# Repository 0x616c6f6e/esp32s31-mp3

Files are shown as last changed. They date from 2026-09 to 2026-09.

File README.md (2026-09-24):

# ESP32-S31 MP3 / Q2 风格播放器

当前工程：

- **[V2 裸芯片主板 PCB](hardware-q2-v2/README.md)**：打开 `hardware-q2-v2/q2-v2.kicad_pro`。ESP32-S31NRV16、正面 AM213 BTB、46 × 76 mm 六层板，0201 阻容已改为 0402。当前仅保留电源布线与铺铜，信号待手动布线；几何 DRC、电源未连接及原理图一致性均为 0，174 项信号飞线为有意保留，不能直接投产。[双面预览](hardware-q2-v2/output/pcb-overview.png)。
- [V2 布局及管脚规划依据](hardware-q2-v2-plan/README.md)：保留方案来源；实际已布线管脚以 [V2 当前引脚表](hardware-q2-v2/pin-assignment.md) 为准。

**当前开发外壳为 L 版：适配新的 2.13 英寸 AM213 AMOLED。** 已修改屏幕总成、面壳开孔和固定台，整机仍为50×81.5×15.1 mm。新屏24针BTB不能直接连接已生产主板的21针FPC2，已完成独立双层FPC转接板的3.3 V参考电路和布线；ERC/DRC及原理图一致性检查通过。L版已有完整转接板装配检查副本，仍待FPC工艺审核、实物插合和点亮测试。

- **[最新外壳 L：2.13英寸屏幕适配](mechanical/enclosure-final-l/README.md)**：`Q2_L_AM213_Adapter_Study.FCStd`，直接使用新屏自带触摸盖板，预留17×22 mm转接板空间。[转接板接线规划](hardware-display-adapter/README.md)。

- **[历史外壳 K：旧2.09英寸屏幕](mechanical/enclosure-final-k/README.md)**：`Q2_K_Assembly_Access.FCStd`。已修复J版装入路径与薄壁，但不适用新AM213屏幕；保留作历史参考。

- **[历史外壳 J：后盖胶粘铜螺母版](mechanical/enclosure-final-j/README.md)**：打样复查暂缓，见 [J 版问题记录](mechanical/enclosure-final-j/PREFLIGHT-REVIEW.md)。已由 K 版取代。

- **[历史外壳 I：装配优化版](mechanical/enclosure-final-i/README.md)**：`Q2_I_Serviceable_Assembly.FCStd`。小板采用三颗带限长垫片的螺钉＋侧边限位台，避开 FFC；加厚按键止脱边、增加排线槽与绝缘护边。修正 G/H 版复合实体干涉漏报，使用 I 版完整四件打印包。

- **[历史外壳 H：小板固定加强版](mechanical/enclosure-final-h/README.md)**：`Q2_H_Reinforced_Assembly.FCStd`。加粗四个小板螺柱、加宽根部并增加侧壁加强筋，小板螺钉改为头下长 2 mm 的 M1.6；外形及两板位置沿用 G 版。使用 H 版打印包，G 版保留为历史。

- **[历史外壳 G：薄型树脂装机样件](mechanical/enclosure-final-g/README.md)**：`Q2_G_Thin_Assembly.FCStd`，适配最终主板与 CH32V006 小板，50 × 81.5 × 14.2 mm（含盖板）。CN2/CN3 改为直接焊线装配；修正支柱、马达托座、屏幕排线和按键避让。附四件打印文件。电池成品厚度仍待供方确认，装机约束见说明。

- [最终主板与按键板 FreeCAD 检查](mechanical/final-board-review/README.md)：采用 `hardware-q2/ProPrj_esp32s31-mp4_2026-09-22.kicad_pro` 为最终主板；两板已导入 `Q2_Final_Mainboard_Assembly.FCStd`。四个主板安装孔与原柱对齐，但发现马达/耳机座、C13/屏幕排线干涉，详见检查报告。

- [独立滑环与按键小板 C](hardware-controls/README.md)：打开 `hardware-controls/controls.kicad_pro`；44 × 34 × 0.8 mm，CH32V006F8U6 读取触摸环与四个机械键，通过 I²C 上报，POWER 独立上拉、按下为低；使用 12P / 0.5 mm / 40 mm 异面 FFC。当前整机机械装配见 K 版外壳，需另行完成小板固件及实物触摸标定。
- [已生产的模组版主板](hardware-q2/ProPrj_esp32s31-mp4_2026-09-22.kicad_pro)：当前保存工程为 `ProPrj_esp32s31-mp4_2026-09-22`；原始生产 Gerber 的审查记录见 [打板检查](hardware-q2/gerber-review-20260922/README.md)。
- [H1/H2 端子、马达和电池规划](mechanical/connector-layout/README.md)：当前摆放版使用 JST ACH 两芯/三芯端子，新增 FreeCAD 装配及线束通道检查。
- [历史外壳 F](mechanical/enclosure-q2-f/README.md)：保留早期外观方案；当前装配应参考 L 版。

旧 `hardware/`、`hardware-q2-placement/` 和旧主板导出文件已从当前目录移除，可从 Git 历史查找。根目录的 PDF、嘉立创 `.epro2` / `.epro` 及 Gerber 压缩包是原始资料。

历史摆放版已有主板与外壳适配；用户新布局 `hardware-q2-layout` 已用于最新小板/排线装配，其最终版本的四个主板安装孔已确认与原柱对齐；完整复查以最新报告为准。屏幕 FPC 插接细节、完整器件高度、具体电池型号仍需确认。独立滑环及五键小板见 `hardware-controls/`；两板接口针序已核对，排线插接、小板触摸与摇摆按键仍需实物验证。[排线采购与装配说明](hardware-controls/mechanical/FFC-INTERCONNECT.md)。详细尺寸、检查范围和后续事项见上述工程说明。

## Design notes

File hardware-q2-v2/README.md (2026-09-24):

# Q2 V2 裸芯片主板 · 2026-09-24

打开 **q2-v2.kicad_pro**。这是 ESP32-S31NRV16 裸芯片版的独立工程，当前按用户要求改为 **0402 阻容、电源分区铺铜并就近打过孔，信号待手动布线**。不是可打板文件。原生产主板 `hardware-q2` 的 PCB 保持原文件哈希。

此前将 21 个电容、10 个电阻及 L105（实际为 0Ω 电阻）从英制 0201 改为 0402（公制 1005）；L101–L104 的射频/滤波电感不在阻容替换范围内。随后检查发现原嘉立创导入的 0402 与 KiCad 标准焊盘混用，现已统一全部 62 个电阻类封装（含 L105）及 72 个电容封装，原理图、符号库、PCB 和 3D 模型同步使用下面两套项目内标准封装。密集区已调整间距，接口和安装孔位置保持不变。

| 类型 | 项目封装 | 焊盘尺寸 | 两焊盘中心距 |
|---|---|---|---|
| 0402 电阻 | `V2:R_0402_1005Metric` | 0.54 × 0.64 mm，圆角矩形 | 1.02 mm |
| 0402 电容 | `V2:C_0402_1005Metric` | 0.56 × 0.62 mm，圆角矩形 | 0.96 mm |

两者来自 KiCad 10 标准库，阻焊/锡膏使用标准继承设置。原有 0603/0805 电容和 1206 电流采样电阻保留原尺寸；过时的 134 个按位号命名的 0402 封装已移除，避免误用。`0402-standardization.json` 记录原始尺寸、统一后尺寸、位置及检查结果；运行 `scripts/audit_0402.py` 可核对所有实例的焊盘、阻焊/锡膏、模型及原理图关联。

删除了 2,090 段信号走线、155 个信号过孔；另重建主控局部电源引出。保留供电、GND/GBAT、稳压器开关/反馈/自举、电荷泵及马达负载回路。电源使能、温度采样、通信、时钟、射频、音频输出等信号均需后续手动布线。精确网络允许列表和改封装清单见 `power-only-0402.json`。

## 工程内容

- `q2-v2.kicad_pcb`：46 × 76 mm，6 层，名义板厚 1.6 mm；198 个器件，双面装配，普通通孔。
- `q2-v2.kicad_sch`：根页及 19 个功能子页，与 PCB 的器件实例和编号焊盘关联。
- `V2.kicad_sym`、`V2.pretty`、`models3d`：项目局部符号、封装和模型。常规 R/C/L 使用 KiCad 标准模型，需安装 KiCad 10 的 3D 模型库。
- `pin-assignment.md`、`q2_v2_pins.h`：从实际 PCB 生成的管脚表和 GPIO 宏；不是已验证的 BSP。
- `output/drc.json`、`erc.json`、`netlist-consistency.json`、`validation-summary.json`：最终检查记录。
- `output/q2-v2-assembly.step`、`case-fit.json`：主板装配模型及相对 L 版外壳的名义干涉检查。
- `output/front-review.svg/png`、`back-review.svg/png`：布局预览；`output/assembly-front.svg`、`assembly-back.svg` 为装配图。
- `output/power-map.svg/png`：In2/In3 实际填充后的电源铜区，按网络着色，均为顶视坐标；`power-pours.json` 记录铜区面积及电源连通性检查。
- 本地 `output/archive` 和路由会话为未提交的中间候选；Git 保留最终报告、模型与建板基线。`scripts` 中的建板及试布线脚本是过程记录，部分依赖本地路由运行时。**不要重新运行 build_v2、prepare_routing、route_usb_and_export 等初始化脚本覆盖当前成品布线。**

## 实现的电路与布局

主控改为 ESP32-S31NRV16，采用乐鑫官方 WROOM-3 V1.2 参考设计的裸芯片电源、40 MHz 晶振、PSRAM 供电和射频匹配起始网络，外接 W25Q128JVSIQ 16 MB 启动 Flash。天线暂定 U.FL/IPEX 外接柔性天线，尚未选定最终天线及安装位置。

屏幕采用正面 OK-23GF024-04，JDISP1 中心以板框左上原点计 `(30.0, 29.2) mm`，旋转 90°。板框原点对应 KiCad 坐标 `(128.868, 67.647) mm`。主控、存储和射频在上部，音频在左下，充电、USB 和电池接口在下部；新增低速电路主要放在背面。

为保持已完成 CH32 按键板的 POWER 上拉行为，新增常供电 3.3 V、跨断电电源域的信号隔离和关机脉冲电路。FPC1 的 2 脚改由常供电 3.3 V 供电；系统 I²C 使用 GPIO6/7 的 **LP I²C**，不能当成第三个普通 HP I²C 控制器初始化。UART 自动下载采用交叉晶体管电路；GPIO60/61 为启动配置，GPIO0 用于按键检测。

已修正 V1 中 CS43131 的 SCL/SDA 对应关系：物理 1 脚 SCL、39 脚 SDA。USB 屏蔽固定焊盘接地，USB 定位孔按厂家图改为 Ø0.55 mm NPTH。保留原外部接口和安装孔锚点。

| 焊线接口 | 焊盘 | 网络 | 用途 |
|---|---|---|---|
| CN2 | 1 | VBAT | 电池正极 |
| CN2 | 2 | BAT_TS | 电池温度检测，不可当作负极 |
| CN2 | 3 | GBAT | 电池负极，保留电量计采样回路，不要任意短接到其它 GND 点 |
| CN3 | 1 / 2 | MOTOR_OUT_P / MOTOR_OUT_N | 马达两端，均不是直接接地端 |

## 校验结果及边界

当前原生 KiCad 10 检查：**几何 DRC 违规 0 项、原理图一致性 0 项、电源未连接 0 项；信号未连接 174 项，符合本次保留飞线的要求**。原理图电路未改变，既有 ERC 为 0 项；另重新逐项比对 198 个器件、704 个编号焊盘的 XML 网表与 PCB，网络不一致为 0。所有阻容均已无 0201 封装，信号走线/过孔残留为 0。

DRC 使用工程内设置：最小线宽/间距 0.10/0.10 mm，保留少量 Ø0.35/0.15 mm 通孔，常规过孔 Ø0.45/0.20 mm；两层连续 GND 加外层铺地及就近地过孔。DRC 和铜区连通性检查不能替代电流/温升验证。

### 电源铺铜与过孔

本次不移动器件或更改原理图网络。In2.Cu（PWR）以 VCC_3V3 为主，In3.Cu（工程名称 SINGAL）放置其余局部电源铜区，必要的跨区连接借用少量 In2 区域。包括 GBAT 在内共 12 个供电/回流分区，彼此保持网络隔离；In1/In4 继续作为整面公共 GND。后续布信号需避开这些电源铜区，或重新填铜并复查电源连通性。

删除直流供电网络的内层分配走线，改为实际连通的铺铜；焊盘附近采用 Ø0.45/0.20 mm、双面盖油的过孔连接内层。普通电源孔避开 SMD 焊盘，保留必要的短表层引出，单段最长 2.0 mm；充电器和降压的大电流节点补充并联过孔。开关节点、反馈、自举、电荷泵以及马达负载回路仍保留必要短线，不能直接视为直流电源平面。主控原有 GND 散热焊盘通孔保留。

`scripts/audit_power_pours.py` 核对电源及地无未连接、直流内层分配线为零、信号铜残留为零，并输出实际填充铜区图。`build_power_pours.py` 和 `bridge_power_pours.py` 是生成过程脚本，依赖本地未提交的 `output/power-pour-spines.kicad_pcb`；不要作为日常更新命令重复执行。后续直接在 KiCad 编辑当前 PCB 并按 B 重新填铜。旧的 `output/power-width-*.json`、`retained-routing.json` 为改铺铜前的历史检查，本版以 `power-pours.json` 和 `validation-summary.json` 为准。

`drc.json` 明列 5 类未启用检查，包括缺少 courtyard、线端未居中过孔等，不能把 0 项理解为完整 DFM 认证。导入封装没有统一的装配 courtyard；已用名义 3D 模型补充器件碰撞检查，但没有验证供应商公差或装配工具空间。

FreeCAD 检查未发现器件模型之间的实体重叠，亦未发现主板组件与所选 L 版外壳、后盖、电池及马达占位的硬碰撞。仅 FPC1 与按键排线插入包络重叠约 1.071 mm³，属于预期插接区域。螺钉孔、测试点、CN2/CN3 焊线焊盘没有实体器件模型；新增晶振和主控模型为名义外形。该结果不等同于屏幕尾排线可插入、插拔路径和尺寸公差已验证。

## 打板前尚待完成的签核

1. **完成所有信号布线。** 包括电源使能、温度采样、USB、Flash、屏幕、音频、射频和晶振。USB 旧版线长结果已失效；`output/usb-routing.json` 是改版前的历史记录，不代表当前 PCB。下单前选定厂家叠层，计算线宽、间距、参考面并复核全链路差分耦合与偏斜；目前没有受控阻抗签核。
2. **射频与晶振。** 匹配值来自官方模块参考，但参考模块叠层不同，不能直接等同于本板的 50 Ω。本次匹配/负载电容及 0Ω 链路放大为 0402，寄生参数变化，原值仅保留为调试起点；需重布短线并实测匹配和晶振。40 MHz 晶振需匹配负载、精度及封装，不能只按频率采购。
3. **AM213 屏幕。** 按此前用户决定继续使用 3.3 V；项目内已保存的 [OSPTEK 官方参考原理图](../hardware-display-adapter/reference/osptek-official/PCB-2.13&1.96AMOLED-qspi转接板.pdf) 将 AM213 的 11/12/15/16 脚接到 VCC3V3，因此有原厂参考电路依据。该接法与早期规格书 PMIC 最低 3.4 V 的文字仍有差异，需实测启动、最大亮度、电源余量和温度边界，不能当作所有屏幕批次的保证。BTB 朝向、尾排线实际折弯与够长需用实物确认，不能仅靠 nominal STEP 认定可插接。
4. **供电和装配工艺。** 裸芯片 EP 内含 25 个散热通孔，需向板厂确认树脂填孔、电镀盖孔/平整焊盘工艺，避免焊料流失；0.15 mm 小孔、细线距及双面装配须与所选订单工艺一致。验证充电/峰值电流、主电源掉电、AON 反灌隔离及关机脉冲时序；尚未做上电、固件、信号完整性、热或 EMC 测试。

因此本目录交付的是**供手动完成信号布线的 PCB 工程**，没有导出标为可生产的 Gerber 包。

## 音频接地与后续布线

本板建议保留连续的公共 GND 平面，通过器件分区和回流路径隔离噪声，不另建孤立 AGND 铜岛或在 I²S 回流下开地缝。充电、降压与马达的大电流回路应局部闭合并远离 DAC/耳机回路；音频电源的滤波与去耦独立考虑。GBAT 是电量计采样回路，不是音频地，不可直接并到其它地焊盘。

**HPREFA/HPREFB 是例外的参考回路要求，不等于整块音频分地。** CS43131 手册第 8.3 节要求 U2 的 13、17 脚分别独立走线到耳机座参考地，再在耳机座地处通过过孔接系统地。目前这两脚仍归属公共 GND，现有铺铜会直接接入，尚未实现 Kelvin 回路。手动布线时应使用独立参考地网络与耳机座处的 net-tie（或局部禁布铜并严格控制公共网拓扑）实现，不能将当前公共地填充视为该要求已满足。GNDA/GNDD/GNDCP 和散热焊盘则继续采用低阻抗接地。依据：[CS43131 数据手册第 8.1–8.4 节](https://statics.cirrus.com/pubs/proDatasheet/CS43131_DS1155F2.pdf#page=140)。

## 参考依据

- [乐鑫 ESP32-S31 硬件设计指南](https://docs.espressif.com/projects/esp-hardware-design-guidelines/en/latest/esp32s31/schematic-checklist.html)，以及项目内 `esp32-s31_datasheet_en.pdf` v0.5；官方模块参考工程保存在 `reference/s31-module`。
- [CS43131 官方手册](https://statics.cirrus.com/pubs/proDatasheet/CS43131_DS1155F2.pdf)。
- [嘉立创 PCB 制程能力](https://jlcpcb.com/capabilities/pcb-capabilities)与[受控阻抗叠层](https://jlcpcb.com/impedance)。生产叠层和工艺应以实际订单确认为准。

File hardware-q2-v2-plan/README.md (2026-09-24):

# Q2 第二版布局规划 B · 2026-09-24

这是以方便布线为优先的 **PCB 布局规划工程**，不是完成电路设计的第二版主板。打开 `q2-v2-placement.kicad_pro` 后进入同名 PCB；本目录没有第二版原理图。不要用第一版原理图直接更新此板，否则会重新加入模组和旧屏幕接口。

源板为 `../hardware-q2/ProPrj_esp32s31-mp4_2026-09-22.kicad_pcb`。源板及生产用文件未改动。规划副本保留原器件的网络信息及 UUID，清除了走线、过孔和铺铜，以便后续手动布线。126 个现有/候选器件不包含尚未设计的裸芯片配套电路。

## 主要位置

统一按 KiCad 正面顶视图，板框中心线包围框左上角为原点，X 向右、Y 向下，单位 mm。绝对坐标原点为 `(128.868, 67.647)`。正面朝屏幕，背面朝后盖。

| 功能 | 层面 | 板框相对位置 | 摆放依据 |
|---|---|---|---|
| ESP32-S31 裸芯片及配套 | 正面 | 本体中心30.00,17.00；预留X21–38、Y8–25 | 手册确认本体8×8、0.35间距QFN80；候选−90°，仅文档层外形 |
| RF / 天线方案 | 两面 | X27–40、Y2–7 | 靠板上边；未确定天线形式，不是已验证的天线净空区 |
| JDISP1 屏幕 BTB | 正面 | **30.00, 29.20** | OK-23GF024-04；11×6 插接预留区；90°是候选方向 |
| U10 原外部数据 Flash | 正面 | 18.60, 28.20；270° | 靠旋转后的裸芯片左下Flash引脚组；容量和作为启动Flash的适用性尚待设计 |
| 40 MHz晶振及匹配 | 正面预留 | X35.5–42.5、Y10–15 | 靠芯片右上，实际器件和走线待设计 |
| U2 DAC | 正面 | 10.252, 48.441 | 保留晶振、充电泵、局部去耦相对关系；下移会碰马达支架 |
| U5 音频 1.8 V LDO | 正面 | 约20.50, 50.00 | 靠 DAC，远离右侧开关电源；输入/输出电容随电路调整 |
| U12 USB 转串口 | 正面 | 约25.40, 55.50 | 靠近 U17，避免原来的长差分支路 |
| D1 USB ESD | 背面 | 34.45, 66.00 | 位于 USB 信号焊盘背后；先保护再去 U17，预留成对过孔 |
| RTC、电量计、马达驱动 | 背面 | 见坐标表 | 围绕目的接口组织，保持按键 FFC 通道空闲 |

安装孔、USB、耳机座、TF 卡座、按键 FPC1 坐标和方向锁定。CN2/CN3 保留焊盘位置，按之前选定的低矮线束方案使用，移除了高插座的装配边界和模型，禁止再装原弯脚插座。

`placement-coordinates.csv` 提供全部器件的相对/绝对坐标及角度。`placement-overview.png` 中正反两图使用相同顶视坐标，右图不是从背面观看的镜像。

## 布线改善与顺序

同网络焊盘之间的最短直线距离，**不是已完成的走线长度**：

| 连接 | 原位置 | 规划位置 |
|---|---:|---:|
| USB → D1，D+ | 11.56 | 1.44 |
| USB → D1，D− | 9.16 | 1.44 |
| CH343P → USB 切换器，D+ | 18.75 | 4.19 |
| CH343P → USB 切换器，D− | 18.14 | 3.59 |
| 1.8 V LDO → DAC 供电脚 | 16.36 | 6.85 |

D1 移近入口后，它到 U17 的受保护支路变长，需要沿下方布线；这是优先缩短未保护段的取舍。不能用上表宣称全板总线长或过孔数量已经下降。

1. GPIO 候选分配已记录在 `pin-assignment.md`；完成裸芯片原理图、封装和实际布线评估后再确定核心朝向。Flash、SD、屏幕 QSPI 分组出线，避免互相穿越。旧模组的引脚号不能直接用于裸芯片。
2. 电源保持充电器/电感/电容及降压器各自局部回路；缩小 SW 铜面积，反馈线避开 SW 和电感。不要为缩短信号线拆散这些局部电路。
3. 优先布晶振、RF、启动 Flash、SD 和屏幕时钟，其次 USB 差分与 I²S；最后处理低速 I²C、控制信号。
4. 继续使用现有六层框架，内层保持连续参考地；具体层叠厚度、阻抗与制造商确认后再定线宽。数字总线从中间通道通过，避免穿过 DAC 晶振、充电泵和耳机模拟输出区域。
5. D1 在背面，USB 入口信号使用短的成对过孔，并提供邻近地回流；不要从未保护的支路绕到其他电路。

## 未完成的电路事项

2026-09-24：新增 `pin-assignment.md`、完整81脚表 `pin-assignment.csv` / `pin-assignment-all-pins.md`、方位图 `pin-assignment-overview.png` 和常量头文件 `q2_v2_pin_plan.h`。这些是原理图设计输入，未修改现有PCB网络。系统总线采用LP I²C，POWER检测须隔离GEK电源域；屏幕SPI2替代引脚组的SDK支持仍待实测。`scripts/plan_pins.py` 仅生成引脚表，不改PCB。

- CORE框内已按用户提供的芯片手册标注8×8本体和−90°候选朝向，仍无电气焊盘。须补裸芯片、40 MHz晶振及匹配、各电源域去耦、射频匹配、启动Flash和下载/复位电路。尺寸、物理引脚及型号核对见 `datasheet-check.md`。
- 原 U10 为 W25Q16JVSSIQ，**16 Mbit = 2 MB**，不能直接等同原 ESP32-S31-WROOM-3-N16R16V 内的 16 MB Flash。其现有位置是外部数据 Flash 候选位置；下一版可结合实际程序容量决定是否替换/合并。原有 C13 的 3.3 V 网络也不能代替尚未设计的 VDD_SPI 供电方案。
- 移除了 U9、FPC2，以及旧 TFT 背光升压的 U16/L4/C42/C55/C56/C57/R40/R41。马达仍使用的 VCC_LCD_BG 相关充电器网络没有删除。第二版原理图要同步这些变化。
- BTB 沿用已讨论的 3.3 V AMOLED 方案和转接板信号映射；TE 作为未接 MCU 的独立预留网络。新接口需增加/核对本地去耦、电源顺序、ESD；这是预接网络，不是电气审核结论。
- BTB 绝对坐标为 `(158.868, 96.847)`。当前 90°对应1脚在顶视图左下，约 `(27.8,30.4)`；90°/270°须通过实物屏幕原生排线折叠确认。原转接板焊接面比主板正面高4.3 mm，XY 对齐不能证明排线可直连。
- RF 预留区尚未检查屏幕金属层的射频影响，不能直接作为 PCB 天线设计或全层禁铜范围。正式核心电路还可能要求调整 CORE 和 Flash 范围。

依据乐鑫官方 [ESP32-S31 原理图检查表](https://docs.espressif.com/projects/esp-hardware-design-guidelines/en/latest/esp32s31/schematic-checklist.html) 和 [PCB 布局指南](https://docs.espressif.com/projects/esp-hardware-design-guidelines/en/latest/esp32s31/pcb-layout-design.html) 组织核心预留和布线顺序。RF/时钟及分域供电应以完整参考设计为准。

## 检查范围与交付文件

本次调整55个现有器件，并新增1个BTB候选封装。原生DRC确认焊盘短接0项、封装装配边界重叠0项、跨网络阻焊桥0项；仍有66项其他违规和324项未连接，详见原始报告。保留器件的焊盘网络与源板逐项比较一致。已有模型中，55个移动器件及新增BTB未发现实体碰撞；原FPC1与排线插接处约0.00195 mm³的微小重叠未变化，记录在装配报告中。

- `placement.json`：完整器件记录、源文件校验和、移除项和预留区。
- `connection-distance-check.json`：上述连接距离的计算证据。
- `drc-planning.json`：原生 KiCad DRC，不能作为生产放行报告。规划板无走线，存在未连接项；原导入封装还存在孔类型、丝印、USB 开槽边缘间距和细间距封装与默认0.2 mm规则不相容的问题。没有通过忽略规则来隐藏它们。
- `mechanical-check.json`：将现有STEP模型及8×8×0.9 mm芯片本体占位移入L版装配的碰撞检查。对新增配套电路、屏幕原生排线、公差及整机RF不作验证结论。
- `Q2_V2_Placement_Study.FCStd`：**布局规划装配副本**，不是新的可加工外壳版本。CN2/CN3 高插座及旧屏幕转接板占位已移除；外壳本体没改。
- `V2_Plan.pretty`：当前规划板的本地封装库。3D 模型引用同仓库已有文件，需保留本目录与上级工程的相对路径。参考位号放在 Fab 层用于布局阅读，生产丝印尚未整理。

重建脚本位于 `scripts`，会覆盖本目录生成的规划板及报告；**开始手动布局后不要运行重建脚本，以免覆盖你的修改**。`build_plan.py` 使用 KiCad Python，`check_mechanical.py` 使用 FreeCAD Python，`make_preview.py` 使用带 Pillow 的 Python。

下一阶段是补齐裸芯片原理图、将该规划变为网络一致的正式 PCB，再布线和进行生产 DRC。本版不能导出用于生产的 Gerber。

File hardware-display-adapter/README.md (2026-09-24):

# AM213 屏幕转接板 A — 电气样板

2026-09-23：已完成原理图、双层 FPC PCB、布线、3D 模型及 L 版装配检查副本。按用户选择采用 **3.3 V 供电和直接连接逻辑**，没有修改已生产主板和按键板。

## 当前文件

- 打开工程：[am213-fpc-adapter.kicad_pro](am213-fpc-adapter/am213-fpc-adapter.kicad_pro)。同目录有原理图、PCB 和自带符号、封装、STEP 库。
- 最新装配副本：[Q2_L_AM213_Completed_Adapter.FCStd](am213-fpc-adapter/models3d/Q2_L_AM213_Completed_Adapter.FCStd)。原始 L 外壳没有覆盖。
- [元件面预览](am213-fpc-adapter/output/pcb-top.png)、[折弯预览](am213-fpc-adapter/output/adapter-folded.png)、[装配预览](am213-fpc-adapter/output/adapter-in-enclosure.png)。
- [BOM](am213-fpc-adapter/output/bom.csv)、[接线及坐标](fpc-layout-guide.md)、[制造说明](am213-fpc-adapter/FABRICATION.md)。
- `am213-fpc-adapter/output/AM213-adapter-A-fabricator-review.zip`：Gerber、钻孔与工艺说明，供 **FPC 工厂审核及小批样板**；不是普通刚性 PCB 下单包。

旧 `adapter-outline.kicad_pcb`、`fpc-layout-concept.png`、`Adapter_Placement.pretty` 和机械占位预览仅作历史参考。旧 1.8 V 电平转换方案已被本版取代。

## 电气依据

屏厂 OSPTEK 官方 AM213 参考原理图明确把 11/12 脚 VBAT、15 脚 VDD、16 脚 TP_VDD 接到 3.3 V，QSPI/I²C 直接连接 ESP32。采用该参考，取消早期预留的电平转换电路。

- 官方仓库：https://github.com/osptek/amoled-2.13-410x502-qspi-co5300
- 原理图与实板照片：[PCB-2.13&1.96AMOLED-qspi转接板.pdf](reference/osptek-official/PCB-2.13&1.96AMOLED-qspi转接板.pdf)。第 1 页左侧为 AM213，第 2 页实板照片用于母座针号核对。
- 原厂连接器图：[OK-23GF024-04.pdf](reference/osptek-official/OK-23GF024-04.pdf)，母座第 3 页。
- 下载来源和 blob 标识：`reference/osptek-official/sources.json`。

旧屏幕规格书第 6 页仍有 VBAT 下限 3.4 V、VDDIO 1.8 V 等与参考板不一致的文字。本版选择有屏厂参考电路支持，但没有实屏点亮、最大负载及主板电源余量测试，不等于供应商对所有批次的保证。

## 检查与限制

KiCad 10 原生 ERC **0**、DRC 违规 **0**、未连接 **0**、原理图/PCB 一致性问题 **0**。报告在 `output/erc.json`、`output/drc.json`。工艺下限见制造说明，不能代替板厂 DFM。

FreeCAD 按 R0.8 mm 折弯 70 mm 排线，检查元件岛、补强、元件和母座最大包络。排线及插头补强进入简化实体 `PCB_FPC2` 是预期配合重叠；除此之外未发现体积干涉。屏幕原生尾巴、公母插合公差、锁扣和触点仍需实物试装。

`build_complete_adapter.py` 会覆盖 PCB 布线，不要对手改后的工程直接运行。其余脚本是本次构建和修复记录；当前交付以已保存 KiCad 文件为准。旧机械占位生成器已加覆盖保护。

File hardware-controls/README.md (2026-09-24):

# 滑环与按键小板 C：CH32V006

采用 **CH32V006F8U6** 替换 AT42QT2120-MMHR 和 TCA6408A，由一颗 MCU 处理三电极滑环、四个机械按键，并作为 I²C 从机向主板报告。POWER 保持独立、10 kΩ 上拉、按下接地。

这是需要配套固件和实物调参的新硬件版本，不能直接沿用旧 AT42 的驱动或生产文件。

KiCad 10.0.4 检查结果：ERC 0、DRC 0、未连接项 0、原理图一致性问题 0。板上共有 439 段走线和 62 个过孔。双面 GND 铺铜避开触摸电极及其背面（外扩约 0.8 mm），并避开三路采样走线（铜边外扩约 0.5 mm）；这些余量仍需实物验证。

新版文件：[Gerber 生产包](output/controls-ch32v006-jlcpcb-20260922-101316-gerbers.zip)、[BOM](output/controls-ch32v006-bom.csv)、[装配 STEP](output/controls-ch32v006.step)、[背面预览](output/ch32v006-review/back.png)。BOM 由当前原理图导出，共 10 类、23 个装配元件，尚未匹配嘉立创 SMT 料号。

## 工程与机械接口

- KiCad 工程：`controls.kicad_pro`，原理图、PCB、本地符号库、封装库与模型一起使用。
- 双层 FR-4，板厚 0.8 mm，44 × 34 mm，原 R10 板框。
- 五个按键、四个安装孔、三电极滑环 E1、FPC J1 的位置与方向保持原样。
- 电极仍为三组插值电极，外径 31 mm、内径 15 mm；不改变前面板外观。
- 新 MCU 及阻容位于背面。J2 为四个裸焊盘，不安装插针，不增加连接器高度。
- 已添加名义尺寸的 CH32V006 QFN20 STEP 模型。本版 23 个元件已导入 [I 版装配优化工程](../mechanical/enclosure-final-i/README.md)，最新工程为 `mechanical/enclosure-final-i/Q2_I_Serviceable_Assembly.FCStd`。小板采用三颗 M1.6 × 2 mm（头下长度）薄头螺钉、三片 0.3 mm 平垫及右侧限位台；右上原固定柱封闭不装螺钉，避开 FFC。G/H 复合实体检查曾漏报该处干涉，使用 I 版检查和打印文件。

J1：1 GND、2 +3V3、3 SDA、4 SCL、5 INT_N、6 RESET_N、7～10 NC、11 KEY_POWER、12 GND；固定焊盘 13、14 接地。供电与信号电平为 3.3 V。

## 采购与装配变化

| 位号 | C 版器件/数值 | 数量 | 说明 |
|---|---|---:|---|
| U1 | CH32V006F8U6 | 1 | QFN20，3×3 mm，0.4 mm 脚距，EP 1.9×1.9 mm |
| J1 | HC-FPC-05-10-12RLTAG | 1 | 原 12 pin、0.5 mm FPC 连接器 |
| SW1～SW5 | SKSWCEE010 | 5 | 原机械开关 |
| R1～R3 | 1 kΩ，0402 | 3 | 触摸采样串阻，需实物调参 |
| R4、R5 | 4.7 kΩ，0402 | 2 | I²C 上拉 |
| R6、R7、R14 | 10 kΩ，0402 | 3 | INT、RESET、POWER 上拉 |
| R8 | 0 Ω，0402 | 1 | MCU 电源连接，不能装旧 22 Ω |
| R9～R12 | 47 kΩ，0402 | 4 | 四个普通键的 GPIO 上拉 |
| C1、C3 | 100 nF，0402，X7R，≥10 V | 2 | MCU 去耦、复位 RC |
| C2 | 1 µF，0402，X5R/X7R，≥10 V | 1 | MCU 电源去耦 |

单板 23 个采购/装配元件。J2、E1、H1～H4 为 PCB 自带焊盘、电极及安装孔，不采购。U2、R13、C4 已移除；C3 现在用于复位，不能按旧版位置和功能装配。型号后缀及封装必须核对，TSSOP20 的 CH32V006F8P6 不能替代此 QFN20 焊盘。

## 固件

见 [CH32V006-interface.md](CH32V006-interface.md)：完整引脚分配、SDI 下载、PD7 硬件复位配置，以及拟定的 I²C 寄存器协议。地址暂定 0x1C，寄存器与 AT42QT2120 不兼容。本次没有交付可烧录固件；官方 TouchKey 示例也不能原样烧录到此板。

打样后要在最终盖板下标定三路触摸基线、阈值、零位、转动方向与跨零连续性，并验证充电/音频干扰、按键消抖、待机电流、复位和再次下载能力。

## 检查与历史文件

本次备份、原生 ERC/DRC 报告、机械接口比较和预览位于 `output/ch32v006-review/`，以其中的 final 报告和 `validation.json` 为准。历史生成脚本可能仍包含 B 版芯片和旧镜像坐标，不要直接运行旧 `build_design.py` 或 `build_fit.py` 覆盖当前工程。

2026-09-22 10:13:16 批次已从用户调整走线后的 C 版导出 Gerber 生产包（源 PCB 保存时间为 10:13:08），包含九个图层、独立 PTH/NPTH 钻孔、Gerber Job 和加工说明。下单参数：双层 FR-4、44 × 34 mm、板厚 0.8 mm、外层铜厚 1 oz。62 个 Ø0.30 mm 镀铜过孔及四个 Ø1.80 mm 非金属化安装孔已与 PCB 核对；顶面触摸电极保留阻焊覆盖。导出前原生 DRC、未连接项和原理图一致性问题均为 0；文件校验和及检查记录见 `output/ch32v006-gerber-review-20260922-101316/manifest.json`。

**旧 `controls-jlcpcb-20260922-no-tp-gerbers.zip`、旧 BOM、`fabrication/` 和历史 STEP 是 AT42/TCA 版本，全部不适用于 C 版。** 旧 README 与原始工程在 `output/ch32v006-review/before/` 保留。

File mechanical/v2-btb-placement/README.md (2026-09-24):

# 第二版主板正面 BTB 位置评审

当前结论：可以在取消 U9 模组后预留一个正面 BTB 候选位置，但**尚不能冻结生产坐标**。现有屏幕 CAD 没有原生排线的精确实体，需在主板正面高度试折实物后确认落点和 1 脚。

## 建议预留位置

以现有主板 Edge.Cuts 中心线外包左上角为基准：KiCad **(128.868,67.647)**，名义板框 **46×76 mm**，X 向右、Y 向下。

| 项目 | 候选值 |
|---|---|
| 连接器 | OK-23GF024-04，24P 母座，与屏幕公座配对 |
| 放置面 | F.Cu，朝屏幕一面 |
| 基于主板板框的中心 | **X=30.00，Y=29.20 mm** |
| 当前 KiCad 绝对中心 | **X=158.868，Y=96.847 mm** |
| 外壳装配底面中心 | **(18.00,31.20,5.80) mm** |
| 长轴 | 沿主板 X，横向 |
| 预留区域 | 中心周围 **11×6 mm**，先不放裸芯片、晶振或其他元件 |

坐标转换为 `X_case=176.868-X_KiCad`、`Y_case=Y_KiCad-65.647`。所以 KiCad 顶视图的左/右与当前外壳平面坐标相反；不能把外壳 X18 当作主板局部 X18。

当前适配器封装旋转 **90°** 时，1 脚位于 KiCad 图中左下，局部 (27.8,30.4)；旋转 **270°** 时会变成右上。两种角度外形占位相同，但针序相反。此处只推荐长轴方向，**90°/270° 的最终选择须按屏幕原生排线的实际折回姿态核对**，不能沿用旧转接板的“1 脚左上”。

## 选择理由及实测边界

1. 将旧转接板的外壳 XY=(32,20) 投影到主板正面后，母座最大包络与现有 CARD2/TF 卡座相交约 1.146 mm³，不能直接照搬。
2. 新位置在 U9 模组原占位的下半部。保留模组时与其干涉；从评审中排除将被替换的 U9 后，母座最大包络以及 11×6×1.7 mm 操作预留区与其余现有模型没有体积干涉。没有模拟插合手指/工具的完整扫掠。
3. 方案假定屏幕横放后，原生自由尾巴朝机身左侧、靠屏幕下沿。按规格书第 5 页折弯示意图中的边距 5.15±0.5 mm、尾端宽 4 mm，尾巴轴线估算为外壳 Y≈`0.85+37.5-(5.15+4/2)=31.2 mm`。**这是示意图推算，不是厂家给定的主板连接器坐标**。X18 是在腾出空间内选的工程候选值，需实物调整。
4. 原转接板焊接基面 Z10.1；主板正面 Z5.8，低了 **4.3 mm**。低矮母座本身不能补这个高度，屏幕原生 FPC 必须形成新的三维弯曲路线。型号所称 0.8H 是公母插合高度，不是 4.3 mm 高度转接件。
5. 第二版裸芯片、射频匹配/天线、晶振、电源与去耦布局尚未设计；这份结果只确认候选母座区域相对于当前外壳和其余器件的空间关系。

## 文件

- `Q2_V2_BTB_Position_Study.FCStd`：独立 FreeCAD 评审副本。
- `placement-top.png/svg`：以 KiCad 顶视图表达的候选位置，包含板框基准及 TF/旧模组占位。
- `position-check.json`：坐标、碰撞结果和全部假设。
- `check_position.py`：可重建检查副本；现有主板和 L 版外壳文件保持原样。

在绘制第二版走线前，用实际 AM213 屏幕在 Z5.8 mm 的主板平面试折：避开原生元件区与钢片补强，不强拉、不折死；确认插合面、尾巴自然落点和 pin 1，再冻结 XY 与 90°/270°。若实屏实际朝另一侧出线，需要调整屏幕朝向或重选位置，不能只把本坐标镜像后直接投板。

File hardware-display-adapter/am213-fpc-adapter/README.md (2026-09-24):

# AM213 转接板 A

打开 `am213-fpc-adapter.kicad_pro`。现为已完成原理图和布线的电气工程，取代旧机械占位版本。

- 原理图、PCB：同名 `.kicad_sch`、`.kicad_pcb`
- 自带库：`Adapter.kicad_sym`、`Adapter.pretty`、`models3d`
- 最新装配副本：`models3d/Q2_L_AM213_Completed_Adapter.FCStd`
- 检查、BOM、预览及制造审核包：`output/`

采用屏厂 3.3 V 直接接线参考；17×22 mm 元件岛、70 mm 左出尾巴；J2 局部 **(3,12)**、1 脚左上。R10/R11 不装。ERC/DRC、未连接和原理图一致性问题均为 0。

详见[接线与坐标](../fpc-layout-guide.md)、[电气依据](../README.md)、[制造说明](FABRICATION.md)。先审核柔性叠层、补强、0.15 mm 小孔及金手指工艺，再做样板；尚未实物插合和点亮。

`Adapter_Placement.pretty`、旧 `placement-preview.*` 及 `models3d/Q2_L_BTB_Fit_Review.FCStd` 为历史阶段文件。

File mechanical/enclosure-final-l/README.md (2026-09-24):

# Q2 L：2.13 英寸 AM213 屏幕适配

已按项目中的 `AM_213_Q410502_LK_b82450b641.pdf` 更新屏幕总成、面壳开孔及固定方式，保留已生产主板与按键板。**当前是机械适配版，含转接板空间预留；不是可直接装机生产的完整定版。** 新屏24针BTB不能插入原21针FPC2，有源转接板及两端排线仍需完成。

当前工程：**`Q2_L_AM213_Adapter_Study.FCStd`**。K版保留为旧2.09英寸屏历史工程，不适用于本次新屏。

## 屏幕与机身

| 项目 | L版 |
|---|---|
| 型号 | AM213Q410502LK，2.13英寸LTPS AMOLED，带触摸及一体盖板 |
| 分辨率 | 410×502；本机横向布局为502×410 |
| 控制器 | CO5300AF-51显示、CST820触摸、BV6802电源 |
| 完整光学总成 | 竖向37.50×46.30×2.28 mm；模型横放46.30×37.50×2.28 mm |
| 盖板 | 屏幕自带1.30 mm盖板，**取消旧版另购46×40×0.6玻璃** |
| 裸屏轮廓 | 横放43.14×34.79 mm；规格书标厚0.800 mm |
| 显示区 / 可视区 | 横放40.51×33.09 / 40.71×33.29 mm |
| 整机外包 | **50×81.5×15.1 mm**，保留K版尺寸 |
| 左、右直边距 | **1.85 mm** |
| 顶部直边距 | **2.35 mm**；屏幕盖板XY原点(1.85,0.85)，机身顶端Y=-1.5 |
| 盖板装入间隙 | 名义单边0.25 mm；裸屏通孔单边0.30 mm |
| 固定 | 一体盖板背面黑边粘0.20 mm胶，落在新面壳台阶上；名义接触面积约121.6 mm² |

屏幕正面最高Z=15.1、盖板背面Z=13.8、壳内胶台Z=13.6、光学总成背面Z=12.82 mm。模型按0.805 mm屏体＋0.175 mm OCA＋1.30 mm盖板分层，使总厚与规格书四舍五入后的2.28 mm一致；这0.005 mm并非额外零件。

屏幕在L版首次适配基础上**下移0.50 mm**，同步移动开孔、胶台、光学总成及背面FPC包络。此次按圆角处的视觉留白调整：原直边距虽相等，但上方圆角与机身曲率不同，留白偏窄。下移后盖板上圆角至面壳外缘的平面最短距离约1.27 mm，左右直边约1.30 mm（按Z=14.4前表面轮廓测量）；扣除0.25 mm装入缝后，可见实体边框约1.02/1.05 mm。这里的视觉均衡不等于三个方向的外包直边尺寸都相等。

尺寸取自规格书第3页及第5页完整总成图。盖板和裸屏圆角未标注半径，按第5页矢量轮廓近似为相切圆弧；盖板R约9.95 mm，裸屏左右角约R9.0/R8.42。盖板矢量采样点落在解析模型外的最大距离约0.052 mm。**这是图形近似，不是厂家尺寸公差保证**，取得厂家DXF/实物后仍需复核圆角。

## 屏幕背面与转接板

规格书显示该屏出厂把带元件FPC折到屏幕后方，不能使用旧屏的单条平整46.14 mm排线路径。本版删除旧路径，在屏幕后设置保守元件/FPC包络，向后预留1.52 mm（含图示1.42 mm局部高度与0.10 mm余量）。其形状是占位，不是FPC精确实形。

转接板预留位于装配坐标 **X29～46、Y8～30、Z9.5～10.1 mm**，尺寸17×22×0.6 mm。板下元件允许包络0.9 mm，板上连接器暂留0.8 mm。模型蓝色是板框、橙色是元件空间，均不是已经布线的PCB。当前检查中板上连接器包络至屏幕后包络名义间距0.4 mm；屏体向后增加0.2 mm后仍无实体交叠，但这不是完整制造公差堆栈。

**尚未建成**：新屏伸出的自由尾线到转接板的实际折弯、21针输入线到主板背面FPC2的路线、转接板固定座及准确母座模型。保留这些待定项，避免用一条虚构排线宣称两端已连接。电路及接线方案见 [转接板规划](../../hardware-display-adapter/README.md)。

## 装配变化

后盖、滑环、中央键、马达托座与K版几何完全一致；只有上壳/屏幕结构变化。五金仍为：主板4颗M2×4、小板3颗M1.6×2.5＋3片0.3 mm平垫、后盖2颗M1.6×6＋2颗OD2.5/L3的M1.6胶粘铜螺母。孔、头部尺寸及胶粘要求沿用 [K版说明](../enclosure-final-k/README.md)。

- 滑环先向屏幕偏3.5 mm，从后侧进入至低于终位5 mm，再移回中心并向前就位；中央键随后装入。
- **L版小板进入偏移改为 X=-1.3、Y=-3.0 mm**，不能沿用K版Y=-5路线。推至比终位低0.5 mm，再沿Y回到0、沿Z抬0.5 mm，最后向右滑1.3 mm进限位台，装三颗带平垫螺钉。
- 马达托座仍在小板之后安装。屏幕一体总成从前侧放入，胶贴只作用于盖板黑边台阶，不能在触摸盖板外再叠一块旧透明板。
- 转接板实际固定及排线接好后，主板/后盖才合装；该步骤仍等待实际转接设计。

## 已验证的范围

- `fit-check.json`：原装配＋新屏及转接占位共190个对象，非预期静态干涉0；按键下压与四向摇摆检查通过。
- `assembly-path-check.json`：73个分阶段离散姿态通过，含新屏一体总成、转接占位、小板新路线与主板/后盖。没有模拟自由排线弯曲、工具或粘接操作。
- `screen-check.json`：总成外包46.3×37.5×2.28、胶台接触、屏后增厚0.2 mm情形通过；主板、小板及四个沿用打印件相对K版几何差为0。
- `export-readback-check.json`：六个STEP/STL回读有效、单实体、单连通闭合，无网格自交/非流形/法向错误；STEP与保存的FCStd打印件一致。
- `source.json`：最终两板的源文件与哈希；`screen-contours.json`：屏幕规格书SHA256及轮廓提取记录。

## 文件用途

- `Q2_L_AM213_Adapter_Study.FCStd`：带参数与占位的FreeCAD源工程。
- `Q2_L_AM213_Adapter_Study.step`：整机参考，不可整体打印。
- `AM213Q410502LK-screen-stack.step`：新屏光学总成独立模型，**不包含未定自由排线**。
- `prototype-parts-not-released/`：更新后的外壳单件STEP/STL，仅作机械评审，不作为已经完成装机验证的下单包。
- `front-assembled.png`、`back-internals.png`：外观与空间预留视图。

正式定版仍需确认屏幕15脚VDD/16脚TP_VDD供电、电流、配套BTB母座图及出货FPC实形，完成转接电路和实际布线后再复查。现有电池采购尺寸、充电配置及树脂/胶接实物验证要求继续适用。**现在不要把L版直接按完整可装机样件下单。**

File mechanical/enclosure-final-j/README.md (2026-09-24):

# Q2 J 后盖胶粘铜螺母版 — 2026-09-23

> **打样前复查：暂缓按可装机样件加工。** 新增装入路径检查发现滑环和小板会碰上壳内部结构；薄壁/工艺框及 LCD 本体固定仍待处理。此前静态“零干涉”不能代表可装配。详见 [完整复查报告](PREFLIGHT-REVIEW.md) 和 [暂缓加工说明](PRINT-HOLD.md)。下文装配顺序属于原设计意图，尚未通过完整装入路径验证。

当前外壳工程为 **Q2_J_Glue_Insert_Assembly.FCStd**，适配最终 `hardware-q2/ProPrj_esp32s31-mp4_2026-09-22.kicad_pcb` 和 CH32V006 C 版 `hardware-controls/controls.kicad_pcb`。本次不修改电路板。面宽 50 mm、高 81.5 mm，壳体厚 13.5 mm，含前盖板最大厚度 14.2 mm。保留屏幕上、左、右 2 mm 边距及当前操作区中心。

这是树脂打印的装机验证版本，不是量产定版。**保持薄壳的前提是 CN2/CN3 不装原高插座，改为焊接柔性线束。电池成品尺寸尚未获得供方确认。**

## 文件

- `Q2_J_Glue_Insert_Assembly.FCStd`：完整装配，分为打印件、电子件、装配参考和隐藏诊断包络；尺寸记录在 DesignParameters 表中。几何构建脚本位于 `scripts/`，不是完整草图约束建模树。
- `Q2_J_Glue_Insert_Assembly.step`：整机交换模型，仅供装配检查，不可整体送印。
- `Q2-J-glue-insert-sample.zip`：四个装机打印件、一个可选螺母试配小样的 STEP/STL、加工说明和验证记录。
- `print-package/`：实际送印文件，毫米单位，每个文件独立局部原点。
- `clean-parts/`：去工艺框后的滑环和中央键 STEP，保持装配坐标，供机械修改。
- `source.json`、`fit-check.json`、`export-check.json`：PCB 版本、名义干涉检查及网格尺寸/闭合性记录。
- `front-assembled.png`、`back-internals.png`、`shell-parts.png`：装配和内部结构预览。
- `optimized-upper-shell.png`：金色为两颗胶粘铜螺母的位置；`insert-section.png`：螺母座剖面，金色为铜螺母、深灰为螺钉、浅灰为上壳，底部灰色横板为后盖。牙纹和滚花仅以包络表示。

## J 版：后盖两个固定点改为胶粘铜螺母

**只改后盖到上壳的两个固定点。** 主板四颗 M2、小板三颗 M1.6＋垫片及侧边限位台沿用 I 版。机身外形和两板位置不变。新版上壳 `01-housing` 必须使用 J 版；后盖、滑环和中央键与 I 版几何一致。

| 项目 | 数量 / 尺寸 |
|---|---|
| 铜螺母 | **2 颗 M1.6 × 0.35，无头滚花，最大外径 2.5 mm、总长 3.0 mm** |
| 厂商尺寸参考 | In-saiL **MT-M1.6x3.0-OD2.5**；不可换成带法兰 MTH、六角螺母或外径 3 mm 款 |
| 螺母座位置 | 上壳内，装配坐标 X=25，Y=3 / 77 mm；从后盖方向装入 |
| 胶粘孔 | Ø2.70 × 深 3.20 mm；入口 0.15 × 45° 导角 |
| 胶缝 | 对 Ø2.50 最大外径，径向名义 0.10 mm；滚花谷底实际胶层更厚 |
| 安装深度 | 插到底部台阶，螺母外端低于柱端面约 0.20 mm；螺母 Z=1.4～4.4 mm |
| 柱壁 | 圆柱外径 Ø4.8，直孔段名义径向壁厚 1.05 mm；入口处 0.90 mm |
| 螺钉避让 | 螺母后方 Ø1.8 通道至 Z=7.20；M1.6×6 螺钉尖端 Z=6.65，名义余量 0.55 mm |
| 后盖螺钉 | 沿用 **2 × M1.6 × 6，头径 ≤3.2、头高 ≤0.5 mm** |

总计 **9 颗螺钉＋3 片平垫＋2 颗铜螺母**。铜螺母是金属采购件，模型中以光滑最大包络表达，未画牙纹、滚花和导入倒角；3 mm 为轴向覆盖长度，不代表 3 mm 全部都是有效完整牙。

选型依据：[In-saiL 厂商规格](https://www.ppmcn.com/mini-tech-inserts/)。该厂商给出的 Ø2.15～2.25 安装孔属于热嵌工艺，**本版 SLA 树脂采用自行设计的 Ø2.70 胶粘孔，不能按厂商热嵌孔缩小或加热压入**。树脂胶粘安装参考 [Formlabs](https://formlabs.com/blog/adding-screw-threads-3d-printed-parts/)。尺寸规格已查证，但未确认淘宝某一商家的库存、尺寸公差或胶接强度；购买时明确要求最大滚花外径和总长。

### 试配与粘接

1. 先测量铜螺母实际最大外径及长度。外径不是 2.5 mm 或长度不是 3 mm 时，不得硬压入本孔；按实物另改模型。
2. 建议同材料、同批次打印 `05-insert-fit-coupon-optional`（24×8×5 mm）。带缺角一端的孔为 Ø2.65，中间 Ø2.70，另一端 Ø2.75；三个孔均深 3.2 mm，并带小直径余孔。小样验证插入和胶接，不是主机零件，也不是打印公差保证。正式上壳孔固定为 Ø2.70，不能因小样另一孔合适就直接假定上壳合适。
3. 完全清洗、后固化并干燥后试插。使用与所选 SLA 树脂、黄铜均兼容的双组分环氧胶，先在小样验证；胶的固化时间与表面处理遵循胶水厂商说明。
4. 用细棒少量涂在孔壁/滚花外壁，避开内螺纹和孔底 Ø1.8 通道。轻放至台阶，螺母保持同轴，端面不得凸出。不要用后盖螺钉将螺母强拉入孔，也不要靠长螺钉顶到底定位。
5. 将开孔朝上固定，待胶水完全固化后再穿入螺钉。不要在螺钉已拧入时灌胶，防止粘死。先完成螺母粘接，再安装屏幕、电路板和电池。
6. 首次低扭矩合盖，检查螺母无转动、拔出或柱壁裂纹。本孔台阶只负责定位，轴向拔出及防转主要靠胶接，尚未做拉拔、扭矩、跌落或拆装寿命试验。

嘉立创只需打印树脂件，不选其 M3/M4/M5 螺母代装服务。自行采购并粘接上述两颗小螺母。

## I 版改动与更正

**此前 G/H 的复合排线布尔运算存在漏报，实际右上角小板螺钉穿过 FFC，部分马达导线也有交叠。I 版已修正几何检查方法并处理这些干涉；旧版“零干涉”结论不能作为该排线装配的依据。**

- 小板改成 **三颗螺钉＋右侧边缘限位台**。壳体坐标 (44,51) mm 的原螺柱继续支撑小板，但孔已封闭，不装螺钉；FFC 可保持原 12P、0.5 mm、40 mm 异面直排线。三个螺钉位置是 (6,51)、(6,67)、(44,67) mm。不能在封闭柱上自行钻孔加回第四颗螺钉。
- 右侧限位台位于 Y55.45～56.65 mm，搭接小板边缘约 1.2 mm，贴总厚 0.2 mm 的绝缘垫（含胶）。装板时先从左侧偏移约 1.2 mm 的位置向右滑入，再拧三颗螺钉；不掰弯限位台硬压入。
- 每颗小板螺钉配一片 **内径 1.7、外径 4、厚 0.3 mm 的 M1.6 平垫**。名义头下长度 2 mm，旋入约 0.9 mm；盲孔 Ø1.3、深 1.1 mm，孔顶封底加厚到 0.5 mm，螺钉尖端至孔底名义余量 0.2 mm。保留 H 版 Ø5 接触柱、Ø6 根部和侧壁加强筋。
- 该取舍增加了防顶穿余量，但螺纹旋入由 H 版 1.2 mm 减至约 0.9 mm，仍只适合低扭矩样件固定。缺少垫片会失去设计余量；实际螺钉头下长度不得超过 2.0 mm。底孔必须限深加工，未验证循环拆装寿命。
- 滑环止脱边由约 0.4 加厚至 **0.5 mm**，外半径增至 17.35 mm，根部 R0.12；中央键止脱边由约 0.3 加厚至 **0.4 mm**，半径增至 7.15 mm，根部 R0.15。同步调整内部避让，按键外观面和推杆高度保留。
- 屏幕和控制排线增加端部带 R0.6 的侧壁避让槽，配置 0.05 mm 薄绝缘衬贴参考。主板左边电池线跨板位置增加薄绝缘护边参考，避开 SCREW3。重排两根马达导线，绕过壳体圆角和主板边缘，并错开靠近马达的交叉段。
- `optimization.json` 记录改动，`insertion-check.json` 记录装入采样检查。以上为 I 版相对旧版的改动；J 版在 I 版基础上只修改上壳螺母孔，其余三件与 I 版一致。

平垫尺寸依据：[M1.6 DIN125A 厂商规格](https://www.aspenfasteners.com/content/2D_PDF/product94/ME154-016X17X4X03.PDF)。这只是尺寸依据，不代表已锁定供应商品牌；可按尺寸采购，装配前量测厚度。

## 沿用的薄壳装配设计

1. 重新导入最终 CH32V006 按键板的 23 个元件模型；最终主板模型按 PCB 哈希核对并复用。无模型的 CN2/CN3 按厂家尺寸图建立保守包络，确认原插座不能放入 3.1 mm 后部净空间后，采用用户允许的直接焊线方式。
2. 后盖四个支柱与最终 PCB 孔轴重合。SCREW3 为壳体坐标 (3.501, 43.499) mm；撤销此前外壳中独立偏移的 0.5 mm，以实际最终板孔为准。四个孔实径约 2.20 mm，不能按旧符号名称使用 M3 螺钉。
3. 马达中心 (43, 60) mm，最大实体 Z=7.10～10.55 mm，增加与侧壁相连的托台、限位圈、线口及 SCREW1 螺钉避让。用 0.10 mm 胶固定，不硬压马达顶面。
4. 重做屏幕排线绕板路径，名义中性线总长 46.14 mm，C13 名义净距 0.29 mm；后盖左侧增加局部排线槽。排线宽度、端部和弯曲半径是结构参考，仍需按实物排线复核。
5. 保留普通 12P / 0.5 mm / 40 mm 异面 FFC 连接主板和按键板。模型中排线与连接器接触属于预期插入，端子面向、插入深度须装机确认。
6. 增厚滑环面板及止脱边、增加中央键周围避让，验证 0.33 mm 下压和四向摇摆名义行程。树脂介电常数及打印误差会影响触摸灵敏度，需要 CH32 固件实测标定。

## 马达、电池及线束

| 项目 | 本版选择 / 约束 |
|---|---|
| 纽扣马达 | Precision Microdrives **C08-005 LRA**，标称 Ø8 × 3.3 mm，模型按最大 Ø8.1 × 3.45 mm；1.8 Vrms、235 Hz，DRV2605L 使用 LRA 模式，样机校准 |
| 电芯候选 | BIHUADE/Liter **Liter-3020030**，厂家目录列 3.7 V、120 mAh、20C、30 × 20 × 3.0 mm。仅选型候选，目录未提供成品包最大厚度 |
| 成品电池限制 | **含保护板、胶带、NTC及尺寸公差必须 ≤21 × 33 × 3.0 mm**。另在厚度方向预留 0.3 mm；具体膨胀要求仍须供方批准。不能拿标称 3.0 mm 裸电芯直接认定成品合格 |
| 电池固定 | 按键板背面空白区 0.10 mm PET 隔离，0.20 mm 可移除胶固定；预留拉片，禁止螺钉或硬夹压软包 |
| 电流目标 | 成品包暂按 ≥0.6 A 连续、≥1 A/100 ms 瞬态询价，这是设计目标，尚非整机实测。保护板也必须满足该目标 |
| 线束 | 电池三线 AWG30 柔性导线，绝缘外径 ≤0.55 mm；马达线外径 ≤0.45 mm。边缘过板处加薄绝缘保护、柔性胶应力释放，勿堆叠焊锡 |

来源：[C08-005 厂家数据表修订 004](https://www.precisionmicrodrives.com/datasheets/C08-005%20-%20datasheet-004.pdf)、[Liter 高倍率电池目录](https://www.akkus-battery.com/index.php?c=category&id=10)。马达数据表为采样目标规格，采购时确认版本。电池不能用普通 1C 小容量软包随意替代；当前未承诺续航。供方未确认尺寸之前，先用绝缘尺寸块验证空间，不能挤压厚电池合盖。

**电池焊盘：CN2-1 VBAT，CN2-2 BAT_TS，CN2-3 GBAT。** GBAT 保留原电池检测回路，不要擅自接到别处 GND。NTC 必须匹配主板 BAT_TS 电路。**马达：CN3-1 MOTOR_OUT_P，CN3-2 MOTOR_OUT_N。** 原弯脚插座和配套插头均不装；模型内隐藏的原插座包络只用于说明冲突。

线束模型是外径和走线通道参考，不是成品裁线长度，也未模拟真实线材弯曲应力。装机时留平滑圆弧，避免尖锐板边、螺柱、FFC 锁扣及摇摆件。禁止带电焊电池：使用供方带焊接引线的保护电池包，板侧焊线与极性检查完成后再接通电池。

主板充电配置尚未针对此 120 mAh 电池验证。首次充电前必须核对 BQ25895 的充电/终止电流、NTC 与供方充电参数；本机械任务没有交付或修改固件。

## 紧固件与装配顺序

| 位置 | 数量与规格 | 注意 |
|---|---|---|
| 主板到后盖 | 4 × M2 × 4，头径 ≤3.6 mm、头高 ≤1.0 mm | 后盖底孔 Ø1.6 mm，手工攻牙、低扭矩；尤其 SCREW1 不能换高头 |
| 按键小板到上壳 | **3 × M1.6 × 2（头下长度）**，头径 ≤3.3 mm、头高 ≤0.5 mm | 每颗加 0.3 mm 平垫；头下长度不得超过 2.0 mm，名义旋入 0.9 mm |
| 小板限长平垫 | **3 × 内径 1.7 / 外径 4 / 厚 0.3 mm** | 必装，装于螺钉头与小板背面之间 |
| 后盖到机身 | 2 × M1.6 × 6，头径 ≤3.2 mm、头高 ≤0.5 mm | 配合后盖沉槽及上壳两颗胶粘铜螺母；实际螺钉先量尺寸 |

合计 **9 颗螺钉＋3 片平垫＋2 颗 M1.6 铜螺母**。另需右侧限位台绝缘垫和排线衬贴，均为剪裁粘贴件，不在打印包内。

本版后盖两处采用冷胶嵌件；禁止热压。上壳孔已按胶粘配合修改，装配前先完成上述粘接步骤。

1. 打印、清洗并完全后固化，清除支撑和工艺框，检查孔道及薄止脱边；必要时轻修配合面。
2. 从机身内部放入滑环、中央键，贴好限位台薄垫。按键板在安装平面向左偏约 1.2 mm 放入，再向右滑入边缘限位台，安装三颗带平垫的螺钉。检查板无翘曲、五键独立回弹和无预压，再连接排线。安装时主板、FFC 和电池线束尚不装入，避免牵拉。
3. 安装屏幕和前盖板，按模型绕回屏幕 FPC；前盖板 46 × 40 × 0.6 mm 是另购透明件，不打印。本包不含历史 screen-dummy。
4. 马达放入托座，用薄胶固定并沿通道引线；电池按限定包络及绝缘胶层固定到按键板背面。
5. 主板固定到后盖四柱，连接屏幕 FPC 和 40 mm 控制 FFC、绝缘线束；先开盖通电检查，再合盖。闭合过程中检查排线和线束没有被夹住。
6. 验证 USB 插头、耳机插头插拔、TF 推入弹出、按键行程、触摸、振动和充电发热。名义接口外形检查不能代替具体插头外壳的插拔验证。

## 验证边界

以 `fit-check.json` 为最终机器检查记录。几何检查包含壳体、两块板及导入元件、屏幕、两条 FPC/FFC、马达、电池包络、紧固件和线束；排除合理的螺纹啮合、连接器插入及胶固定重合；相交实体对的体积可能重复计数，只以是否存在交叠判断。四个打印件均为单实体，STL 闭合，单位 mm；详细外包尺寸见 `export-check.json`。

J 版的 `fit-check.json` 对全装配重新检查，并纳入两颗铜螺母；不再豁免后盖螺钉与上壳的交叠，确认螺钉仅与金属内螺纹配合、在树脂内留有通道。`insert-check.json` 另核对孔座、螺钉尖端、螺母安装路径和未修改件。小板装入路径沿用五个横向采样位置复查。最终检查结果以 JSON 文件为准；不含胶水工艺和粘接强度验证。

这些是**名义 CAD 检查**，不是制造公差堆栈、树脂强度试验或电池认证。U10 等少量模型为保守包络，FFC 接触厚度与锁扣装配空间、屏幕 FPC 形状和实物弯折、树脂收缩和薄边加工能力仍需验证。0.3 mm 电池增厚后与 U5 仅约 0.15 mm 名义余量；本方案适合先装机评估，不可宣称已经量产验证。

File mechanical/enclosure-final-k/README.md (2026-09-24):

# Q2 K 装入路径与结构修复版 — 2026-09-23

**本版用于树脂装机样件。J 版复查发现的装入障碍、局部薄壁和 LCD 无固定问题已在 K 版处理。** 完整静态检查未发现非预期实体干涉；分阶段装入的 66 个离散姿态全部通过；六套 STEP/STL 已从磁盘回读验证。可以提交 K 版文件作打样审核，不能视为已经通过厂家审核或实物装配验证。

整机 **50 × 81.5 × 15.1 mm（含前盖板）**，比 J 厚 0.9 mm；两块 PCB、接口、操作区中心及正面宽高保留。壳体本身最高 14.4 mm。打印上壳从装配 Z=1.2 起，因此其单件外包厚度为 13.2 mm，不等于整机厚度。

## 文件与修复内容

- `Q2_K_Assembly_Access.FCStd`：当前 FreeCAD 完整装配，含打印件、电子件、装配参考及参数表。主要结构由脚本构建的实体组成，不是完整草图约束树。
- `Q2_K_Assembly_Access.step`：整机交换模型，仅作装配参考，不可整体送印。
- **`Q2-K-assembly-sample.zip`**：五件必需打印件、一个可选螺母小样，各含 STEP/STL，加工说明及检查记录。
- `print-package/`：与 ZIP 一致的送印文件，单位 mm。每件独立局部原点；STEP 与 STL 是同件的两种格式，只选一种上传，避免重复下单。
- `front-assembled.png`、`shell-parts.png`、`back-internals.png`、`controls-mount-view.png`、`insert-section.png`：装配预览。

| 修复项 | K 版实现 |
|---|---|
| 滑环和小板无法进入 | 下方后盖螺柱缩短到 Z=6；马达托座改成后安装的独立打印件；明确先偏移、再滑入的装配路径 |
| 薄止脱边 | 滑环与中央键均为 1.0 mm；滑环面最薄局部 0.85 mm，内部避让同步调整 |
| 小板螺孔封顶 | 0.9 mm；螺钉改为头下长 2.5 mm，搭配 0.3 mm 平垫，名义旋入 1.4 mm |
| 后盖螺丝承压处 | 1.0 mm；头部凹槽 Ø3.8，仍使用限定的小头螺钉 |
| 原工艺框薄连杆 | 取消。滑环总高 2.15、中央键总高 2.05 mm，可作为独立零件上传 |
| LCD 悬空 | 增加两条 1.04 mm 厚支撑台、两条 20×1.1×0.2 mm 背面泡棉胶，屏幕从前侧装入 |
| 屏幕上升后的 FPC | 调整绕行及侧壁入口，PCB 插接端位置保留；名义中性线长 46.14 mm |
| 马达托座碰耳机座 | 独立托座增加角部避让，马达中心改为 (43,60.3) mm |
| 胶粘螺母装配余量 | 孔改为 Ø3.00×3.20，柱外径 Ø5.2；名义径向胶缝 0.25 mm |

请整套使用 K 的五个打印件，尤其上壳、后盖和两按键不要混用 J 或更早版本。新增的马达托座不能漏打。原来 `screen-dummy` 不属于本版送印件。

## 打印清单

| 文件名（STEP/STL 二选一） | 数量 | 外包尺寸 mm |
|---|---:|---|
| `01-housing` | 1 | 50 × 81.5 × 13.2 |
| `02-rear-cover` | 1 | 50 × 81.5 × 4.2 |
| `03-wheel` | 1 | 34.7 × 34.7 × 2.15 |
| `04-center-button` | 1 | 14.3 × 14.3 × 2.05 |
| `05-motor-carrier` | 1 | 约 11 × 10.8 × 2.25 |
| `06-insert-fit-coupon-optional` | 建议 1 | 24 × 8 × 5 |

采用适合薄壁装配的韧性 SLA 树脂；清洗、后固化、去支撑之后再试装。要求尽量避免在按键接触面、止脱边、胶粘面及螺孔内留下支撑损伤。模型不包含打印支撑，由厂家按材料和摆放方向处理。不要缩放模型凑材料尺寸。

K 消除了原来薄片的包围盒尺寸问题，但部分功能壁厚为 0.85～1.0 mm，尚未做到所有受力特征都超过 1.5 mm。嘉立创通用规范对连接/受力特征的建议更保守，具体材料仍须由其审核；薄壁树脂件不能按金属件扭矩装配。参考：[嘉立创设计规范](https://www.jlc.com/portal/q7i27832.html)、[JLC Black 尺寸与壁厚说明](https://jlc3dp.com/help/article/jlc-black-resin)。

## 五金和胶贴

所有螺钉长度均指**头下长度**。合计 **9 颗螺钉＋3 片平垫＋2 颗铜螺母**。

| 位置 | 数量与规格 | 配合要求 |
|---|---|---|
| 主板到后盖 | 4 × M2×4，头径 ≤3.6、头高 ≤1.0 mm | 后盖底孔 Ø1.6，手工限深攻牙、低扭矩 |
| 小板到上壳 | **3 × M1.6×2.5，头径 ≤3.3、头高 ≤0.5 mm** | 每颗必须配下列垫片；不要用 3 mm 替代 |
| 小板平垫 | 3 × ID1.7 / OD4 / 厚0.3 mm | 置于螺钉头与 PCB 背面之间 |
| 后盖到上壳 | 2 × M1.6×6，头径 ≤3.2、头高 ≤0.5 mm | 配合两颗胶粘铜螺母 |
| 铜螺母 | 2 × M1.6×0.35，无头滚花，最大外径2.5、总长3.0 mm | 参考 In-saiL MT-M1.6x3.0-OD2.5；不能替换为外径3 mm款 |
| LCD 背胶 | 2 条 20×1.1×0.2 mm（含胶总厚） | 粘于 LCD 背面边缘与支撑台，不能覆盖 FPC 根部或顶压玻璃 |
| 右侧小板限位垫 | 沿用 0.2 mm 含胶绝缘垫 | 贴在侧边限位台与小板接触处 |
| 马达固定 | 底部0.1 mm 胶贴；托座右侧0.2 mm胶层 | 托座粘接面积约10.25 mm²，完全固化后再装主板 |

小板三个螺钉中心为 (6,51)、(6,67)、(44,67) mm；(44,51) 只作支撑，不装第四颗螺钉，否则会碰 FFC。小板底孔 Ø1.3，深 1.6 mm，封顶 0.9 mm，螺钉尖端距孔底名义 0.2 mm。采购螺钉先量头下长度和垫片厚度，试装不得顶穿面壳。

铜螺母先试配小样：从带缺角一端开始依次 Ø2.90、3.00、3.10 mm；正式壳体孔固定 Ø3.00。确认实际最大滚花直径/长度，以兼容树脂和黄铜的环氧胶冷粘，禁止热压、硬压。只在外壁少量上胶，避免胶进入内螺纹和 Ø1.8 余孔。装入至定位台阶，端面低于柱口 0.20 mm；保持同轴直至完全固化。

胶粘孔在装配 Z=1.85～5.05，螺母 Z=2.05～5.05；螺柱主段壁厚1.10、入口最薄0.95 mm。上部螺钉尖端 Z=6.65，距盲通道末端7.20有0.55 mm。下部柱已缩短到Z=6，螺钉尖端高出柱顶0.65 mm，处于已检查的空隙中，不是顶住盲孔。胶接强度和防转效果需小样验证，不能靠螺钉强拉螺母入孔。

规格依据：[In-saiL 螺母](https://www.ppmcn.com/mini-tech-inserts/)、[Formlabs 树脂嵌件胶粘方法](https://formlabs.com/blog/adding-screw-threads-3d-printed-parts/)。厂家热嵌孔尺寸不适用于本版的冷胶孔。

## 装配顺序与方向

以下坐标为 FreeCAD 装配坐标：X 增大为正面视图右侧，Y 增大朝 USB/耳机口，Z 增大朝屏幕前脸。数值为相对最终位置的移动量，勿按后视图左右直接套用。

1. **先处理空壳。** 去支撑、清洗并完全后固化，试配螺母并粘好。胶完全固化后再装电子件。马达托座、主板、控制排线和电池此时均不安装。
2. **装滑环。** 上壳正面朝下，用软垫保护。滑环相对最终位置向屏幕方向偏移3.5 mm，从后侧进入，先停在比最终位置低5 mm的高度；向下端平移3.5 mm回到中心，再朝前脸推至最终位置。此路线绕过底部缩短的螺柱。中央键随后从后侧直入，推杆朝小板。
3. **装小板。** 先贴右侧0.2 mm限位垫。小板相对最终位置 X=-1.3、Y=-5 mm 从后侧进入，停在 Z=-0.5 mm；保持X偏移，沿Y回到0；再沿Z上移0.5到支撑平面；最后沿X向右滑1.3 mm进入侧边限位台。装三颗 M1.6×2.5＋0.3 mm平垫。检查板平整、按键无预压且能回弹。不能从后侧垂直硬压进限位台。
4. **装马达托座。** 先把马达用0.1 mm胶固定在托座中，导线从左侧缺口引出；模块从后侧进入。托座右侧与壳内壁留0.2 mm胶层，底面 Z=6.1，马达中心(43,60.3)，马达底面Z=7.3。定位并粘接至完全固化，不要用耳机座或 PCB 顶住定位。此件必须在小板装好后安装，否则会挡小板路线。
5. **装屏幕。** LCD 从正面装入，先把排线经左侧通道引到内部。两条0.2 mm背胶落在上下支撑台上，LCD背面 Z=12.74。再装另购的46×40×0.6 mm透明盖板及原周边胶；盖板背面Z=14.5，与LCD正面留0.3 mm，不以盖板挤压固定LCD。
6. **装电池、绝缘和线束。** 使用已确认尺寸的电池；未选到满足成品包络的产品时，先用绝缘尺寸块验证。保留背部绝缘、可拆胶和线束应力释放。连接12P/0.5 mm/40 mm异面FFC及屏幕FPC，核对接触面和锁扣。
7. **装主板/后盖。** 主板先用四颗 M2×4 固定在后盖四柱，连好柔性线束和排线后，从后侧平行合入上壳。检查线束随盖移动、不夹线，再以两颗M1.6×6低扭矩锁紧。后盖合装检查不包含排线的真实弯曲应力或工具可达性，实际试装仍须观察。

## 沿用的电子件约束

- 主板和 CH32V006 C 版小板文件见 `source.json`；哈希均与当前 PCB 一致，本任务没有修改 PCB。
- **CN2/CN3 不装原弯脚插座，仍采用直接焊柔性线束方案**；原插座背部高度不适合薄壳。电池 CN2-1=VBAT、2=BAT_TS、3=GBAT；马达 CN3-1=MOTOR_OUT_P、2=MOTOR_OUT_N。保留原检测回路，焊接和接电前核对极性。
- 马达按 C08-005 LRA 最大 Ø8.1×3.45 mm 建模。驱动模式和校准沿用此前要求；其他直流纽扣马达不能只按外形替换。
- 电池仍是**采购空间，不是已验证成品**：含保护板、NTC、胶带和公差 ≤21×33×3 mm；另留0.3 mm增厚余量后，与U5仅约0.15 mm名义间距。原Liter-3020030仅为裸电芯候选。供方确认成品尺寸、电流和充电参数之前，不可挤压厚电池合盖。
- 电池与小板之间保留0.1 mm PET及0.2 mm可移除胶。CN2/CN3改线不表示充电固件已经适配该小容量电池。
- 屏幕外形36.33×43.45×1.46 mm及排线总长46.14 mm来自用户图纸。**宽排线根部长度13.8 mm、过渡轮廓和弯曲半径仍为建模假设**，原图没有完整标注；需要实物检验。PCB插接端位置不变，不能把名义几何可达理解为已经确认实物兼容。
- 40 mm控制FFC型号、接触面、插入深度和触摸灵敏度仍需实物验证；触摸面变厚后需要重新标定CH32固件。

## 验证结果与边界

- `fit-check.json`：188个检查对象，按每对实体检查复合体；非预期静态干涉0、无效实体0、电池增厚包络干涉0。仅豁免明确的螺纹配合、连接器插入及线端连接。
- `assembly-path-check.json`：滑环16、中央键8、小板20、马达模块8、LCD7、后盖/主板7个姿态，均无干涉。**这是66个分阶段离散采样，不是连续扫掠证明**，也不包含软排线变形和工具空间验证。
- 按键下压0.33 mm、滑环四向摇摆约0.727°的名义状态均通过；实际开关力、树脂弹性和回弹需要样机测试。
- `detail-check.json`：止脱边、螺丝承压厚度、三处螺孔封顶、LCD支撑及胶贴接触、螺母后侧装入和后盖螺钉通道均通过。
- `export-readback-check.json`：六件均为有效单实体、闭合单连通STL，无自交、非流形边及法向错误；回读STEP与最终FCStd打印件几何差为0。ZIP经CRC及SHA256校验。

结论是**可进行 K 版装机样件打样审核**。尚未做制造公差堆栈、树脂强度、胶接拉拔、扭矩、跌落、插头实物适配或续航/发热试验；J版的暂缓结论保留作历史，不应与K版混用。

重建入口：`scripts/build_k.py` → `audit.py`、`check_assembly_paths.py --rear`、`check_details.py` → `export_parts.py` → FreeCAD GUI运行 `render.FCMacro` → `check_exports.py` → `package.py`。脚本使用 FreeCAD Python 环境。

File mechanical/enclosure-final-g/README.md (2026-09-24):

# Q2 G 薄壳装机样件 — 2026-09-22

> 此版已被 I 版替代。后续复查发现复合排线检查漏报了小板右上螺钉与 FFC 等干涉，请使用 [I 版装配优化工程](../enclosure-final-i/README.md)，不要以旧版零干涉结论作为装配依据。

当前外壳工程为 **Q2_G_Thin_Assembly.FCStd**，适配最终 `hardware-q2/ProPrj_esp32s31-mp4_2026-09-22.kicad_pcb` 和 CH32V006 C 版 `hardware-controls/controls.kicad_pcb`。本次不修改电路板。面宽 50 mm、高 81.5 mm，壳体厚 13.5 mm，含前盖板最大厚度 14.2 mm。保留屏幕上、左、右 2 mm 边距及当前操作区中心。

这是树脂打印的装机验证版本，不是量产定版。**保持薄壳的前提是 CN2/CN3 不装原高插座，改为焊接柔性线束。电池成品尺寸尚未获得供方确认。**

## 文件

- `Q2_G_Thin_Assembly.FCStd`：完整装配，分为打印件、电子件、装配参考和隐藏诊断包络；尺寸记录在 DesignParameters 表中。几何构建脚本位于 `scripts/`，不是完整草图约束建模树。
- `Q2_G_Thin_Assembly.step`：整机交换模型，仅供装配检查，不可整体送印。
- `Q2-G-resin-sample.zip`：四个打印件的 STEP/STL、加工说明和验证记录。
- `print-package/`：实际送印文件，毫米单位，每个文件独立局部原点。
- `clean-parts/`：去工艺框后的滑环和中央键 STEP，保持装配坐标，供机械修改。
- `source.json`、`fit-check.json`、`export-check.json`：PCB 版本、名义干涉检查及网格尺寸/闭合性记录。
- `front-assembled.png`、`back-internals.png`、`shell-parts.png`：装配和内部结构预览。

## 本版调整

1. 重新导入最终 CH32V006 按键板的 23 个元件模型；最终主板模型按 PCB 哈希核对并复用。无模型的 CN2/CN3 按厂家尺寸图建立保守包络，确认原插座不能放入 3.1 mm 后部净空间后，采用用户允许的直接焊线方式。
2. 后盖四个支柱与最终 PCB 孔轴重合。SCREW3 为壳体坐标 (3.501, 43.499) mm；撤销此前外壳中独立偏移的 0.5 mm，以实际最终板孔为准。四个孔实径约 2.20 mm，不能按旧符号名称使用 M3 螺钉。
3. 马达中心 (43, 60) mm，最大实体 Z=7.10～10.55 mm，增加与侧壁相连的托台、限位圈、线口及 SCREW1 螺钉避让。用 0.10 mm 胶固定，不硬压马达顶面。
4. 重做屏幕排线绕板路径，名义中性线总长 46.14 mm，C13 名义净距 0.29 mm；后盖左侧增加局部排线槽。排线宽度、端部和弯曲半径是结构参考，仍需按实物排线复核。
5. 保留普通 12P / 0.5 mm / 40 mm 异面 FFC 连接主板和按键板。模型中排线与连接器接触属于预期插入，端子面向、插入深度须装机确认。
6. 增厚滑环面板及止脱边、增加中央键周围避让，验证 0.33 mm 下压和四向摇摆名义行程。树脂介电常数及打印误差会影响触摸灵敏度，需要 CH32 固件实测标定。

## 马达、电池及线束

| 项目 | 本版选择 / 约束 |
|---|---|
| 纽扣马达 | Precision Microdrives **C08-005 LRA**，标称 Ø8 × 3.3 mm，模型按最大 Ø8.1 × 3.45 mm；1.8 Vrms、235 Hz，DRV2605L 使用 LRA 模式，样机校准 |
| 电芯候选 | BIHUADE/Liter **Liter-3020030**，厂家目录列 3.7 V、120 mAh、20C、30 × 20 × 3.0 mm。仅选型候选，目录未提供成品包最大厚度 |
| 成品电池限制 | **含保护板、胶带、NTC及尺寸公差必须 ≤21 × 33 × 3.0 mm**。另在厚度方向预留 0.3 mm；具体膨胀要求仍须供方批准。不能拿标称 3.0 mm 裸电芯直接认定成品合格 |
| 电池固定 | 按键板背面空白区 0.10 mm PET 隔离，0.20 mm 可移除胶固定；预留拉片，禁止螺钉或硬夹压软包 |
| 电流目标 | 成品包暂按 ≥0.6 A 连续、≥1 A/100 ms 瞬态询价，这是设计目标，尚非整机实测。保护板也必须满足该目标 |
| 线束 | 电池三线 AWG30 柔性导线，绝缘外径 ≤0.55 mm；马达线外径 ≤0.45 mm。边缘过板处加薄绝缘保护、柔性胶应力释放，勿堆叠焊锡 |

来源：[C08-005 厂家数据表修订 004](https://www.precisionmicrodrives.com/datasheets/C08-005%20-%20datasheet-004.pdf)、[Liter 高倍率电池目录](https://www.akkus-battery.com/index.php?c=category&id=10)。马达数据表为采样目标规格，采购时确认版本。电池不能用普通 1C 小容量软包随意替代；当前未承诺续航。供方未确认尺寸之前，先用绝缘尺寸块验证空间，不能挤压厚电池合盖。

**电池焊盘：CN2-1 VBAT，CN2-2 BAT_TS，CN2-3 GBAT。** GBAT 保留原电池检测回路，不要擅自接到别处 GND。NTC 必须匹配主板 BAT_TS 电路。**马达：CN3-1 MOTOR_OUT_P，CN3-2 MOTOR_OUT_N。** 原弯脚插座和配套插头均不装；模型内隐藏的原插座包络只用于说明冲突。

线束模型是外径和走线通道参考，不是成品裁线长度，也未模拟真实线材弯曲应力。装机时留平滑圆弧，避免尖锐板边、螺柱、FFC 锁扣及摇摆件。禁止带电焊电池：使用供方带焊接引线的保护电池包，板侧焊线与极性检查完成后再接通电池。

主板充电配置尚未针对此 120 mAh 电池验证。首次充电前必须核对 BQ25895 的充电/终止电流、NTC 与供方充电参数；本机械任务没有交付或修改固件。

## 紧固件与装配顺序

| 位置 | 数量与规格 | 注意 |
|---|---|---|
| 主板到后盖 | 4 × M2 × 4，头径 ≤3.6 mm、头高 ≤1.0 mm | 后盖底孔 Ø1.6 mm，手工攻牙、低扭矩；尤其 SCREW1 不能换高头 |
| 按键小板 | 4 × M1.6 × 2 | 保留 Ø1.3 mm 底孔，树脂有效啮合较短，仅样件低扭矩固定，不能反复大力拆装 |
| 后盖到机身 | 2 × M1.6 × 6，头径 ≤3.2 mm、头高 ≤0.5 mm | 配合后盖沉槽；实际螺钉先量尺寸 |

本版不采用热熔镶嵌螺母。树脂不适合按热塑料方式直接热压；若改冷胶嵌件需另改柱孔。

1. 打印、清洗并完全后固化，清除支撑和工艺框，检查孔道及薄止脱边；必要时轻修配合面。
2. 从机身内部放入滑环、中央键，安装按键板，检查五个按键独立回弹和无预压。
3. 安装屏幕和前盖板，按模型绕回屏幕 FPC；前盖板 46 × 40 × 0.6 mm 是另购透明件，不打印。本包不含历史 screen-dummy。
4. 马达放入托座，用薄胶固定并沿通道引线；电池按限定包络及绝缘胶层固定到按键板背面。
5. 主板固定到后盖四柱，连接屏幕 FPC 和 40 mm 控制 FFC、绝缘线束；先开盖通电检查，再合盖。闭合过程中检查排线和线束没有被夹住。
6. 验证 USB 插头、耳机插头插拔、TF 推入弹出、按键行程、触摸、振动和充电发热。名义接口外形检查不能代替具体插头外壳的插拔验证。

## 验证边界

以 `fit-check.json` 为最终机器检查记录。几何检查包含壳体、两块板及导入元件、屏幕、两条 FPC/FFC、马达、电池包络、紧固件和线束；排除合理的螺纹啮合、连接器插入及胶固定重合。四个打印件均为单实体，STL 闭合，单位 mm；详细外包尺寸见 `export-check.json`。

本次最终结果：静态实体干涉 0，电池增加 0.3 mm 厚度后的检查干涉 0，无效实体 0；中央键/滑环 0.33 mm 下压及四向摇摆未与检查对象相撞。全装配检查后仅重新安排两根马达线，已对这两根线与全部其他装配对象逐对复查，其余几何沿用全检查结果。

这些是**名义 CAD 检查**，不是制造公差堆栈、树脂强度试验或电池认证。U10 等少量模型为保守包络，FFC 接触厚度与锁扣装配空间、屏幕 FPC 形状和实物弯折、树脂收缩和薄边加工能力仍需验证。0.3 mm 电池增厚后与 U5 仅约 0.15 mm 名义余量；本方案适合先装机评估，不可宣称已经量产验证。

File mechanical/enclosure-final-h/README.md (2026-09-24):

# Q2 H 加强固定版 — 2026-09-23

> 此版已被 I 版替代。后续复查发现复合排线检查漏报了小板右上螺钉与 FFC 等干涉，请使用 [I 版装配优化工程](../enclosure-final-i/README.md)，不要以旧版零干涉结论作为装配依据。

当前外壳工程为 **Q2_H_Reinforced_Assembly.FCStd**，适配最终 `hardware-q2/ProPrj_esp32s31-mp4_2026-09-22.kicad_pcb` 和 CH32V006 C 版 `hardware-controls/controls.kicad_pcb`。本次不修改电路板。面宽 50 mm、高 81.5 mm，壳体厚 13.5 mm，含前盖板最大厚度 14.2 mm。保留屏幕上、左、右 2 mm 边距及当前操作区中心。

这是树脂打印的装机验证版本，不是量产定版。**保持薄壳的前提是 CN2/CN3 不装原高插座，改为焊接柔性线束。电池成品尺寸尚未获得供方确认。**

## 文件

- `Q2_H_Reinforced_Assembly.FCStd`：完整装配，分为打印件、电子件、装配参考和隐藏诊断包络；尺寸记录在 DesignParameters 表中。几何构建脚本位于 `scripts/`，不是完整草图约束建模树。
- `Q2_H_Reinforced_Assembly.step`：整机交换模型，仅供装配检查，不可整体送印。
- `Q2-H-resin-sample.zip`：四个打印件的 STEP/STL、加工说明和验证记录。
- `print-package/`：实际送印文件，毫米单位，每个文件独立局部原点。
- `clean-parts/`：去工艺框后的滑环和中央键 STEP，保持装配坐标，供机械修改。
- `source.json`、`fit-check.json`、`export-check.json`：PCB 版本、名义干涉检查及网格尺寸/闭合性记录。
- `front-assembled.png`、`back-internals.png`、`shell-parts.png`：装配和内部结构预览。

## H 版加强内容

- 小板四个接触柱由 Ø4 增至 Ø5 mm，锥形根部最大 Ø6 mm，降低螺柱根部的应力集中；每柱增加宽 1.4 mm、高 0.65 mm 的侧壁连接筋。
- 小板安装高度和外观保持不变，底孔 Ø1.3 mm、深 1.3 mm。前表面仍留 0.3 mm 封底；必须限深清孔和使用适当的底锥攻牙，避免穿透正面。
- 小板用 M1.6 × 2 mm 薄头机牙螺钉，长度指头下长度；实测长度应控制在 1.9～2.0 mm，超过 2.0 mm 的螺钉不可强拧。名义旋入约 1.1～1.2 mm，模型螺钉尖端距盲孔底 0.1 mm。
- 仍为树脂样件的几何加强，没有经过有限元分析、拉拔或循环拆装试验；不得据此推定可承受更大拧紧扭矩。不得用自攻螺钉或过长螺钉强行扩孔。
- `reinforcement.json` 记录四孔位置、柱径和轴向余量；`reinforced-upper-shell.png` 为加强后的上壳内侧。G 版保留为历史，本次只需替换上壳；后盖、滑环、中央键几何沿用 G 版。

## 沿用的薄壳装配设计

1. 重新导入最终 CH32V006 按键板的 23 个元件模型；最终主板模型按 PCB 哈希核对并复用。无模型的 CN2/CN3 按厂家尺寸图建立保守包络，确认原插座不能放入 3.1 mm 后部净空间后，采用用户允许的直接焊线方式。
2. 后盖四个支柱与最终 PCB 孔轴重合。SCREW3 为壳体坐标 (3.501, 43.499) mm；撤销此前外壳中独立偏移的 0.5 mm，以实际最终板孔为准。四个孔实径约 2.20 mm，不能按旧符号名称使用 M3 螺钉。
3. 马达中心 (43, 60) mm，最大实体 Z=7.10～10.55 mm，增加与侧壁相连的托台、限位圈、线口及 SCREW1 螺钉避让。用 0.10 mm 胶固定，不硬压马达顶面。
4. 重做屏幕排线绕板路径，名义中性线总长 46.14 mm，C13 名义净距 0.29 mm；后盖左侧增加局部排线槽。排线宽度、端部和弯曲半径是结构参考，仍需按实物排线复核。
5. 保留普通 12P / 0.5 mm / 40 mm 异面 FFC 连接主板和按键板。模型中排线与连接器接触属于预期插入，端子面向、插入深度须装机确认。
6. 增厚滑环面板及止脱边、增加中央键周围避让，验证 0.33 mm 下压和四向摇摆名义行程。树脂介电常数及打印误差会影响触摸灵敏度，需要 CH32 固件实测标定。

## 马达、电池及线束

| 项目 | 本版选择 / 约束 |
|---|---|
| 纽扣马达 | Precision Microdrives **C08-005 LRA**，标称 Ø8 × 3.3 mm，模型按最大 Ø8.1 × 3.45 mm；1.8 Vrms、235 Hz，DRV2605L 使用 LRA 模式，样机校准 |
| 电芯候选 | BIHUADE/Liter **Liter-3020030**，厂家目录列 3.7 V、120 mAh、20C、30 × 20 × 3.0 mm。仅选型候选，目录未提供成品包最大厚度 |
| 成品电池限制 | **含保护板、胶带、NTC及尺寸公差必须 ≤21 × 33 × 3.0 mm**。另在厚度方向预留 0.3 mm；具体膨胀要求仍须供方批准。不能拿标称 3.0 mm 裸电芯直接认定成品合格 |
| 电池固定 | 按键板背面空白区 0.10 mm PET 隔离，0.20 mm 可移除胶固定；预留拉片，禁止螺钉或硬夹压软包 |
| 电流目标 | 成品包暂按 ≥0.6 A 连续、≥1 A/100 ms 瞬态询价，这是设计目标，尚非整机实测。保护板也必须满足该目标 |
| 线束 | 电池三线 AWG30 柔性导线，绝缘外径 ≤0.55 mm；马达线外径 ≤0.45 mm。边缘过板处加薄绝缘保护、柔性胶应力释放，勿堆叠焊锡 |

来源：[C08-005 厂家数据表修订 004](https://www.precisionmicrodrives.com/datasheets/C08-005%20-%20datasheet-004.pdf)、[Liter 高倍率电池目录](https://www.akkus-battery.com/index.php?c=category&id=10)。马达数据表为采样目标规格，采购时确认版本。电池不能用普通 1C 小容量软包随意替代；当前未承诺续航。供方未确认尺寸之前，先用绝缘尺寸块验证空间，不能挤压厚电池合盖。

**电池焊盘：CN2-1 VBAT，CN2-2 BAT_TS，CN2-3 GBAT。** GBAT 保留原电池检测回路，不要擅自接到别处 GND。NTC 必须匹配主板 BAT_TS 电路。**马达：CN3-1 MOTOR_OUT_P，CN3-2 MOTOR_OUT_N。** 原弯脚插座和配套插头均不装；模型内隐藏的原插座包络只用于说明冲突。

线束模型是外径和走线通道参考，不是成品裁线长度，也未模拟真实线材弯曲应力。装机时留平滑圆弧，避免尖锐板边、螺柱、FFC 锁扣及摇摆件。禁止带电焊电池：使用供方带焊接引线的保护电池包，板侧焊线与极性检查完成后再接通电池。

主板充电配置尚未针对此 120 mAh 电池验证。首次充电前必须核对 BQ25895 的充电/终止电流、NTC 与供方充电参数；本机械任务没有交付或修改固件。

## 紧固件与装配顺序

| 位置 | 数量与规格 | 注意 |
|---|---|---|
| 主板到后盖 | 4 × M2 × 4，头径 ≤3.6 mm、头高 ≤1.0 mm | 后盖底孔 Ø1.6 mm，手工攻牙、低扭矩；尤其 SCREW1 不能换高头 |
| 按键小板到上壳 | 4 × M1.6 × 2（头下长度），头径 ≤3.3 mm、头高 ≤0.5 mm | H 版加深 Ø1.3 mm 底孔；实测头下长度 1.9～2.0 mm，名义旋入 1.1～1.2 mm，底孔限深攻牙 |
| 后盖到机身 | 2 × M1.6 × 6，头径 ≤3.2 mm、头高 ≤0.5 mm | 配合后盖沉槽；实际螺钉先量尺寸 |

本版不采用热熔镶嵌螺母。树脂不适合按热塑料方式直接热压；若改冷胶嵌件需另改柱孔。

1. 打印、清洗并完全后固化，清除支撑和工艺框，检查孔道及薄止脱边；必要时轻修配合面。
2. 从机身内部放入滑环、中央键，安装按键板，检查五个按键独立回弹和无预压。
3. 安装屏幕和前盖板，按模型绕回屏幕 FPC；前盖板 46 × 40 × 0.6 mm 是另购透明件，不打印。本包不含历史 screen-dummy。
4. 马达放入托座，用薄胶固定并沿通道引线；电池按限定包络及绝缘胶层固定到按键板背面。
5. 主板固定到后盖四柱，连接屏幕 FPC 和 40 mm 控制 FFC、绝缘线束；先开盖通电检查，再合盖。闭合过程中检查排线和线束没有被夹住。
6. 验证 USB 插头、耳机插头插拔、TF 推入弹出、按键行程、触摸、振动和充电发热。名义接口外形检查不能代替具体插头外壳的插拔验证。

## 验证边界

以 `fit-check.json` 为最终机器检查记录。几何检查包含壳体、两块板及导入元件、屏幕、两条 FPC/FFC、马达、电池包络、紧固件和线束；排除合理的螺纹啮合、连接器插入及胶固定重合。四个打印件均为单实体，STL 闭合，单位 mm；详细外包尺寸见 `export-check.json`。

本次最终结果：静态实体干涉 0，电池增加 0.3 mm 厚度后的检查干涉 0，无效实体 0；中央键/滑环 0.33 mm 下压及四向摇摆未与检查对象相撞。G 版检查作为基线，H 版改变上壳和四个小板螺钉包络，已对所有包含这两类对象的组合重新检查，并重查按键行程及电池增厚空间。其余实体与 G 版一致。

这些是**名义 CAD 检查**，不是制造公差堆栈、树脂强度试验或电池认证。U10 等少量模型为保守包络，FFC 接触厚度与锁扣装配空间、屏幕 FPC 形状和实物弯折、树脂收缩和薄边加工能力仍需验证。0.3 mm 电池增厚后与 U5 仅约 0.15 mm 名义余量；本方案适合先装机评估，不可宣称已经量产验证。

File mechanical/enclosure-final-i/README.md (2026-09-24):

# Q2 I 装配优化版 — 2026-09-23

当前外壳工程为 **Q2_I_Serviceable_Assembly.FCStd**，适配最终 `hardware-q2/ProPrj_esp32s31-mp4_2026-09-22.kicad_pcb` 和 CH32V006 C 版 `hardware-controls/controls.kicad_pcb`。本次不修改电路板。面宽 50 mm、高 81.5 mm，壳体厚 13.5 mm，含前盖板最大厚度 14.2 mm。保留屏幕上、左、右 2 mm 边距及当前操作区中心。

这是树脂打印的装机验证版本，不是量产定版。**保持薄壳的前提是 CN2/CN3 不装原高插座，改为焊接柔性线束。电池成品尺寸尚未获得供方确认。**

## 文件

- `Q2_I_Serviceable_Assembly.FCStd`：完整装配，分为打印件、电子件、装配参考和隐藏诊断包络；尺寸记录在 DesignParameters 表中。几何构建脚本位于 `scripts/`，不是完整草图约束建模树。
- `Q2_I_Serviceable_Assembly.step`：整机交换模型，仅供装配检查，不可整体送印。
- `Q2-I-resin-sample.zip`：四个打印件的 STEP/STL、加工说明和验证记录。
- `print-package/`：实际送印文件，毫米单位，每个文件独立局部原点。
- `clean-parts/`：去工艺框后的滑环和中央键 STEP，保持装配坐标，供机械修改。
- `source.json`、`fit-check.json`、`export-check.json`：PCB 版本、名义干涉检查及网格尺寸/闭合性记录。
- `front-assembled.png`、`back-internals.png`、`shell-parts.png`：装配和内部结构预览。

## I 版改动与更正

**此前 G/H 的复合排线布尔运算存在漏报，实际右上角小板螺钉穿过 FFC，部分马达导线也有交叠。I 版已修正几何检查方法并处理这些干涉；旧版“零干涉”结论不能作为该排线装配的依据。**

- 小板改成 **三颗螺钉＋右侧边缘限位台**。壳体坐标 (44,51) mm 的原螺柱继续支撑小板，但孔已封闭，不装螺钉；FFC 可保持原 12P、0.5 mm、40 mm 异面直排线。三个螺钉位置是 (6,51)、(6,67)、(44,67) mm。不能在封闭柱上自行钻孔加回第四颗螺钉。
- 右侧限位台位于 Y55.45～56.65 mm，搭接小板边缘约 1.2 mm，贴总厚 0.2 mm 的绝缘垫（含胶）。装板时先从左侧偏移约 1.2 mm 的位置向右滑入，再拧三颗螺钉；不掰弯限位台硬压入。
- 每颗小板螺钉配一片 **内径 1.7、外径 4、厚 0.3 mm 的 M1.6 平垫**。名义头下长度 2 mm，旋入约 0.9 mm；盲孔 Ø1.3、深 1.1 mm，孔顶封底加厚到 0.5 mm，螺钉尖端至孔底名义余量 0.2 mm。保留 H 版 Ø5 接触柱、Ø6 根部和侧壁加强筋。
- 该取舍增加了防顶穿余量，但螺纹旋入由 H 版 1.2 mm 减至约 0.9 mm，仍只适合低扭矩样件固定。缺少垫片会失去设计余量；实际螺钉头下长度不得超过 2.0 mm。底孔必须限深加工，未验证循环拆装寿命。
- 滑环止脱边由约 0.4 加厚至 **0.5 mm**，外半径增至 17.35 mm，根部 R0.12；中央键止脱边由约 0.3 加厚至 **0.4 mm**，半径增至 7.15 mm，根部 R0.15。同步调整内部避让，按键外观面和推杆高度保留。
- 屏幕和控制排线增加端部带 R0.6 的侧壁避让槽，配置 0.05 mm 薄绝缘衬贴参考。主板左边电池线跨板位置增加薄绝缘护边参考，避开 SCREW3。重排两根马达导线，绕过壳体圆角和主板边缘，并错开靠近马达的交叉段。
- `optimization.json` 记录改动，`insertion-check.json` 记录装入采样检查。本次四个打印件均有修改，使用完整 I 版打印包，不要混用旧上壳、后盖或按键。

平垫尺寸依据：[M1.6 DIN125A 厂商规格](https://www.aspenfasteners.com/content/2D_PDF/product94/ME154-016X17X4X03.PDF)。这只是尺寸依据，不代表已锁定供应商品牌；可按尺寸采购，装配前量测厚度。

## 沿用的薄壳装配设计

1. 重新导入最终 CH32V006 按键板的 23 个元件模型；最终主板模型按 PCB 哈希核对并复用。无模型的 CN2/CN3 按厂家尺寸图建立保守包络，确认原插座不能放入 3.1 mm 后部净空间后，采用用户允许的直接焊线方式。
2. 后盖四个支柱与最终 PCB 孔轴重合。SCREW3 为壳体坐标 (3.501, 43.499) mm；撤销此前外壳中独立偏移的 0.5 mm，以实际最终板孔为准。四个孔实径约 2.20 mm，不能按旧符号名称使用 M3 螺钉。
3. 马达中心 (43, 60) mm，最大实体 Z=7.10～10.55 mm，增加与侧壁相连的托台、限位圈、线口及 SCREW1 螺钉避让。用 0.10 mm 胶固定，不硬压马达顶面。
4. 重做屏幕排线绕板路径，名义中性线总长 46.14 mm，C13 名义净距 0.29 mm；后盖左侧增加局部排线槽。排线宽度、端部和弯曲半径是结构参考，仍需按实物排线复核。
5. 保留普通 12P / 0.5 mm / 40 mm 异面 FFC 连接主板和按键板。模型中排线与连接器接触属于预期插入，端子面向、插入深度须装机确认。
6. 增厚滑环面板及止脱边、增加中央键周围避让，验证 0.33 mm 下压和四向摇摆名义行程。树脂介电常数及打印误差会影响触摸灵敏度，需要 CH32 固件实测标定。

## 马达、电池及线束

| 项目 | 本版选择 / 约束 |
|---|---|
| 纽扣马达 | Precision Microdrives **C08-005 LRA**，标称 Ø8 × 3.3 mm，模型按最大 Ø8.1 × 3.45 mm；1.8 Vrms、235 Hz，DRV2605L 使用 LRA 模式，样机校准 |
| 电芯候选 | BIHUADE/Liter **Liter-3020030**，厂家目录列 3.7 V、120 mAh、20C、30 × 20 × 3.0 mm。仅选型候选，目录未提供成品包最大厚度 |
| 成品电池限制 | **含保护板、胶带、NTC及尺寸公差必须 ≤21 × 33 × 3.0 mm**。另在厚度方向预留 0.3 mm；具体膨胀要求仍须供方批准。不能拿标称 3.0 mm 裸电芯直接认定成品合格 |
| 电池固定 | 按键板背面空白区 0.10 mm PET 隔离，0.20 mm 可移除胶固定；预留拉片，禁止螺钉或硬夹压软包 |
| 电流目标 | 成品包暂按 ≥0.6 A 连续、≥1 A/100 ms 瞬态询价，这是设计目标，尚非整机实测。保护板也必须满足该目标 |
| 线束 | 电池三线 AWG30 柔性导线，绝缘外径 ≤0.55 mm；马达线外径 ≤0.45 mm。边缘过板处加薄绝缘保护、柔性胶应力释放，勿堆叠焊锡 |

来源：[C08-005 厂家数据表修订 004](https://www.precisionmicrodrives.com/datasheets/C08-005%20-%20datasheet-004.pdf)、[Liter 高倍率电池目录](https://www.akkus-battery.com/index.php?c=category&id=10)。马达数据表为采样目标规格，采购时确认版本。电池不能用普通 1C 小容量软包随意替代；当前未承诺续航。供方未确认尺寸之前，先用绝缘尺寸块验证空间，不能挤压厚电池合盖。

**电池焊盘：CN2-1 VBAT，CN2-2 BAT_TS，CN2-3 GBAT。** GBAT 保留原电池检测回路，不要擅自接到别处 GND。NTC 必须匹配主板 BAT_TS 电路。**马达：CN3-1 MOTOR_OUT_P，CN3-2 MOTOR_OUT_N。** 原弯脚插座和配套插头均不装；模型内隐藏的原插座包络只用于说明冲突。

线束模型是外径和走线通道参考，不是成品裁线长度，也未模拟真实线材弯曲应力。装机时留平滑圆弧，避免尖锐板边、螺柱、FFC 锁扣及摇摆件。禁止带电焊电池：使用供方带焊接引线的保护电池包，板侧焊线与极性检查完成后再接通电池。

主板充电配置尚未针对此 120 mAh 电池验证。首次充电前必须核对 BQ25895 的充电/终止电流、NTC 与供方充电参数；本机械任务没有交付或修改固件。

## 紧固件与装配顺序

| 位置 | 数量与规格 | 注意 |
|---|---|---|
| 主板到后盖 | 4 × M2 × 4，头径 ≤3.6 mm、头高 ≤1.0 mm | 后盖底孔 Ø1.6 mm，手工攻牙、低扭矩；尤其 SCREW1 不能换高头 |
| 按键小板到上壳 | **3 × M1.6 × 2（头下长度）**，头径 ≤3.3 mm、头高 ≤0.5 mm | 每颗加 0.3 mm 平垫；头下长度不得超过 2.0 mm，名义旋入 0.9 mm |
| 小板限长平垫 | **3 × 内径 1.7 / 外径 4 / 厚 0.3 mm** | 必装，装于螺钉头与小板背面之间 |
| 后盖到机身 | 2 × M1.6 × 6，头径 ≤3.2 mm、头高 ≤0.5 mm | 配合后盖沉槽；实际螺钉先量尺寸 |

合计 **9 颗螺钉＋3 片平垫**。另需右侧限位台绝缘垫和排线衬贴，均为剪裁粘贴件，不在打印包内。

本版不采用热熔镶嵌螺母。树脂不适合按热塑料方式直接热压；若改冷胶嵌件需另改柱孔。

1. 打印、清洗并完全后固化，清除支撑和工艺框，检查孔道及薄止脱边；必要时轻修配合面。
2. 从机身内部放入滑环、中央键，贴好限位台薄垫。按键板在安装平面向左偏约 1.2 mm 放入，再向右滑入边缘限位台，安装三颗带平垫的螺钉。检查板无翘曲、五键独立回弹和无预压，再连接排线。安装时主板、FFC 和电池线束尚不装入，避免牵拉。
3. 安装屏幕和前盖板，按模型绕回屏幕 FPC；前盖板 46 × 40 × 0.6 mm 是另购透明件，不打印。本包不含历史 screen-dummy。
4. 马达放入托座，用薄胶固定并沿通道引线；电池按限定包络及绝缘胶层固定到按键板背面。
5. 主板固定到后盖四柱，连接屏幕 FPC 和 40 mm 控制 FFC、绝缘线束；先开盖通电检查，再合盖。闭合过程中检查排线和线束没有被夹住。
6. 验证 USB 插头、耳机插头插拔、TF 推入弹出、按键行程、触摸、振动和充电发热。名义接口外形检查不能代替具体插头外壳的插拔验证。

## 验证边界

以 `fit-check.json` 为最终机器检查记录。几何检查包含壳体、两块板及导入元件、屏幕、两条 FPC/FFC、马达、电池包络、紧固件和线束；排除合理的螺纹啮合、连接器插入及胶固定重合；相交实体对的体积可能重复计数，只以是否存在交叠判断。四个打印件均为单实体，STL 闭合，单位 mm；详细外包尺寸见 `export-check.json`。

本次最终结果：静态实体干涉 0，电池增加 0.3 mm 厚度后的检查干涉 0，无效实体 0；中央键/滑环 0.33 mm 下压及四向摇摆未与检查对象相撞。I 版重新对全装配检查：先融合排线加强片及线束分段的重叠实体，再按实体逐对检查，避免旧方法漏报。全检查后调整两根马达线和绝缘护边，对所有相关配对复查；同名对象去重，避免重复计算自身。小板装入路径检查了 -1.2、-0.9、-0.6、-0.3、0 mm 五个横向偏移位置，未做连续扫掠或摩擦变形仿真。

这些是**名义 CAD 检查**，不是制造公差堆栈、树脂强度试验或电池认证。U10 等少量模型为保守包络，FFC 接触厚度与锁扣装配空间、屏幕 FPC 形状和实物弯折、树脂收缩和薄边加工能力仍需验证。0.3 mm 电池增厚后与 U5 仅约 0.15 mm 名义余量；本方案适合先装机评估，不可宣称已经量产验证。

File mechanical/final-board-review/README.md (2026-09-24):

# hardware-q2 最终主板与按键小板装配检查

检查日期：2026-09-22。打开 **Q2_Final_Mainboard_Assembly.FCStd**，默认显示实际导入的两块 PCB 与内部结构；展开 `ReviewDiagnostics` 可查看红色干涉实体和主板安装孔轴线。

**同日机械修改：SCREW3 对应后盖固定柱及孔按 KiCad 顶视图向左移动 0.5 mm（向板内）。壳体中的实际中心由 (3.500, 43.500) 改为 (4.000, 43.500) mm，孔径、柱径和高度不变。当前 PCB 孔位未修改，所以该孔与后盖固定柱暂差约 0.499 mm。后盖 STEP/STL、外观样件工程和打样 ZIP 已同步更新；见 `screw3-shift-check.json`。**

主板来源为 `hardware-q2/ProPrj_esp32s31-mp4_2026-09-22.kicad_pcb`，按键板来源为 `hardware-controls/controls.kicad_pcb`。主板 1.6 mm、小板 0.8 mm；两块源 PCB 均未修改。主板以原板框注册到壳体坐标，背面 Z=4.2、正面 Z=5.8 mm；小板背面 Z=11.1、正面 Z=11.9 mm。

## 检查结论：存在装配干涉

| 项目 | 结果 | 依据及影响 |
|---|---|---|
| 马达与耳机座 CN1 | 不通过 | 当前马达中心 (39,62) mm；马达本体重叠 15.9349 mm³，支架重叠 4.1069 mm³。这是上一轮马达移位方案遗漏的主板器件检查。 |
| C13 与屏幕排线 | 不通过 | C13 在主板背面，包络 Z=3.70…4.20 mm；排线局部顶部为 3.76 mm，重叠约 0.06 mm、体积 0.02287 mm³。需调整屏幕排线路径，并留装配余量。 |
| 主板四孔与固定柱 | SCREW3 待 PCB 同步 | 本次仅移动后盖 SCREW3 固定柱及孔；与未改动的主板孔约差 0.499 mm，其余三孔偏差不大于 0.0014 mm。 |
| 主板/小板板体、已建模元件与外壳 | 名义几何通过 | 除上述干涉外，未发现其他被检查对象的非预期相交；不代表未建模器件也通过。 |
| 按键板、行程和 40 mm FFC | 名义几何通过 | 小板器件、轴向行程、四向倾斜及控制 FFC 路线检查通过。排线插入和弯折仍需实物确认。 |
| 两板实体有效性 | 通过 | 本次检查对象没有无效 Shape；129 个主板元件模型之间未发现重叠。 |
| CN2/CN3 电池、马达端子 | 无法确认 | 缺少可靠 3D 模型。均位于主板背面，主板到后盖内底名义高度约 3.1 mm，必须核对端子本体及插头/线束高度。 |

主板 135 个封装中，129 个带名义器件模型；其余是 4 个安装孔和 CN2/CN3。安装孔实际包含在板体中，不需要将它们伪装成器件模型。

## 安装孔核对（壳体坐标 mm）

| 孔 | X | Y | 与现有柱中心偏差 |
|---|---:|---:|---:|
| SCREW5 | 38.1925 | 4.7475 | 0.0014 |
| SCREW2 | 37.4280 | 35.3610 | 0.0010 |
| SCREW3 | 3.5010 | 43.4990 | 0.4990（后盖中心现为 4.0000 / 43.5000） |
| SCREW1 | 44.7000 | 65.4995 | 0.0005 |

## 马达调整候选

另外计算了马达及支架整体平移的候选位置，**尚未改动当前检查装配**，以保留问题现场。壳体中心 **(43,60) mm** 是可继续细化的候选：对现有模型检查无干涉，到耳机座/小板 J1/控制排线的最小间隙约 **0.816 mm**。这只验证名义包络；支架与壳体的连接方式、实际马达公差及引线仍需重新设计，不能直接平移后打印。

## 模型来源与检查范围

最终主板引用的 `EASYEDA_MODELS` 路径缺少对应 STEP 文件。本目录在导出副本中补入 Git 历史保存的同封装名义模型，原 PCB 和用户删除的历史目录均未恢复或覆盖。模型文件及原许可说明在 `models3d/`。

U10 缺少原厂模型，按原引用文件名使用 **7.9×5.3×1.9 mm** 保守矩形包络，包含引脚跨度；不是厂家公差模型。其他同封装模型也只支持名义空间检查。CN2/CN3 无可靠高度，没有虚构“已通过”的模型。

外壳基于 F 版及上一轮按键板适配后的内部修改，包含马达 Y=62 的现状和控制 FFC 后盖局部避让。排线与其插座内部的预期插入区域不算干涉；其他 PCB、元件、屏幕、后盖、马达、电池、按键机构、排线均参加对应检查。电池/马达线束、USB/耳机外部插头的插拔包络、结构强度和制造公差未作完整验证。

## 文件

- `Q2_Final_Mainboard_Assembly.FCStd`：导入两板后的 FreeCAD 检查装配，保留问题位置。
- `assembly-review.png`：两板及外壳内部视图。
- `motor-jack-conflict.png`：马达与耳机座干涉近景，红色为重叠区域。
- `display-flex-conflict.png`：C13 与屏幕排线干涉近景；排线裁剪片段仅用于展示，不是修改后的排线路径。
- `fit-check.json`：完整几何结果、坐标、源文件散列和候选位置检查。
- `mainboard-reference.json`：逐封装模型映射、坐标及缺失项。
- `mainboard-layout-reference.step` / `controls-populated.step`：由对应 PCB 导出的两板 STEP。
- `mainboard-model-reference.kicad_pcb`：仅用于导出模型的副本，不是最终电气工程。

本目录是**装配检查版本，存在已记录干涉**。这里的外壳 STEP/STL 是检查现状的导出，不是修复后的生产文件。重建顺序：`build_u10.py` → `export_mainboard_reference.py` → KiCad CLI 导出两板 STEP → `build_review.py` → `annotate_review.py` → FreeCAD GUI 运行 `prepare_views.py`。`mounting_adjustment.py` 固定应用 SCREW3 的绝对新坐标，重复重建不会累积偏移。单独应用后盖改动用 `shift_screw3.py`，外观包同步用 `../appearance-prototype-v1/update_screw3.py`。不要把本目录导出副本覆盖到用户最终主板工程。

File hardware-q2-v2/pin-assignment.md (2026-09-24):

# V2 实际主控引脚表

从当前 PCB 的 U9 焊盘网络生成；GPIO 与 QFN 物理脚号分别列出。尚未进行固件或上电验证。

| QFN 脚号 | 芯片管脚 | GPIO | 当前网络 |
|---|---|---|---|
| 1 | ANT | — | RF_CHIP |
| 2 | VDDA3 | — | MCU_VDDA34 |
| 3 | VDDA4 | — | MCU_VDDA34 |
| 4 | CHIP_PU | — | CHIP_PU |
| 5 | XTAL_32K_N/GPIO0 | 0 | KEY_POWER_SENSE_N |
| 6 | XTAL_32K_P/GPIO1 | 1 | CTRL_INT_N |
| 7 | GPIO2 | 2 | RTC_INT_N |
| 8 | GPIO3 | 3 | IMU_INT1 |
| 9 | GPIO4 | 4 | BAT_ALERT_N |
| 10 | GPIO5 | 5 | CHG_INT_N |
| 11 | VDDPST_1 | — | VCC_3V3 |
| 12 | GPIO6 | 6 | SYS_I2C_SCL |
| 13 | GPIO7 | 7 | SYS_I2C_SDA |
| 14 | GPIO8 | 8 | NC |
| 15 | GPIO9 | 9 | POWER_OFF_REQ |
| 16 | GPIO10 | 10 | CTRL_RESET_N |
| 17 | GPIO11 | 11 | USB_PATH_SEL |
| 18 | VREF_TOUCH | — | NC |
| 19 | GPIO12 | 12 | MOTOR_EN |
| 20 | GPIO13 | 13 | CHG_OTG_EN |
| 21 | GPIO14 | 14 | AUDIO_I2C_SCL |
| 22 | GPIO15 | 15 | AUDIO_I2C_SDA |
| 23 | GPIO16 | 16 | NC |
| 24 | GPIO17 | 17 | NC |
| 25 | GPIO18 | 18 | NC |
| 26 | GPIO19 | 19 | SD_CARD_DETECT_N |
| 27 | SDIO_DATA0 | 20 | SD_D0 |
| 28 | SDIO_DATA1 | 21 | SD_D1 |
| 29 | SDIO_DATA2 | 22 | SD_D2 |
| 30 | VDD_PSRAM_1P8_1 | — | MCU_1V8 |
| 31 | SDIO_DATA3 | 23 | SD_D3 |
| 32 | SDIO_CLK | 24 | SD_CLK |
| 33 | SDIO_CMD | 25 | SD_CMD |
| 34 | VDD_PSRAM_1P8_2 | — | MCU_1V8 |
| 35 | VDD_LDO_1P8 | — | MCU_1V8 |
| 36 | SPICS | 26 | FLASH_CS_N |
| 37 | SPIQ | 27 | MCU_FLASH_D1 |
| 38 | SPIWP | 28 | MCU_FLASH_D2 |
| 39 | VDD_SPI | — | MCU_VDD_SPI |
| 40 | SPIHD | 30 | MCU_FLASH_D3 |
| 41 | SPICLK | 31 | MCU_FLASH_CLK |
| 42 | SPID | 32 | MCU_FLASH_D0 |
| 43 | VCCA/VDDPST_2 | — | VCC_3V3 |
| 44 | USB_DP | — | MCU_USB_HS_DP |
| 45 | USB_DM | — | MCU_USB_HS_DM |
| 46 | GPIO33 | 33 | USB_DEBUG_DM |
| 47 | GPIO34 | 34 | USB_DEBUG_DP |
| 48 | GPIO35 | 35 | DAC_I2S_DOUT |
| 49 | GPIO36 | 36 | STRAP_FLASH_3V3 |
| 50 | GPIO37 | 37 | STRAP_USB_JTAG |
| 51 | GPIO38 | 38 | DAC_I2S_LRCK |
| 52 | GPIO39 | 39 | DAC_RESET_N |
| 53 | GPIO40 | 40 | DAC_I2S_BCLK |
| 54 | VDDPST_3 | — | VCC_3V3 |
| 55 | GPIO42 | 42 | TP_I2C_SCL |
| 56 | GPIO43 | 43 | TP_I2C_SDA |
| 57 | GPIO44 | 44 | LCD_RESET_N |
| 58 | GPIO45 | 45 | LCD_VCI_EN |
| 59 | GPIO46 | 46 | LCD_TE |
| 60 | GPIO47 | 47 | TP_INT_N |
| 61 | GPIO48 | 48 | TP_RESET_N |
| 62 | GPIO49 | 49 | NC |
| 63 | VREF_ADC | — | NC |
| 64 | VDDPST_4 | — | VCC_3V3 |
| 65 | GPIO50 | 50 | NC |
| 66 | GPIO51 | 51 | NC |
| 67 | GPIO52 | 52 | LCD_CS_N |
| 68 | GPIO53 | 53 | LCD_CLK |
| 69 | MTDO | 54 | LCD_D0 |
| 70 | MTCK | 55 | LCD_D1 |
| 71 | MTDI | 56 | LCD_D3 |
| 72 | MTMS | 57 | LCD_D2 |
| 73 | GPIO58 | 58 | MCU_UART0_TX |
| 74 | GPIO59 | 59 | UART0_RX |
| 75 | GPIO60 | 60 | BOOT_MODE_H |
| 76 | GPIO61 | 61 | BOOT_DOWNLOAD_N |
| 77 | VDDA1 | — | VCC_3V3 |
| 78 | XTAL_N | — | XTAL_N |
| 79 | XTAL_P | — | MCU_XTAL_P |
| 80 | VDDA2 | — | VCC_3V3 |
| 81 | GND | — | GND |

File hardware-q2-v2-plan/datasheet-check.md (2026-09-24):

# ESP32-S31 芯片手册核对 · 布局规划 B

来源：项目根目录 `esp32-s31_datasheet_en.pdf`，Pre-release v0.5 / PRELIMINARY，110页。本文使用实际文件内容，不把它当作已定版的量产规格。

## 已确认的尺寸和型号

手册第16页表1-1列出 ESP32-S31NRV16（16 MB PSRAM）和 ESP32-S31NRV32（32 MB PSRAM）。规划按与原模组PSRAM容量一致的NRV16作为候选，尚未决定采购型号；两者在该表中均为QFN80 8×8 mm。

第104页图7-1：

| 项目 | 尺寸，mm |
|---|---|
| 本体 | 8×8，BSC |
| 引脚间距 | **0.35，BSC** |
| 整体高度 | 最小0.80，典型0.85，最大0.90 |
| 裸露散热焊盘 | 典型6.5×6.5；尺寸范围6.4–6.6 |
| 引脚金属宽度 | 0.12–0.22，典型0.17 |
| 引脚金属长度 | 0.30–0.50，典型0.40 |

以上是器件封装尺寸，**不是PCB推荐焊盘或钢网尺寸**。尤其不可用普通0.4 mm间距QFN80替代。PCB中央焊盘分窗、散热过孔和外周焊盘仍须结合参考设计与贴装工艺设计。

## 更新到规划工程的位置

按KiCad顶视图、板框左上角为原点：

| 对象 | X / Y | 方向及用途 |
|---|---|---|
| 裸芯片本体候选 | **30.00 / 17.00** | **−90°**；绝对坐标158.868 / 84.647 |
| 本体范围 | X26–34、Y13–21 | 8×8的文档层外形，不是电气封装 |
| 配套电路预留 | X21–38、Y8–25 | 需设计分域去耦、复位及匹配等 |
| 晶振及匹配预留 | X35.5–42.5、Y10–15 | 靠旋转后芯片右上侧；最终距离依官方参考设计 |
| U10 Flash候选 | **18.60 / 28.20** | 正面270°；时钟侧朝核心，C13移到22.00 / 24.60靠近8脚 |
| JDISP1 屏幕BTB | **30.00 / 29.20** | 仍为正面候选90°；需实物排线定朝向 |

第17页图2-1给出标准顶视图。以上芯片−90°表示从该图顺时针旋转90°：**芯片1脚角在右上**，与BTB当前1脚左下的描述不是同一个器件。

| 接口组 | 芯片物理引脚 | 候选旋转后的方向 |
|---|---|---|
| ANT | 1 | 上侧靠右，朝RF预留区 |
| SDIO | 27/28/29/31/32/33 | 左侧，朝TF卡；不是旧模组焊盘号 |
| 启动Flash | 36/37/38/40/41/42 | 左下角，横跨左侧下段和底边左段 |
| USB DP/DM | 44/45 | 底边靠左，便于向下布线 |
| 40 MHz XTAL N/P | 78/79 | 右侧靠上 |

这是固定功能引脚与机械位置的协调候选。屏幕QSPI、I²S和其他GPIO已有候选分配，见 `pin-assignment.md`；尚未同步到原理图/PCB，不能声称所有信号已消除交叉。

## 下一版原理图必须补齐的内容

1. 第35页明确要求封装外Flash，最大支持256 MB；NRV16/NRV32后缀指的是PSRAM容量。原U10 W25Q16JV只有16 Mbit，即2 MB。不能自动将它视为原模组16 MB Flash的等效替代，容量与芯片选型仍需决定。
2. 第33–35页分别列出PSRAM、Flash、SD和其他电源域。VDD_PSRAM_1P8_1/2、VDD_LDO_1P8、VDD_SPI不能仅因都叫“电源”就并到3.3 V。按已验证的参考电路安排去耦和供电连接。
3. 第36–38页涉及GPIO36、GPIO37、GPIO60、GPIO61的启动配置。GPIO36涉及Flash电压选择；BOOT和复位电路必须按裸芯片物理引脚重新建立。不要从旧模组引脚编号直接复制。
4. 第104页是封装机械图，没有给出完整推荐land pattern。此版本仅在文档层添加本体轮廓，并在FreeCAD增加8×8×0.9 mm占位，未生成80个未验证的铜焊盘，也未建立裸芯片网络。

当前仍是布局规划。新外形占位可用于装配空间检查，但不代表配套器件、射频天线或屏幕原生排线已经完成设计。

检查中同时修正了原U10占位STEP与封装引脚跨距方向相差90°的问题，KiCad模型旋转和FreeCAD装配已同步。模型仍为名义外形，并非完整厂家模型。

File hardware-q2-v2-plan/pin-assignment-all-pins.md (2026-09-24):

# 第二版引脚分配完整表

候选方案：ESP32-S31NRV16；KiCad −90°。GPIO编号与QFN物理脚号分别列出。尚未写入原理图/PCB。

| 物理脚 | 芯片脚名 | GPIO | 功能分组 | 建议网络名 | 旧网络 | 目标 |
|---:|---|---:|---|---|---|---|
| 1 | ANT | — | 射频 | ANT |  | RF匹配/天线 |
| 2 | VDDA3 | — | 电源 | 3V3_VDDA3 |  | 3.3V域，局部滤波/去耦 |
| 3 | VDDA4 | — | 电源 | 3V3_VDDA4 |  | 3.3V域，局部滤波/去耦 |
| 4 | CHIP_PU | — | 复位 | CHIP_PU | ESP32S31_EN | RC及CH343下载控制电路 |
| 5 | XTAL_32K_N/GPIO0 | 0 | 唤醒/中断 | KEY_POWER_SENSE_N | ESP_IO42 | FPC1.11 / U6.1，经3.3V隔离检测 |
| 6 | XTAL_32K_P/GPIO1 | 1 | 唤醒/中断 | CTRL_INT_N | ESP_IO43 | FPC1.5 |
| 7 | GPIO2 | 2 | 唤醒/中断 | RTC_INT_N | ESP_IO34 | U1.6 |
| 8 | GPIO3 | 3 | 唤醒/中断 | IMU_INT1 | ESP_IO1 | U15.4 |
| 9 | GPIO4 | 4 | 唤醒/中断 | BAT_ALERT_N | ESP_IO35 | U14.1 |
| 10 | GPIO5 | 5 | 唤醒/中断 | CHG_INT_N | BQ25895_INT | U3.7 |
| 11 | VDDPST_1 | — | 电源 | 3V3_VDDPST_1 |  | 3.3V域，局部滤波/去耦 |
| 12 | GPIO6 | 6 | 系统LP I2C | SYS_I2C_SCL | BQ25895_I2C_CLK | U3.5 U14.3 U1.2 U11.2 FPC1.4 |
| 13 | GPIO7 | 7 | 系统LP I2C | SYS_I2C_SDA | BQ25895_I2C_SDA | U3.6 U14.2 U1.3 U11.3 FPC1.3 |
| 14 | GPIO8 | 8 | 空闲GPIO | SPARE_GPIO8 |  |  |
| 15 | GPIO9 | 9 | 系统控制 | POWER_OFF_REQ | GEK100_RST | U6.3，经断电防反灌电路 |
| 16 | GPIO10 | 10 | 系统控制 | CTRL_RESET_N | ESP_IO44 | FPC1.6 |
| 17 | GPIO11 | 11 | 系统控制 | USB_PATH_SEL | ESP_IO33 | U17.2 |
| 18 | VREF_TOUCH | — | 模拟预留 | NC_VREF_TOUCH |  | 本方案不用触摸/ADC则按手册处理 |
| 19 | GPIO12 | 12 | 系统控制 | MOTOR_EN | ESP_IO40 | U11.5 |
| 20 | GPIO13 | 13 | 系统控制 | CHG_OTG_EN | BQ25895_OTG_EN | U3.8 |
| 21 | GPIO14 | 14 | 音频HP I2C0 | AUDIO_I2C_SCL | DAC_I2C_SCL | U7.6 U15.13 |
| 22 | GPIO15 | 15 | 音频HP I2C0 | AUDIO_I2C_SDA | DAC_I2C_SDA | U7.5 U15.14 |
| 23 | GPIO16 | 16 | 空闲GPIO | SPARE_GPIO16 |  |  |
| 24 | GPIO17 | 17 | 空闲GPIO | SPARE_GPIO17 |  |  |
| 25 | GPIO18 | 18 | 空闲GPIO | SPARE_GPIO18 |  |  |
| 26 | GPIO19 | 19 | 系统控制 | SD_CARD_DETECT_N | ESP_IO19 | CARD2.CD |
| 27 | SDIO_DATA0 | 20 | SDMMC | SD_D0 | ESP_TF_DAT0 | CARD2.7 |
| 28 | SDIO_DATA1 | 21 | SDMMC | SD_D1 | ESP_TF_DAT1 | CARD2.8 |
| 29 | SDIO_DATA2 | 22 | SDMMC | SD_D2 | ESP_TF_DAT2 | CARD2.1 |
| 30 | VDD_PSRAM_1P8_1 | — | 电源 | VDD_PSRAM_1P8_1 |  | VDD_LDO_1P8，按参考电路 |
| 31 | SDIO_DATA3 | 23 | SDMMC | SD_D3 | ESP_TF_DAT3 | CARD2.2 |
| 32 | SDIO_CLK | 24 | SDMMC | SD_CLK | ESP_TF_CLK | CARD2.5 |
| 33 | SDIO_CMD | 25 | SDMMC | SD_CMD | ESP_TF_CMD | CARD2.3 |
| 34 | VDD_PSRAM_1P8_2 | — | 电源 | VDD_PSRAM_1P8_2 |  | VDD_LDO_1P8，按参考电路 |
| 35 | VDD_LDO_1P8 | — | 电源 | VDD_LDO_1P8 |  | PSRAM 1.8V供电和去耦 |
| 36 | SPICS | 26 | 启动Flash | FLASH_CS_N | ESP_FLASH_CS | U10.1 |
| 37 | SPIQ | 27 | 启动Flash | FLASH_D1 | ESP_FLASH_DO | U10.2 |
| 38 | SPIWP | 28 | 启动Flash | FLASH_D2 | ESP_FLASH_WP | U10.3 |
| 39 | VDD_SPI | — | 电源 | VDD_SPI |  | 外接Flash供电/去耦 |
| 40 | SPIHD | 30 | 启动Flash | FLASH_D3 | ESP_FLASH_HOLD | U10.7 |
| 41 | SPICLK | 31 | 启动Flash | FLASH_CLK | ESP_FLASH_CLK | U10.6 |
| 42 | SPID | 32 | 启动Flash | FLASH_D0 | ESP_FLASH_DI | U10.5 |
| 43 | VCCA/VDDPST_2 | — | 电源 | 3V3_VCCA/VDDPST_2 |  | 3.3V域，局部滤波/去耦 |
| 44 | USB_DP | — | USB HS | USB_HS_DP | ESP_USB_DP | U17.7 |
| 45 | USB_DM | — | USB HS | USB_HS_DM | ESP_USB_DN | U17.6 |
| 46 | GPIO33 | 33 | 调试预留 | USB_DEBUG_DM |  | 新增调试焊盘/连接器 |
| 47 | GPIO34 | 34 | 调试预留 | USB_DEBUG_DP |  | 新增调试焊盘/连接器 |
| 48 | GPIO35 | 35 | 音频I2S | DAC_I2S_DOUT | DAC_I2S_SDIN | U8.2 |
| 49 | GPIO36 | 36 | 启动配置 | STRAP_FLASH_3V3 |  | 启动上拉/下载电路 |
| 50 | GPIO37 | 37 | 启动配置 | STRAP_USB_JTAG |  | 启动上拉/下载电路 |
| 51 | GPIO38 | 38 | 音频I2S | DAC_I2S_LRCK | DAC_I2S_LRCK | U8.5 |
| 52 | GPIO39 | 39 | 音频I2S | DAC_RESET_N | DAC_RST# | U8.12 |
| 53 | GPIO40 | 40 | 音频I2S | DAC_I2S_BCLK | DAC_I2S_SCLK | U8.9 |
| 54 | VDDPST_3 | — | 电源 | 3V3_VDDPST_3 |  | 3.3V域，局部滤波/去耦 |
| 55 | GPIO42 | 42 | 触屏HP I2C1 | TP_I2C_SCL | ESP_I2C2_SCL | JDISP1.20 |
| 56 | GPIO43 | 43 | 触屏HP I2C1 | TP_I2C_SDA | ESP_I2C2_SDA | JDISP1.19 |
| 57 | GPIO44 | 44 | 屏幕控制 | LCD_RESET_N | ESP_IO47 | JDISP1.1 |
| 58 | GPIO45 | 45 | 屏幕控制 | LCD_VCI_EN | ESP_IO46 | JDISP1.24 |
| 59 | GPIO46 | 46 | 屏幕控制 | LCD_TE | AM213_TE_RESERVED | JDISP1.3 |
| 60 | GPIO47 | 47 | 屏幕控制 | TP_INT_N | ESP_IO54 | JDISP1.17 |
| 61 | GPIO48 | 48 | 屏幕控制 | TP_RESET_N | ESP_IO57 | JDISP1.18 |
| 62 | GPIO49 | 49 | 空闲GPIO | SPARE_GPIO49 |  |  |
| 63 | VREF_ADC | — | 模拟预留 | NC_VREF_ADC |  | 本方案不用触摸/ADC则按手册处理 |
| 64 | VDDPST_4 | — | 电源 | 3V3_VDDPST_4 |  | 3.3V域，局部滤波/去耦 |
| 65 | GPIO50 | 50 | 空闲GPIO | SPARE_GPIO50 |  |  |
| 66 | GPIO51 | 51 | 空闲GPIO | SPARE_GPIO51 |  |  |
| 67 | GPIO52 | 52 | 屏幕QSPI | LCD_CS_N | ESP_SPI2_CS | JDISP1.4 |
| 68 | GPIO53 | 53 | 屏幕QSPI | LCD_CLK | ESP_SPI2_CLK | JDISP1.5 |
| 69 | MTDO | 54 | 屏幕QSPI | LCD_D0 | ESP_SPI2_D0 | JDISP1.7 |
| 70 | MTCK | 55 | 屏幕QSPI | LCD_D1 | ESP_SPI2_D1 | JDISP1.6 |
| 71 | MTDI | 56 | 屏幕QSPI | LCD_D3 | ESP_SPI2_D3 | JDISP1.22 |
| 72 | MTMS | 57 | 屏幕QSPI | LCD_D2 | ESP_SPI2_D2 | JDISP1.23 |
| 73 | GPIO58 | 58 | 下载UART0 | UART0_TX | CH343P_UART_RX | U12.5 RXD |
| 74 | GPIO59 | 59 | 下载UART0 | UART0_RX | CH343P_UART_TX | U12.4 TXD |
| 75 | GPIO60 | 60 | 启动配置 | BOOT_MODE_H | ESP_BOOT2 | 启动上拉/下载电路 |
| 76 | GPIO61 | 61 | 启动配置 | BOOT_DOWNLOAD_N | ESP_BOOT1 | 启动上拉/下载电路 |
| 77 | VDDA1 | — | 电源 | 3V3_VDDA1 |  | 3.3V域，局部滤波/去耦 |
| 78 | XTAL_N | — | 晶振 | XTAL_N |  | 40MHz晶振/匹配 |
| 79 | XTAL_P | — | 晶振 | XTAL_P |  | 40MHz晶振/匹配 |
| 80 | VDDA2 | — | 电源 | 3V3_VDDA2 |  | 3.3V域，局部滤波/去耦 |
| 81 | GND | — | 地 | GND_EP |  | 连续GND/散热过孔 |

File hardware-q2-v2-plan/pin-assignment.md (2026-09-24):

# Q2第二版引脚规划 A · 2026-09-24

按当前裸芯片候选位置 `(30,17) mm / −90° / 正面` 分配，优先固定高速接口、启动配置和唤醒，再安排低速控制。对象为ESP32-S31NRV16，参考本地手册v0.5。**这是原理图设计输入，尚未把这些新GPIO写入原理图或PCB；旧板网络名不能代表新GPIO号。**

## 推荐分配

下表GPIO栏是软件GPIO编号。完整81脚表另列QFN物理脚号、电源、启动电平、旧网络、目标器件和连接注意事项。

| 功能 | GPIO分配 | QFN物理脚 |
|---|---|---|
| 启动Flash CS/D1/D2/D3/CLK/D0 | 26 / 27 / 28 / 30 / 31 / 32 | 36 / 37 / 38 / 40 / 41 / 42 |
| TF D0/D1/D2/D3/CLK/CMD | 20 / 21 / 22 / 23 / 24 / 25 | 27 / 28 / 29 / 31 / 32 / 33 |
| TF卡检测 | 19 | 26 |
| 屏幕CS/CLK/D0/D1/D2/D3 | **52 / 53 / 54 / 55 / 57 / 56** | 67 / 68 / 69 / 70 / 72 / 71 |
| 屏幕RST_N / VCI_EN / TE | 44 / 45 / 46 | 57 / 58 / 59 |
| 触屏SCL / SDA / INT_N / RST_N | 42 / 43 / 47 / 48 | 55 / 56 / 60 / 61 |
| 音频BCLK / LRCK / ESP_DOUT / RST_N | **40 / 38 / 35 / 39** | 53 / 51 / 48 / 52 |
| DAC＋IMU I²C：SCL/SDA | 14 / 15 | 21 / 22 |
| 系统LP I²C：SCL/SDA | **6 / 7** | 12 / 13 |
| POWER独立检测 / 按键板INT_N / RTC_INT_N | **0 / 1 / 2** | 5 / 6 / 7 |
| IMU_INT1 / 电量计ALERT_N / 充电INT_N | 3 / 4 / 5 | 8 / 9 / 10 |
| 按键板RESET_N | 10 | 16 |
| USB切换SEL / 马达EN / OTG_EN | 11 / 12 / 13 | 17 / 19 / 20 |
| 软件关机请求 | 9 | 15 |
| UART0 TX / RX | 58 / 59 | 73 / 74 |
| USB Serial/JTAG D− / D+预留 | 33 / 34 | 46 / 47 |
| USB HS D+ / D− | **专用脚，不是GPIO44/45** | **44 / 45** |

另有GPIO8、16、17、18、49、50、51共 **7个普通GPIO空闲**。GPIO36、37、60、61专门留给启动配置，不计入可随意使用的空闲脚。GPIO29、GPIO41没有对应的封装GPIO引出，不能按连续序号补进去。

## 为什么这样分配

- Flash和TF使用固定接口，分别从芯片左下和左侧出线。U10在芯片左下；保留物理焊盘对应关系，但正式启动Flash容量仍待选，原W25Q16JV只有2 MB。
- 屏幕QSPI使用手册第24页的SPI2 F2功能组，位于旋转后芯片右侧。**D2是GPIO57、D3是GPIO56，不能按数字递增接反。** GPIO54–57同时是传统JTAG脚，本方案将它们用于屏幕。
- I²S从芯片底部输出，朝下方U8/DAC；保持四路1.8 V电平转换。`DAC_I2S_SDIN`是以DAC为视角命名的旧网，新名称为`DAC_I2S_DOUT`，方向是ESP输出。DAC保留本地X1时钟，本方案不新增MCU MCLK。
- POWER、按键INT、RTC中断分配到LP GPIO0–2。ESP32-S31的GPIO0不是本芯片BOOT脚；它与GPIO1在本方案中也不再接外部32.768 kHz晶振。低功耗唤醒仍要配置固件，并保持相应电源域供电；整机断电时依赖GEK硬件开机，不依赖ESP GPIO唤醒。
- 主板原GPIO33接USB切换、GPIO34接RTC中断，会占用芯片默认USB Serial/JTAG功能。这版迁出两项功能，保留这对调试信号。

## 三组I²C的实现选择

| 总线资源 | SCL / SDA | 现有网络和器件 | 初始速率建议 |
|---|---|---|---|
| HP I²C0 | GPIO14 / 15 | DAC_I2C：U7→DAC，U15 IMU | 100 kHz，验证后400 kHz |
| HP I²C1 | GPIO42 / 43 | 原ESP_I2C2：屏幕触控 | 100 kHz，按屏幕触控规格调整 |
| **LP I²C** | GPIO6 / 7 | 原BQ25895_I2C：充电U3、电量计U14、RTCU1、马达U11、CH32按键板FPC1 | **100 kHz** |

芯片有2路HP I²C和1路LP I²C，**不能在普通I²C驱动里创建虚构的`I2C_NUM_2`来使用第三路**。系统总线需要LP驱动/LP核程序，主CPU通过请求队列或共享内存协调，不能两个核同时驱动同一总线。GPIO6/7也不能同时用于LP UART。

这样保留了原三组网络，不需要先假设屏幕触控的I²C地址，也不需要把不同总线的上拉直接并接。CH32小板规划地址0x1C，协议尚须固件实现；系统其他器件地址仍以实际型号核对。上拉总值、并联上拉及总线电容需在原理图阶段检查。

若后续决定不编写LP核固件，可在确认屏幕触控地址、电平、供电和上拉后，把触屏并入系统HP总线，以2路HP实现；**那是另一版总线拓扑，不是这份分配表的既成连接。**

## 屏幕接口对照

| BTB脚 | 信号 | MCU GPIO |
|---:|---|---:|
| 1 | LCD_RESET_N | 44 |
| 3 | TE | 46 |
| 4 | CS_N | 52 |
| 5 | CLK | 53 |
| 6 | D1 | 55 |
| 7 | D0 | 54 |
| 17 | TP_INT_N | 47 |
| 18 | TP_RESET_N | 48 |
| 19 | TP_SDA | 43 |
| 20 | TP_SCL | 42 |
| 22 | D3 | 56 |
| 23 | D2 | 57 |
| 24 | VCI_EN | 45 |

2/8/13/14/21及固定焊盘接GND，9/10 NC；11/12/15/16按此前商定的3.3 V方案供电。此表保持BTB电气脚号，连接器90°或270°仍由屏幕排线实物决定，不能靠旋转封装交换信号编号。

手册列出了这组SPI2复用，但当前ESP-IDF S31在线SPI驱动文档的IOMUX表仍显示N/A。因此这里只确认**芯片有此复用候选**，不宣称当前SDK自动走原生IOMUX或可直接跑80 MHz。先用GPIO Matrix、20 MHz起步，40 MHz以内调通；进一步提速必须检查实际SDK引脚路由、显示驱动和示波器时序。[ESP-IDF SPI Master说明](https://docs.espressif.com/projects/esp-idf/en/latest/esp32s31/api-reference/peripherals/spi_master.html)

## 按键FPC保持原针序

FPC1：1=GND，2=3.3V，3=GPIO7/SDA，4=GPIO6/SCL，5=GPIO1/INT_N，6=GPIO10/RESET_N，7–10=NC，11=POWER机械按键信号，12=GND，13/14固定焊盘=GND。POWER继续按下拉低，其他按键和滑环通过CH32＋I²C读取。

**第11脚不能未经电源域处理直接接GPIO0。** 现有U6 GEK100由VCC供电，其KEY内部上拉到自身电源；同时小板R14上拉到小板3.3V。VCC可能高于3.3V，关机时小板3.3V还可能断电。因此原来的共网直连关系需要在第二版加入隔离/合适的常供电与检测电路，避免ESP过压、通过小板上拉回灌或KEY不能释放。GPIO0分配给处理后的`KEY_POWER_SENSE_N`，不是声明原网已经可以安全直连。

GPIO9为新增软件关机请求，目标为GEK的RST（高有效）。上电默认低；关机前先停音频、保存状态/卸载TF，再发请求。GEK厂家说明RST需要持续足够时间，高电平触发；掉电后的保持时间、防反灌和默认下拉需由电路保证。GPIO9不是直接驱动3.3V稳压器的EN。[GEK100厂家手册](https://gsctek.com/uploads/allimg/20251225/1-251225110HM63.pdf)

## 启动、调试和电源约束

| 项目 | 分配与默认状态 |
|---|---|
| GPIO36 / QFN49 | 候选10k上拉3.3V，配合默认eFuse选择3.3V Flash；不接普通外设 |
| GPIO37 / QFN50 | 候选10k上拉3.3V，避免悬空；参与JTAG源选择，不为本设计烧eFuse |
| GPIO60 / QFN75 | 候选10k上拉；下载时必须为高 |
| GPIO61 / QFN76 | BOOT：正常上拉，进入下载时拉低 |
| CHIP_PU / QFN4 | EN/复位RC；与CH343下载控制电路联动 |
| UART0 GPIO58 TX | 接CH343 RXD/U12.5，旧网名CH343P_UART_RX |
| UART0 GPIO59 RX | 接CH343 TXD/U12.4，旧网名CH343P_UART_TX |

GPIO61低且GPIO60低是无效启动组合。自动下载电路要按裸芯片参考电路重新核对，不能仅搬运旧模组焊盘编号。

GPIO33/34保留给USB Serial/JTAG；它们不与当前USB-C上的HS D+/D−并接。若要使用，需后续设计独立调试接点/选路。传统四线JTAG被屏幕占用，UART0作为基础恢复下载路径。

VDD_PSRAM_1P8_1/2（QFN30/34）、VDD_LDO_1P8（35）、VDD_SPI（39）、各VDDA/VDDPST及EP81都已列入完整表；它们不能分配普通GPIO。未启用片内ADC和触摸时，VREF_ADC/VREF_TOUCH按手册处理，不因原理图空白就接3.3V。

## 交付与校验

- `pin-assignment-all-pins.md`：全部81个物理引脚的可读表。
- `pin-assignment.csv`：UTF-8 BOM表格，可导入Excel。
- `pin-assignment.json`：机器可读映射及校验结果。
- `q2_v2_pin_plan.h`：固件引脚常量草案；没有初始化驱动，不表示固件已支持/测试。
- `pin-assignment-overview.png`：−90°顶视分配图；端子位置为说明示意，不是PCB焊盘图。

校验覆盖：81个物理脚、60个GPIO无重复分配；启动脚未被普通功能占用；原U9所有非电源网络都被分配或明确列为删除/空闲；三路I²C控制器资源分别明确。没有修改PCB、原理图和已生产的小板。

资料：本地`esp32-s31_datasheet_en.pdf`第17–26、29–40、68–69页；[ESP-IDF GPIO说明](https://docs.espressif.com/projects/esp-idf/en/latest/esp32s31/api-reference/peripherals/gpio.html)；[LP核及LP I²C接口](https://docs.espressif.com/projects/esp-idf/en/latest/esp32s31/api-reference/system/ulp-lp-core.html)。芯片手册为预发布版本，最终电路和SDK实现还需联调。

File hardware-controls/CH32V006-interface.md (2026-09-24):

# CH32V006 小板 C 版接口与固件要求

本文件定义待实现的固件接口，不表示固件已经烧录、实测或兼容旧 AT42QT2120。当前任务交付硬件迁移；板上 MCU 必须有配套固件才能通过 I²C 读取滑环和四个按键。

## 硬件

U1 为 **CH32V006F8U6，QFN20，3 × 3 mm，0.4 mm 脚距，裸露焊盘 1.9 × 1.9 mm**。不要把 TSSOP20 的 CH32V006F8P6 装到此封装。U1 中央焊盘编号为 0，连接 GND。

| 功能 | MCU 管脚 | 封装脚号 |
|---|---|---|
| 滑环电极 0 / 1 / 2 | PD2/TKEY3、PD3/TKEY4、PD4/TKEY7 | 16、17、18 |
| SDA / SCL | PC1、PC2，默认 I²C 映射 | 8、9 |
| INT_N | PC0，固件配置开漏输出 | 7 |
| BACK / PREV / NEXT / PLAY | PC3、PC5、PC6、PC7 | 10、12、13、14 |
| 硬件 RESET_N | PD7/RST | 1 |
| 单线 SDI 编程 | PD1/SWIO | 15 |
| 电源 / 地 | VDD / VSS / EP | 6 / 4 / 0 |

POWER 不连接 MCU，SW1 按下将 KEY_POWER 接地，R14=10 kΩ 上拉到小板 +3V3。其他四键各有 47 kΩ 外部上拉，按下为低电平。若主板切断小板 +3V3，POWER 的板载上拉也失电；关机唤醒是否有保持供电或主板上拉，需由主板电源策略保证。

J1 的位置、朝向和针序保持原样：1=GND、2=+3V3、3=SDA、4=SCL、5=INT_N、6=RESET_N、7～10=NC、11=KEY_POWER、12=GND；13、14 为接地固定焊盘。本次没有改变 FFC 的同面/异面要求，也没有重新验证主板装配。

R8 改为 **0 Ω**，不能继续装旧版 22 Ω；C1=100 nF、C2=1 µF。R1～R3 暂定 1 kΩ，需要结合触摸充放电时间及实测信噪比调参。R7=10 kΩ 与 C3=100 nF 构成 RESET_N 的 RC。

## 烧录

背面 J2 是四个裸铜焊盘，不装排针，不占用 FPC 信号：1=VDD_MCU/3.3 V 电压参考、2=SWIO、3=GND、4=RESET_N。使用支持 CH32V006 的 WCH-Link 单线 SDI 模式；不要把 SWIO 当成标准双线 SWD。

J2 丝印圆点标记 1 脚。按 KiCad 背面视图、板顶朝上查看，四个焊盘的上排从左到右为 4 RESET、3 GND，下排为 2 SWIO、1 VREF；仍应以焊盘编号及万用表通断确认接线。

- 使用 3.3 V 电平；主板供电与下载器供电二选一，避免两个电源互相回灌。
- 保留 PD1 的 SDI 调试功能，**不要照搬官方触摸演示中关闭 SDI 的语句**。
- PD7 要通过芯片配置字节启用硬件复位；WCH 库提供 `OB_RST_EN_DT128us`、`OB_RST_EN_DT1ms` 等设置。应在下载工具中核对并配置，不能只把 GPIO 命名为 RESET。
- 烧录后确认按住 J1.6 能持续复位、释放后正常启动，并确认 SWIO 仍可重新下载。

## 拟定 I²C 协议 v1

7 位地址 **0x1C**，初期 100 kHz。复用旧触摸器件的总线地址只是减少主控配置变化，**寄存器不兼容 AT42QT2120**；原 TCA6408A 地址 0x20 不再存在。

普通读采用写入 1 字节寄存器指针、Repeated START、连续读取；连续读自动递增，不回绕。STOP 和短读不确认事件。越界读取返回 0，越界或只读寄存器写入忽略。每次读事务锁定一份完整快照，避免位置、按键和事件序号来自不同采样帧。

| 寄存器 | 字节数 | 定义 |
|---|---:|---|
| 0x00 | 1 | 设备标识 0xC6 |
| 0x01 | 1 | 协议版本 0x01 |
| 0x02 | 1 | 状态：bit0=触摸有效，bit1=校准中，bit2=触摸故障；其余 0 |
| 0x03 | 1 | 消抖后的键位：bit0 BACK、bit1 PREV、bit2 NEXT、bit3 PLAY；1=按下 |
| 0x04 | 2 | 滑环位置 0～359，小端；无触摸为 0xFFFF |
| 0x06 | 4 | 事件序号，小端；任何已发布状态变化递增，复位清零 |
| 0x0A | 2 | 保留，返回 0 |
| 0x10 | 6 | 三路经过滤波的触摸差分值，每路 uint16，小端，供校准诊断 |
| 0x20 | 4 | 只写 ACK_SEQ；仅完整收到 4 字节并与当前事件序号相等时确认 |

PC0 以开漏方式拉低 INT_N 表示有未确认变化。事件在读取期间更新时，主控写入旧序号不得清除新事件；主控需再读快照。初次启动和复位后也产生一次状态通知。ACK_SEQ 的四个数据字节必须在一次写事务完成；STOP 或新地址周期中断不完整写入时丢弃它。固件内部应以临界区处理“比较序号—清除中断”，防止竞态。

主控先读取标识/版本，再读 0x02～0x09 的 8 字节快照，处理状态，最后把快照中的序号写入 0x20。不通过 I²C 读取 POWER；POWER 仍用主控独立 GPIO。

## 触摸与按键软件

本机 MounRiver 附带 CH32V006F8U 的官方 TouchKey 示例。它包含 `TKYLIB/Touch.c` 的滑轮插值，以及 `touch_GetWheelSliderData()` 接口。官方资源：[WCH SDK](https://github.com/openwch/ch32v002_004_005_006_007)。SDK 授权和版权说明需随移植代码保留。

- 仅启用采样队列 0、1、2，分别对应硬件 TKEY3、TKEY4、TKEY7；不得把队列序号直接当成硬件通道号。
- 三电极先单独读取原始值，确认每个电极的实际位置及顺序，再标定零位、旋转方向和 359°→0° 连续性。
- 官方按键演示的 LED 引脚、SDI 关闭代码及默认八通道配置不适用本板；不要原样烧录演示二进制。
- 四个机械键独立做约 10～20 ms 消抖，支持同时按下；具体时间为起始建议。
- 接收/发送 I²C 中断与触摸采样协调，不能在关闭中断的长循环中扫描，避免总线超时。
- 上电基线校准期间仍需回应设备标识、键位与“校准中”状态；此时位置返回 0xFFFF。
- 滑轮算法的中间乘法使用足够宽的整数并检查除零；对三路同时触摸、噪声及无触摸设置阈值和迟滞。

实物验证需覆盖：最终盖板厚度、湿手、充电与音频播放干扰、快速旋转/反向、按键同时按下、休眠唤醒、长时间无触摸基线漂移和待机电流。硬件 ERC/DRC 通过不能替代这些测试。

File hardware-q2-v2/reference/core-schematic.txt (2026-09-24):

5
5
4
4
3
3
2
2
1
1
D
D
C
C
B
B
A
A
Hardware Block:
RF Matching
Antenna
ESP32-S31NR16V
IN
OUT
40MHz
XTAL
GPIOs
GND
VDD33
EN
QSPI FLASH
SPICS0
SPICLK
SPIQ
VDD_SPI
SPID
SPIHD
SPIWP
  QSPI PSRAM
  (Built-in)
Title
Size
Page Name
Rev
Date:
Sheet
o f
Confidential and Proprietary
ESP32-S31-WROOM-3
B
1
2
1.2
<01_Block_Diagram>
Friday, August 14, 2026
Title
Size
Page Name
Rev
Date:
Sheet
o f
Confidential and Proprietary
ESP32-S31-WROOM-3
B
1
2
1.2
<01_Block_Diagram>
Friday, August 14, 2026
Title
Size
Page Name
Rev
Date:
Sheet
o f
Confidential and Proprietary
ESP32-S31-WROOM-3
B
1
2
1.2
<01_Block_Diagram>
Friday, August 14, 2026
5
5
4
4
3
3
2
2
1
1
D
D
C
C
B
B
A
A
The values of C3, L1, C4, C7, L2, C8, L5 and C9
vary with the actual PCB board.
Single-ended 50ohm
QFN80
1: 3.3V flash;
0: 1.8V flash;
The values of C1 and C2 vary with
the selection of the crystal.
The value of L3 varies with the
actual PCB board. L3 must be an inductor.
The initial value is suggested to be 24 nH.
NC: No component.
IO6
IO7
IO8
IO9
IO10
IO11
IO12
IO35
IO13
IO37
IO38
IO39
IO40
IO42
IO43
IO44
IO45
IO46
IO47
ANT
IO48
IO49
VREF_TOUCH
IO36
VREF_ADC
TX0
RX0
IO34
IO33
USB_DP
USB_DM
IO61
IO60
IO53
IO52
IO51
IO50
XTAL_N
XTAL_P
SD_D2
SD_D3
SD_CLK
SD_CMD
IO14
IO15
IO16
IO17
IO18
IO19
SD_D0
SD_D1
EN
IO57
IO56
IO55
IO54
IO0
IO1
IO2
IO3
IO4
IO5
SPICS
SPID
SPICLK
SPIHD
SPIWP
SPIQ
RF
SPICLK
SPICS
SPIHD
SPID
SPIWP
SPIQ
RF1
RF_ANT
VDD33
VDD33
GND
GND
GND
GND
GND
GND
VDD33
VDD33
GND
GND
GND
GND
GND
VDD33
GND
GND
GND
GND
GND
GND
GND
VDD33
GND
GND
VDD33
VDD_SPI
GND
GND
GND
VDD_LDO_1P8
VDD_PSRAM_1P8
GND
GND
VDD_SPI
GND
GND
GND
GND
GND
GND
GND
VDD33
GND
Title
Size
Page Name
Rev
Date:
Sheet
o f
Confidential and Proprietary
ESP32-S31-WROOM-3
C
2
2
1.2
<02_ESP32-S31-WROOM-3>
Friday, August 14, 2026
Title
Size
Page Name
Rev
Date:
Sheet
o f
Confidential and Proprietary
ESP32-S31-WROOM-3
C
2
2
1.2
<02_ESP32-S31-WROOM-3>
Friday, August 14, 2026
Title
Size
Page Name
Rev
Date:
Sheet
o f
Confidential and Proprietary
ESP32-S31-WROOM-3
C
2
2
1.2
<02_ESP32-S31-WROOM-3>
Friday, August 14, 2026
C13
1uF
C12
0.1uF
R6
499
R5
0
C22
0.1uF
C9
TBD
U1
ESP32-S31
ANT
1
GPIO17
24
GPIO18
25
XTAL_32K_P/GPIO1
6
GPIO4
9
GPIO3
8
GPIO2
7
VDDA4
3
GPIO48
61
SDIO_DATA2
29
SPICLK
41
SPID
42
GPIO50
65
XTAL_N
78
XTAL_P
79
GND
81
VDD_LDO_1P8
35
GPIO49
62
VDDA3
2
CHIP_PU
4
XTAL_32K_N/GPIO0
5
GPIO5
10
GPIO6
12
GPIO7
13
GPIO8
14
GPIO14
21
GPIO15
22
GPIO16
23
SDIO_DATA0
27
SDIO_DATA1
28
GPIO33
46
GPIO34
47
GPIO37
50
GPIO38
51
GPIO51
66
MTDO
69
VDDA1
77
VDDPST_1
11
GPIO9
15
VREF_TOUCH
18
GPIO10
16
GPIO11
17
GPIO12
19
GPIO13
20
GPIO19
26
VDD_PSRAM_1P8_1
30
SDIO_DATA3
31
SDIO_CLK
32
SDIO_CMD
33
VDD_PSRAM_1P8_2
34
SPICS
36
SPIQ
37
SPIWP
38
VDD_SPI
39
SPIHD
40
VCCA/VDDPST_2
43
USB_DP
44
USB_DM
45
GPIO35
48
GPIO36
49
GPIO39
52
GPIO40
53
VDDPST_3
54
GPIO42
55
GPIO43
56
GPIO44
57
GPIO45
58
GPIO46
59
GPIO47
60
VREF_ADC
63
VDDPST_4
64
GPIO52
67
GPIO53
68
MTCK
70
MTDI
71
MTMS
72
U0TXD
73
U0RXD
74
GPIO60
75
GPIO61
76
VDDA2
80
C21
1uF
R7
10K(NC)
C15
10uF
C17
0.1uF
C2
TBD
C25
0.1uF
C8
TBD
R1
0
C7
TBD
R2
0
R9
0
R3
0
C14
0.1uF
C6
10nF
C24
0.1uF
D1
ESD
L2
TBD
C3
TBD
U2
FLASH
VDD
8
GND
4
/CS
1
CLK
6
/HOLD
7
/WP
3
DO
2
DI
5
EPAD
9
R11
10K(NC)
Y1
40MHz(±10ppm)
XIN
1
GND
2
XOUT
3
GND
4
C20
0.1uF
R10
10K
C16
1uF
L4
2.0nH
L5
TBD
R8
0
C1
TBD
R4
0
C18
0.1uF
L1
TBD
ANT1
1
2
C23
0.1uF
C19
0.1uF
C5
1uF
C4
TBD
C11
0.47uF
L3
TBD
C10
10uF/6.3V(NC)

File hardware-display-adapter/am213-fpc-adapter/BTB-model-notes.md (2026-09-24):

# OK-23GF024-04 模型与编号

依据屏厂附带 OCN 原图 `../reference/osptek-official/OK-23GF024-04.pdf` 第 3 页。STEP 为重建简化模型，内部槽口和触点不作为插合精度依据。

| 项目 | mm |
|---|---:|
| 长度 | 7.32±0.20 |
| 塑壳宽度 / 总体宽度 | 2.54±0.20 / 2.59±0.20 |
| 母座高度 | 0.79±0.10 |
| 同排间距 / 首末中心跨度 | 0.40 / 4.40 |

对应屏幕 OK-23GM024-04 公座。0.8H 是插合高度等级，不是两只座独立高度相加。

编号已由屏厂 AM213 实板照片核对：KiCad 元件面顶视图、长轴 Y，**1 左上、12 左下、13 右下、24 右上**。信号焊盘按厂家图使用 0.50×0.23 mm，两排中心距 2.40 mm，同排间距 0.40 mm；采购批次仍应核对。

最新中心：KiCad (53,62)，板框局部 **(3,12)**，装配底面 **(32,20,10.1)**。STEP 原点为母座底面中心、Z 向上。

最大包络 2.79×7.52×0.89 mm 顶面 Z10.99，距屏幕后部预留下平面 Z11.30 为 0.31 mm，只计母座公差，不含焊锡、公座、屏幕尾巴/补强和整机公差。

最新整体检查：`models3d/Q2_L_AM213_Completed_Adapter.FCStd`、`output/folded-tail-check.json`。`models3d/fit-check.json` 只检查母座局部，不能证明完整插合可靠性。

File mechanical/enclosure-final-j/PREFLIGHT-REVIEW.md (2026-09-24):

# J 版打样前复查 — 2026-09-23

**结论：暂缓按“可装机样件”直接加工。静态装配和导出文件通过，但当前装入顺序未通过验证，部分结构低于嘉立创公开建议。**

本次检查的是保存的 `Q2_J_Glue_Insert_Assembly.FCStd`、当前两块最终 PCB，以及 `Q2-J-glue-insert-sample.zip` 内的真实 STEP/STL。没有修改打印几何、PCB、孔位或外观。检查不是实际试装、强度试验或工厂接单确认。旧报告中的“零干涉”只说明零件已经到位后的名义状态，不能作为整机可装配的证明。

## 需要在装机打样前解决

### 1. 滑环和按键板的装入路径没有验证通过

- 滑环沿 Z 从后方直放，在最终位置下方 5 mm 时，与**马达一体托座**及 **Y=77 mm 的后盖固定柱**相交，交叠体积合计约 **8.609 mm³**。其中马达托座约 3.123、后盖柱约 5.486 mm³。不是最终安装位置发生碰撞。
- 按键板先左移 1.2 mm，再从后方直放，在最终位置下方 5 mm 时，与上壳内部结构相交约 **33.872 mm³**；下方 3 mm 位置还有 R3 与上壳交叠。到位后的横向滑入虽然通过，但它没有覆盖从壳外放到这个高度的过程。
- 又试查了一条绕 Y 轴倾斜、向屏幕方向偏移、最后放平回位的路线。部分后段姿态通过，但早期姿态仍碰撞，**不能把它写成已验证可行的安装方法**。失败不等于证明任何倾斜方式都不可能装入。
- 原 README 中“从内部放入滑环、左移小板后滑入”的说明不完整，现已加上暂缓装配标记。

**建议修改方向：**优先把马达托座改成可后装的独立件，并给下方后盖固定柱/板边留装入通道；也可另行设计并验证倾斜路线。需要重新检查板上元件、手持空间和线束，不应靠掰弯 PCB 或薄壳强装。

证据：`preflight-path-check.json`、`preflight-tilt-probe.json`；`review-wheel-entry-collision.png` / `review-controls-entry-collision.png` 中蓝色为未到位零件、红色为碰撞位置。

### 2. 薄壁、连接桥与尺寸公差不能按“直接打印免修配”处理

| 位置 | J 版实测/构建尺寸 | 风险与处理 |
|---|---|---|
| 滑环止脱边 | 0.50 mm | 后处理和拆工艺框易损；需加厚并同步检查摇摆空间，或获得工厂明确接受 |
| 中央键止脱边 | 0.40 mm | 同上；不是因外面有工艺框就自动符合薄壁要求 |
| 工艺框连接桥 | 0.80 mm 宽 × 0.30 mm 厚 | 仅是易断连接，不能当作已符合工厂连接杆规范；应重做送印方式 |
| 小板盲孔顶部 | 0.50 mm | 限深修孔/攻牙容易顶穿；螺钉 2 mm＋0.3 mm 垫片必须配套 |
| 后盖螺丝沉槽下方 | 局部 0.45 mm | 螺钉头承压处较薄，未验证拧紧/拆装寿命；宜局部增厚并改沉槽/螺钉配合 |
| 铜螺母座壁 | 直孔段 1.05 mm，入口 0.90 mm | 本次胶粘设计通过名义几何检查，但不等于满足所有工厂紧固结构建议 |
| 胶粘孔 | Ø2.70，对外径 Ø2.50 螺母径向仅 0.10 mm | 孔缩可能吃掉胶缝；须用同批次小样试配，不能硬压。需要修孔时必须限深 |

嘉立创国内[设计规范](https://www.jlc.com/portal/q7i27832.html)推荐紧固/卡扣结构壁厚超过 1.5 mm，拼接连接杆壁厚大于 1.5 mm，并给出树脂孔径公差 ±0.3 mm。其 [JLC Black 材料说明](https://jlc3dp.com/help/article/jlc-black-resin)推荐壁厚大于 0.8 mm、100 mm 内尺寸公差 ±0.2 mm。这里据此判为**制造风险/需改图或工厂确认**，不声称工厂已经拒单。免费券另有[薄壁要求](https://www.jlc-3dp.cn/technicalColumnsDetails/56274.html)。

### 3. LCD 本体固定尚未落实

盖板与外壳之间的胶框有模型，且名义接触成立；但 **LCD 模组与外壳最近间距 0.30 mm，与盖板也相隔 0.30 mm**。当前没有专门的 LCD 固定胶层、压框或托台，LCD 只是位置包络。盖板周边胶框不能当作 LCD 已固定。

应根据实物 LCD 的可粘接边框，明确固定胶层或可装配支撑件，避开显示区及 FPC 根部，再验证屏幕定位和装入顺序。不能直接把整个屏幕背面灌胶。

## 本次已通过的项目

| 检查 | 结果和边界 |
|---|---|
| 两板来源 | 主板、CH32V006 按键板 SHA-256 与 J 版记录一致；未修改 PCB |
| 全装配静态 | 184 个物理对象，按实体逐对检查，无未豁免静态交叠，无无效实体。连接器插入、树脂螺纹啮合等有明确豁免 |
| 后盖/主板合入 | 共同沿 Z 从 -15 到 0 mm 的七个位置未碰固定部件；没有模拟 FPC/导线随闭合变形 |
| 中央键直放 | 七个 Z 位置通过；滑环和小板不通过，见前述 |
| 两颗胶粘螺母 | 连续轴向最大外径包络可插入；定位台阶、孔壁和螺钉通道检查通过，螺钉尖端名义余量 0.55 mm |
| 主板四个安装孔 | 按最终 PCB 坐标检查孔轴、Ø约2.20板孔、后盖底孔和柱顶支撑，均匹配 |
| 按键动作 | 0.33 mm 下压及四向摇摆对原检查对象通过；另查下压到 0.33 mm 未撞开关固定塑胶基体。与开关活动帽的交叠按预期压动解释，不代表实物触发力、额定行程或回弹已验证 |
| 接口开口 | 基于模型轴线的 USB 金属头、3.5 mm 插头杆、TF 卡片探针可穿过开口；未覆盖实际线缆包胶外壳、手指操作或特定 TF 弹出行程 |
| 电池增厚包络 | 增厚 0.30 mm 后无交叠，但距 U5 仅 0.15 mm；成品电池仍未选定确认 |
| 五份 STEP | 回读均为有效单实体、单闭合壳；转换回装配坐标后与保存模型的体积差为 0 |
| 五份 STL | 全部闭合、单连通，无非流形、自交或方向不一致；与 STEP 的体积相对差小于 0.041% |
| ZIP | CRC、文件哈希、文件夹/压缩包内容一致；毫米单位，无整机电子件混入单件送印文件 |

证据：`fit-check.json`、`insert-check.json`、`preflight-export-check.json`、`preflight-detail-check.json`、`preflight-path-check.json`。尺寸探针只是局部验证，不是对所有曲面的全局最小壁厚扫描。

## 其他装机约束

- CN2/CN3 必须按薄壳方案省去原高插座、改焊柔性线束。原插座仍是隐藏诊断包络，不属于本版可装配置。
- 电池成品必须符合既定空间，当前仍只有采购包络；未获得供方尺寸/充电参数确认时用绝缘尺寸块试装。
- FPC/FFC 插接厚度、锁扣操作、实际折弯和合盖余量需要实物验证。不能据名义 40 mm 路线推断任意同长度排线均可装配。
- 树脂攻牙孔不是打印螺纹。主板四孔仍需后加工；小板仅约 0.9 mm 名义啮合，不能大扭矩或频繁拆装。
- 外盖板为另购透明件；图标、黑边、铜螺母、胶层、电池和马达不在树脂打印件中。
- FreeCAD 沿用的个别对象标签仍写着 H 版/四颗小板螺钉，属于旧文字。实际 J 版小板螺钉实体为三颗，第四孔封闭；以当前参数和本报告为准。

## 打样决策

**整套装机样件：HOLD。** 先解决装入路径和 LCD 固定，再处理薄壁/工艺框并重新检查。

**纯外观试样：**若不要求装入电路板、认可薄结构后处理风险，可将本报告随模型交工厂审核后决定是否风险打印；本检查没有替工厂接受这些结构。

本次仅补充检查脚本、证据、报告和暂缓加工标记；保留原打印几何作为问题复现基线。未进行拉拔、扭矩、跌落、疲劳、热变形或制造公差全堆栈验证。

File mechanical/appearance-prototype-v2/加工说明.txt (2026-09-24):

Q2 外观样件 V2 — 树脂打印尺寸修正版

单位 mm，1:1 加工，禁止整体缩放。
用途：不装电子板，确认外观、比例和握持感；不验证按键行程、螺纹和整机装配。

请分别上传 print-parts 内五个 STL，各做 1 件。
01-body.stl：机身，50 × 81.5 × 12.3 mm。
02-rear-cover.stl：后盖，50 × 81.5 × 4.2 mm，保留 SCREW3 向板内移 0.5 mm。
03-wheel.stl：圆环，33 × 33 × 2.2 mm。
04-center-button.stl：中心键，11.4 × 11.4 × 2.2 mm。
05-screen-dummy.stl：屏幕占位片，46 × 40 × 2.2 mm，台阶形截面。

小件满足规范表中 2×2×10 mm 的整体尺寸门槛。
圆环及中心键已去除 0.2 mm 薄止退边，改为厚实外观件。
屏幕占位片面片厚 0.9 mm，底部加厚；机身内部承托面下移 0.22 mm。
正面圆环、中心键和屏幕表面高度沿用 V1，整机外观最高处仍为 14.2 mm。

V2 机身与 V2 屏幕片配套使用，不能把 V2 屏幕片直接装到 V1 机身。
按键和屏幕用少量可移除胶带或胶临时固定；这是外观样件，不是工作按键机构。
各 STL 已平移到局部原点，文件位置不代表装配位置。
reference 内 STEP 为参考，assembled-appearance.step 是整机装配参考，不能合并打印。

建议普通 SLA 树脂白模、不喷漆；材料选择及薄壁强度最终以加工方审图为准。
机身和后盖保留原局部结构；整体尺寸通过不代表全局壁厚、细孔或强度已获厂家认可。
FreeCAD 工程 Q2_Appearance_Prototype_V2.FCStd 可查看名义装配。

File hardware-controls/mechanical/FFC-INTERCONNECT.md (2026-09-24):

# 新主板与按键板 FFC 对接

依据用户完成 layout 的 `hardware-q2-layout/ProPrj_esp32s31-mp4_2026-09-21.kicad_pcb`。主板文件保持原样，小板 J1 已移动、换封装并完成局部重连。POWER 保留 10 kΩ 上拉，按下接地。

## 成品排线采购规格

建议淘宝搜索：**FFC 软排线 0.5mm 12P 40mm 反向 异面 B型 0.3厚**。

- 12 芯、0.5 mm 间距、宽 6.5 mm、总长 40 mm。
- 展平后两端金手指位于相反表面，即异面 B 型；商家命名可能不同，以实物触点面为准。
- 插入端含补强总厚度 **0.30 ±0.03 mm**。裸露金手指长度至少 3 mm，补强区域至少 4 mm。
- 两板均使用 **HC-FPC-05-10-12RLTAG 下接点连接器**。旧小板的 Hirose FH19C 需 0.2 mm 排线，已替换，不能混用。
- 本设计没有要求定制曲线 FPC。普通直排 FFC 在 X/Z 平面折返绕过主板右边缘，不做平面内斜折或扭转。

端部厚度、金手指和补强尺寸依据 [HCTL 原厂连接器图纸](https://atta.szlcsc.com/upload/public/pdf/source/20221027/B2DE489DA152049D1F105170189CFB4E.pdf)，本地副本为 `../reference/HCTL-HC-FPC-05-10.pdf`。40 mm 是名义装配路线的目标长度；具体商家货品、排线公差与补强长度尚未实物验证。

## 接口位置与针序

| 接口 | KiCad 坐标 X / Y（mm） | 板面 / 角度 | 壳体坐标 X / Y（mm） |
|---|---|---|---|
| 主板 FPC1（未移动） | 148.899 / 117.358 | B.Cu / −90° | 27.969 / 51.711 |
| 小板 J1 | 8.130 / 9.411 | B.Cu / −90° | 38.870 / 51.711 |

两个开口都朝壳体 +X。所有信号焊盘在壳体 Y 方向逐一对齐，第 1 脚 Y=48.961 mm；排线折回后按 **1→1、2→2……12→12** 对接。13/14 是接地固定脚，不是排线芯线。

| 芯号 | 主板 FPC1 网络 | 小板 J1 功能 |
|---|---|---|
| 1 | GND | GND |
| 2 | VCC_3V3 | +3V3 |
| 3 | BQ25895_I2C_SDA | SDA |
| 4 | BQ25895_I2C_CLK | SCL |
| 5 | ESP_IO43 | INT_N，共享低有效中断 |
| 6 | ESP_IO44 | RESET_N，低有效复位 |
| 7–10 | 未连接 | NC |
| 11 | ESP_IO42 | KEY_POWER，松开高、按下低 |
| 12 | GND | GND |

仅核对了接口网络映射，未修改主板上拉、固件或开关机电路。上电前用万用表确认两端针序以及 3V3/GND，不能只凭“正向/反向”商品名称判断。

## 装配调整

- 外观、屏幕、按键中心和小板板框保持不变；主板按原板框定位，成品厚度按新板的 1.6 mm 建模。
- 马达及支架从壳体中心 (39, 57) 移到 **(39, 62) mm**；电池 24×34×3 mm 占位不变。
- 小板 U1 向壳体 +X 移 0.6 mm，避开新主板耳机座；名义最小间隙约 0.245 mm。
- 后盖内卡边增加局部避让，范围 X=47.55…48.72、Y=48.161…55.261、Z=1.325…2.5 mm，外表面不变。必须使用本目录更新的 `RearCoverWithPCBPosts.step/.stl`，原 F 版后盖没有该槽。
- 排线中心线长度为 40.000 mm，壳体 Y=51.711 mm；经过主板下方、右侧边缘，再折返至小板背面。FreeCAD 中对象名为 `ControlFFC40mm`，位于 `References`。

## 已检查与待确认

小板原生 KiCad DRC、连通性、原理图一致性及 ERC 均为零。FreeCAD 已检查排线与已建模器件、主板、马达、电池及外壳的名义实体不相交，具体结果见 `fit-check.json`；两板接口映射及源文件校验值见 `../output/validation.json`。

**这仍是需实物试装的连接方案。** 排线本体厚 0.15 mm、弯曲半径 1.1 mm、连接器插入深度 2.35 mm 和槽中心高度为建模假设，原图没有完整标注这些尺寸。名义路线靠壳内壁较近，需用购买的排线与连接器检查公差、插拔空间和弯折回弹；不能把圆弧模型视为厂家允许弯曲半径。

**2026-09-22 更正：最终 `hardware-q2` 的四个安装孔与原后盖固定柱对齐，最大偏差 0.0014 mm；此前不匹配的判断不准确。** 完整复查另外发现马达与耳机座、C13 与屏幕排线干涉，见 `../../mechanical/final-board-review/README.md`。主板 CN2/CN3 缺少可靠实体模型，电池和马达线束也尚未按新端子重布；本次不宣称整机可直接装配投产。主板其余模型复用同封装的名义模型，不能替代实际料号高度核对。

打开 `Q2_Controls_Assembly.FCStd` 查看完整装配；`ffc-interconnect.png` 为排线局部三维视图。所有坐标、假设和源文件散列保存在 `interconnect-plan.json`。

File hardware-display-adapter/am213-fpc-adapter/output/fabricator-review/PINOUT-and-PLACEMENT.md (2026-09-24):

# A 版接线与坐标

元件岛 **17×22 mm**；左出尾巴展开长 **70 mm**、主体宽 **6.60 mm**，最后 2 mm 向元件岛扩展。顶层信号/电源，背层地铜回流。

## 坐标与方向

按 KiCad 元件面顶视图，元件岛左上角局部 (0,0)=KiCad (50,50)，X 向右、Y 向下。

| 项目 | 板框局部 mm | KiCad 全局 mm |
|---|---|---|
| J2 母座中心 | **(3.000,12.000)** | **(53.000,62.000)** |
| J1 金手指中心 | (-68.600,12.4005) | (-18.600,62.4005) |
| 尾巴切边中心 | (-70.000,12.4005) | (-20.000,62.4005) |

J2 为 OK-23GF024-04、长轴 Y，**1 脚左上、12 脚左下、13 脚右下、24 脚右上**，圆点标记 1 脚。针号依据屏厂 AM213 实板照片核对。J1 金手指 1 脚在下方，21 脚在上方，露铜面 F.Cu。

J2 比上一轮占位向右移动 0.5 mm，以留出扇出空间。装配元件岛左上角 (29,8)，J2 底面中心 **(32,20,10.1) mm**。旧坐标 (2.5,12)/(31.5,20,10.1) 已失效。

## 接线表

J1 是插入已生产主板 FPC2 的金手指，不另装插座。

| 主板 FPC2/J1 | 功能 | 屏端 J2 | 处理 |
|---:|---|---:|---|
| 3 | IO47 / LCD_RST | 1 | 直连 |
| 4 | IO46 / VCI_EN | 24 | 直连，100k 下拉 |
| 5 | CLK | 5 | R1 22Ω，按实测调整 |
| 7 | CS | 4 | R2 0Ω |
| 8 | D3 | 22 | R6 0Ω |
| 9 | D2 | 23 | R5 0Ω |
| 10 | D1 | 6 | R4 0Ω |
| 11 | D0 | 7 | R3 0Ω，保留双向能力 |
| 12、17 | GND | 2、8、13、14、21、MP | 共地 |
| 13、14 | 3.3 V | 11、12 | VBAT，C1/C2 去耦 |
| 13、14 | 3.3 V | 15 | R7 0Ω，C3 去耦 |
| 13、14 | 3.3 V | 16 | R8 0Ω，C4 去耦 |
| 18 | IO54 / TP_INT | 17 | 直连 |
| 19 | SCL | 20 | 沿用主板 R45 上拉 |
| 20 | SDA | 19 | 沿用主板 R46 上拉 |
| 21 | IO57 / TP_RST | 18 | 直连 |
| 1、2 | 旧 LEDA/LEDK | 无 | 金手指后隔离 |
| 6、15、16 | 空脚 | 无 | 不连接 |
| 无 | LCD_TE | 3 | TP1 测试，未接 MCU |
| 无 | NC_IM1/NC_MTP | 9、10 | 按参考板悬空 |

R10/R11 是备用 I²C 上拉，默认 **DNP 不装**。独立 NC 网络只为 KiCad 一致性，不构成外部连接。串阻位于转接板，不能冒充主板源端匹配。先低速点亮，实测供电、波形后提速。

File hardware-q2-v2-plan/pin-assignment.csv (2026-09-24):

pin | pin_name | gpio | group | signal | old_net | direction | target | reset_requirement | notes | board_side_at_minus90
1 | ANT |  | 射频 | ANT |  | 专用 | RF匹配/天线 | 按RF参考设计 | 专用射频端口 | 上
2 | VDDA3 |  | 电源 | 3V3_VDDA3 |  | 专用 | 3.3V域，局部滤波/去耦 | 按每个电源脚放去耦 | VDDA模拟电源滤波不可省略 | 上
3 | VDDA4 |  | 电源 | 3V3_VDDA4 |  | 专用 | 3.3V域，局部滤波/去耦 | 按每个电源脚放去耦 | VDDA模拟电源滤波不可省略 | 上
4 | CHIP_PU |  | 复位 | CHIP_PU | ESP32S31_EN | 专用 | RC及CH343下载控制电路 | 10k上拉/RC按参考设计 | 旧网ESP32S31_EN；必须核对自动下载握手，不能误当普通GPIO | 上
5 | XTAL_32K_N/GPIO0 | 0 | 唤醒/中断 | KEY_POWER_SENSE_N | ESP_IO42 | 输入 | FPC1.11 / U6.1，经3.3V隔离检测 | 输入；上拉仅接3.3V；GPIO3极性由IMU配置 | LP GPIO；唤醒需要固件配置。KEY必须隔离GEK供电域；不得原样直连。 | 上
6 | XTAL_32K_P/GPIO1 | 1 | 唤醒/中断 | CTRL_INT_N | ESP_IO43 | 输入 | FPC1.5 | 输入；上拉仅接3.3V；GPIO3极性由IMU配置 | LP GPIO；可按需要配置唤醒，保持供电时才有效。 | 上
7 | GPIO2 | 2 | 唤醒/中断 | RTC_INT_N | ESP_IO34 | 输入 | U1.6 | 输入；上拉仅接3.3V；GPIO3极性由IMU配置 | LP GPIO；可按需要配置唤醒，保持供电时才有效。 | 上
8 | GPIO3 | 3 | 唤醒/中断 | IMU_INT1 | ESP_IO1 | 输入 | U15.4 | 输入；上拉仅接3.3V；GPIO3极性由IMU配置 | LP GPIO；可按需要配置唤醒，保持供电时才有效。 | 上
9 | GPIO4 | 4 | 唤醒/中断 | BAT_ALERT_N | ESP_IO35 | 输入 | U14.1 | 输入；上拉仅接3.3V；GPIO3极性由IMU配置 | LP GPIO；可按需要配置唤醒，保持供电时才有效。 | 上
10 | GPIO5 | 5 | 唤醒/中断 | CHG_INT_N | BQ25895_INT | 输入 | U3.7 | 输入；上拉仅接3.3V；GPIO3极性由IMU配置 | LP GPIO；可按需要配置唤醒，保持供电时才有效。 | 上
11 | VDDPST_1 |  | 电源 | 3V3_VDDPST_1 |  | 专用 | 3.3V域，局部滤波/去耦 | 按每个电源脚放去耦 | VDDA模拟电源滤波不可省略 | 上
12 | GPIO6 | 6 | 系统LP I2C | SYS_I2C_SCL | BQ25895_I2C_CLK | 开漏双向 | U3.5 U14.3 U1.2 U11.2 FPC1.4 | 外部上拉3.3V | LP I2C，F2；100kHz起步；不是I2C_NUM_2 | 上
13 | GPIO7 | 7 | 系统LP I2C | SYS_I2C_SDA | BQ25895_I2C_SDA | 开漏双向 | U3.6 U14.2 U1.3 U11.3 FPC1.3 | 外部上拉3.3V | LP I2C，F2；LP核访问须与主核通过命令/共享内存协调 | 上
14 | GPIO8 | 8 | 空闲GPIO | SPARE_GPIO8 |  | 预留 |  | 不接外设，固件避免悬空 | 供后续扩展；不得替代电源/USB专用脚 | 上
15 | GPIO9 | 9 | 系统控制 | POWER_OFF_REQ | GEK100_RST | 输出 | U6.3，经断电防反灌电路 | 外部下拉；上电低 | 新增软件关机请求；高有效，需保证掉电后复位脉冲时长 | 上
16 | GPIO10 | 10 | 系统控制 | CTRL_RESET_N | ESP_IO44 | 开漏输出 | FPC1.6 | 释放，由小板RC上拉 | CH32V006 PD7配置硬件复位后才生效 | 上
17 | GPIO11 | 11 | 系统控制 | USB_PATH_SEL | ESP_IO33 | 输出 | U17.2 | 外部电阻固定默认路径 | 避开GPIO33复位USB功能；0/1对应哪路须核对U17真值表 | 上
18 | VREF_TOUCH |  | 模拟预留 | NC_VREF_TOUCH |  | 专用 | 本方案不用触摸/ADC则按手册处理 | 不作为GPIO | 后续启用相关功能须补参考电容 | 上
19 | GPIO12 | 12 | 系统控制 | MOTOR_EN | ESP_IO40 | 输出 | U11.5 | 外部下拉；默认关闭 | 保留现有R44下拉；PWM/触发使用需按马达驱动配置 | 上
20 | GPIO13 | 13 | 系统控制 | CHG_OTG_EN | BQ25895_OTG_EN | 输出 | U3.8 | 外部下拉；默认关闭 | 保留R12下拉；不得上电即打开OTG | 上
21 | GPIO14 | 14 | 音频HP I2C0 | AUDIO_I2C_SCL | DAC_I2C_SCL | 开漏双向 | U7.6 U15.13 | 保留3.3V侧上拉 | HP I2C0经GPIO Matrix；U7后为1.8V DAC总线 | 左
22 | GPIO15 | 15 | 音频HP I2C0 | AUDIO_I2C_SDA | DAC_I2C_SDA | 开漏双向 | U7.5 U15.14 | 保留3.3V侧上拉 | HP I2C0经GPIO Matrix；U7后为1.8V DAC总线 | 左
23 | GPIO16 | 16 | 空闲GPIO | SPARE_GPIO16 |  | 预留 |  | 不接外设，固件避免悬空 | 供后续扩展；不得替代电源/USB专用脚 | 左
24 | GPIO17 | 17 | 空闲GPIO | SPARE_GPIO17 |  | 预留 |  | 不接外设，固件避免悬空 | 供后续扩展；不得替代电源/USB专用脚 | 左
25 | GPIO18 | 18 | 空闲GPIO | SPARE_GPIO18 |  | 预留 |  | 不接外设，固件避免悬空 | 供后续扩展；不得替代电源/USB专用脚 | 左
26 | GPIO19 | 19 | 系统控制 | SD_CARD_DETECT_N | ESP_IO19 | 输入 | CARD2.CD | 新增/核对3.3V上拉 | 检测触点极性以实物卡座导通确认 | 左
27 | SDIO_DATA0 | 20 | SDMMC | SD_D0 | ESP_TF_DAT0 | 双向 | CARD2.7 | CMD/D0-D3上拉3.3V；CLK不随意加上拉 | 原生SDIO F0；本板卡接口先用3.3V，不直接改1.8V模式 | 左
28 | SDIO_DATA1 | 21 | SDMMC | SD_D1 | ESP_TF_DAT1 | 双向 | CARD2.8 | CMD/D0-D3上拉3.3V；CLK不随意加上拉 | 原生SDIO F0；本板卡接口先用3.3V，不直接改1.8V模式 | 左
29 | SDIO_DATA2 | 22 | SDMMC | SD_D2 | ESP_TF_DAT2 | 双向 | CARD2.1 | CMD/D0-D3上拉3.3V；CLK不随意加上拉 | 原生SDIO F0；本板卡接口先用3.3V，不直接改1.8V模式 | 左
30 | VDD_PSRAM_1P8_1 |  | 电源 | VDD_PSRAM_1P8_1 |  | 专用 | VDD_LDO_1P8，按参考电路 | 1.8V PSRAM供电 | 不是3.3V输入 | 左
31 | SDIO_DATA3 | 23 | SDMMC | SD_D3 | ESP_TF_DAT3 | 双向 | CARD2.2 | CMD/D0-D3上拉3.3V；CLK不随意加上拉 | 原生SDIO F0；本板卡接口先用3.3V，不直接改1.8V模式 | 左
32 | SDIO_CLK | 24 | SDMMC | SD_CLK | ESP_TF_CLK | 输出 | CARD2.5 | CMD/D0-D3上拉3.3V；CLK不随意加上拉 | 原生SDIO F0；本板卡接口先用3.3V，不直接改1.8V模式 | 左
33 | SDIO_CMD | 25 | SDMMC | SD_CMD | ESP_TF_CMD | 双向 | CARD2.3 | CMD/D0-D3上拉3.3V；CLK不随意加上拉 | 原生SDIO F0；本板卡接口先用3.3V，不直接改1.8V模式 | 左
34 | VDD_PSRAM_1P8_2 |  | 电源 | VDD_PSRAM_1P8_2 |  | 专用 | VDD_LDO_1P8，按参考电路 | 1.8V PSRAM供电 | 不是3.3V输入 | 左
35 | VDD_LDO_1P8 |  | 电源 | VDD_LDO_1P8 |  | 专用 | PSRAM 1.8V供电和去耦 | 芯片电源输出 | 不能接外部3.3V | 左
36 | SPICS | 26 | 启动Flash | FLASH_CS_N | ESP_FLASH_CS | 输出 | U10.1 | 按启动Flash参考电路 | 固定MSPI引脚；不分给应用GPIO；U10容量待选，建议与原模组16MB目标一致 | 左
37 | SPIQ | 27 | 启动Flash | FLASH_D1 | ESP_FLASH_DO | 双向 | U10.2 | 按启动Flash参考电路 | 固定MSPI引脚；不分给应用GPIO；U10容量待选，建议与原模组16MB目标一致 | 左
38 | SPIWP | 28 | 启动Flash | FLASH_D2 | ESP_FLASH_WP | 双向 | U10.3 | 按启动Flash参考电路 | 固定MSPI引脚；不分给应用GPIO；U10容量待选，建议与原模组16MB目标一致 | 左
39 | VDD_SPI |  | 电源 | VDD_SPI |  | 专用 | 外接Flash供电/去耦 | 按3.3V Flash参考电路 | 结合GPIO36配置；不是任意与外部电源并接 | 左
40 | SPIHD | 30 | 启动Flash | FLASH_D3 | ESP_FLASH_HOLD | 双向 | U10.7 | 按启动Flash参考电路 | 固定MSPI引脚；不分给应用GPIO；U10容量待选，建议与原模组16MB目标一致 | 左
41 | SPICLK | 31 | 启动Flash | FLASH_CLK | ESP_FLASH_CLK | 输出 | U10.6 | 按启动Flash参考电路 | 固定MSPI引脚；不分给应用GPIO；U10容量待选，建议与原模组16MB目标一致 | 下
42 | SPID | 32 | 启动Flash | FLASH_D0 | ESP_FLASH_DI | 双向 | U10.5 | 按启动Flash参考电路 | 固定MSPI引脚；不分给应用GPIO；U10容量待选，建议与原模组16MB目标一致 | 下
43 | VCCA/VDDPST_2 |  | 电源 | 3V3_VCCA/VDDPST_2 |  | 专用 | 3.3V域，局部滤波/去耦 | 按每个电源脚放去耦 | VDDA模拟电源滤波不可省略 | 下
44 | USB_DP |  | USB HS | USB_HS_DP | ESP_USB_DP | 专用 | U17.7 | 专用差分 | 旧网ESP_USB_DP；不是GPIO44 | 下
45 | USB_DM |  | USB HS | USB_HS_DM | ESP_USB_DN | 专用 | U17.6 | 专用差分 | 旧网ESP_USB_DN；不是GPIO45 | 下
46 | GPIO33 | 33 | 调试预留 | USB_DEBUG_DM |  | 专用差分 | 新增调试焊盘/连接器 | 保留USB Serial/JTAG功能 | 不再接USB切换SEL；与HS USB不是同一对线，不可并接 | 下
47 | GPIO34 | 34 | 调试预留 | USB_DEBUG_DP |  | 专用差分 | 新增调试焊盘/连接器 | 保留USB Serial/JTAG功能 | 不再接RTC中断；量产无调试连接器时可不装引出件 | 下
48 | GPIO35 | 35 | 音频I2S | DAC_I2S_DOUT | DAC_I2S_SDIN | 输出 | U8.2 | RESET默认低；时钟初始化前静止 | GPIO Matrix；保留U8到1.8V域转换；DOUT是ESP输出，旧网SDIN按DAC视角命名 | 下
49 | GPIO36 | 36 | 启动配置 | STRAP_FLASH_3V3 |  | 启动采样 | 启动上拉/下载电路 | 10k候选上拉3.3V | 默认eFuse下高选择3.3V；不得悬空/接外部中断 | 下
50 | GPIO37 | 37 | 启动配置 | STRAP_USB_JTAG |  | 启动采样 | 启动上拉/下载电路 | 10k候选上拉3.3V | 无内部上下拉；当JTAG_SEL_ENABLE启用时高选USB JTAG；不为此烧eFuse | 下
51 | GPIO38 | 38 | 音频I2S | DAC_I2S_LRCK | DAC_I2S_LRCK | 输出 | U8.5 | RESET默认低；时钟初始化前静止 | GPIO Matrix；保留U8到1.8V域转换；DOUT是ESP输出，旧网SDIN按DAC视角命名 | 下
52 | GPIO39 | 39 | 音频I2S | DAC_RESET_N | DAC_RST# | 输出 | U8.12 | RESET默认低；时钟初始化前静止 | GPIO Matrix；保留U8到1.8V域转换；DOUT是ESP输出，旧网SDIN按DAC视角命名 | 下
53 | GPIO40 | 40 | 音频I2S | DAC_I2S_BCLK | DAC_I2S_SCLK | 输出 | U8.9 | RESET默认低；时钟初始化前静止 | GPIO Matrix；保留U8到1.8V域转换；DOUT是ESP输出，旧网SDIN按DAC视角命名 | 下
54 | VDDPST_3 |  | 电源 | 3V3_VDDPST_3 |  | 专用 | 3.3V域，局部滤波/去耦 | 按每个电源脚放去耦 | VDDA模拟电源滤波不可省略 | 下
55 | GPIO42 | 42 | 触屏HP I2C1 | TP_I2C_SCL | ESP_I2C2_SCL | 开漏双向 | JDISP1.20 | 3.3V上拉，屏幕断电时防反灌 | HP I2C1；与系统/音频总线隔离，无需假定触控IC地址 | 下
56 | GPIO43 | 43 | 触屏HP I2C1 | TP_I2C_SDA | ESP_I2C2_SDA | 开漏双向 | JDISP1.19 | 3.3V上拉，屏幕断电时防反灌 | HP I2C1；与系统/音频总线隔离，无需假定触控IC地址 | 下
57 | GPIO44 | 44 | 屏幕控制 | LCD_RESET_N | ESP_IO47 | 输出 | JDISP1.1 | 默认低；电源稳定后释放 | 3.3V沿用本项目屏幕方案；供电域和上下电次序仍须验证 | 下
58 | GPIO45 | 45 | 屏幕控制 | LCD_VCI_EN | ESP_IO46 | 输出 | JDISP1.24 | 默认低；按屏幕电源时序使能 | 3.3V沿用本项目屏幕方案；供电域和上下电次序仍须验证 | 下
59 | GPIO46 | 46 | 屏幕控制 | LCD_TE | AM213_TE_RESERVED | 输入 | JDISP1.3 | 输入，禁止驱动屏幕TE | 3.3V沿用本项目屏幕方案；供电域和上下电次序仍须验证 | 下
60 | GPIO47 | 47 | 屏幕控制 | TP_INT_N | ESP_IO54 | 输入 | JDISP1.17 | 按触控规格配置中断/上拉 | 3.3V沿用本项目屏幕方案；供电域和上下电次序仍须验证 | 下
61 | GPIO48 | 48 | 屏幕控制 | TP_RESET_N | ESP_IO57 | 输出 | JDISP1.18 | 默认低；按触控规格释放 | 3.3V沿用本项目屏幕方案；供电域和上下电次序仍须验证 | 右
62 | GPIO49 | 49 | 空闲GPIO | SPARE_GPIO49 |  | 预留 |  | 不接外设，固件避免悬空 | 供后续扩展；不得替代电源/USB专用脚 | 右
63 | VREF_ADC |  | 模拟预留 | NC_VREF_ADC |  | 专用 | 本方案不用触摸/ADC则按手册处理 | 不作为GPIO | 后续启用相关功能须补参考电容 | 右
64 | VDDPST_4 |  | 电源 | 3V3_VDDPST_4 |  | 专用 | 3.3V域，局部滤波/去耦 | 按每个电源脚放去耦 | VDDA模拟电源滤波不可省略 | 右
65 | GPIO50 | 50 | 空闲GPIO | SPARE_GPIO50 |  | 预留 |  | 不接外设，固件避免悬空 | 供后续扩展；不得替代电源/USB专用脚 | 右
66 | GPIO51 | 51 | 空闲GPIO | SPARE_GPIO51 |  | 预留 |  | 不接外设，固件避免悬空 | 供后续扩展；不得替代电源/USB专用脚 | 右
67 | GPIO52 | 52 | 屏幕QSPI | LCD_CS_N | ESP_SPI2_CS | 输出/总线 | JDISP1.4 | CS上拉、CLK低；解除传统JTAG复用 | 手册F2=SPI2_CS；SPI2_HOST；SDK IOMUX路径待验证，先按GPIO Matrix <=40MHz调试 | 右
68 | GPIO53 | 53 | 屏幕QSPI | LCD_CLK | ESP_SPI2_CLK | 输出/总线 | JDISP1.5 | CS上拉、CLK低；解除传统JTAG复用 | 手册F2=SPI2_CK；SPI2_HOST；SDK IOMUX路径待验证，先按GPIO Matrix <=40MHz调试 | 右
69 | MTDO | 54 | 屏幕QSPI | LCD_D0 | ESP_SPI2_D0 | 输出/总线 | JDISP1.7 | CS上拉、CLK低；解除传统JTAG复用 | 手册F2=SPI2_D；SPI2_HOST；SDK IOMUX路径待验证，先按GPIO Matrix <=40MHz调试 | 右
70 | MTCK | 55 | 屏幕QSPI | LCD_D1 | ESP_SPI2_D1 | 输出/总线 | JDISP1.6 | CS上拉、CLK低；解除传统JTAG复用 | 手册F2=SPI2_Q；SPI2_HOST；SDK IOMUX路径待验证，先按GPIO Matrix <=40MHz调试 | 右
71 | MTDI | 56 | 屏幕QSPI | LCD_D3 | ESP_SPI2_D3 | 输出/总线 | JDISP1.22 | CS上拉、CLK低；解除传统JTAG复用 | 手册F2=SPI2_HOLD；SPI2_HOST；SDK IOMUX路径待验证，先按GPIO Matrix <=40MHz调试 | 右
72 | MTMS | 57 | 屏幕QSPI | LCD_D2 | ESP_SPI2_D2 | 输出/总线 | JDISP1.23 | CS上拉、CLK低；解除传统JTAG复用 | 手册F2=SPI2_WP；SPI2_HOST；SDK IOMUX路径待验证，先按GPIO Matrix <=40MHz调试 | 右
73 | GPIO58 | 58 | 下载UART0 | UART0_TX | CH343P_UART_RX | 输出 | U12.5 RXD | UART0默认输出 | ESP TX接CH343 RX，勿按旧网络后缀反接 | 右
74 | GPIO59 | 59 | 下载UART0 | UART0_RX | CH343P_UART_TX | 输入 | U12.4 TXD | UART0输入 | ESP RX接CH343 TX | 右
75 | GPIO60 | 60 | 启动配置 | BOOT_MODE_H | ESP_BOOT2 | 启动采样 | 启动上拉/下载电路 | 10k候选上拉3.3V | 下载时必须高；不复用普通外设 | 右
76 | GPIO61 | 61 | 启动配置 | BOOT_DOWNLOAD_N | ESP_BOOT1 | 启动采样 | 启动上拉/下载电路 | 10k候选上拉3.3V | 正常高；下载时拉低，同时GPIO60高；通过下载控制电路 | 右
77 | VDDA1 |  | 电源 | 3V3_VDDA1 |  | 专用 | 3.3V域，局部滤波/去耦 | 按每个电源脚放去耦 | VDDA模拟电源滤波不可省略 | 右
78 | XTAL_N |  | 晶振 | XTAL_N |  | 专用 | 40MHz晶振/匹配 | 专用时钟 | 按乐鑫参考设计，不能随意加长/过孔 | 右
79 | XTAL_P |  | 晶振 | XTAL_P |  | 专用 | 40MHz晶振/匹配 | 专用时钟 | 需要参考设计指定的串联电感/负载网络 | 右
80 | VDDA2 |  | 电源 | 3V3_VDDA2 |  | 专用 | 3.3V域，局部滤波/去耦 | 按每个电源脚放去耦 | VDDA模拟电源滤波不可省略 | 右
81 | GND |  | 地 | GND_EP |  | 专用 | 连续GND/散热过孔 | 可靠接地 | 封装中央裸露焊盘，不是GPIO81 | 中央

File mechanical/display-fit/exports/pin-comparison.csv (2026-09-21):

pin | mainboard_net | screen_function | socket_case_y_mm | unshifted_screen_pin_y_mm | offset_mm
1 | LCD_LEDA | UNKNOWN | 21.034 | 24.9 | 3.866
2 | LCD_LEDK | UNKNOWN | 20.734 | 24.6 | 3.866
3 | ESP_IO47 | UNKNOWN | 20.434 | 24.3 | 3.866
4 | ESP_IO46 | UNKNOWN | 20.134 | 24.0 | 3.866
5 | ESP_SPI2_CLK | UNKNOWN | 19.834 | 23.7 | 3.866
6 | unconnected-(FPC2-Pad6) | UNKNOWN | 19.534 | 23.4 | 3.866
7 | ESP_SPI2_CS | UNKNOWN | 19.234 | 23.1 | 3.866
8 | ESP_SPI2_D3 | UNKNOWN | 18.934 | 22.8 | 3.866
9 | ESP_SPI2_D2 | UNKNOWN | 18.634 | 22.5 | 3.866
10 | ESP_SPI2_D1 | UNKNOWN | 18.334 | 22.2 | 3.866
11 | ESP_SPI2_D0 | UNKNOWN | 18.034 | 21.9 | 3.866
12 | GND | UNKNOWN | 17.734 | 21.6 | 3.866
13 | VCC_3V3 | UNKNOWN | 17.434 | 21.3 | 3.866
14 | VCC_3V3 | UNKNOWN | 17.134 | 21.0 | 3.866
15 | unconnected-(FPC2-Pad15) | UNKNOWN | 16.834 | 20.7 | 3.866
16 | unconnected-(FPC2-Pad16) | UNKNOWN | 16.534 | 20.4 | 3.866
17 | GND | UNKNOWN | 16.234 | 20.1 | 3.866
18 | ESP_IO54 | UNKNOWN | 15.934 | 19.8 | 3.866
19 | ESP_I2C2_SCL | UNKNOWN | 15.634 | 19.5 | 3.866
20 | ESP_I2C2_SDA | UNKNOWN | 15.334 | 19.2 | 3.866
21 | ESP_IO57 | UNKNOWN | 15.034 | 18.9 | 3.866

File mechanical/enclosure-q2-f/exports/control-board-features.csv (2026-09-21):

feature | local_x_mm | local_y_mm | side | size_mm | status
Power | 22.000 | 17.000 | front | 3x3x0.55 | mechanical keepout only
Back | 22.000 | 4.000 | front | 3x3x0.55 | mechanical keepout only
Previous | 35.000 | 17.000 | front | 3x3x0.55 | mechanical keepout only
Next | 9.000 | 17.000 | front | 3x3x0.55 | mechanical keepout only
PlayPause | 22.000 | 30.000 | front | 3x3x0.55 | mechanical keepout only
Mount1 | 3.000 | 8.700 | through | D1.8 | NPTH mechanical proposal
Mount2 | 41.000 | 8.700 | through | D1.8 | NPTH mechanical proposal
Mount3 | 3.000 | 24.700 | through | D1.8 | NPTH mechanical proposal
Mount4 | 41.000 | 24.700 | through | D1.8 | NPTH mechanical proposal
ControlFPC | 37.750 | 5.700 | rear | 7.5x3x1 | connector and pinout TBD

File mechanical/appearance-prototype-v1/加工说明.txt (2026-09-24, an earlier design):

Q2 外观样件 V1

用途：先确认外观比例、大小和握持感。保持当前外观造型；SCREW3 对应固定柱和孔已向板内移 0.5 mm。

请按毫米（mm）、1:1 比例加工，不自动缩放。
print-parts 文件夹中每个 STL 各做 1 件，分别打印，不融合成整体：
  01-body.stl           机身
  02-rear-cover.stl     后盖
  03-wheel.stl          圆环
  04-center-button.stl  中心键
  05-screen-dummy.stl   屏幕外观占位片（可选）

机身外观尺寸约 50 × 81.5 × 13.5 mm；包含屏幕盖片的总厚度约 14.2 mm。
第 5 件为 46 × 40 × 0.6 mm 的圆角薄片，用于模拟黑色屏幕表面。
若不打印这片，可按对应 STEP 轮廓裁切薄片并贴黑色膜。

外观配色参考：机身/后盖/中心键为银灰色，圆环和屏幕占位片为黑色。
只确认白模外形时，不要求喷漆、丝印或按键图标。
外观面尽量减少支撑痕迹，打印朝向、支撑和后处理由加工方安排。
零件已分别平移到局部坐标原点；STL 中的位置不代表装配位置。

不装电子板时，圆环、中心键和屏幕占位片可用少量可移除胶带从内部临时固定。
后盖只需临时合拢用于看外观，不要求本次验证螺纹、按键行程或内部装配。

reference 中的 STEP 和装配预览用于尺寸/外观参考。
Q2_Appearance_Prototype_V1.FCStd 为仅含外观零件的 FreeCAD 工程。
实际打印文件以 print-parts 内的独立 STL 为准；不要把整机装配 STEP 合并打印。

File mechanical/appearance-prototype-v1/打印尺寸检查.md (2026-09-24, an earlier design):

# 打印尺寸筛选检查（2026-09-22）

用户提供的报错为多个材料均提示“商品不符合材料尺寸限制”。已确认上传的是 03-wheel.stl、04-center-button.stl、05-screen-dummy.stl，正好对应下面三个不满足整体尺寸门槛的薄件。

已实际打开[嘉立创3D打印设计规范](https://www.jlc-3dp.cn/technicalColumnsDetails/27832.html)，读取页面顶部“我们机器的打印尺寸”图表。6060、9600、9000HE、JLC Black、Black、Imagine Black、8001、8228、CBY、Grey、JLC Temp 等树脂行列出的最小打印尺寸为 **5×5×5 mm / 2×2×10 mm**。这是整体外形尺寸限制，与薄壁的局部最小厚度是两个不同检查。

逐三角面读取当前 STL 的实际包围盒（mm），结果如下：

| 文件 | 实际尺寸，mm | 整体尺寸筛选 |
|---|---|---|
| 01-body.stl | 50 × 81.5 × 12.3 | 满足 |
| 02-rear-cover.stl | 50 × 81.5 × 4.2 | 满足 |
| 03-wheel.stl | 34.4 × 34.4 × 1.2 | 不满足，最短边不足 2 mm |
| 04-center-button.stl | 13.8 × 13.8 × 1.15 | 不满足，最短边不足 2 mm |
| 05-screen-dummy.stl | 46 × 40 × 0.6 | 不满足，最短边不足 2 mm |

因此，三个薄件足以触发该提示；不能直接把这串提示理解为机身不可打印。如果报错对象是机身或后盖，需要进一步核对上传文件名及网页识别的长宽高，特别检查单位、比例和是否误上传整个装配 STEP。STL 本身不携带长度单位，应按 mm 导入。

处理建议：机身、后盖单独上传对应 STL；圆环和中心键另做厚度大于 2 mm、去除薄弱止退边的外观样件，并重新检查装配；0.6 mm 屏幕占位片可改用裁切薄片，不必树脂打印。不要整体缩放整机，也不要添加没有实际用途的凸点来绕过筛选。

当前轮环/中心键仍有约 0.20 mm 的止退薄边、轮环面片约 0.60 mm，因此即便整体尺寸满足，也不能据此宣称通过薄壁、强度和装配审核。原“实体有效、网格闭合”的检查不能替代材料制造性检查。

V1 和既有 ZIP 保留不变；其中三个薄件不作为可直接提交打印的零件。已另生成 `mechanical/appearance-prototype-v2/` 和 `mechanical/Q2-appearance-prototype-v2.zip`：圆环、中心键、屏幕占位片总厚 2.2 mm；去除薄止退边，屏幕占位片采用台阶结构，机身隐藏承托面下移 0.22 mm。V2 为外观临时固定样件，V2 机身与屏幕必须配套使用。五件本地整体尺寸、有效实体、闭合 STL 及名义相交检查通过，不等于厂家已通过 DFM。V1 的数值和文件散列见 `print-size-audit.json`。

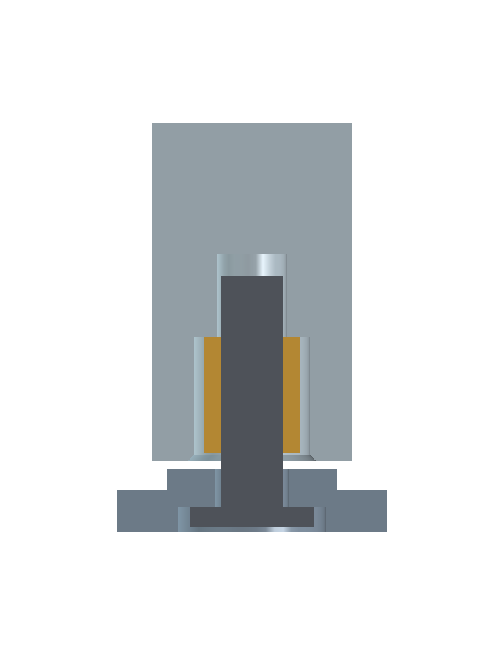
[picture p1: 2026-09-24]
mechanical/enclosure-final-l/insert-section.png

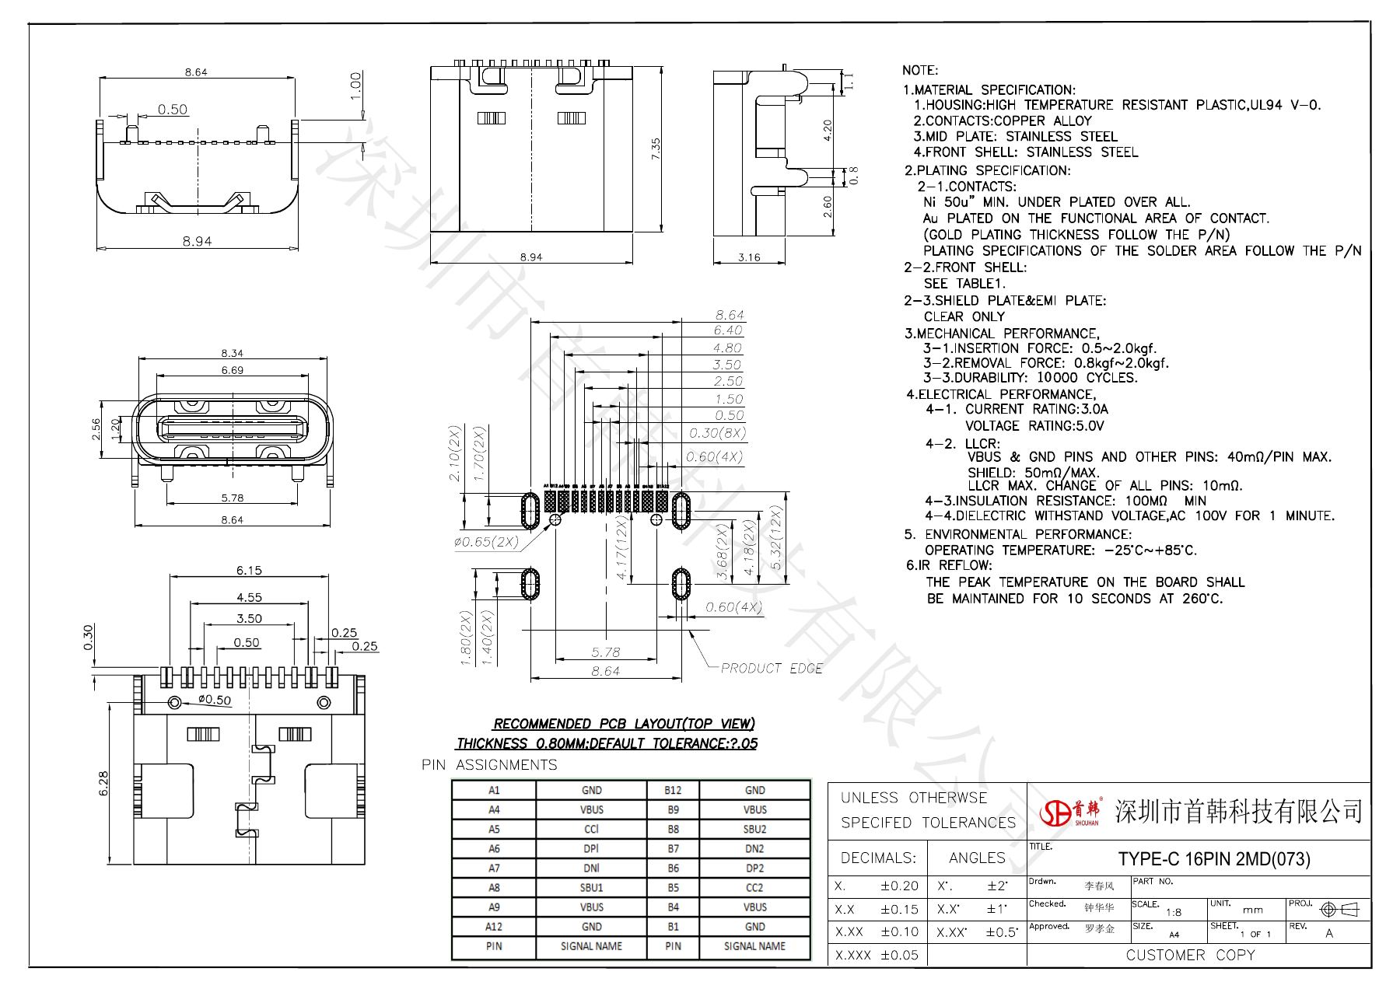
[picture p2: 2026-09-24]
hardware-q2-v2/reference/usb-connector.png

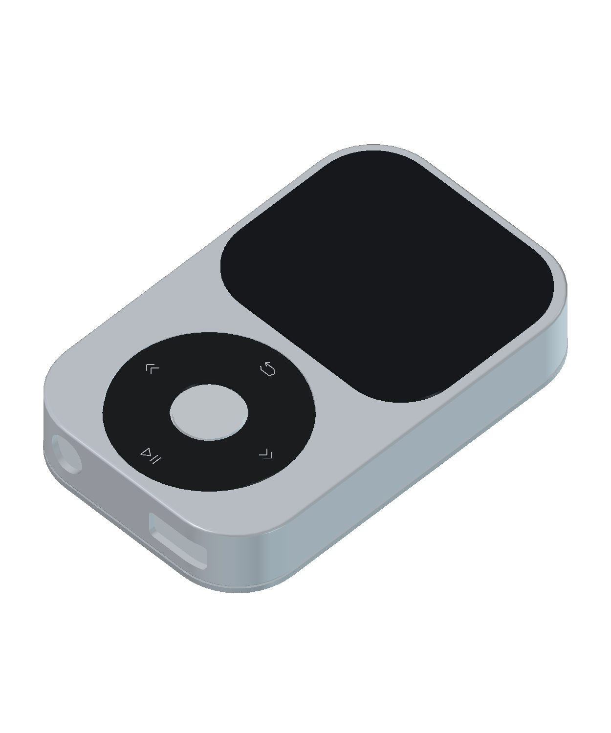
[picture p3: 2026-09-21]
mechanical/enclosure-q2-c/exports/exterior-C.png

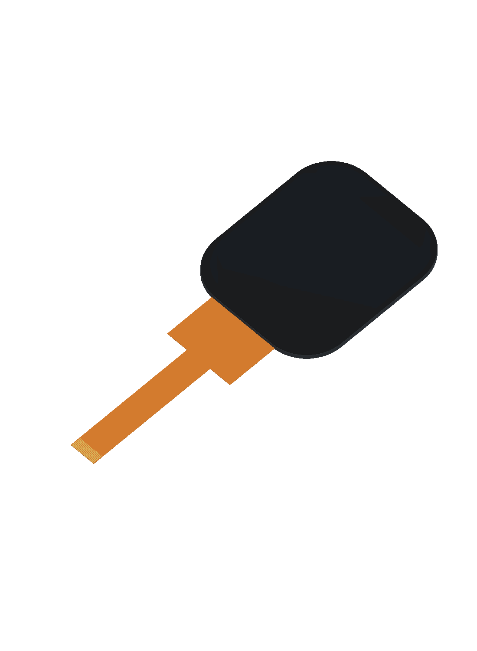
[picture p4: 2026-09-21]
mechanical/enclosure-q2/exports/lcd-flat-isometric.png

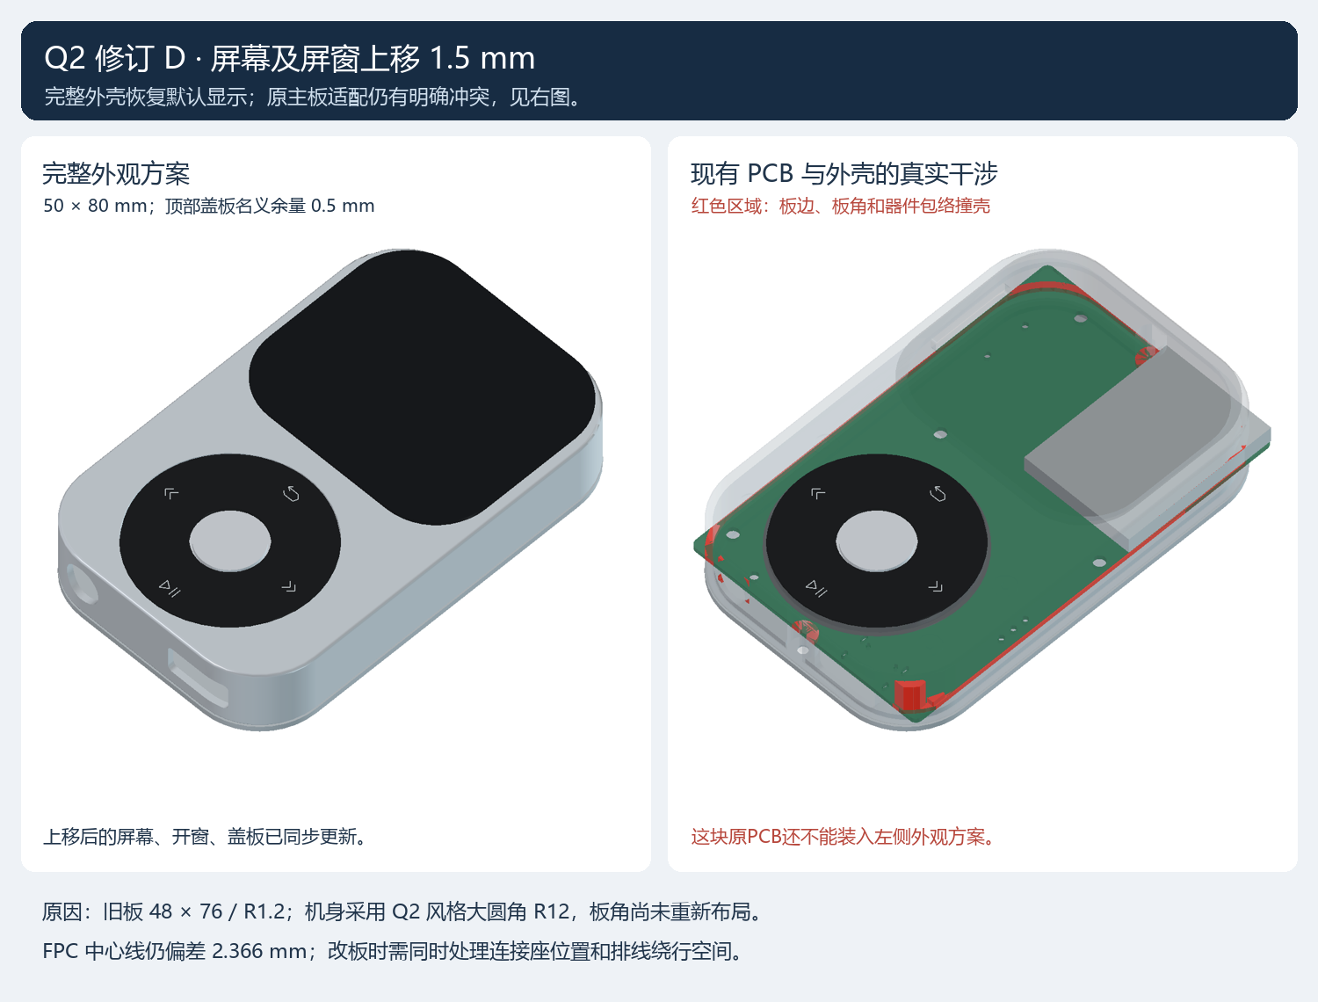
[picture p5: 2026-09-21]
mechanical/enclosure-q2-d/exports/revision-D-review.png

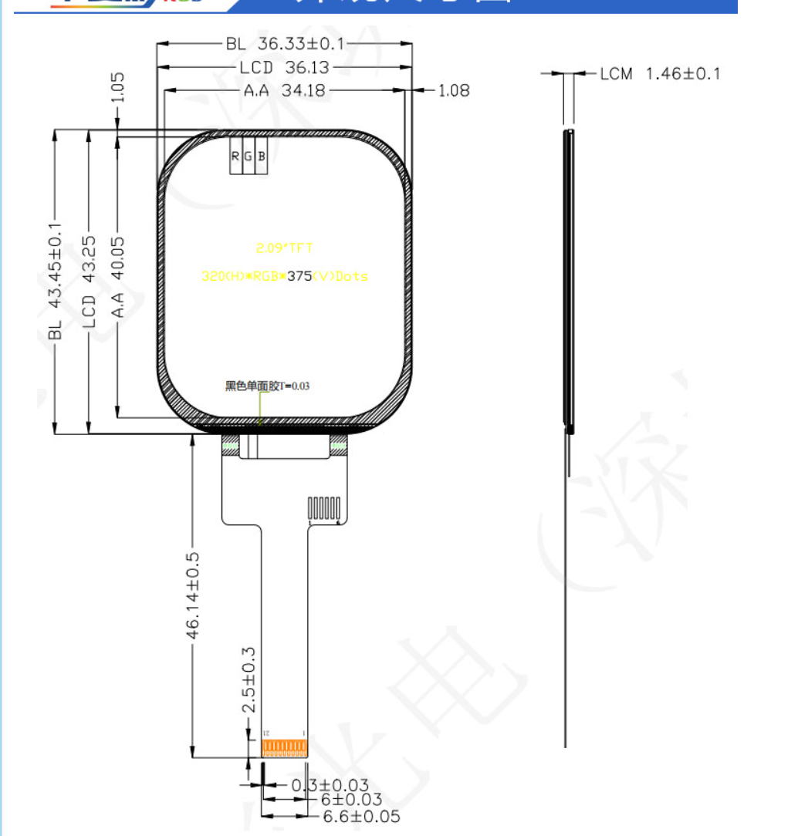
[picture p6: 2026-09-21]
mechanical/display-fit/reference/lcd-dimensions.png

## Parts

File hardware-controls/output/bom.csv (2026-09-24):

Reference | Value | Footprint | Description | Datasheet
U1 | AT42QT2120-MMHR | QT2120_VQFN20 | 3-channel wheel / I2C address 0x1C | https://ww1.microchip.com/downloads/en/devicedoc/doc9634.pdf
R1 | 10k | R0402 | 1% 0402 electrode series resistor
R2 | 10k | R0402 | 1% 0402 electrode series resistor
R3 | 10k | R0402 | 1% 0402 electrode series resistor
R4 | 4.7k | R0402 | Host-side 3.3 V pull-up; remove R4/R5 if host already supplies adequate I2C pull-ups
R5 | 4.7k | R0402 | Host-side 3.3 V pull-up; remove R4/R5 if host already supplies adequate I2C pull-ups
R6 | 10k | R0402 | Host-side 3.3 V pull-up; remove R4/R5 if host already supplies adequate I2C pull-ups
R7 | 10k | R0402 | Host-side 3.3 V pull-up; remove R4/R5 if host already supplies adequate I2C pull-ups
R8 | 22R | R0402 | Low-current RC supply filter
C1 | 100nF | C0402 | X7R 10 V, close to U1 VDD
C2 | 1uF | C0402 | X5R/X7R 10 V reservoir
SW1 | SKSWCEE010 | SKSW_3x2 | POWER / independent active-low key; local 10k pull-up to +3V3 | https://tech.alpsalpine.com/cms.media/product_catalog_ta_02_sksw_en_ee3e98d509.pdf
SW2 | SKSWCEE010 | SKSW_3x2 | BACK / active-low TCA6408A input; local 47k pull-up; firmware debounce required | https://tech.alpsalpine.com/cms.media/product_catalog_ta_02_sksw_en_ee3e98d509.pdf
SW3 | SKSWCEE010 | SKSW_3x2 | PREV / active-low TCA6408A input; local 47k pull-up; firmware debounce required | https://tech.alpsalpine.com/cms.media/product_catalog_ta_02_sksw_en_ee3e98d509.pdf
SW4 | SKSWCEE010 | SKSW_3x2 | NEXT / active-low TCA6408A input; local 47k pull-up; firmware debounce required | https://tech.alpsalpine.com/cms.media/product_catalog_ta_02_sksw_en_ee3e98d509.pdf
SW5 | SKSWCEE010 | SKSW_3x2 | PLAY / active-low TCA6408A input; local 47k pull-up; firmware debounce required | https://tech.alpsalpine.com/cms.media/product_catalog_ta_02_sksw_en_ee3e98d509.pdf
J1 | HC-FPC-05-10-12RLTAG | HCTL_FPC12 | 12 pin, 0.5 pitch, 0.3 FFC; tabs 13/14 GND; pins 7-10 NC; aligned with mainboard FPC1 | https://atta.szlcsc.com/upload/public/pdf/source/20221027/B2DE489DA152049D1F105170189CFB4E.pdf
R14 | 10k | R0402 | 1% 0402 independent POWER pull-up; released high, pressed low
U2 | TCA6408ARGTR | TCA6408A_VQFN16 | I2C 0x20; P0..P3 four keys; P4..P7 common pull-down, KEEP AS INPUTS | https://www.ti.com/lit/ds/symlink/tca6408a.pdf
R13 | 10k | R0402 | Shared pull-down for unused P4..P7; keep all four ports as inputs
R9 | 47k | R0402 | 1% 0402 local active-low key pull-up
R10 | 47k | R0402 | 1% 0402 local active-low key pull-up
R11 | 47k | R0402 | 1% 0402 local active-low key pull-up
R12 | 47k | R0402 | 1% 0402 local active-low key pull-up
C3 | 100nF | C0402 | X7R 10 V; U2 VCCI/VCCP bypass; both supplies on same 3.3 V rail
C4 | 100nF | C0402 | X7R 10 V; U2 VCCI/VCCP bypass; both supplies on same 3.3 V rail

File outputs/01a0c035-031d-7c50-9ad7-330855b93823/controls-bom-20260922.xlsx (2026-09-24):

型号 / 数值 | 位号 | KiCad 封装 | 单板数量 | LCSC 料号 | 规格说明
100nF | C1,C3,C4 | Controls:C0402 | 3 |  | 0402，X7R，10 V
1uF | C2 | Controls:C0402 | 1 |  | 0402，X5R/X7R，10 V
HC-FPC-05-10-12RLTAG | J1 | Controls:HCTL_FPC12 | 1 |  | 12P，0.5 mm 间距，下接点，排线端厚 0.3 mm
10k | R1,R2,R3,R6,R7,R13,R14 | Controls:R0402 | 7 |  | 0402，具体厂商料号待选
4.7k | R4,R5 | Controls:R0402 | 2 |  | 0402，I²C 上拉
22R | R8 | Controls:R0402 | 1 |  | 0402，电源滤波串联电阻
47k | R9,R10,R11,R12 | Controls:R0402 | 4 |  | 0402，机械按键上拉
SKSWCEE010 | SW1,SW2,SW3,SW4,SW5 | Controls:SKSW_3x2 | 5 |  | ALPS，3 × 2 mm 机械开关
AT42QT2120-MMHR | U1 | Controls:QT2120_VQFN20 | 1 |  | Microchip，VQFN-20，3 × 3 mm
TCA6408ARGTR | U2 | Controls:TCA6408A_VQFN16 | 1 |  | TI，VQFN-16，3 × 3 mm
 |  | 单板元件合计 | 26
LCSC 料号空白表示尚未选定采购编码，贴片下单时须完成物料匹配。
来源：controls.kicad_sch；已逐项核对当前 PCB。数量不含测试点、触摸电极及安装孔。
导出日期：2026-09-22。CSV 文件保留嘉立创常用字段名称。

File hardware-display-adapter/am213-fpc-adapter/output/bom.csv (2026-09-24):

Reference | Value | Footprint | Populate | Description
J2 | OK-23GF024-04 | OK23GF024 | YES | Top view: 1 upper left, 12 lower left, 13 lower right, 24 upper right; OSPTEK board photo
R1 | 22R | R0402 | YES | QSPI series damping; initial conservative low clock, tune on scope
R2 | 0R | R0402 | YES | QSPI series damping; initial conservative low clock, tune on scope
R3 | 0R | R0402 | YES | QSPI series damping; initial conservative low clock, tune on scope
R4 | 0R | R0402 | YES | QSPI series damping; initial conservative low clock, tune on scope
R5 | 0R | R0402 | YES | QSPI series damping; initial conservative low clock, tune on scope
R6 | 0R | R0402 | YES | QSPI series damping; initial conservative low clock, tune on scope
R7 | 0R | R0402 | YES | Factory reference feeds pin15 at3.3V; removable isolation link
R8 | 0R | R0402 | YES | Factory reference feeds pin16 at3.3V; removable isolation link
R9 | 100k | R0402 | YES | Default PMIC disable until ESP_IO46 asserts enable
R10 | 4.7k | R0402 | NO | Optional pull-up; host already has R46
R11 | 4.7k | R0402 | NO | Optional pull-up; host already has R45
C1 | 100nF | C0402 | YES | X5R/X7R 10V; C2 maximum assembled height <=0.8mm
C2 | 10uF | C0603 | YES | X5R/X7R 10V; C2 maximum assembled height <=0.8mm
C3 | 100nF | C0402 | YES | X5R/X7R 10V; C2 maximum assembled height <=0.8mm
C4 | 100nF | C0402 | YES | X5R/X7R 10V; C2 maximum assembled height <=0.8mm

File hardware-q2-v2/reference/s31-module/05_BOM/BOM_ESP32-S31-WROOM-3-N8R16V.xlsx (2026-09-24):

BOM_ESP32-S31-WROOM-3-N8R16V
Item | Quantity | Reference | Value | Package | ICs | Description | Manufacturer | Manufacturer Part # | Notes
1 | 1 | C1 | 24pF/50V(5%) only for reference | C0201 | Capacitor | MLCC, C0G(NP0), C0201, 24pF/50V(5%), Hmax0.33, -55℃~125℃ | Murata | GRM0335C1H240JA01D | Defined by RF Test
2 | 1 | C2 | 27pF/50V(5%) only for reference | C0201 | Capacitor | MLCC, C0G(NP0), C0201, 27pF/50V(5%), Hmax0.33, -55℃~125℃ | Murata | GRM0335C1H270JA01D | Defined by RF Test
3 | 4 | C5,C13,C16,C21 | 1uF/6.3V(20%) | C0201 | Capacitor | MLCC, X5R, C0201, 1uF/6.3V(20%), Hmax0.35, -55℃~85℃ | Murata | GRM033R60J105MEA2D
 |  |  | 1uF/6.3V(20%) | C0201 | Capacitor | MLCC, X5R, C0201, 1uF/6.3V(20%), Hmax0.35, -55℃~85℃ | Samsung | CL03A105MQ3CSNH
 |  |  | 1uF/6.3V(20%) | C0201 | Capacitor | MLCC, X5R, C0201, 1uF/6.3V(20%), Hmax0.35, -55℃~85℃ | Yageo | CC0201MRX5R5BB105
4 | 1 | C6 | 10nF/10V(10%) | C0201 | Capacitor | MLCC, X7R, C0201, 10nF/10V(10%), Hmax0.33, -55℃~125℃ | Murata | GRM033R71A103KA01D
 |  |  | 10nF/10V(10%) | C0201 | Capacitor | MLCC, X7R, C0201, 10nF/10V(10%), Hmax0.33, -55℃~125℃ | Yageo | CC0201KRX7R6BB103
 |  |  | 10nF/10V(10%) | C0201 | Capacitor | MLCC, X7R, C0201, 10nF/10V(10%), Hmax0.33, -55℃~125℃ | EYANG | C0201X7R103K100NTA
5 | 1 | C11 | 0.47uF/6.3V(10%) | C0402 | Capacitor | MLCC, X5R, C0402, 0.47uF/6.3V(10%), Hmax0.55, -55℃~ 85℃ | Samsung | CL05A474KQ5NNNC
 |  |  | 0.47uF/6.3V(10%) | C0402 | Capacitor | MLCC, X5R, C0402, 0.47uF/6.3V(10%), Hmax0.55, -55℃~ 85℃ | Murata | GRM155R60J474KE19J
 |  |  | 0.47uF/6.3V(10%) | C0402 | Capacitor | MLCC, X5R, C0402, 0.47uF/6.3V(10%), Hmax0.55, -55℃~ 85℃ | Yageo | CC0402KRX5R5BB474
6 | 10 | C12,C14,C17,C18,C19,C20,C22,C23,C24,C25 | 0.1uF/6.3V(10%) | C0201 | Capacitor | MLCC, X5R, C0201, 0.1uF/6.3V(10%), Hmax0.33, -55℃~85℃ | Murata | GRM033R60J104KE19D
 |  |  | 0.1uF/6.3V(10%) | C0201 | Capacitor | MLCC, X5R, C0201, 0.1uF/6.3V(10%), Hmax0.33, -55℃~85℃ | Samsung | CL03A104KQ3NNNC
 |  |  | 0.1uF/6.3V(10%) | C0201 | Capacitor | MLCC, X5R, C0201, 0.1uF/6.3V(10%), Hmax0.33, -55℃~85℃ | EYANG | C0201X5R104K6R3NTA
7 | 1 | C15 | 10uF/6.3V(20%) | C0402 | Capacitor | MLCC, X5R, C0402, 10uF/6.3V(20%), Hmax0.7, -55℃ ~ 85℃ | Samsung | CL05A106MQ5NUNC
 |  |  | 10uF/10V(20%) | C0402 | Capacitor | MLCC, X5R, C0402, 10uF/10V(20%), Hmax0.7, -55℃~85℃ | Murata | GRM155R61A106ME11D
 |  |  | 10uF/10V(20%) | C0402 | Capacitor | MLCC, X5R, C0402, 10uF/10V(20%), Hmax0.7, -55℃~85℃ | Yageo | CC0402MRX5R6BB106
8 | 1 | C3 | 1.2 ~ 1.8 pF only for reference | C0201 | Capacitor |  | Murata |  | Defined by RF Test
9 | 1 | L1 | 2.0 ~ 3.0 nH only for reference | L0201 | Inductor |  | Murata |  | Defined by RF Test
10 | 1 | C4 | 1.2 ~ 1.8 pF only for reference | C0201 | Capacitor |  | Murata |  | Defined by RF Test
11 | 1 | C7 | 1.5 ~ 1.2 pF only for reference | C0201 | Capacitor |  | Murata |  | Defined by RF Test
12 | 1 | L2 | 3.5 ~ 4.0 nH only for reference | L0201 | Inductor |  | Murata |  | Defined by RF Test
13 | 1 | C8 | TBD | C0201 | Capacitor |  | Murata |  | Defined by RF Test
14 | 1 | L5 | TBD | L0201 | Inductor |  | Murata |  | Defined by RF Test
15 | 1 | C9 | TBD | C0201 | Capacitor |  | Murata |  | Defined by RF Test
16 | 1 | D1 | ESD | SOD882 | Diode | ESD, Bidirectional, Vrwm=3.3V, Vbrmin=4.6V, Hmax0.55, Tj-40℃~125℃ | Bencent | BV-FA03ZCF
17 | 1 | L3 | 24nH(3%)_140mA only for reference | L0201 | Inductor | SMD Inductor, L0201, 24nH(3%)_140mA, 2.3R, Qmin12, Hmax0.33, -55℃~125℃ | Murata | LQP03TN24NH02D | Defined by RF Test
18 | 1 | L4 | 2.0nH(0.1nH)_600mA only for reference | L0201 | Inductor | SMD Inductor, L0201, 2.0nH(0.1nH)_600mA, 150mR, Qmin14, Hmax0.33, -55℃~125℃ | Murata | LQP03TN2N0B02D | Defined by RF Test
19 | 7 | R1,R2,R3,R4,R5,R8,R9 | 0(1%) | R0201 | Resistor | SMD Thick Film Resistor, R0201, 0(1%), 1/20W, Hmax0.26, -55℃~155℃ | UniOhm | 0201WMF0000TCE
 |  |  | 0(1%) | R0201 | Resistor | SMD Thick Film Resistor, R0201, 0(1%), 1/20W, Hmax0.26, -55℃~155℃ | UniOhm | 0201WMF0000TEE
 |  |  | 0(1%) | R0201 | Resistor | SMD Thick Film Resistor, R0201, 0(1%), 1/20W, Hmax0.26, -55℃~125℃ | YAGEO | RC0201FR-070RL
20 | 1 | R6 | 499(1%) | R0201 | Resistor | SMD Thick Film Resistor, R0201, 499(1%), 1/20W, Hmax0.26, -55℃~155℃ | UniOhm | 0201WMF4990TCE
 |  |  | 499(1%) | R0201 | Resistor | SMD Thick Film Resistor, R0201, 499(1%), 1/20W, Hmax0.26, -55℃~155℃ | UniOhm | 0201WMF4990TEE
 |  |  | 499(1%) | R0201 | Resistor | SMD Thick Film Resistor, R0201, 499(1%), 1/20W, Hmax0.26, -55℃~125℃ | YAGEO | RC0201FR-07499RL
21 | 1 | R10 | 10K(1%) | R0201 | Resistor | SMD Thick Film Resistor, R0201, 10K(1%), 1/20W, Hmax0.26, -55℃~155℃ | UniOhm | 0201WMF1002TCE
 |  |  | 10K(1%) | R0201 | Resistor | SMD Thick Film Resistor, R0201, 10K(1%), 1/20W, Hmax0.26, -55℃~155℃ | UniOhm | 0201WMF1002TEE
 |  |  | 10K(1%) | R0201 | Resistor | SMD Thick Film Resistor, R0201, 10K(1%), 1/20W, Hmax0.26, -55℃~125℃ | YAGEO | RC0201FR-0710KL
22 | 1 | U1 | ESP32-S31NRV16 | QFN80_0P35_8 | ESP ICs | MCU & 2.4 GHz Wi-Fi 6 & Bluetooth 5.4 (LE) & Bluetooth & Zigbee & Thread IC, dual core, embedded 1.8V 16 MB PSRAM, QFN80 8x8, Hmax0.9, -40°C~85°C | Espressif | ESP32-S31NRV16
23 | 1 | U2 | FLASH | SOP8_1P27_6P6 | Memory ICs | Serial NOR Flash, 64Mbit, Standard&Dual&Quad SPI, 2.3~3.6V, SOP8-208, Hmax2.16, -40°C~85°C | XMC | XM25QH64DHIQT
24 | 1 | Y1 | 40MHz | XTAL3225 | Clock | Crystal: 40MHz, 15pF, 10ppm, 3225, Hmax0.65, -40℃~85℃ | MDH | 2.3.3.400001552EL
25 | 1 | Shield Box | Shield Box | ShieldBox | Shield Box | ESP32-S31-WROOM-3 shield box, V1.1, 21 mm * 23 mm * 2.5 mm, Material: C7701R-H, T = 0.2 mm, Hole diameter 0.5 mm
26 | 1 | PCB | PCB | PCB | PCB | ESP32-S31-WROOM-3, V1.1, 4L, 22 mm * 30 mm * 1.0 mm, Halogen-free, Matte black for Solder mask and white for silkscreen, immersion gold and 50 Ω impedance control, 90 Ω differential impedance control
*Please be noted that C3, C4, C7, C8, C9, L1, L5 and L2 are recommended to use Murata for good quality and accuracy. Those values should be obtained after real RF tuning.
*Please see this link for RF tuning process: https://docs.espressif.com/projects/esp-hardware-design-guidelines/zh_CN/latest/esp32s31/schematic-checklist.html
*Please note that C1 and C2 varies with the actual PCB board. https://docs.espressif.com/projects/esp-hardware-design-guidelines/zh_CN/latest/esp32s31/schematic-checklist.html

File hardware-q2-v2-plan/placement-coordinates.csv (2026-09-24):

Ref | Value | Side | X_from_outline_mm | Y_from_outline_mm | Angle_deg | KiCad_X_mm | KiCad_Y_mm | Reason
C1 | 10uF | F | 38.573 | 52.124 | 180.0 | 167.441 | 119.771 | Existing relative placement retained
C10 | 10uF | F | 40.35 | 56.884 | 180.0 | 169.218 | 124.531 | Existing relative placement retained
C11 | 47nF | F | 32.0 | 58.5 | 0.0 | 160.868 | 126.147 | Local clearance refinement while keeping destination circuit close
C12 | 10uF | F | 30.902 | 55.553 | 0.0 | 159.77 | 123.2 | Existing relative placement retained
C13 | 100nF | F | 22.0 | 24.6 | 0.0 | 150.868 | 92.247 | Local Flash decoupling near pin 8; not a completed bare-chip VDD_SPI circuit
C14 | 1uF | F | 35.982 | 64.57 | 0.0 | 164.85 | 132.217 | Existing relative placement retained
C15 | 10uF | F | 37.1475 | 56.878 | 0.0 | 166.0155 | 124.525 | Existing relative placement retained
C16 | 47uF | F | 33.188 | 63.3 | -90.0 | 162.056 | 130.947 | Existing relative placement retained
C17 | 2.2uF | F | 3.14 | 52.251 | -90.0 | 132.008 | 119.898 | DAC local circuit retained: moving downward conflicts with motor carrier
C18 | 22uF | F | 4.918 | 49.0505 | -90.0 | 133.786 | 116.6975 | DAC local circuit retained: moving downward conflicts with motor carrier
C19 | 2.2uF | F | 4.918 | 52.251 | -90.0 | 133.786 | 119.898 | DAC local circuit retained: moving downward conflicts with motor carrier
C2 | 10uF | F | 35.497 | 46.0545 | 180.0 | 164.365 | 113.7015 | Existing relative placement retained
C20 | 2.2uF | F | 7.204 | 52.632 | 0.0 | 136.072 | 120.279 | DAC local circuit retained: moving downward conflicts with motor carrier
C21 | 2.2uF | F | 15.586 | 52.124 | 0.0 | 144.454 | 119.771 | DAC local circuit retained: moving downward conflicts with motor carrier
C22 | 2.2uF | F | 12.03 | 53.013 | -90.0 | 140.898 | 120.66 | DAC local circuit retained: moving downward conflicts with motor carrier
C23 | 2.2uF | F | 16.221 | 50.092 | 90.0 | 145.089 | 117.739 | DAC local circuit retained: moving downward conflicts with motor carrier
C24 | 2.2uF | F | 14.951 | 50.092 | -90.0 | 143.819 | 117.739 | DAC local circuit retained: moving downward conflicts with motor carrier
C25 | 2.2uF | F | 15.586 | 53.775 | 0.0 | 144.454 | 121.422 | DAC local circuit retained: moving downward conflicts with motor carrier
C26 | 4.7uF | F | 14.951 | 47.0695 | 90.0 | 143.819 | 114.7165 | DAC local circuit retained: moving downward conflicts with motor carrier
C27 | 100nF | F | 15.459 | 45.012 | 0.0 | 144.327 | 112.659 | DAC local circuit retained: moving downward conflicts with motor carrier
C28 | 100nF | F | 4.41 | 46.79 | 180.0 | 133.278 | 114.437 | DAC local circuit retained: moving downward conflicts with motor carrier
C29 | 100nF | F | 16.221 | 47.044 | 90.0 | 145.089 | 114.691 | DAC local circuit retained: moving downward conflicts with motor carrier
C3 | 100nF | B | 28.997 | 54.486 | 90.0 | 157.865 | 122.133 | Existing relative placement retained
C30 | 1uF | F | 21.262 | 52.413 | 0.0 | 150.13 | 120.06 | 1.8V audio LDO adjacent to DAC, separated from switching regulator
C31 | 1uF | F | 17.8 | 53.5 | -90.0 | 146.668 | 121.147 | Local clearance refinement while keeping destination circuit close
C32 | 10pF | F | 4.207 | 39.5255 | 180.0 | 133.075 | 107.1725 | DAC local circuit retained: moving downward conflicts with motor carrier
C33 | 10pF | F | 4.3725 | 45.483 | 180.0 | 133.2405 | 113.13 | DAC local circuit retained: moving downward conflicts with motor carrier
C34 | 100nF | F | 11.522 | 39.63 | 180.0 | 140.39 | 107.277 | Level translator between MCU corridor and DAC
C35 | 100nF | F | 22.19 | 41.408 | 180.0 | 151.058 | 109.055 | I2S translator between MCU corridor and DAC
C36 | 100nF | F | 20.92 | 64.57 | -90.0 | 149.788 | 132.217 | Existing relative placement retained
C37 | 100nF | F | 28.7 | 54.4 | 90.0 | 157.568 | 122.047 | Local clearance refinement while keeping destination circuit close
C38 | 100nF | F | 23.5 | 52.1 | 90.0 | 152.368 | 119.747 | Local clearance refinement while keeping destination circuit close
C39 | 1uF | B | 23.5 | 11.0 | -90.0 | 152.368 | 78.647 | Provisional core support on back; reassess after bare-chip pinout
C4 | 1uF | B | 33.5 | 62.0 | 0.0 | 162.368 | 129.647 | Motor driver grouped close to motor wire pads
C40 | 100nF | B | 24.0 | 15.0 | 90.0 | 152.868 | 82.647 | Provisional core support on back; reassess after bare-chip pinout
C41 | 1uF | B | 26.0 | 15.0 | 90.0 | 154.868 | 82.647 | Provisional core support on back; reassess after bare-chip pinout
C43 | 220nF | B | 37.938 | 50.155 | -90.0 | 166.806 | 117.802 | Battery gauge and local network closer to battery pads
C44 | 100nF | F | 25.5555 | 52.4265 | 0.0 | 154.4235 | 120.0735 | USB-UART bridge beside USB mux; avoids long differential pair branch
C45 | 100nF | B | 32.0 | 23.0 | -90.0 | 160.868 | 90.647 | Provisional core support on back; reassess after bare-chip pinout
C46 | 100nF | B | 34.0 | 23.0 | -90.0 | 162.868 | 90.647 | Provisional core support on back; reassess after bare-chip pinout
C47 | 100nF | F | 7.712 | 29.569 | -90.0 | 136.58 | 97.216 | Existing relative placement retained
C48 | 100nF | F | 6.4165 | 26.0635 | 0.0 | 135.2845 | 93.7105 | Existing relative placement retained
C49 | 10uF | B | 11.903 | 13.338 | -90.0 | 140.771 | 80.985 | Existing relative placement retained
C5 | 1uF | B | 42.0 | 59.8 | -90.0 | 170.868 | 127.447 | Motor driver grouped close to motor wire pads
C50 | 100nF | B | 13.1905 | 13.333 | -90.0 | 142.0585 | 80.98 | Existing relative placement retained
C51 | 100nF | F | 25.073 | 58.294 | 0.0 | 153.941 | 125.941 | USB-UART bridge beside USB mux; avoids long differential pair branch
C53 | 100nF | B | 30.2 | 43.3 | 90.0 | 159.068 | 110.947 | Local clearance refinement while keeping destination circuit close
C54 | 1uF | B | 31.3 | 45.3 | -90.0 | 160.168 | 112.947 | Local clearance refinement while keeping destination circuit close
C58 | 100nF | B | 39.5 | 59.1 | 180.0 | 168.368 | 126.747 | Local clearance refinement while keeping destination circuit close
C59 | 100nF | B | 23.917 | 46.8915 | 90.0 | 152.785 | 114.5385 | Existing relative placement retained
C6 | 100nF | B | 29.5765 | 47.6545 | 180.0 | 158.4445 | 115.3015 | Existing relative placement retained
C61 | 220nF | B | 36.414 | 47.564 | 90.0 | 165.282 | 115.211 | Battery gauge and local network closer to battery pads
C7 | 100nF | B | 32.4975 | 47.9085 | 0.0 | 161.3655 | 115.5555 | Existing relative placement retained
C8 | 22uF | F | 3.14 | 49.0505 | -90.0 | 132.008 | 116.6975 | DAC local circuit retained: moving downward conflicts with motor carrier
C9 | 4.7uF | F | 32.299 | 60.252 | 180.0 | 161.167 | 127.899 | Existing relative placement retained
CARD2 | TF PUSH | F | 10.699 | 14.763 | -90.0 | 139.567 | 82.41 | Locked enclosure/interface anchor
CN1 | PJ-342B-TX-SMT | F | 11.565 | 67.425 | 90.0 | 140.433 | 135.072 | Locked enclosure/interface anchor
CN2 | SOLDER_WIRES_3P | B | 43.653 | 52.632 | 90.0 | 172.521 | 120.279 | Locked original solder-pad positions; omit tall header, use insulated wires
CN3 | SOLDER_WIRES_2P | B | 43.78 | 66.856 | 90.0 | 172.648 | 134.503 | Locked original solder-pad positions; omit tall header, use insulated wires
D1 | USBLC6-2SC6 | B | 34.45 | 66.0 | 180.0 | 163.318 | 133.647 | USB ESD behind connector input pads; short paired vias before protected bus to mux
D2 | B5817W | F | 29.632 | 60.506 | 90.0 | 158.5 | 128.153 | Existing relative placement retained
FPC1 | HC-FPC-05-10-12RLTAG | B | 20.031 | 49.711 | -90.0 | 148.899 | 117.358 | Locked enclosure/interface anchor
JDISP1 | OK-23GF024-04 | F | 30.0 | 29.2 | 90.0 | 158.868 | 96.847 | Front BTB candidate; verify native screen tail folding and pin 1 before freeze
L1 | 2.2uH | F | 35.497 | 48.2135 | 0.0 | 164.365 | 115.8605 | Existing relative placement retained
L2 | 2.2uH | F | 33.696 | 56.315 | -90.0 | 162.564 | 123.962 | Existing relative placement retained
L3 | BLM18KG601SN1D | B | 42.0 | 57.8 | 0.0 | 170.868 | 125.447 | Motor driver grouped close to motor wire pads
R1 | 10mΩ | F | 43.526 | 46.663 | 90.0 | 172.394 | 114.31 | Existing relative placement retained
R10 | 10K | B | 29.5 | 36.0 | -90.0 | 158.368 | 103.647 | Pullups/pulldowns grouped by destination bus
R11 | 100K | F | 43.2435 | 62.085 | 180.0 | 172.1115 | 129.732 | Existing relative placement retained
R12 | 100K | F | 43.2435 | 63.355 | 180.0 | 172.1115 | 131.002 | Existing relative placement retained
R13 | 5K23 | F | 43.2435 | 59.545 | 180.0 | 172.1115 | 127.192 | Existing relative placement retained
R14 | 30K1 | F | 43.2435 | 58.275 | 180.0 | 172.1115 | 125.922 | Existing relative placement retained
R17 | 200K | F | 15.078 | 39.376 | 90.0 | 143.946 | 107.023 | Level translator between MCU corridor and DAC
R18 | 10K | F | 11.649 | 41.027 | 180.0 | 140.517 | 108.674 | Level translator between MCU corridor and DAC
R19 | 10K | F | 11.649 | 42.424 | 180.0 | 140.517 | 110.071 | Level translator between MCU corridor and DAC
R2 | 1K | B | 36.414 | 50.155 | 90.0 | 165.282 | 117.802 | Battery gauge and local network closer to battery pads
R20 | 10K | B | 34.0 | 20.0 | -90.0 | 162.868 | 87.647 | Provisional core support on back; reassess after bare-chip pinout
R21 | 100K | F | 25.873 | 60.76 | -90.0 | 154.741 | 128.407 | Existing relative placement retained
R22 | 10K | B | 28.0 | 36.0 | -90.0 | 156.868 | 103.647 | Pullups/pulldowns grouped by destination bus
R25 | 10K | B | 36.0 | 20.0 | -90.0 | 164.868 | 87.647 | Provisional core support on back; reassess after bare-chip pinout
R26 | 10K | B | 20.0 | 34.0 | 180.0 | 148.868 | 101.647 | Pullups/pulldowns grouped by destination bus
R27 | 0/NC | F | 28.7 | 51.2 | 0.0 | 157.568 | 118.847 | Local clearance refinement while keeping destination circuit close
R28 | 0/NC | F | 28.7 | 52.5 | 180.0 | 157.568 | 120.147 | Local clearance refinement while keeping destination circuit close
R29 | 10K | B | 22.0 | 11.0 | -90.0 | 150.868 | 78.647 | Provisional core support on back; reassess after bare-chip pinout
R3 | 22K1 | F | 41.3135 | 50.271 | 90.0 | 170.1815 | 117.918 | Existing relative placement retained
R30 | 10K | B | 22.0 | 34.0 | 180.0 | 150.868 | 101.647 | Pullups/pulldowns grouped by destination bus
R31 | 5K1 | F | 42.51 | 70.412 | -90.0 | 171.378 | 138.059 | Existing relative placement retained
R32 | 5K1 | F | 40.986 | 70.412 | -90.0 | 169.854 | 138.059 | Existing relative placement retained
R33 | 1K | B | 39.716 | 49.901 | -90.0 | 168.584 | 117.548 | Battery gauge and local network closer to battery pads
R34 | 0R | B | 41.113 | 49.901 | -90.0 | 169.981 | 117.548 | Battery gauge and local network closer to battery pads
R35 | 10K | B | 11.522 | 9.325 | 0.0 | 140.39 | 76.972 | Existing relative placement retained
R36 | 10K | B | 11.522 | 17.58 | 0.0 | 140.39 | 85.227 | Existing relative placement retained
R37 | 10K | B | 11.522 | 16.31 | 0.0 | 140.39 | 83.957 | Existing relative placement retained
R38 | 10K | B | 11.522 | 10.595 | 0.0 | 140.39 | 78.242 | Existing relative placement retained
R39 | 10K | B | 11.522 | 15.04 | 0.0 | 140.39 | 82.687 | Existing relative placement retained
R4 | 100K | F | 41.3135 | 47.9085 | 90.0 | 170.1815 | 115.5555 | Existing relative placement retained
R42 | 10K | B | 34.0 | 38.0 | 90.0 | 162.868 | 105.647 | Pullups/pulldowns grouped by destination bus
R43 | 10K | B | 38.0 | 38.0 | 0.0 | 166.868 | 105.647 | Pullups/pulldowns grouped by destination bus
R44 | 10K | B | 39.0 | 57.5 | 0.0 | 167.868 | 125.147 | Pullups/pulldowns grouped by destination bus
R45 | 10K | B | 34.0 | 33.5 | -90.0 | 162.868 | 101.147 | Pullups/pulldowns grouped by destination bus
R46 | 10K | B | 36.0 | 33.5 | -90.0 | 164.868 | 101.147 | Pullups/pulldowns grouped by destination bus
R5 | 100K | F | 38.573 | 46.155 | 0.0 | 167.441 | 113.802 | Existing relative placement retained
R6 | 10K | B | 36.0 | 38.0 | -90.0 | 164.868 | 105.647 | Pullups/pulldowns grouped by destination bus
R7 | 10K | B | 39.5 | 40.0 | -90.0 | 168.368 | 107.647 | Pullups/pulldowns grouped by destination bus
R8 | 10K | B | 41.0 | 40.0 | -90.0 | 169.868 | 107.647 | Pullups/pulldowns grouped by destination bus
R9 | 700R | F | 43.2435 | 60.815 | 180.0 | 172.1115 | 128.462 | Existing relative placement retained
SCREW1 |  | F | 3.3 | 63.4995 | 0.0 | 132.168 | 131.1465 | Locked enclosure/interface anchor
SCREW2 |  | F | 10.572 | 33.361 | 0.0 | 139.44 | 101.008 | Locked enclosure/interface anchor
SCREW3 |  | F | 44.499 | 41.499 | 0.0 | 173.367 | 109.146 | Locked enclosure/interface anchor
SCREW5 |  | F | 9.8075 | 2.7475 | 0.0 | 138.6755 | 70.3945 | Locked enclosure/interface anchor
U1 | RX8130CE:BB | B | 27.0 | 44.683 | 0.0 | 155.868 | 112.33 | RTC separate from switching power; I2C bus corridor
U10 | W25Q16JVSSIQ | F | 18.6 | 28.2 | -90.0 | 147.468 | 95.847 | Flash below-left of S31; clock pins toward core; boot flash capacity selection remains open
U11 | DRV2605LDGSR | B | 38.0 | 62.0 | 90.0 | 166.868 | 129.647 | Motor driver grouped close to motor wire pads
U12 | CH343P | F | 25.4 | 55.5005 | 180.0 | 154.268 | 123.1475 | USB-UART bridge beside USB mux; avoids long differential pair branch
U14 | STC3115AIQT | B | 38.954 | 47.107 | 0.0 | 167.822 | 114.754 | Battery gauge and local network closer to battery pads
U15 | LSM6DS3TR-C | F | 5.192 | 28.605 | 90.0 | 134.06 | 96.252 | Existing relative placement retained
U17 | SGM7229YMS10G/TR | F | 23.333 | 61.954 | 0.0 | 152.201 | 129.601 | Existing relative placement retained
U2 | CS43131-CNZ | F | 10.252 | 48.441 | 0.0 | 139.12 | 116.088 | DAC local circuit retained: moving downward conflicts with motor carrier
U3 | DSCB_BQ25895RTW | F | 38.0845 | 60.931 | 90.0 | 166.9525 | 128.578 | Existing relative placement retained
U4 | TLV62568DBVR | F | 38.799 | 49.1025 | 90.0 | 167.667 | 116.7495 | Existing relative placement retained
U5 | ME6211C18M5G-N | F | 20.5 | 50.0 | 0.0 | 149.368 | 117.647 | 1.8V audio LDO adjacent to DAC, separated from switching regulator
U6 | GEK100 | B | 26.127 | 53.14 | 90.0 | 154.995 | 120.787 | Existing relative placement retained
U7 | PCA9306DQER | F | 14.57 | 41.535 | -90.0 | 143.438 | 109.182 | Level translator between MCU corridor and DAC
U8 | SN74LV4T125RGYR | F | 20.8985 | 44.5365 | -90.0 | 149.7665 | 112.1835 | I2S translator between MCU corridor and DAC
USB1 | TYPE-C 16PIN 2MD(073) | F | 34.448 | 70.9455 | 0.0 | 163.316 | 138.5925 | Locked enclosure/interface anchor
X1 | 26MHz | F | 4.0425 | 42.5365 | -90.0 | 132.9105 | 110.1835 | DAC local circuit retained: moving downward conflicts with motor carrier

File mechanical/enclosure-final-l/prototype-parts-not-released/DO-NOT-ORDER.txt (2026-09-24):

L版AM213机械适配文件，单位mm。
尚未完成有源转接板、两端排线与实际固定，不是可装机生产包。
不能将“无名义干涉”理解为已经能连接/点亮屏幕。
先完成README.md列出的供电与连接器/FPC确认，再定版下单。

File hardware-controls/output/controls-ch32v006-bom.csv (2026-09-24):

Designator | Value | Footprint | Quantity
C1,C3 | 100nF | Controls:C0402 | 2
C2 | 1uF | Controls:C0402 | 1
J1 | HC-FPC-05-10-12RLTAG | Controls:HCTL_FPC12 | 1
R1-R3 | 1k | Controls:R0402 | 3
R4,R5 | 4.7k | Controls:R0402 | 2
R6,R7,R14 | 10k | Controls:R0402 | 3
R8 | 0R | Controls:R0402 | 1
R9-R12 | 47k | Controls:R0402 | 4
SW1-SW5 | SKSWCEE010 | Controls:SKSW_3x2 | 5
U1 | CH32V006F8U6 | Controls:CH32V006_QFN20 | 1

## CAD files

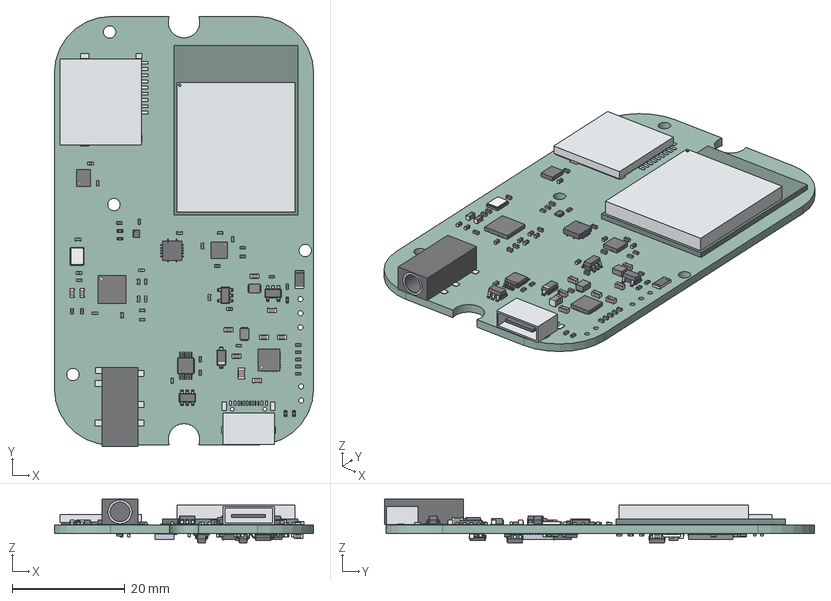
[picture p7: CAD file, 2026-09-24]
hardware-controls/mechanical/mainboard-layout-reference.step
46.0 x 76.3 x 7.73 mm
C_0603_1608Metric x 13
C_0402_1005Metric x 44
R_0402_1005Metric x 38
Pin1Marker x 5
Terminals x 12
Insulator
CardShell
AlignedPackage x 8
LGA_14_3x25mm_P05mm_LayoutBorder3x4y
QFN-40-1EP_5x5mm_Pitch0.4mm
Texas_RTW_WQFN-24-1EP_4x4mm_P0.5mm_EP2.7x2.7mm
R_1206_3216Metric x 2
ModulePCB
Shield
Crystal_SMD_3225-4Pin_3.2x2.5mm
D_SOD-123
SocketBody
MouthRim
MetalShell
ContactTongue
C_0805_2012Metric
L_0603_1608Metric
Housing
Latch x 2
Pin1
Pin2
Pin3
Pin4
Pin5
Pin6
Pin7
Pin8
Pin9
Pin10
Pin11
Pin12
Mount
Mount001
ConnectorHousing
main-layout-reference_PCB

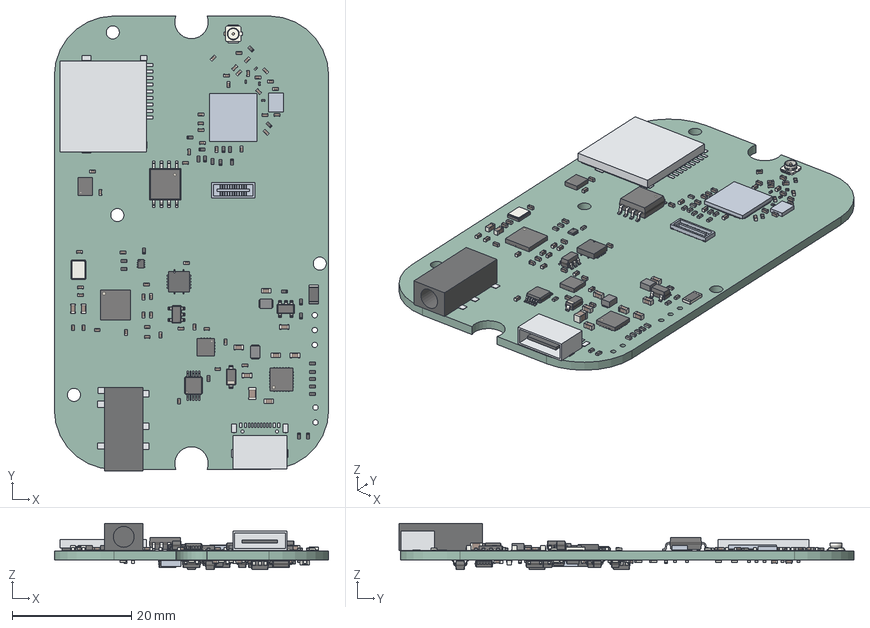
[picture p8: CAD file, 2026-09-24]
hardware-q2-v2/output/q2-v2-assembly.step
46.0 x 76.3 x 7.73 mm
C_0402_1005Metric x 72
L_0201_0603Metric x 4
R_0402_1005Metric x 62
C_0603_1608Metric x 9
Crystal_SMD_3225-4Pin_3.2x2.5mm
Insulator
CardShell
Terminals x 9
AlignedPackage x 7
Texas_RTW_WQFN-24-1EP_4x4mm_P0.5mm_EP2.7x2.7mm
QFN-40-1EP_5x5mm_Pitch0.4mm
C_0805_2012Metric
MetalShell
ContactTongue
U.FL_Hirose_U.FL-R-SMT-1_Vertical
Pin1Marker x 4
SOIC-8_5.3x5.3mm_P1.27mm
LGA_14_3x25mm_P05mm_LayoutBorder3x4y
D_SOD-123
SocketBody
MouthRim
R_1206_3216Metric
SOT-23-5
SOT-23 x 7
L_0603_1608Metric
VSSOP-8_2.3x2mm_P0.5mm
Housing
Latch
Pin1
Pin2
Pin3
Pin4
Pin5
Pin6
Pin7
Pin8
Pin9
Pin10
Pin11
Pin12
Mount
Mount001
q2-v2_PCB

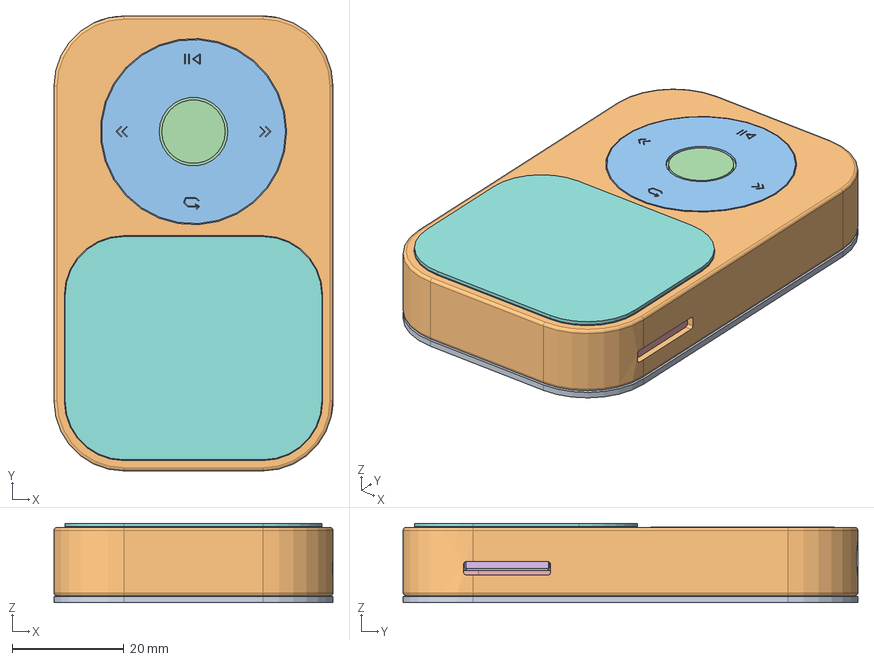
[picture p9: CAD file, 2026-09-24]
mechanical/enclosure-final-h/Q2_H_Reinforced_Assembly.step
50.0 x 81.5 x 14.2 mm
02 Rear cover / final board hole axes
01 Housing H / four reinforced controls bosses
WheelControlsA
CenterButtonControlsA
MainPCB
WheelCopper
C44 / C0402
C20 / C0402_1
C30 / C0402_1
C18 / C0603
X1 / CRYSTAL-SMD_4P-L3.2-W2.5-BL_1
C29 / C0402_1
C33 / C0402_1
R19 / R0402_1
R28 / R0402
C34 / C0402_1
C24 / C0402_1
CARD2 / TF-SMD_TF-PUSH
U5 / SOT-23-5_L3.0-W1.7-P0.95-LS2.8-BR_1
R9 / R0402
U3 / WQFN-24_L4.0-W4.0-P0.50-TL-EP2.7
C51 / C0402
C47 / C0402
U2 / QFN-40_L5.0-W5.0-P0.40-TL-EP3.6_1
U12 / TQFN-16_L3.0-W3.0-P0.50-BL-EP1.7
L2 / IND-SMD_L2.0-W1.6
U17 / MSOP-10_L3.0-W3.0-P0.50-LS4.9-BL
C16 / C0805
R17 / R0402_2
USB1 / USB-C-SMD_TYPE-C-16PIN-2MD-073
R31 / R0402
C11 / C0402
R18 / R0402_1
C15 / C0603_1
U7 / X2SON-8_L1.4-W1.0-P0.35-BL
R14 / R0402
C9 / C0603_1
U4 / SOT-23-5_L3.0-W1.7-P0.95-LS2.8-BR
C17 / C0402_1
R13 / R0402
R3 / R0402
C8 / C0603
C14 / C0603_1
C21 / C0402_1
U15 / LGA-14_L3.0-W2.5-P0.50-TL
R12 / R0402
C19 / C0402_1
C22 / C0402_1
C27 / C0402_1
C35 / C0402_1
C31 / C0402_1
C2 / C0603_1
C25 / C0402_1
R21 / R0402
R27 / R0402
C23 / C0402_1
R5 / R0402
U9 / CONN-SMD_ESP32-S31-WROOM-3
C48 / C0402
C32 / C0402_1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

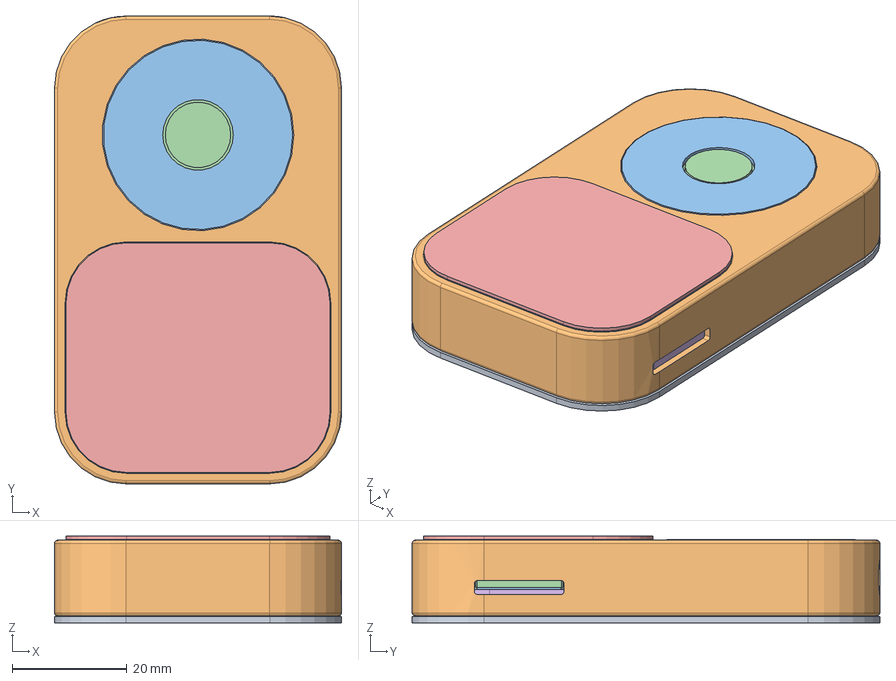
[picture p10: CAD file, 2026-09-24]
mechanical/enclosure-final-k/Q2_K_Assembly_Access.step
50.0 x 81.5 x 15.1 mm
02 Rear cover K / 1.0 mm screw bearing seat
01 Housing K / higher front / open assembly path
03 Wheel K / 1.0 mm rim / no carrier
04 Center key K / 1.0 mm rim / no carrier
05 Motor carrier / glue to right wall AFTER controls
MainPCB
C44 / C0402
C20 / C0402_1
C30 / C0402_1
C18 / C0603
X1 / CRYSTAL-SMD_4P-L3.2-W2.5-BL_1
C29 / C0402_1
C33 / C0402_1
R19 / R0402_1
R28 / R0402
C34 / C0402_1
C24 / C0402_1
CARD2 / TF-SMD_TF-PUSH
U5 / SOT-23-5_L3.0-W1.7-P0.95-LS2.8-BR_1
R9 / R0402
U3 / WQFN-24_L4.0-W4.0-P0.50-TL-EP2.7
C51 / C0402
C47 / C0402
U2 / QFN-40_L5.0-W5.0-P0.40-TL-EP3.6_1
U12 / TQFN-16_L3.0-W3.0-P0.50-BL-EP1.7
L2 / IND-SMD_L2.0-W1.6
U17 / MSOP-10_L3.0-W3.0-P0.50-LS4.9-BL
C16 / C0805
R17 / R0402_2
USB1 / USB-C-SMD_TYPE-C-16PIN-2MD-073
R31 / R0402
C11 / C0402
R18 / R0402_1
C15 / C0603_1
U7 / X2SON-8_L1.4-W1.0-P0.35-BL
R14 / R0402
C9 / C0603_1
U4 / SOT-23-5_L3.0-W1.7-P0.95-LS2.8-BR
C17 / C0402_1
R13 / R0402
R3 / R0402
C8 / C0603
C14 / C0603_1
C21 / C0402_1
U15 / LGA-14_L3.0-W2.5-P0.50-TL
R12 / R0402
C19 / C0402_1
C22 / C0402_1
C27 / C0402_1
C35 / C0402_1
C31 / C0402_1
C2 / C0603_1
C25 / C0402_1
R21 / R0402
R27 / R0402
C23 / C0402_1
R5 / R0402
U9 / CONN-SMD_ESP32-S31-WROOM-3
C48 / C0402
C32 / C0402_1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

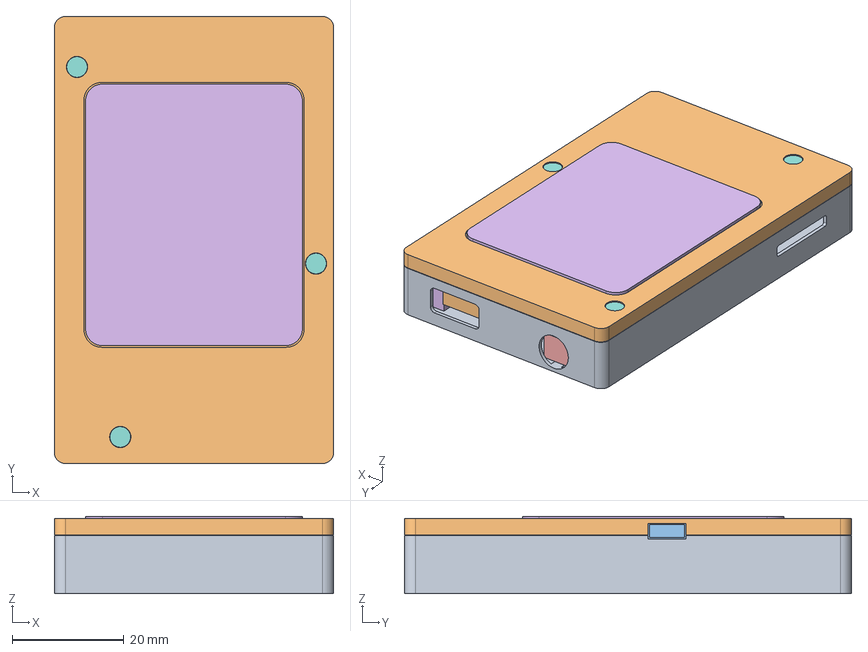
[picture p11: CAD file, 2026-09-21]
mechanical/enclosure/exports/assembly-reference.step
50.0 x 80.0 x 13.8 mm

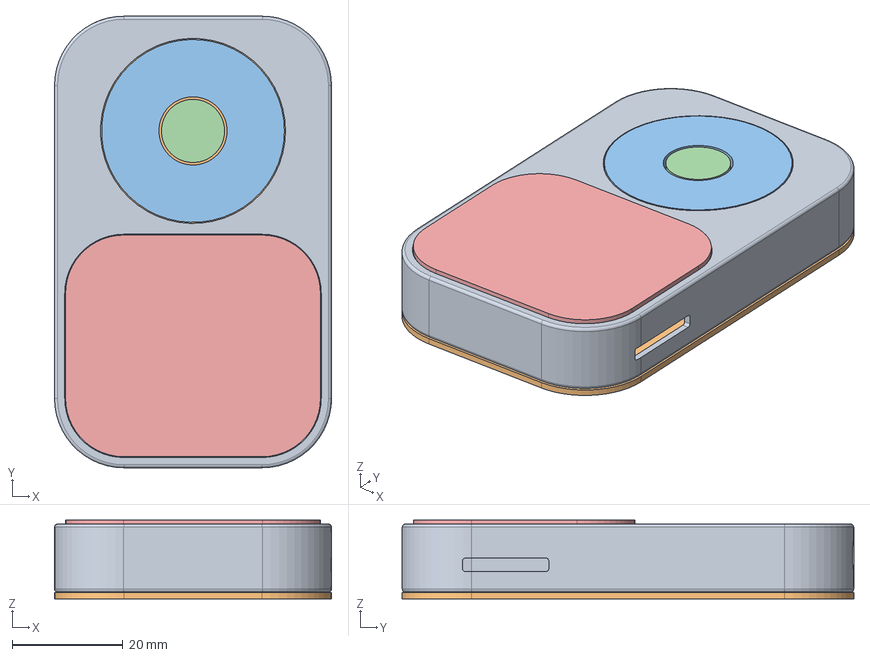
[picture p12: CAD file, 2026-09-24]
mechanical/appearance-prototype-v2/reference/assembled-appearance.step
50.0 x 81.5 x 14.2 mm
机身
后盖
圆环外观样件
中心键外观样件
屏幕外观占位片

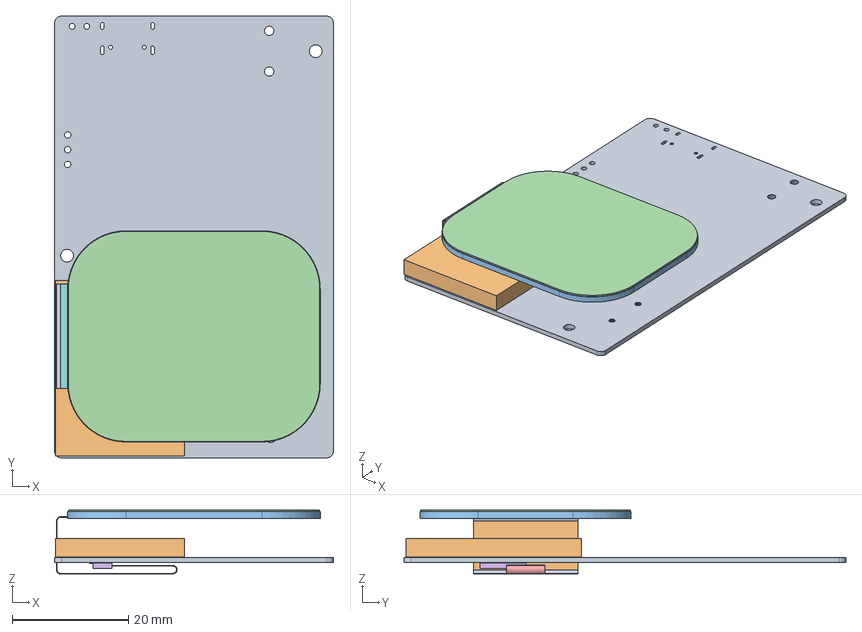
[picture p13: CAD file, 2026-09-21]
mechanical/display-fit/exports/current-assembly-NOT-MATED.step
48.0 x 76.0 x 11.0 mm

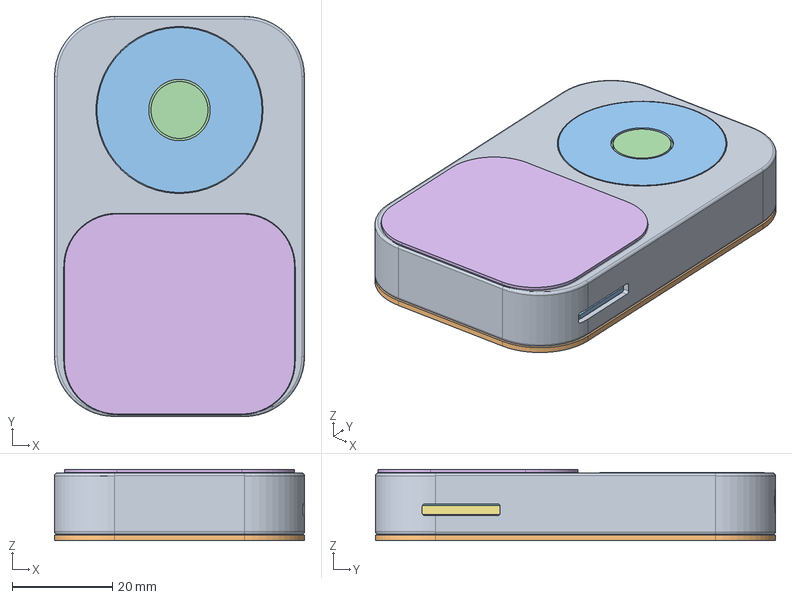
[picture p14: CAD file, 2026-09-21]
mechanical/enclosure-q2-e/exports/assembly-E-new-PCB.step
50.0 x 80.0 x 14.2 mm

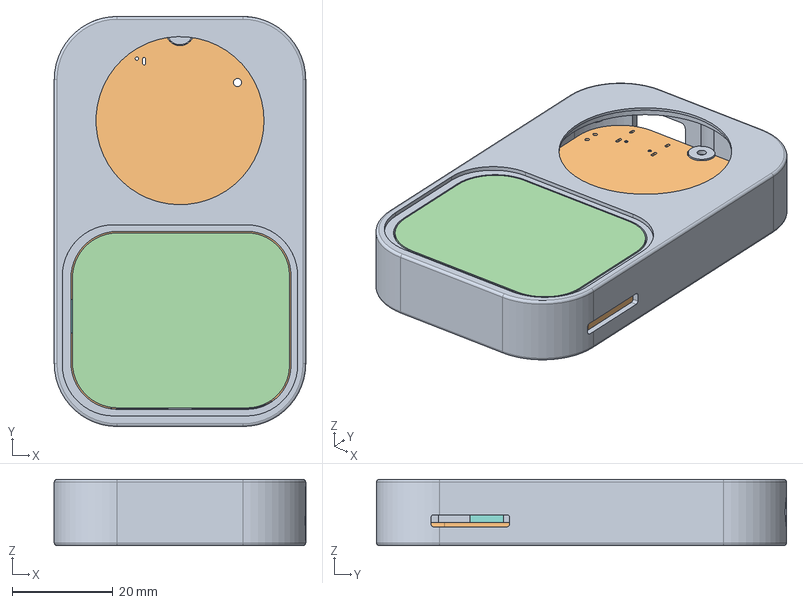
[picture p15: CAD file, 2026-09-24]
hardware-display-adapter/am213-fpc-adapter/models3d/Q2_L_AM213_Completed_Adapter.FCStd
50.0 x 81.5 x 13.2 mm
01 Housing L / AM213 integrated cover aperture
MainPCB
FPC2 / CONN-TH-21P_AFE03-S21FMA-1H
AM213 AMOLED panel / 43.14 x34.79 / stack excludes integral cover
AM213 folded rear FPC/components KEEP-OUT / conservative 1.52 mm / contour TBD
Adapter / 17x22 mm flex component island
FR4 stiffener + adhesive budget / 0.48 mm
70 mm folded flex / R0.8 candidate / do not crease
Insertion stiffener + adhesive / finished 0.20 mm tip
J2 / OK-23GF024-04
R1 / 22R
R2 / 0R
R3 / 0R
R4 / 0R
R5 / 0R
R6 / 0R
R7 / 0R
R8 / 0R
R9 / 100k
C1 / 100nF
C2 / 10uF
C3 / 100nF
C4 / 100nF

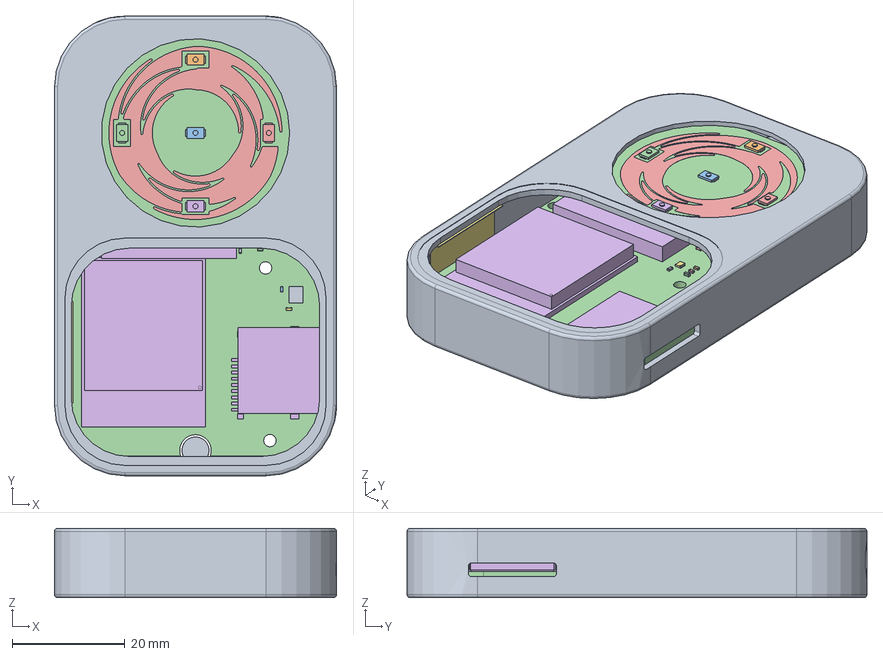
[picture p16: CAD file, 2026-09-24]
mechanical/final-board-review/Q2_Final_Mainboard_Assembly.FCStd
50.0 x 81.5 x 12.3 mm
HousingControlsA
SW5 / SKSWCEE010
SW1 / SKSWCEE010
SW4 / SKSWCEE010
SW3 / SKSWCEE010
SW2 / SKSWCEE010
U1 / AT42QT2120-MMHR
C3 / 100nF
R9 / 47k
R5 / 4.7k
U2 / TCA6408ARGTR
R4 / 4.7k
R7 / 10k
J1 / HC-FPC-05-10-12RLTAG
R13 / 10k
R2 / 10k
R14 / 10k
C4 / 100nF
R11 / 47k
R10 / 47k
R8 / 22R
C2 / 1uF
R6 / 10k
R3 / 10k
C1 / 100nF
R12 / 47k
R1 / 10k
ControlsBoard
WheelCopper
电池占位 / 主板正面与操作板之间，24 x 34 x 3
屏幕 FPC / 上移1.5 mm后的自然轴线，尚未插接
4 x M1.6 螺钉包络 / length and head TBD
Motor_C08_005
MotorHolderProposal
C44 / C0402
C20 / C0402_1
C30 / C0402_1
C18 / C0603
X1 / CRYSTAL-SMD_4P-L3.2-W2.5-BL_1
C29 / C0402_1
C33 / C0402_1
R19 / R0402_1
R28 / R0402
C34 / C0402_1
C24 / C0402_1
CARD2 / TF-SMD_TF-PUSH
U5 / SOT-23-5_L3.0-W1.7-P0.95-LS2.8-BR_1
R9 / R0402
U3 / WQFN-24_L4.0-W4.0-P0.50-TL-EP2.7
C51 / C0402
C47 / C0402
U2 / QFN-40_L5.0-W5.0-P0.40-TL-EP3.6_1
U12 / TQFN-16_L3.0-W3.0-P0.50-BL-EP1.7
L2 / IND-SMD_L2.0-W1.6
U17 / MSOP-10_L3.0-W3.0-P0.50-LS4.9-BL
C16 / C0805
R17 / R0402_2
USB1 / USB-C-SMD_TYPE-C-16PIN-2MD-073
R31 / R0402
C11 / C0402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

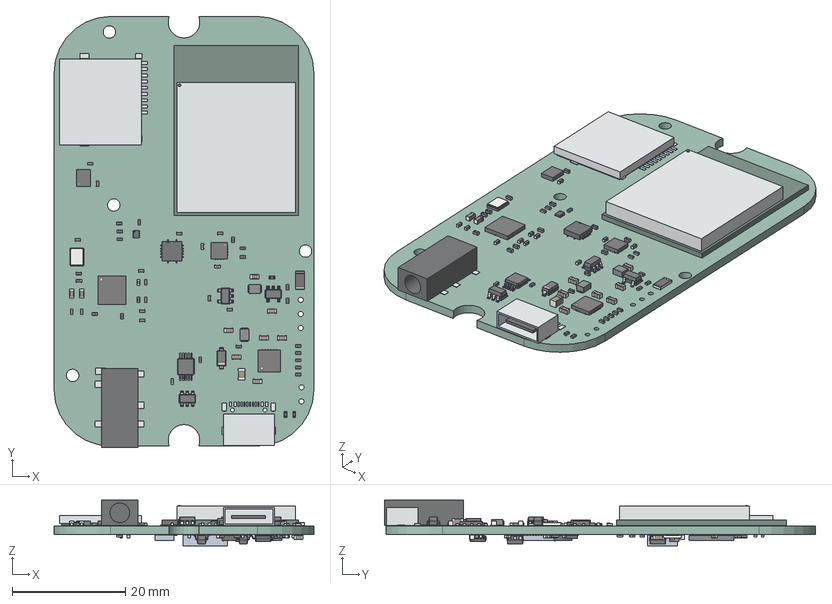
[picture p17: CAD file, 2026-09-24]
mechanical/final-board-review/mainboard-layout-reference.step
46.0 x 76.3 x 8.08 mm
C_0402_1005Metric x 45
C_0603_1608Metric x 13
Crystal_SMD_3225-4Pin_3.2x2.5mm
R_0402_1005Metric x 40
Insulator
CardShell
Terminals x 12
AlignedPackage x 8
Texas_RTW_WQFN-24-1EP_4x4mm_P0.5mm_EP2.7x2.7mm
QFN-40-1EP_5x5mm_Pitch0.4mm
C_0805_2012Metric
MetalShell
ContactTongue
Pin1Marker x 5
LGA_14_3x25mm_P05mm_LayoutBorder3x4y
ModulePCB
Shield
D_SOD-123
SocketBody
MouthRim
R_1206_3216Metric x 2
ConnectorHousing
Latch x 2
L_0603_1608Metric
Housing
Pin1
Pin2
Pin3
Pin4
Pin5
Pin6
Pin7
Pin8
Pin9
Pin10
Pin11
Pin12
Mount
Mount001
mainboard-model-reference_PCB

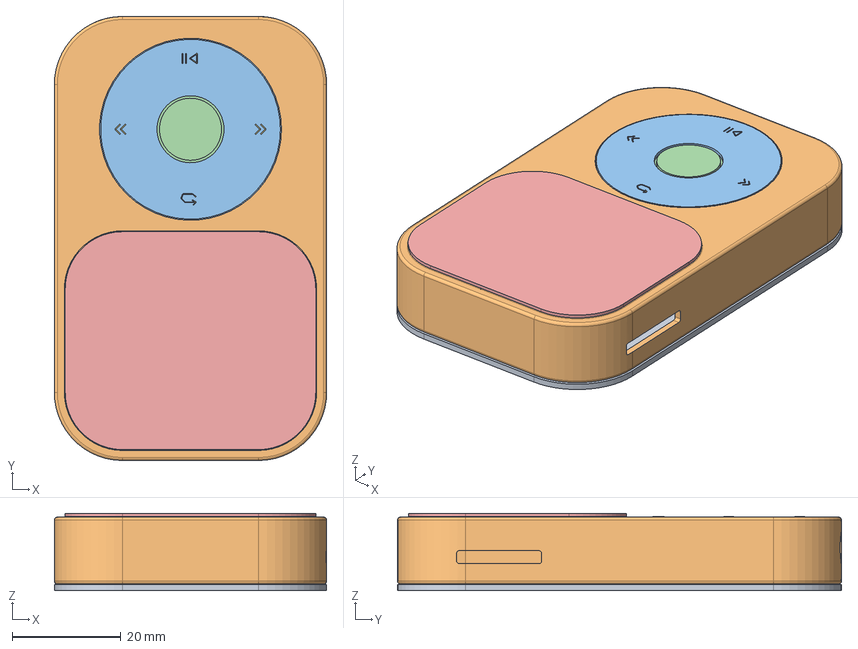
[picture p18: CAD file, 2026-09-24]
hardware-controls/mechanical/Q2_Controls_Assembly.FCStd
50.0 x 81.5 x 14.2 mm
Rear cover / local FFC inner-lip relief
HousingControlsA
WheelControlsA
CenterButtonControlsA
外加保护盖板 / 46 x 40 x 0.6 assumed, NOT supplied TP
盖板黑边示意 / silkscreen mask
按键图标 / return, previous, next, play-pause

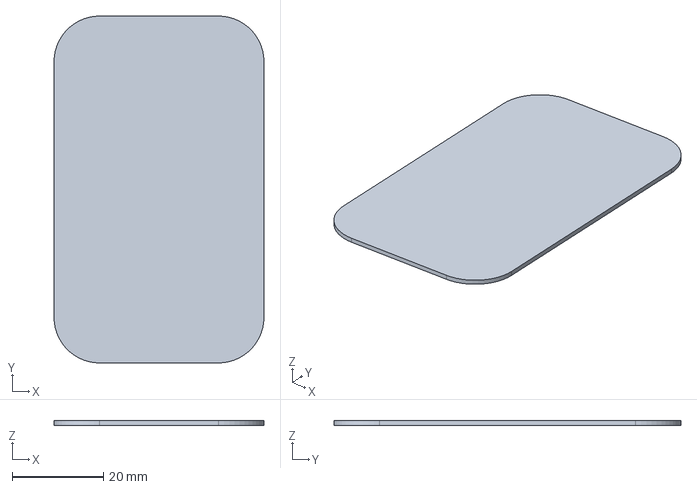
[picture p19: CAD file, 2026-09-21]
mechanical/enclosure-q2-f/exports/mainboard-reference-envelope.step
46.0 x 76.0 x 1.00 mm

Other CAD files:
mechanical/enclosure-final-i/Q2_I_Serviceable_Assembly.step
mechanical/enclosure-final-j/Q2_J_Glue_Insert_Assembly.step
mechanical/enclosure-final-g/Q2_G_Thin_Assembly.step
mechanical/enclosure-q2-d/exports/assembly-D-current-PCB-CONFLICTS.step
hardware-controls/mechanical/CenterButtonControlsA.step
hardware-controls/mechanical/HousingControlsA.step
hardware-controls/mechanical/RearCoverWithPCBPosts.step
hardware-controls/mechanical/RearCoverWithPCBPosts.stl
hardware-controls/mechanical/WheelControlsA.step
hardware-controls/models3d/CH32V006_QFN20.step
hardware-controls/models3d/FH19C_12.step
hardware-controls/models3d/QT2120_VQFN20.step
hardware-controls/models3d/SKSW_3x2.step
hardware-controls/models3d/TCA6408A_VQFN16.step
hardware-controls/output/ch32v006-review/before/models3d/FH19C_12.step
hardware-controls/output/ch32v006-review/before/models3d/QT2120_VQFN20.step
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

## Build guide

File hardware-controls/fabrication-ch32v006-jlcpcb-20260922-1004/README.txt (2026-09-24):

Q2 controls C / CH32V006F8U6 — 嘉立创裸板打样数据 — 2026-09-22 10:04 源文件检查批次

双层 FR-4，成品板厚 0.8 mm，外形 44 × 34 mm，四角 R10，外层铜厚 1 oz。
板框以 controls-Edge_Cuts.gm1 的线中心加工。
Gerber Job 的 44.05 × 34.05 mm 包含 0.05 mm 画线宽度，不是成品尺寸。
所有 Gerber 和 Excellon 钻孔为 mm、绝对原点、不镜像。
controls-PTH.drl：62 个 Ø0.30 mm 镀铜过孔。
controls-NPTH.drl：4 个 Ø1.80 mm 非金属化安装孔，不能改为镀铜孔。
顶部三组触摸电极保留阻焊覆盖，不开窗、不上锡；不要在电极背面额外增加铜皮。
保留设计中的 GND 覆铜和禁铺铜区域。表面处理及阻焊颜色按订单选项选择。

.gtl/.gbl：顶/底铜层；.gts/.gbs：顶/底阻焊开窗；.gto/.gbo：顶/底丝印。
.gtp/.gbp：顶/底钢网层，不是额外铜层；.gm1：板框。
本 ZIP 供裸板及钢网制造，不含贴片 BOM、坐标或固件。
新版 BOM 单独见 controls-ch32v006-bom.csv；不要混用 AT42/TCA 版生产文件。

来源：hardware-controls/controls.kicad_pcb
PCB SHA-256：cd4bda742ec32c2f2264107321cfdb04f1f52cd0723fc6afff2835a6e91183fe
KiCad 10.0.4 导出，重铺铜检查后 DRC 0、未连接 0、原理图一致性问题 0。
CH32 固件尚未实现；触摸参数、盖板与整机装配需实物验证。

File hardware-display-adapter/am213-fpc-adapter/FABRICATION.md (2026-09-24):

# AM213 A — FPC 制造审核与样板说明

用于双层柔性板工艺审核及首次样板。**不要按普通 1.6 mm 刚性 PCB 下单，也不要把 87×22 mm 外包矩形做成整板。** GM1/Edge.Cuts 是实际板框。

## 结构

- 元件岛 17×22 mm；左出尾巴 70 mm、主体宽 6.60 mm；根部最后 2 mm 扩展。
- 双层 PI 柔性体目标 **0.12 mm**，以 18µm 铜作初步供电估算。实际铜厚、PI、胶、覆盖膜和公差由 FPC 厂提供叠层；KiCad 总厚设置不是已批准叠层。
- F.Cu 信号/电源，B.Cu GND 回流；静态安装中心线 **R0.8 mm**，不得压死折。双层铜对应弯曲半径必须获板厂确认；改网格地或铜厚后须重查电气。
- 元件岛背面补强和胶预算 **0.48 mm**，含柔性体总厚 **≤0.60 mm**，支撑 BTB 插合力。
- 金手指适配 AFE03-S21FMA-1H：21P、0.30 mm 间距、宽 6.60 mm，成品插入厚 **0.20±0.03 mm**；背面补强直段 **≥3.5 mm**。模型直段 3.848 mm，补强不跨弯。
- F.Cu 金手指中心跨度 6.0 mm，指宽 0.20 mm，露铜长 2.20 mm、距切边 0.30 mm。**与插座配线图复核接触面、金手指、覆盖膜开窗和边缘公差。** F.Mask/B.Mask 仅表达开窗意图，不是经过板厂补偿的覆盖膜激光文件。
- 表面处理/金厚由板厂结合插接及细间距焊接要求确认，本包没有指定耐插拔寿命。
- 柔性跨距无过孔；插头补强区 1 个接地孔，其余孔在元件岛。根部现在为斜线扩展；板厂若要求圆角/泪滴，须回传改图复核，不改变针序及端点位置。

## DRC 工艺下限

| 项目 | mm |
|---|---:|
| 最小线宽 / 铜间距 | 0.10 / 0.10 |
| 常用信号线宽 | 0.12 |
| 电源两脚汇合后跨距线宽 | 0.44 |
| 常规过孔焊盘 / 孔 | 0.40 / 0.20 |
| 3 个接地小过孔焊盘 / 孔 | **0.30 / 0.15** |
| 最小环宽 | **0.075** |
| 孔到其他铜最小间距 | **0.175** |
| 铜到板边最小间距 | 0.15 |

均为两层贯通金属化孔，不是盲埋微孔。若厂商不支持，应修改设计后重出文件，不能仅选较粗工艺。复位扇出处有过孔靠近/进入信号焊盘开窗，板厂需检查塞孔/覆盖及焊料流失，DRC 不能保证焊接良率。

Gerber 和钻孔共用辅助原点 (50,50)，对应元件岛左上角。金手指位于负 X，不能让平台裁掉。J2 局部中心 (3,12)，1 脚左上，长轴 Y。

## 装配及首次上电

J2 为 OK-23GF024-04；J1 为金手指，不另装插座。R10/R11 **DNP**。R7/R8 默认 0Ω。C2 选 0603 10µF / 10V / X5R或X7R、实物高≤0.8 mm；还需核对偏压后容值。其余见 BOM。

1. 断电核对主板 FPC2 接触面、金手指 1 脚、锁扣、厚度、供电对地阻值和两端针号；旧 LEDA/LEDK 不接屏。
2. 限流上电，按屏厂 CO5300 初始化流程控制 VCI_EN、LCD_RST、TP_RST。初期 QSPI≤10MHz、不使用 TE，再按波形和稳定性提速。
3. 测屏端 VBAT/VDD/TP_VDD、最大亮度/大面积白屏电流及主板 3.3 V 余量。70 mm、0.44 mm、18µm 电源铜约 0.15Ω，另有插座、回流及焊点电阻；尚未验证最差工况。
4. 先 1:1 纸模，再试装柔性板、屏幕原生尾巴和 BTB。折弯模型只检查包络，不能验证锁扣、触点、公母插合公差。

本版 ERC、DRC、未连接和原理图一致性问题均为 0。报告随审核包提供，但不包含实测点亮/可靠性结论。

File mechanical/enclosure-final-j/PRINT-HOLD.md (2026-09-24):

# J 版：暂缓作为可装机样件加工

2026-09-23 最终复查发现：

1. 滑环、按键小板的现有装入路线会碰上壳内部结构；到位后零干涉不能证明可装入。
2. 止脱边 0.4～0.5 mm、工艺框连接桥 0.3 mm，以及部分紧固处薄壁需修改或工厂明确审核。
3. LCD 本体固定胶层/支撑尚未落实。

详见 `PREFLIGHT-REVIEW.md`。当前文件保留用于复现和改图，**不是已批准直接生产的装机版本**。若只做外观风险样件，须把上述情况提交工厂审核。

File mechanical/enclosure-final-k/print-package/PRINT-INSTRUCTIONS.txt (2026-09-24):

Q2 K / 单位 mm / 请勿缩放
01上壳、02后盖、03滑环、04中央键、05马达托座：每件1个。06螺母小样建议1个。
同名STEP/STL是同一零件的两种格式，二选一上传，不要重复下单。
五件全部使用K版，不与旧版混装；LCD盖板和电子件不打印。
韧性SLA树脂装机样件；局部最薄功能壁约0.85mm，须材料审核。
后盖螺母由用户冷胶粘接：M1.6，最大外径2.5，长3.0mm。孔径3.0mm。
按键小板：3颗M1.6×2.5头下长度，分别加0.3mm平垫。
马达托座必须在小板装好后粘接，主板后盖最后合装。完整步骤见README.md。
检查通过限于名义CAD及导出文件；不代表工厂接单批准或完成实物装机。

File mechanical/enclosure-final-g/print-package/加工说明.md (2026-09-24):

# Q2 G 树脂装机样件

单位：mm，按 1:1 导入，每件数量 1。选择韧性工程树脂；颜色自选。送印以下四件 STEP 或对应 STL，勿上传整机装配 STEP。

| 文件 | 外包尺寸约 mm | 说明 |
|---|---|---|
| 01-housing | 50 × 81.5 × 12.3 | 前机身，内含控制板柱和马达托座 |
| 02-rear-cover | 50 × 81.5 × 4.2 | 后盖，内含四个主板柱 |
| 03-wheel-with-carrier | 42 × 42 × 2.6 | 滑环带可剪除工艺框 |
| 04-center-with-carrier | 20 × 20 × 2.6 | 中央键带可剪除工艺框 |

工艺框通过两条 0.8 × 0.3 mm 细桥连接，打印清洗固化后用精细剪钳切断，修平残根；不要撬断止脱边。工艺框不是产品外观或装配的一部分。

工艺框增加薄件的外包厚度和搬运支撑，**不保证通过材料自动审查，也不改变功能薄边的真实厚度**。滑环止脱边约 0.4 mm、中央键止脱边约 0.3 mm、滑环面板约 0.85 mm。加工前请厂家确认这些薄边和工艺桥可成型；若材料不支持，应反馈调整，不得整体等比放大或擅自加厚按键面。

建议在非外观面布置支撑，避免屏幕台阶、按键滑动面、螺钉柱孔、USB/耳机/TF 开口和马达内孔。清除全部残留、完成后固化。螺纹孔为底孔，装配时手工攻牙，禁止热压嵌件。

该批为可装机验证样件，配合间隙、按键手感、触摸灵敏度、薄边强度与收缩量均需实物验证。电池与盖板不是打印件，完整装配限制见项目 README。

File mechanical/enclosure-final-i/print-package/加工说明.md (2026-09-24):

# Q2 I 装配优化版树脂装机样件

单位：mm，按 1:1 导入，每件数量 1。选择韧性工程树脂；颜色自选。送印以下四件 STEP 或对应 STL，勿上传整机装配 STEP。

| 文件 | 外包尺寸约 mm | 说明 |
|---|---|---|
| 01-housing | 50 × 81.5 × 12.3 | 前机身，含三个螺钉柱、一个封闭支撑柱、侧边限位台、排线槽及马达托座 |
| 02-rear-cover | 50 × 81.5 × 4.2 | 后盖，内含四个主板柱 |
| 03-wheel-with-carrier | 42 × 42 × 2.6 | 滑环带可剪除工艺框 |
| 04-center-with-carrier | 20 × 20 × 2.6 | 中央键带可剪除工艺框 |

工艺框通过两条 0.8 × 0.3 mm 细桥连接，打印清洗固化后用精细剪钳切断，修平残根；不要撬断止脱边。工艺框不是产品外观或装配的一部分。

工艺框增加薄件的外包厚度和搬运支撑，**不保证通过材料自动审查，也不改变功能薄边的真实厚度**。滑环止脱边约 0.5 mm、中央键止脱边约 0.4 mm、滑环面板约 0.85 mm。加工前请厂家确认这些薄边和工艺桥可成型；若材料不支持，应反馈调整，不得整体等比放大或擅自加厚按键面。

建议在非外观面布置支撑，避免屏幕台阶、按键滑动面、螺钉柱孔、USB/耳机/TF 开口和马达内孔。清除全部残留、完成后固化。螺纹孔为底孔，装配时手工攻牙，禁止热压嵌件。

该批为可装机验证样件，配合间隙、按键手感、触摸灵敏度、薄边强度与收缩量均需实物验证。电池与盖板不是打印件，完整装配限制见项目 README。

I 版小板仅三个 Ø1.3 mm 盲底孔，深 1.1 mm、孔顶剩余壁厚 0.5 mm；右上支撑柱封闭，不得钻穿。小板螺钉 M1.6 × 2（头下长度）必须各配 0.3 mm 平垫。侧边限位台按滑入结构使用，不可当弹性卡扣掰开。四个打印件均已更新，不能与 G/H 版混装。

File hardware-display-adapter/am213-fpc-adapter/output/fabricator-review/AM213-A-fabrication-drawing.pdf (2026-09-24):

# AM213 A / FLEX ADAPTER

Fabricator review / first prototype - NOT an approved flex stack

2026-09-23 | units: mm

TOP / component & contact face

J2 (3,12)

6.60 wide flex ribbon / no vias in free span

J1 pin 1: lower finger
21P / 0.30 pitch / F.Cu
1 upper-left; 24 upper-right 12 lower-left; 13 lower-right
70.00 tail to island edge | 17.00

3.50 min stiffener

22.00

### BACK-SIDE STIFFENERS (colored overlays; copper shown from top)

Blue: tip, x=-70 to -66.5; finished tip 0.20 +/-0.03; contact surface F.Cu.
Green: component island, x=0..17, y=0..22; flex + FR4 stiffener + adhesive <=0.60.
Flex body target 0.12; bending model R0.8. Fabricator must approve actual laminate and static bend.

### FAB REQUIREMENTS

2 copper layers; minimum trace/space 0.10/0.10; nominal signal trace 0.12; supply stripe 0.44. 39 PTH: pad 0.40 / drill 0.20; 3 GND PTH: pad 0.30 / drill 0.15; min annular ring 0.075.
Min drill-to-other-copper 0.175; copper-to-edge 0.15. No blind/buried vias.
Review pad-adjacent / via-in-pad solder loss; agree plugging/covering process before production. Confirm coverlay windows, connector finger drawing, plating and edge tolerances with AFE03 datasheet. Root uses chamfered flare. Return any proposed fillet/teardrop changes for electrical/mechanical review. Gerber + drill origin: island upper-left (KiCad 50,50). Do not clip negative-X ribbon.
See FABRICATION.md and BOM; R10/R11 DNP. Electrical ERC/DRC pass does not establish physical fit.

Sheet 1 / 1

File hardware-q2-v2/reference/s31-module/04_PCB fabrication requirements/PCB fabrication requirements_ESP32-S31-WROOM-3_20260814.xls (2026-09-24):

PCB加工工艺要求说明书 PCB Fabrication Requirements |  |  |  |  |  |  |  |  |  |  | I. 板料及叠层请按设计来，板材 FR-4 TG150 无卤。PP 型号如有更换，请邮件通知。防止波纹布显露，选用的 PP 材料 7628 的 RC 含量不要低于50%。 Material and Stackup follow the design.FR-4 TG150 Halogen Free, If the PP model is changed, please inform us via email.To avoid texure condition,the resin content of PP material 7628 should not be lower than 50%.
文件名： File Name: |  | ESP32-S31-WROOM-3 |  | 版本号： Version: |  | V1.2 | 物料名称： Material: | PCB |  |  | 叠层 Stackup | 材质 Material | 钻孔结构 Drilling | 基铜厚度 (oZ) Base copper | 各层厚度 (mil) Thickness | 介电常数 DK
PCB 加工要求： PCB Processing Requirements: |  |  |  |  |  |  |  |  |  |  | CM |  |  |  | 0.4 | 4
 |  |  |  |  |  |  |  |  |  |  | L1 | 成品铜厚 (Finished Copper) 1 oZ |  | 0.33 | 0.8
 |  |  |  |  |  |  |  |  |  |  | PP | S1150GB 1080 |  |  | 2.79 | 4.2
 |  |  |  |  |  |  | 附图 Attachment |  |  |  | L2 | 基铜 (Base copper) |  | 1 | 1.2
 | 1.数 量： Order Quantity： |  |  | 块 PCS |  |  | 12.交货日期： Delivery Date: |  |  |  |  | 芯板 (Core) |  |  | 27.56 | 4.6
 | 2.层 数： Number of Layers: |  |  |  |  |  |  |  |  |  | L3 | 基铜 (Base copper) |  | 1 | 1.2
 | 3.尺 寸： Dimension： |  | 22 |  | mm | 30 | mm |  | 详见 Gerber 文件尺寸 Refer to the Gerber file |  | PP | S1150GB 1080 |  |  | 2.79 | 4.2
 | 4.板 厚： Board Thickness： |  |  | 注意板厚要求 |  |  |  |  |  |  | L4 | 成品铜厚 (Finished Copper) 1 oZ |  | 0.33 | 0.8
 | 5.材 料： Material Type： |  |  |  | 其他材料： Other Material： |  |  |  |  |  | SM |  |  |  | 0.4 | 4
 | 6.铜箔厚度： Copper Thickness： |  | 内层 Inner-Layer |  | 外层 Outer-Layer |  | 13.表面涂层： Surface Finishing： |  |  |  | II. 下图所示高亮的走线需做阻抗控制。 Please do impedance control for trace that highlights in the image below.
 | 7.阻 焊： Solder Mask: |  |  |  | 颜 色： Color: | 油墨色号见颜色图表 | 14.加工厂商标记： Manufacturer's Marking：
 | 8.字 符： Silkscreen: |  |  |  | 颜 色： Color: |  | UL 标记 UL Marking |  |  |  | 1.下图 TOP 层高亮成黄色的 RF 走线需要做单端共面 50 欧姆阻抗控制。Please do 50ohm impedance control for RF trace that highlights in the image below.
 | 9.过孔处理方式： Through hole processing： |  |  |  |  |  | 制作日期 Manufature Date
 | 10.测 试： Test：
 | 11.设计软件及其版本： Software Version:
 | 15.交货方式： Delivery Type： |  |  | 1 | 单元/片 Unit/PCS | 拼板交货允许报废 Panelization allows scrap |  |  |  | PCS/SET
 | 16.其 他： Others:
 | 17.层次排列： Layer Sequence： |  | L1_TOP, L2_GND, L3_POWER, L4_BOTTOM
 |  |  |  |  |  |  |  |  |  |  |  | 17 mil 线宽: 参考 L3 的地 17 mil trace width: referred to L3
 |  |  |  |  |  |  |  |  |  |  |  |  |  |  | The traces highlighted in blue on the TOP, BOTTOM, and POWER layers in the figure below require 50-ohm single-ended non-coplanar impedance control.
 |  |  |  |  |  |  |  |  |  |  | 2.下图 TOP & BOTTOM & POWER 层高亮成蓝色的走线需要做单端非共面 50 欧姆阻抗控制。
 |  |  |  |  |  |  |  |  |  |  | 3.下图 TOP & BOTTOM 层高亮成白色的走线需要做差分共面 90 欧姆阻抗控制。The traces highlighted in white on the TOP and BOTTOM layers in the figure below require 90-ohm differential coplanar impedance control.

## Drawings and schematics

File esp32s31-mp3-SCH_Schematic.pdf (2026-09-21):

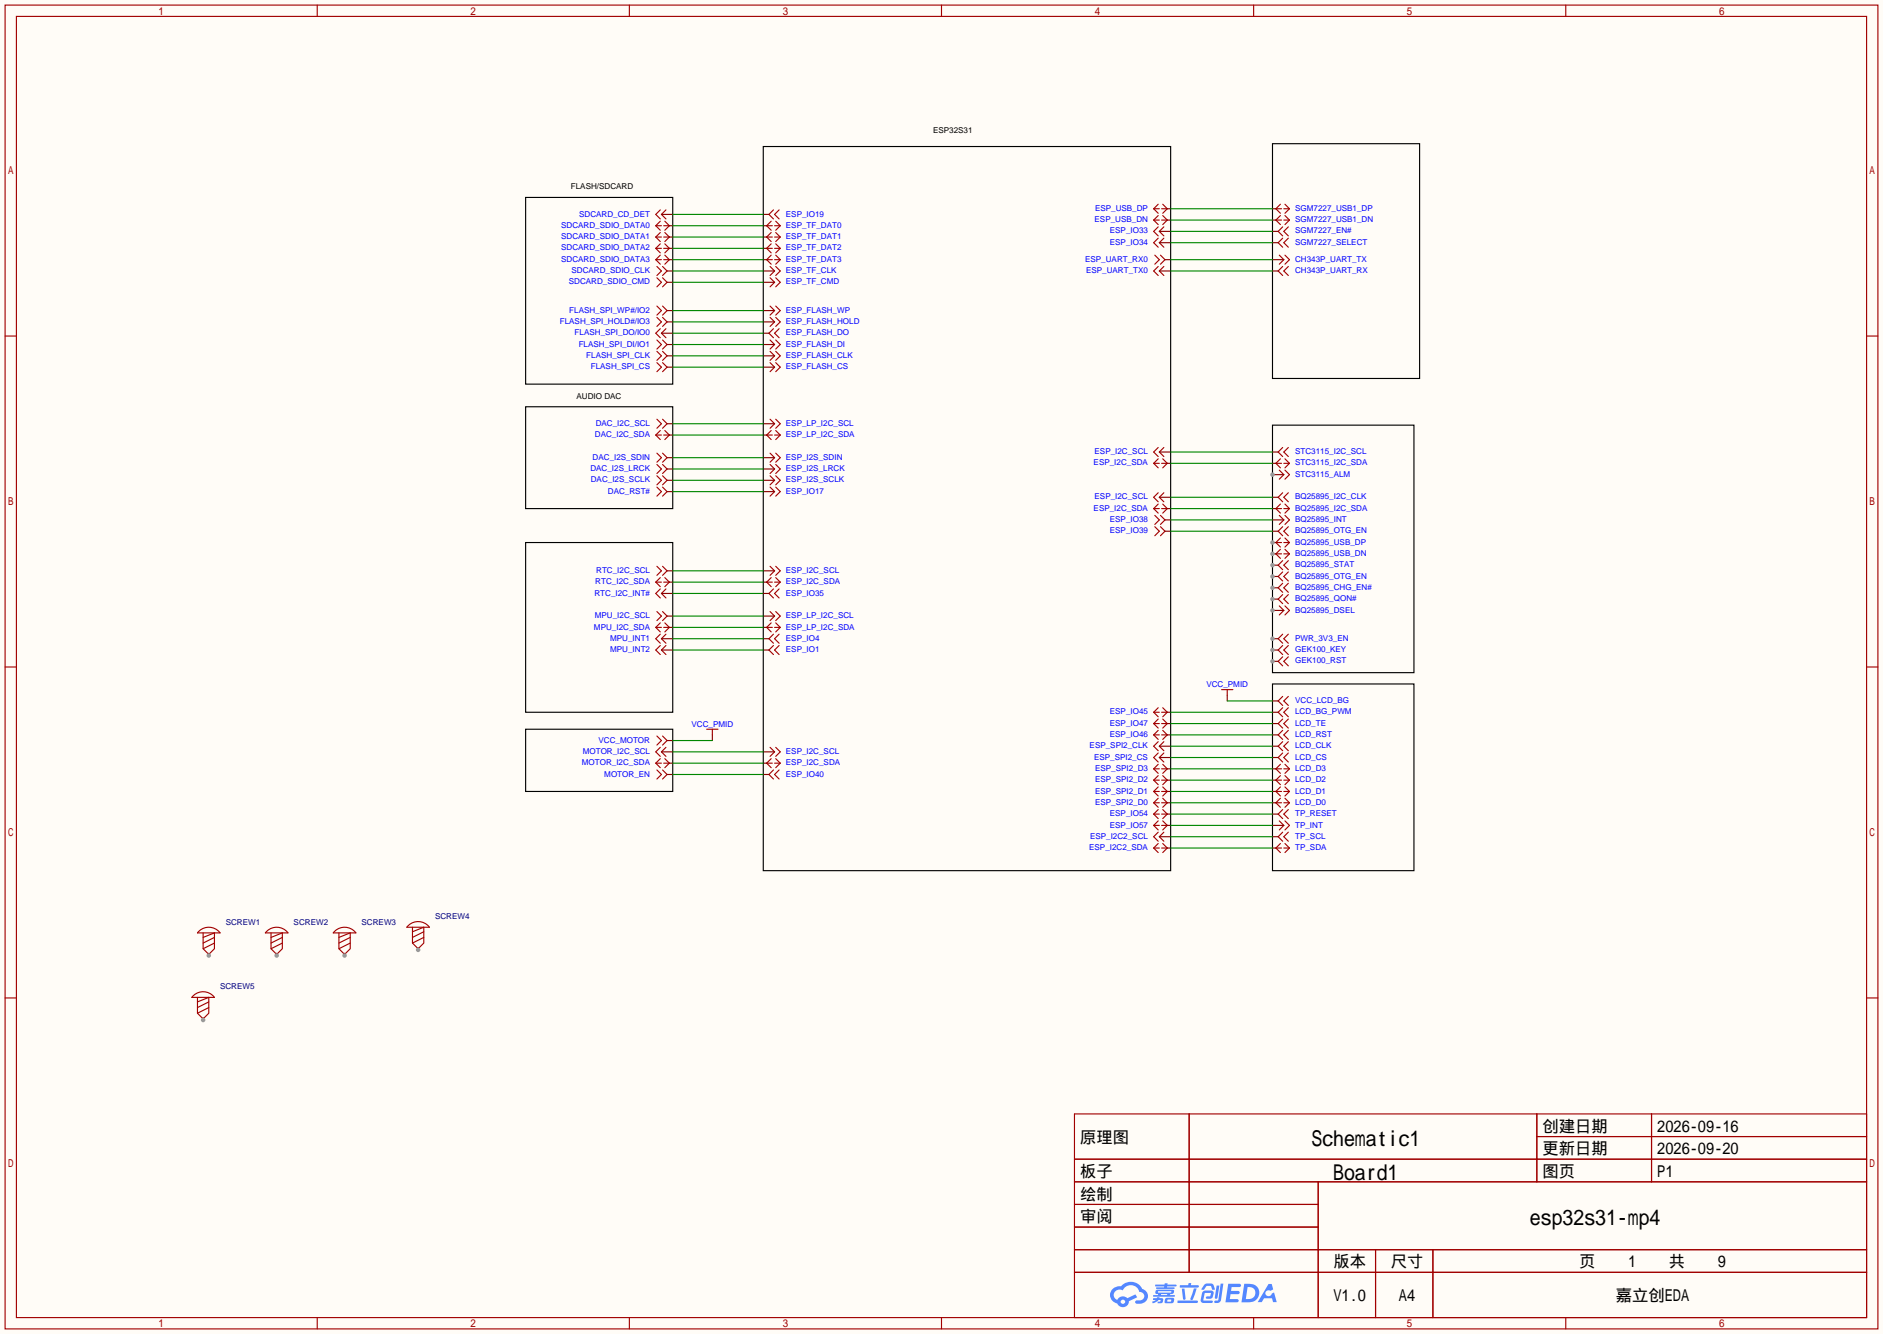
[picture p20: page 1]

原理图 | Schematic1 | 创建日期 | 2026-09-16

更新日期 | 2026-09-20

板子 | Board1 | 图页 | P1
绘制 | | esp32s31-mp4
审阅

V1.0 | A4 | 嘉立创EDA

IO39 50 IO40 51 IO42 52 IO43 53 IO44 54 IO45 55 IO46 56 IO47 57 IO48 58 IO49 59 IO50 60 IO51 61 IO52 62 IO53 63 IO54 64 IO55 65 IO56 66 IO57 67 TX0 68 RX0 69 IO60 70 IO61 71 GND 72 GND 73 GND 74 GND 75 GND 76 GND 77 GND 78 GND 79 GND 80 GND 81 GND 82 GND 83 GND 84 GND 85 GND 86 GND 87 GND 88 GND 89 GND 90 NC 91 GND 92 GND 93 GND 94 GND 95 GND 96 GND 97 GND 98 GND 99

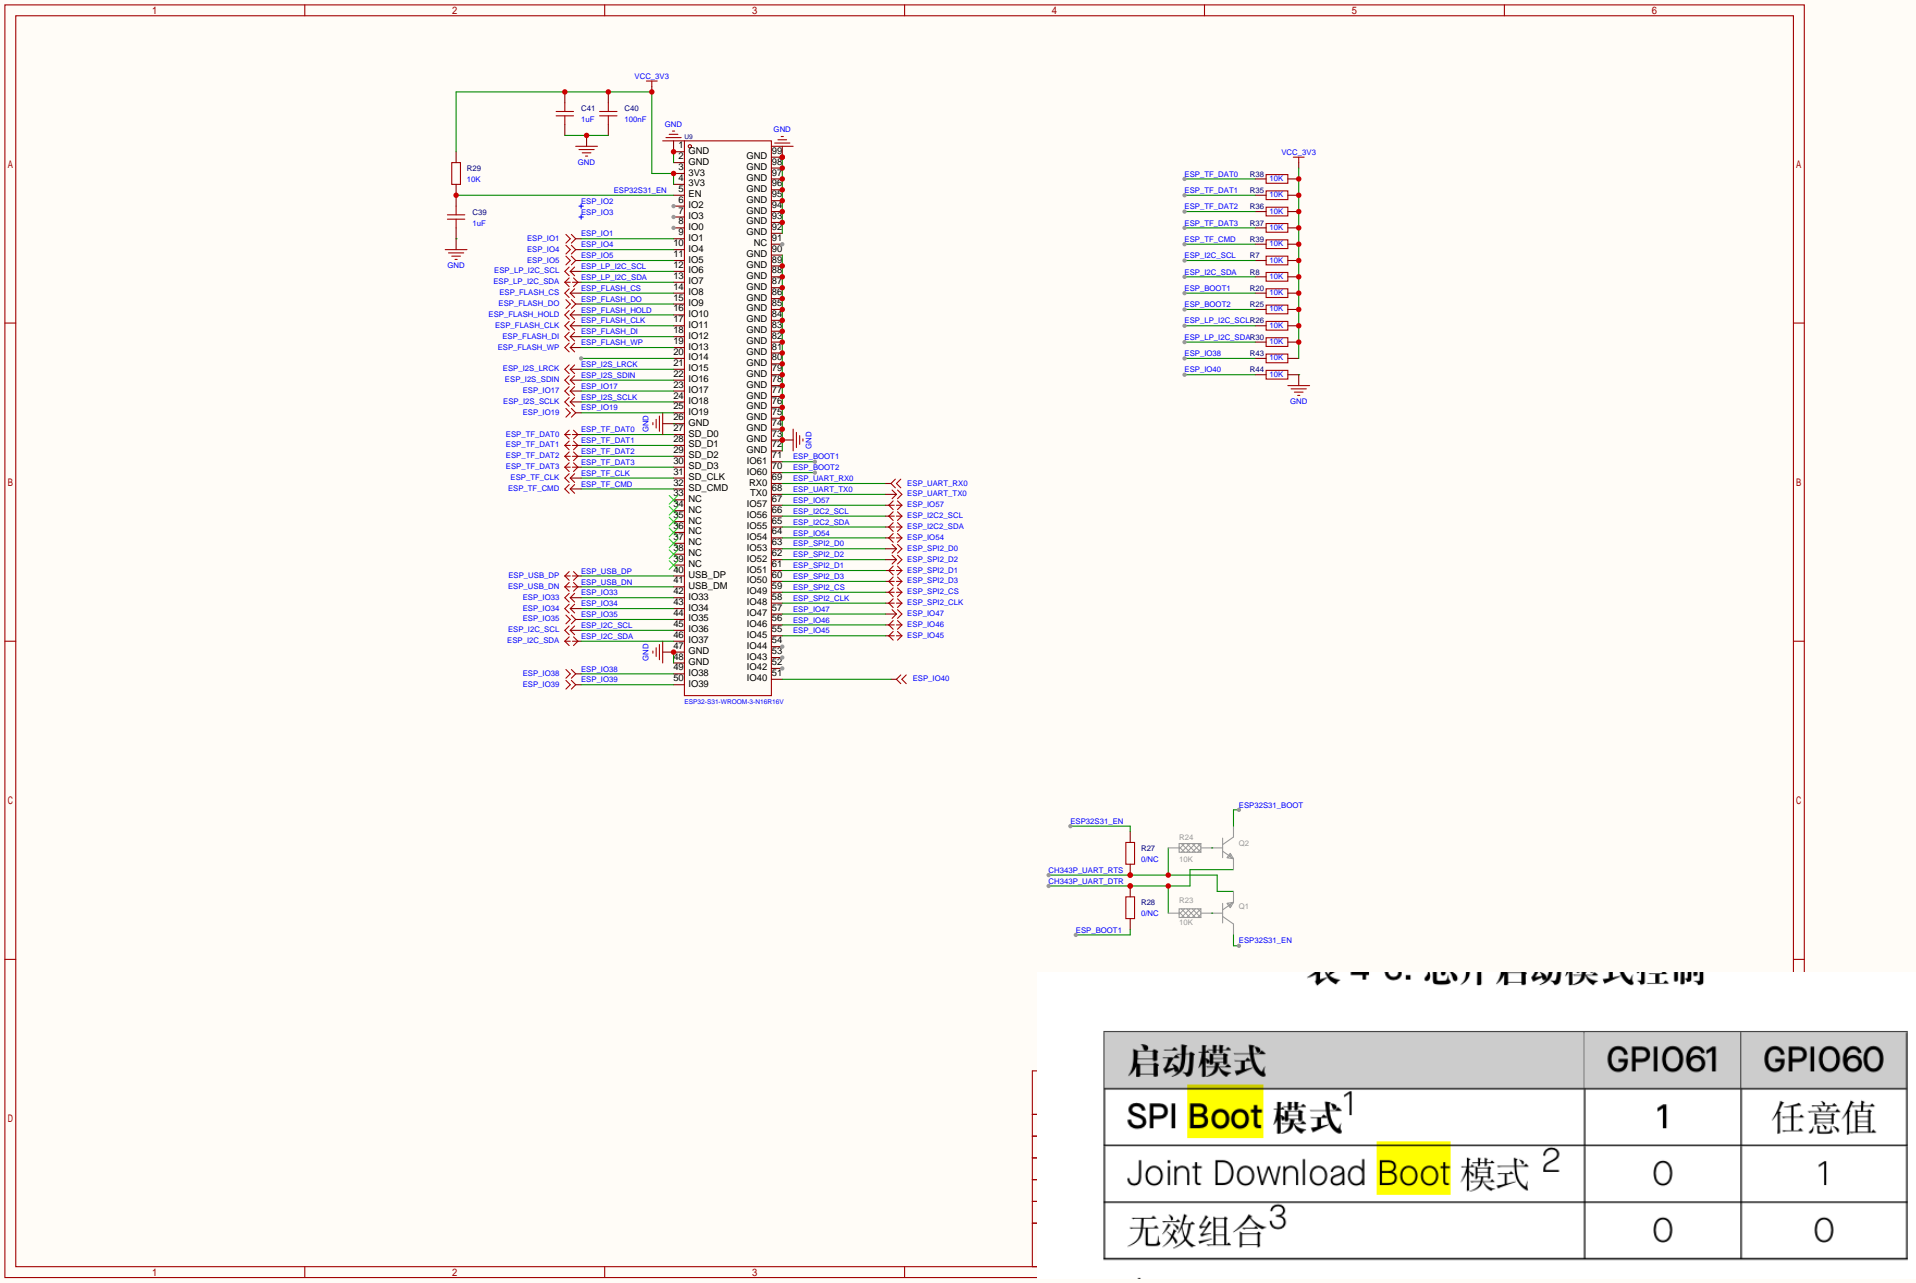
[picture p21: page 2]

原理图 | Schematic1 | 创建日期 | 2026-09-02

更新日期 | 2026-09-20

板子 | Board1 | 图页 | MCU
绘制 | | esp32s31-mp4
审阅

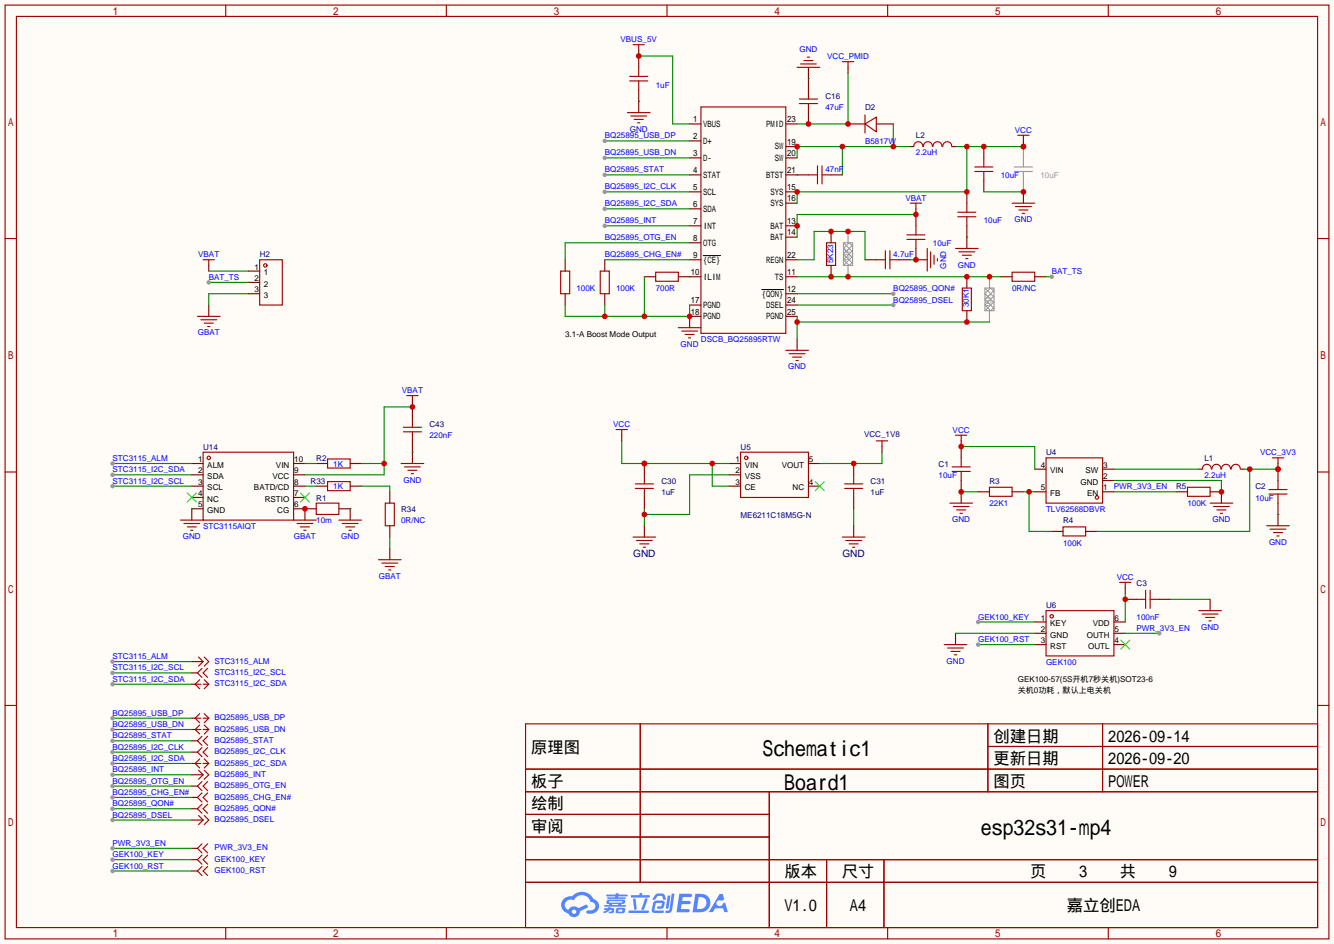
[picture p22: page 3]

原理图 | Schematic1 | 创建日期 | 2026-09-14

更新日期 | 2026-09-20

板子 | Board1 | 图页 | POWER
绘制 | | esp32s31-mp4
审阅

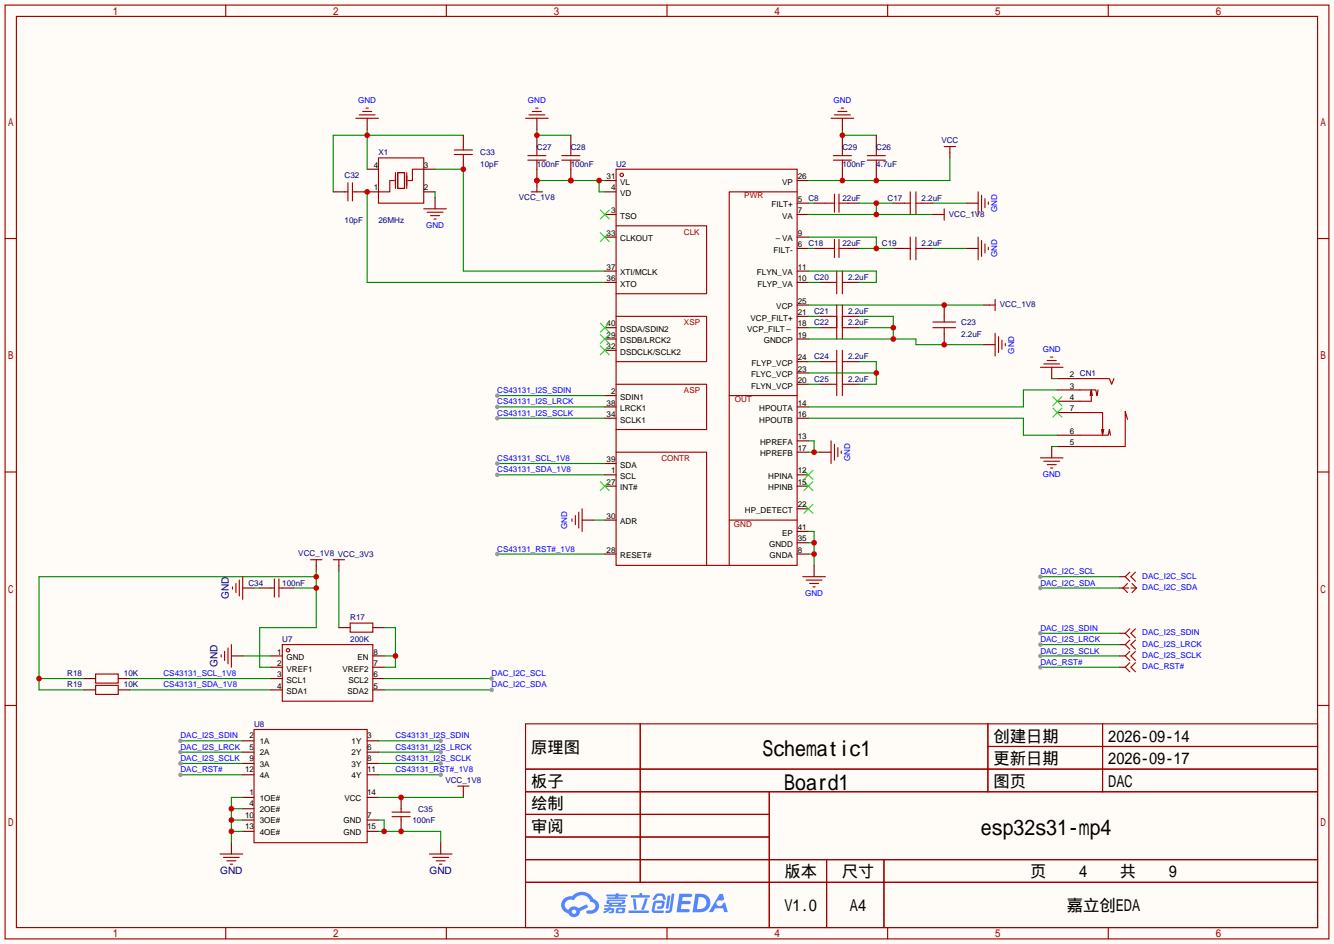
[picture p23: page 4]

原理图 | Schematic1 | 创建日期 | 2026-09-14

更新日期 | 2026-09-17

板子 | Board1 | 图页 | DAC
绘制 | | esp32s31-mp4
审阅

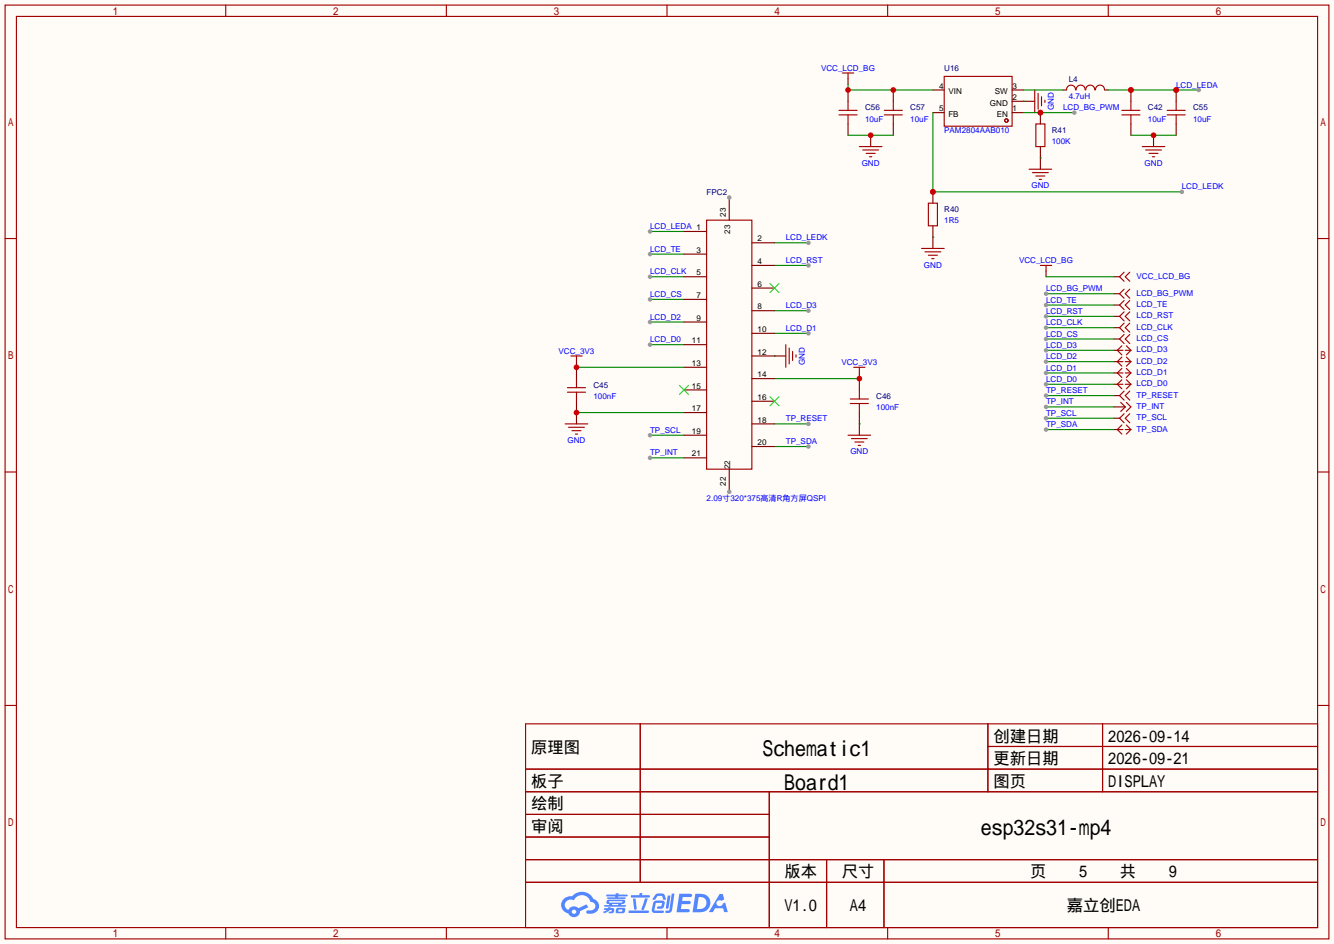
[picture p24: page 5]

原理图 | Schematic1 | 创建日期 | 2026-09-14

更新日期 | 2026-09-21

板子 | Board1 | 图页 | DISPLAY
绘制 | | esp32s31-mp4
审阅

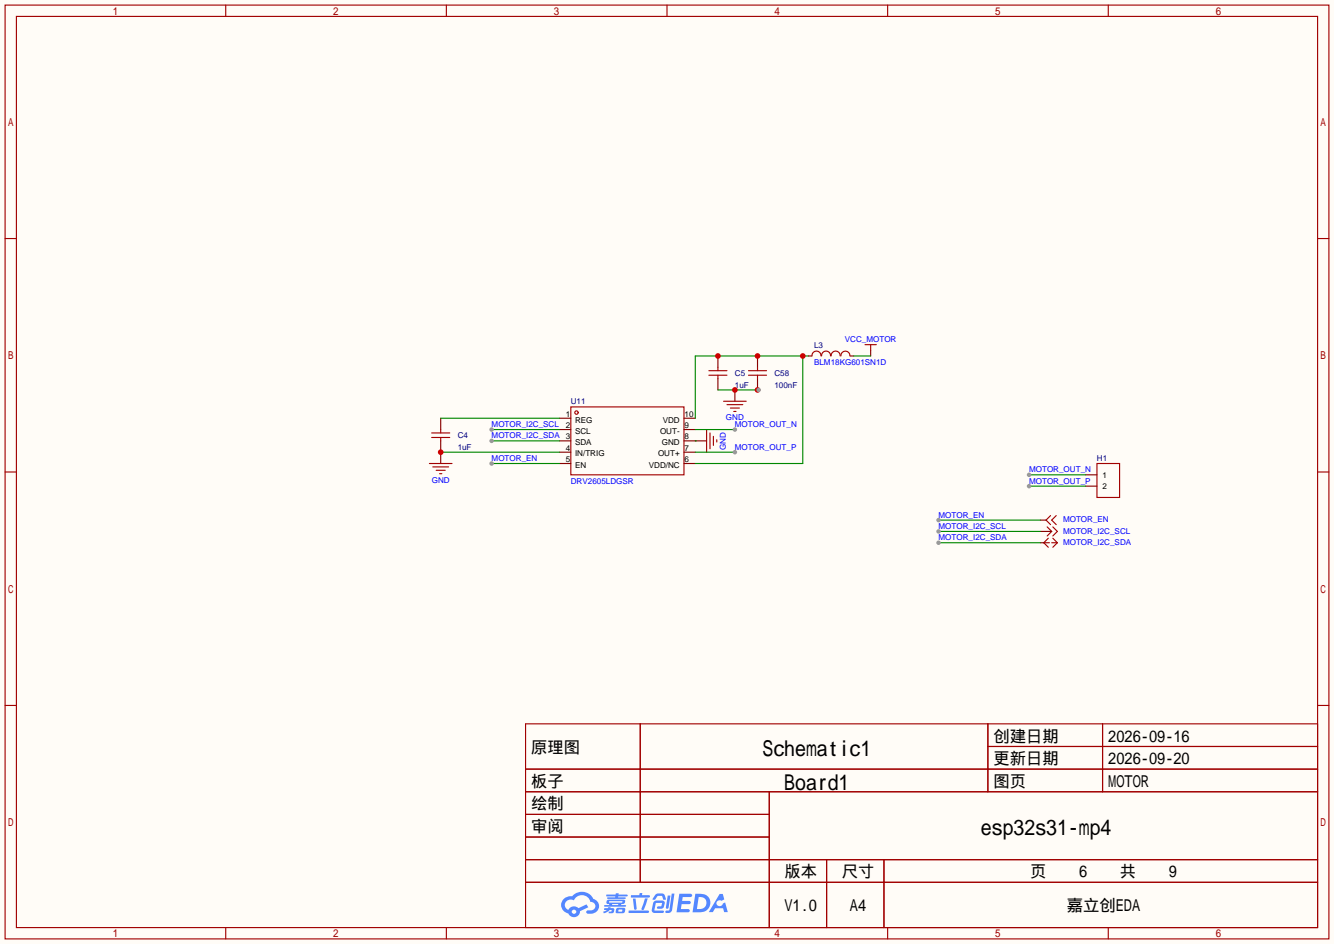
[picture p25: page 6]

原理图 | Schematic1 | 创建日期 | 2026-09-16

更新日期 | 2026-09-20

板子 | Board1 | 图页 | MOTOR
绘制 | | esp32s31-mp4
审阅

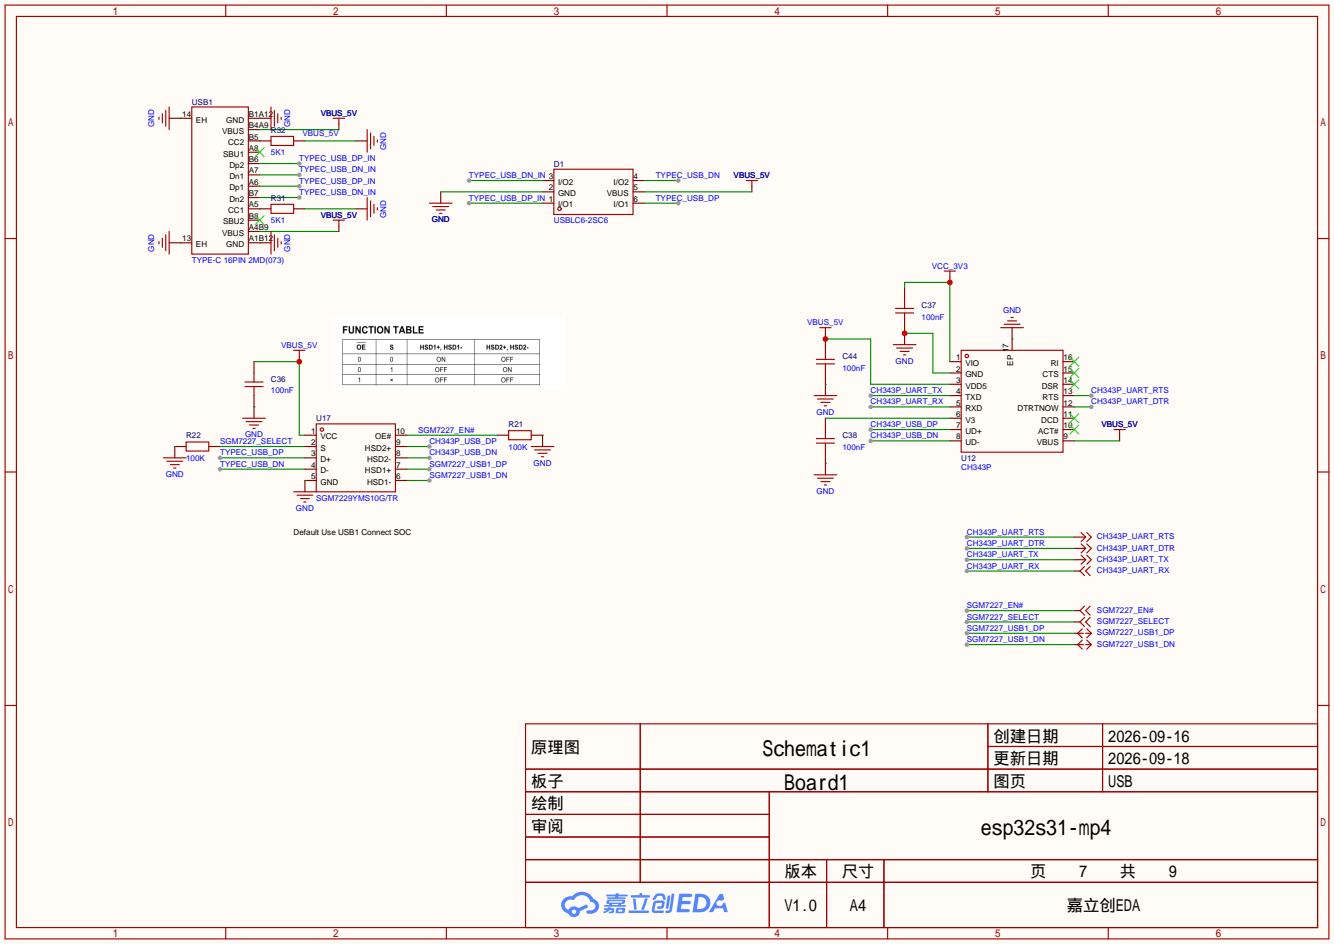
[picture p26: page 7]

USB1
GND A1B12 VBUS A4B9 SBU2 B8 CC1 A5 Dn2 B7 Dp1 A6 Dn1 A7 Dp2 B6 SBU1 A8 CC2 B5 VBUS B4A9 GND B1A12 EH 14

ACT# 10 DCD 11 DTRTNOW 12 RTS 13 DSR 14 CTS 15 RI 16

Default Use USB1 Connect SOC

原理图 | Schematic1 | 创建日期 | 2026-09-16

更新日期 | 2026-09-18

板子 | Board1 | 图页 | USB
绘制 | | esp32s31-mp4
审阅

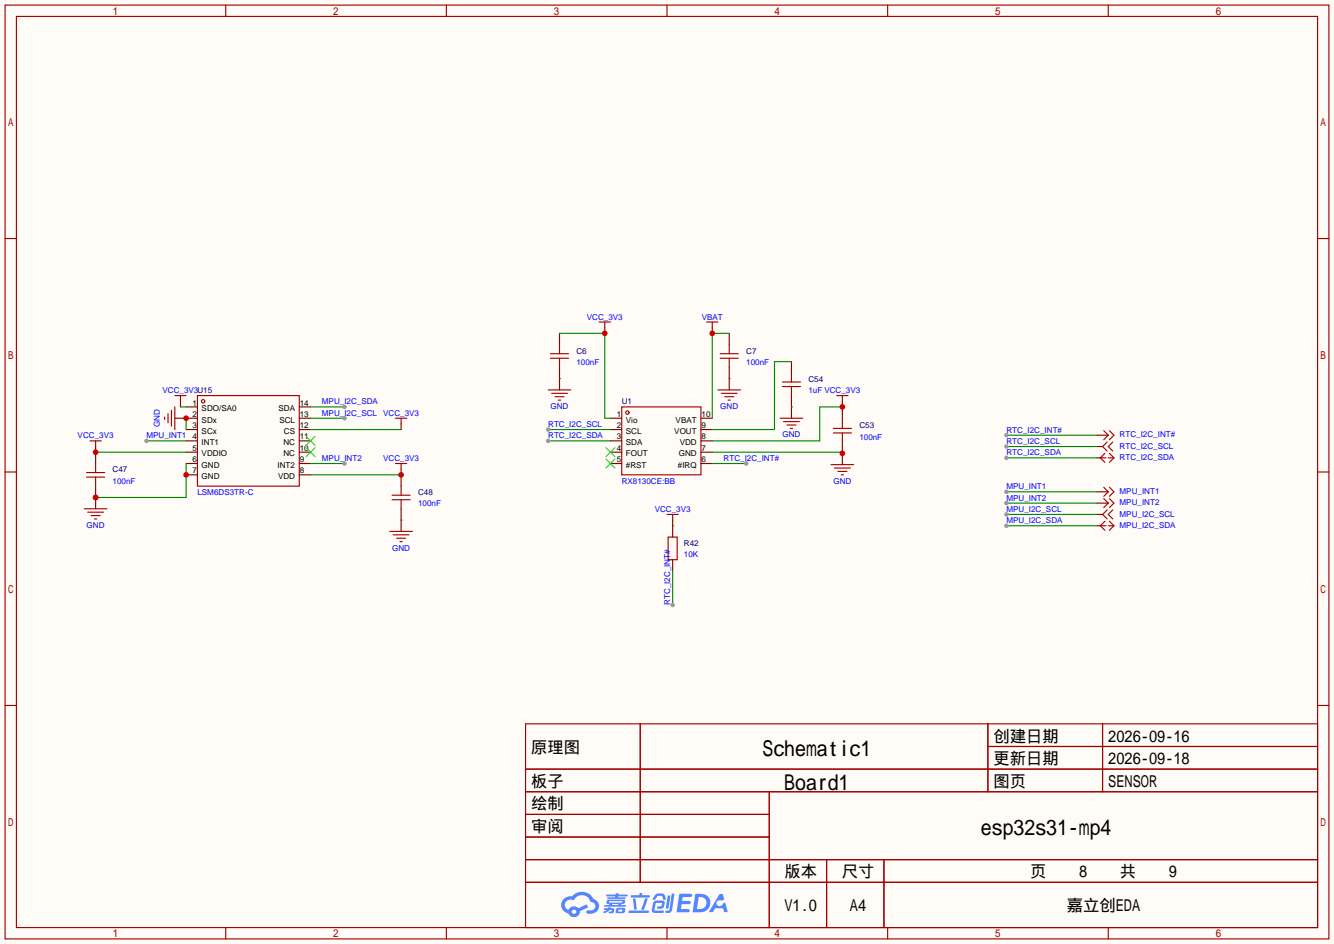
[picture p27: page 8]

MPU_I2C_SDA
NC 10 NC 11 CS 12 SCL 13 SDA 14

原理图 | Schematic1 | 创建日期 | 2026-09-16

更新日期 | 2026-09-18

板子 | Board1 | 图页 | SENSOR
绘制 | | esp32s31-mp4
审阅

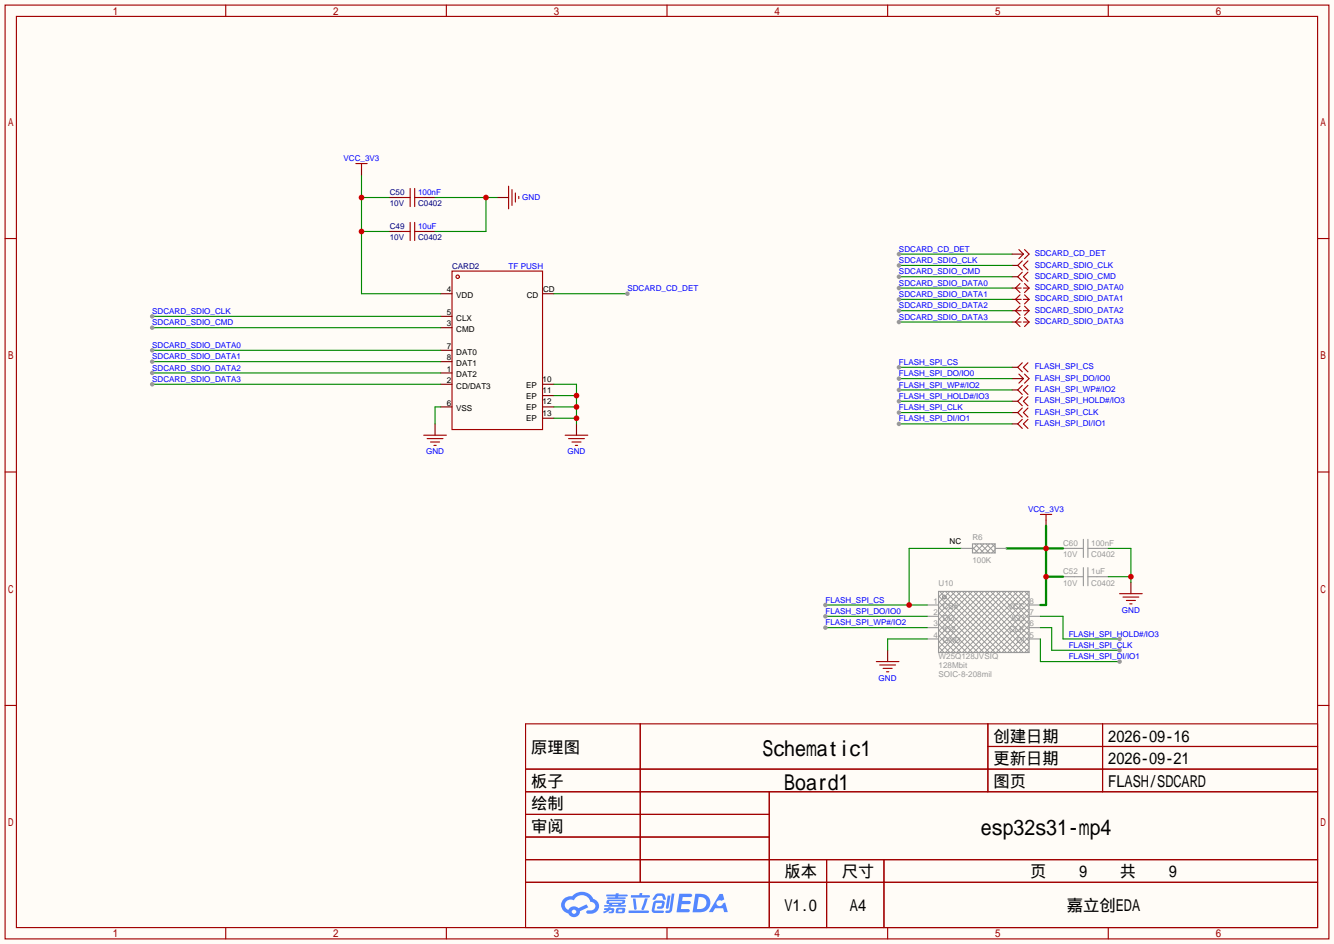
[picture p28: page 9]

原理图 | Schematic1 | 创建日期 | 2026-09-16

更新日期 | 2026-09-21

板子 | Board1 | 图页 | FLASH/SDCARD
绘制 | | esp32s31-mp4
审阅

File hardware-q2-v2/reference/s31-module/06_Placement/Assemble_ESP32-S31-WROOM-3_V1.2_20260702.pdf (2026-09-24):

Y1

# Y1Y¹x1 Y¹x2Y¹x3Y¹x4

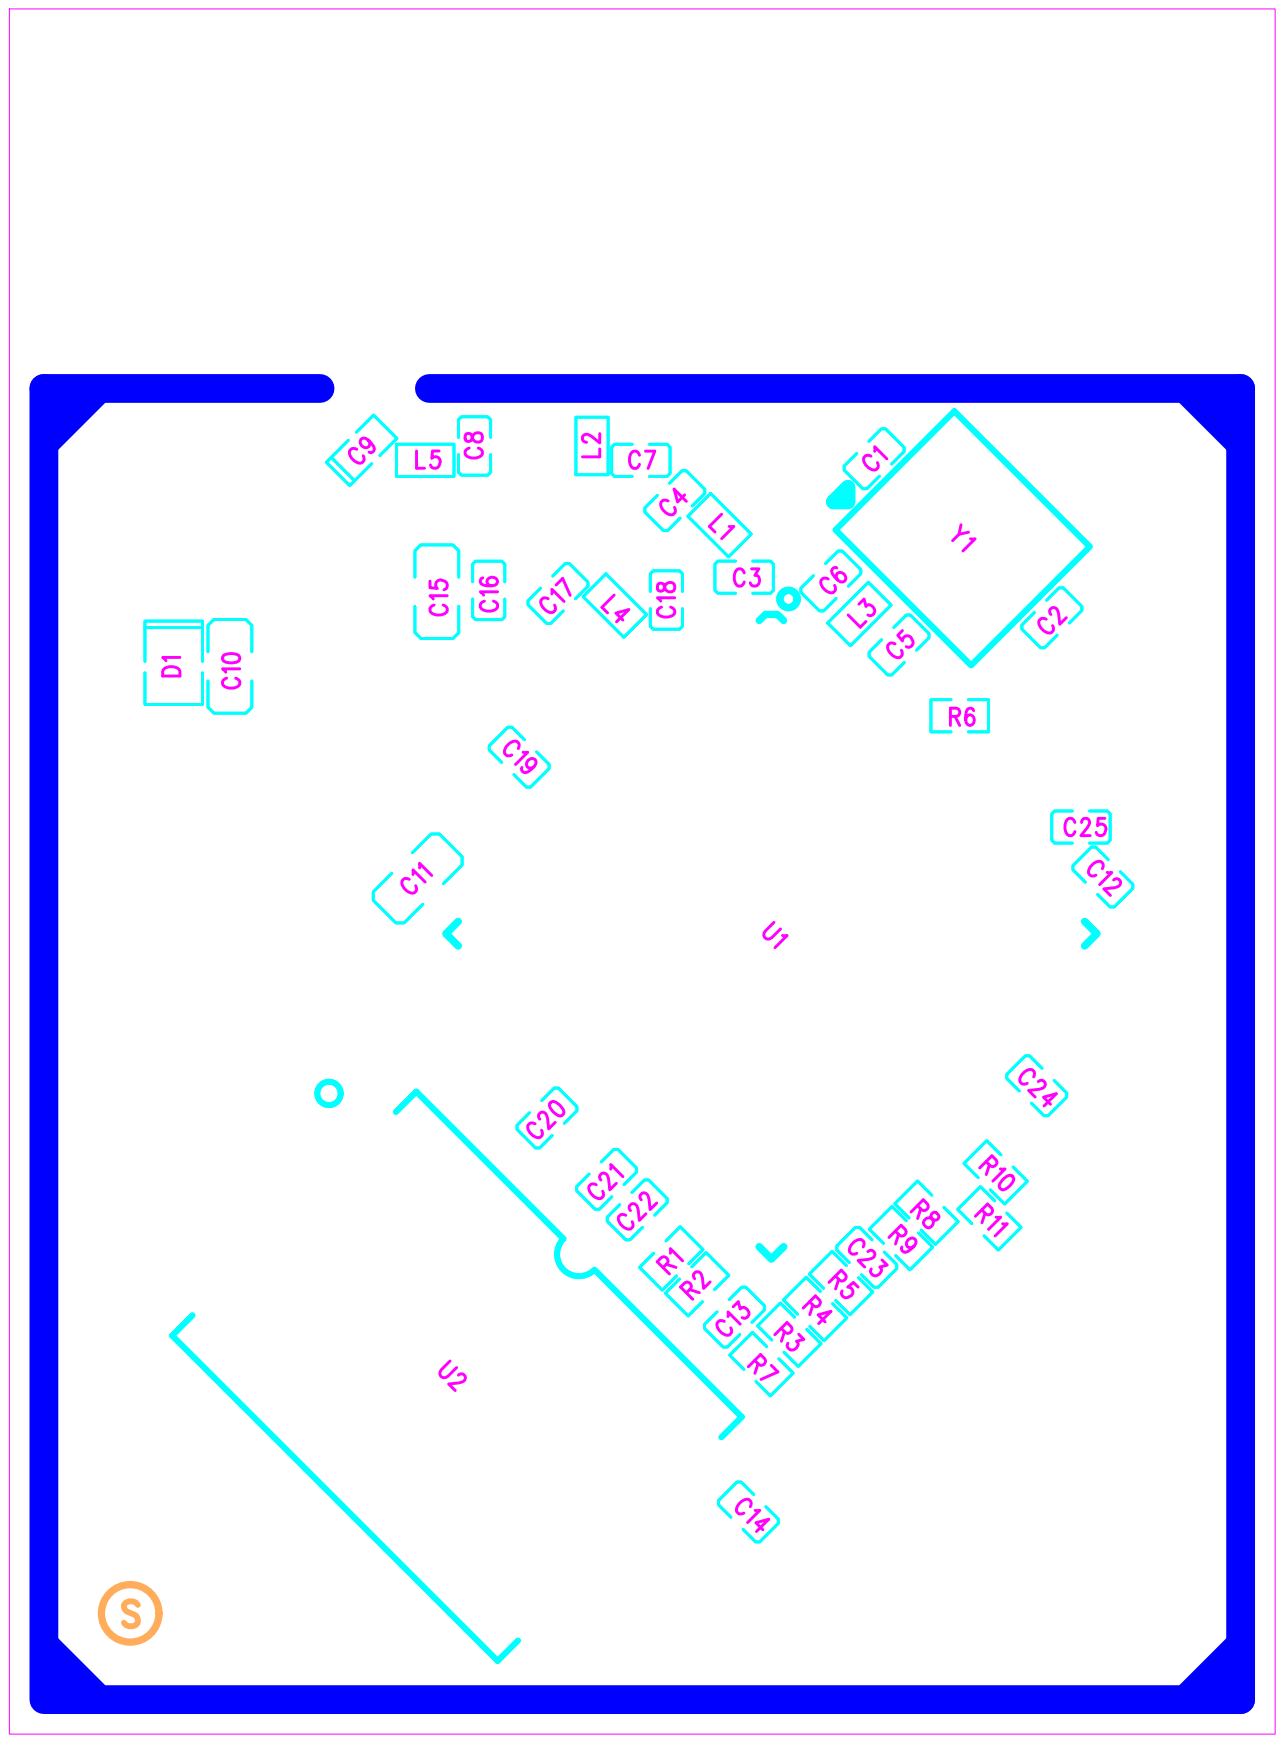
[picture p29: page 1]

# ESP32-S31-WROOM-3 V1.2

HF

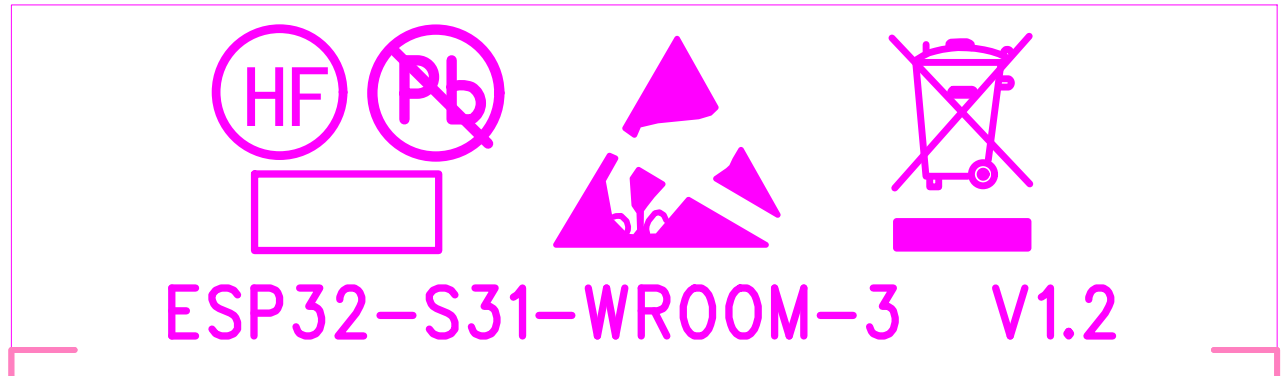
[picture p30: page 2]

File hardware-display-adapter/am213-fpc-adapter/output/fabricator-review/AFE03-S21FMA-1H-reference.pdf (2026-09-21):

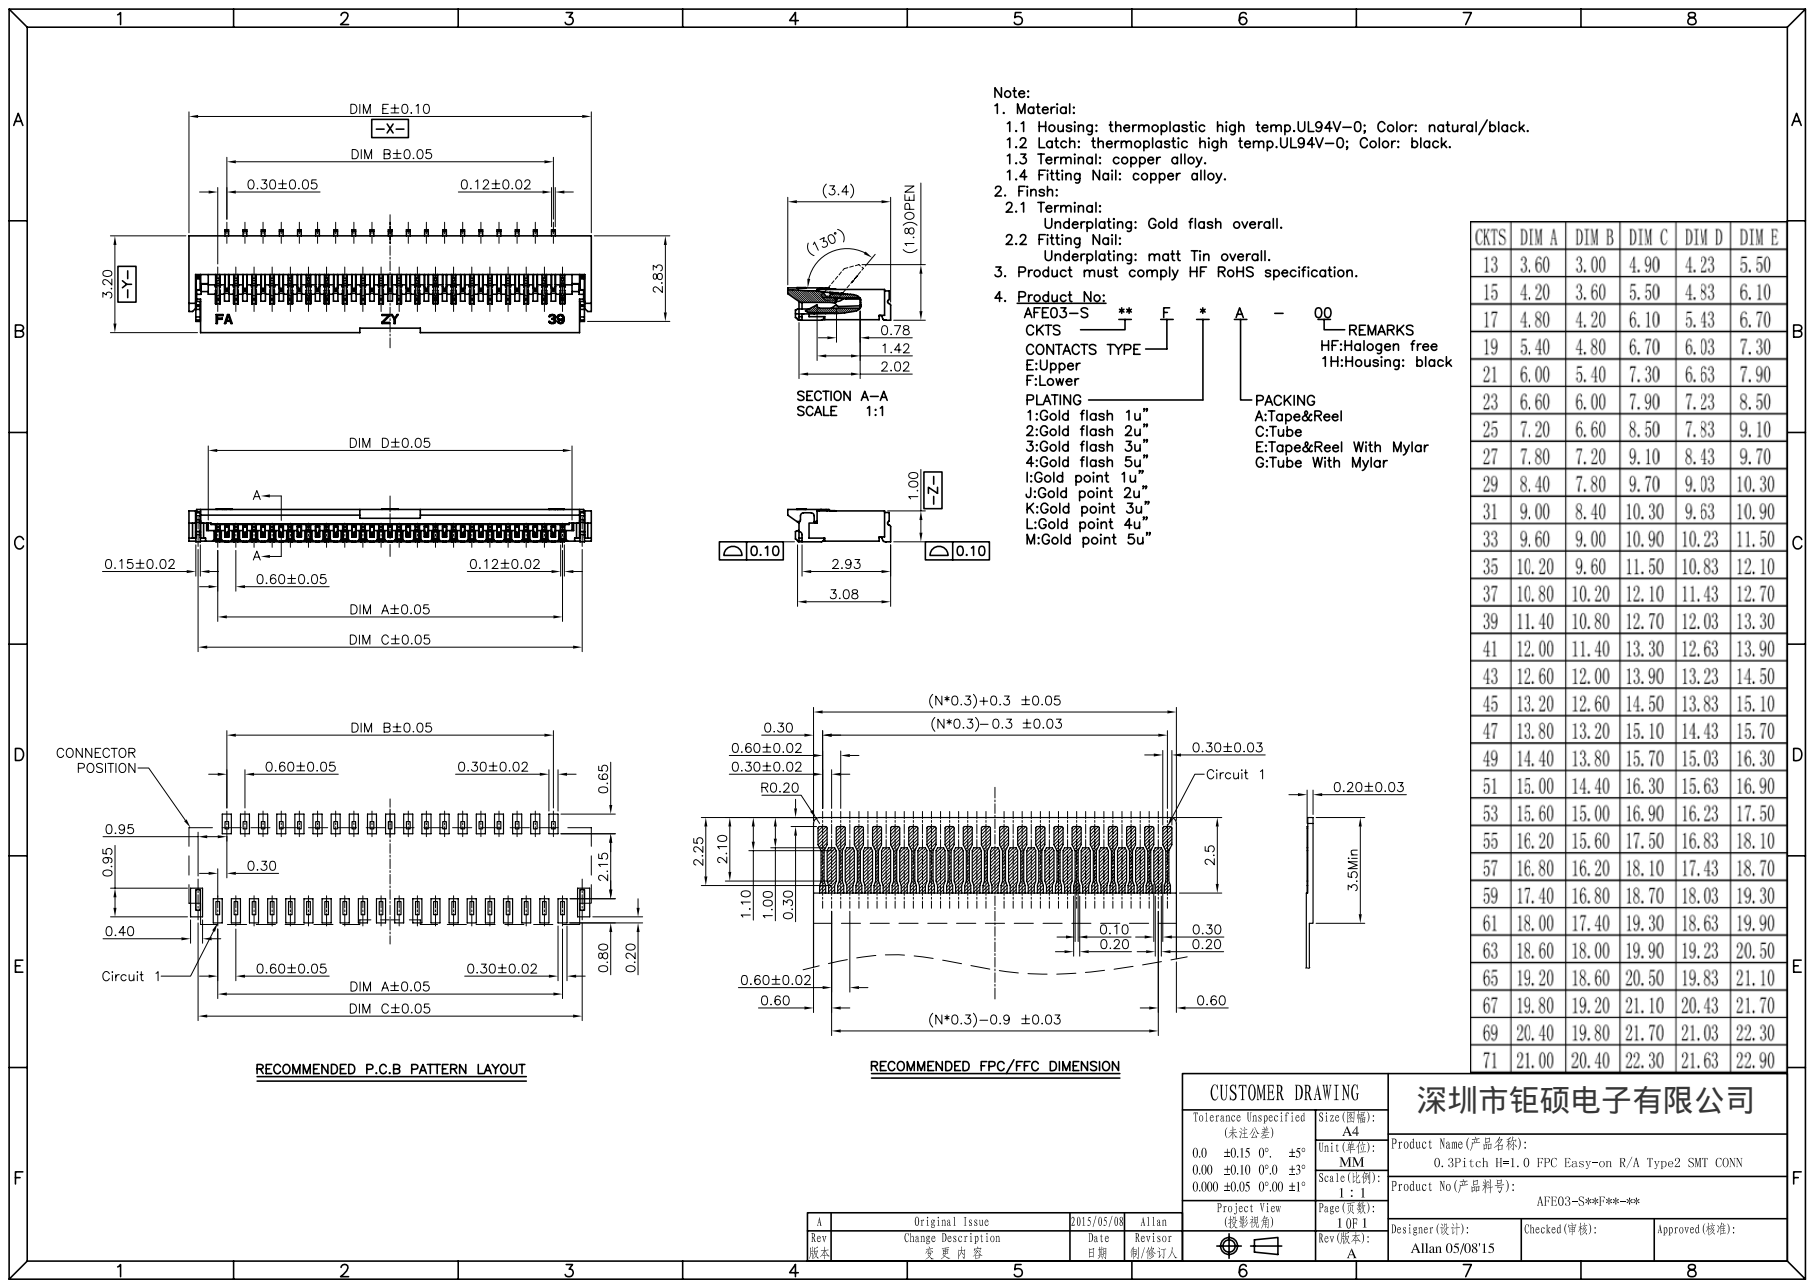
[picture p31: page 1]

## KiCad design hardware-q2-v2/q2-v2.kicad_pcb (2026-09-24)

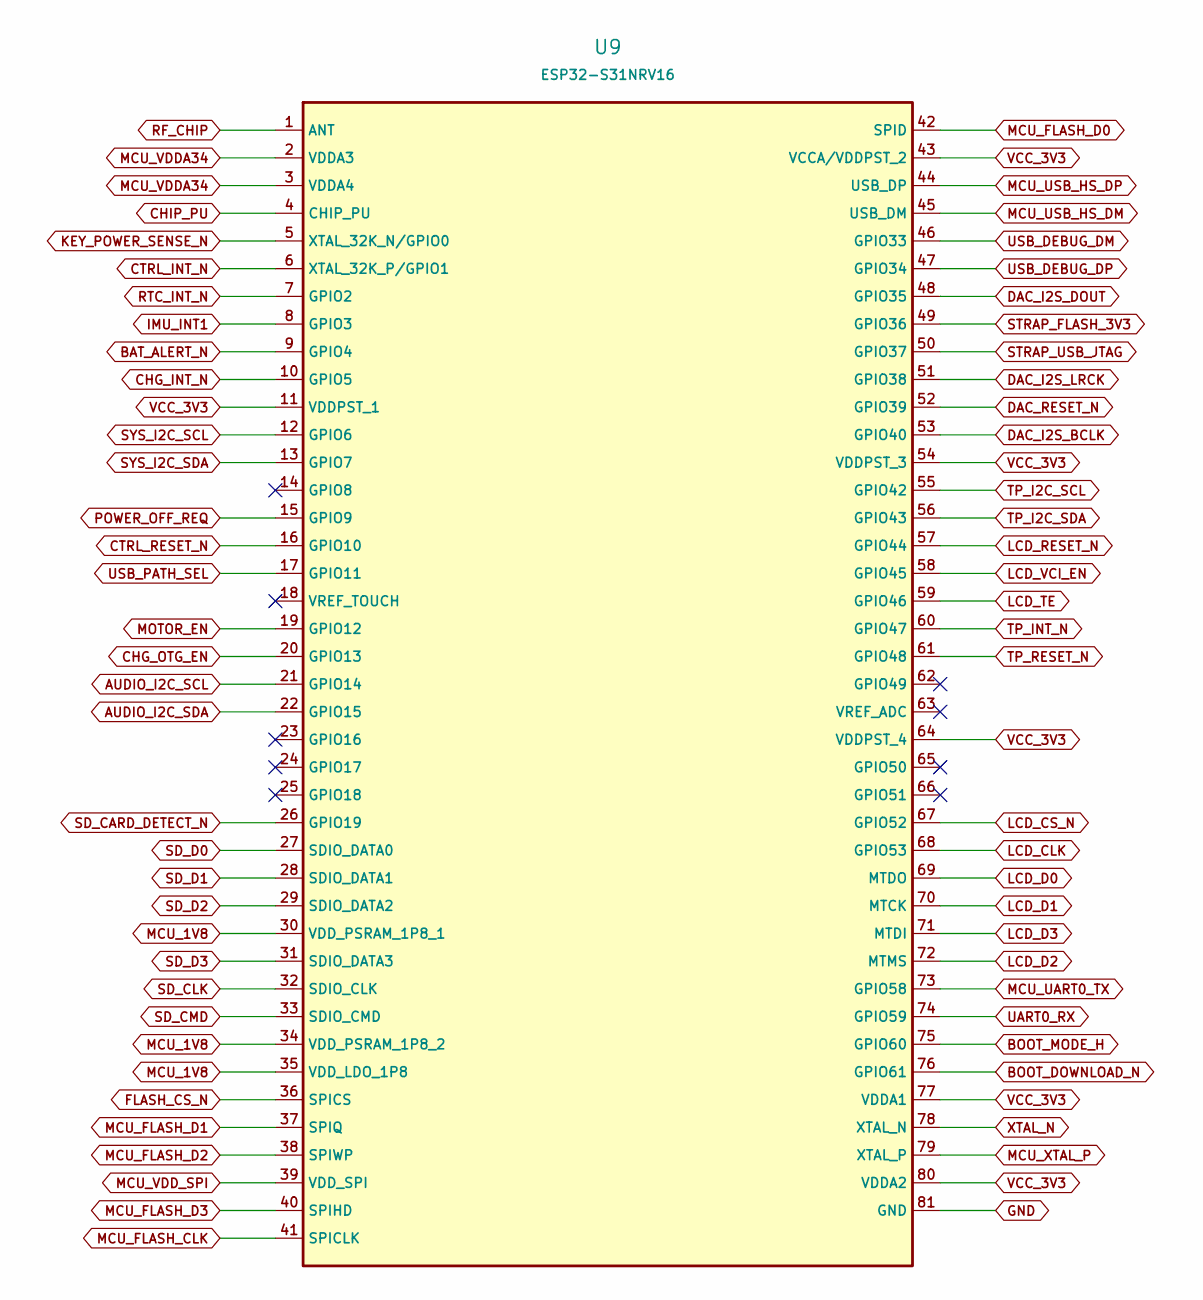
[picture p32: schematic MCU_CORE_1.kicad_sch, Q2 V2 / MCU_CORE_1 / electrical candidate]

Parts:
U9: ESP32-S31NRV16; FP_U9

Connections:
AUDIO_I2C_SCL: U9.21 (GPIO14); also elsewhere on the board
AUDIO_I2C_SDA: U9.22 (GPIO15); also elsewhere on the board
BAT_ALERT_N: U9.9 (GPIO4); also elsewhere on the board
BOOT_DOWNLOAD_N: U9.76 (GPIO61); also elsewhere on the board
BOOT_MODE_H: U9.75 (GPIO60); also elsewhere on the board
CHG_INT_N: U9.10 (GPIO5); also elsewhere on the board
CHG_OTG_EN: U9.20 (GPIO13); also elsewhere on the board
CHIP_PU: U9.4 (CHIP_PU); also elsewhere on the board
CTRL_INT_N: U9.6 (XTAL_32K_P/GPIO1); also elsewhere on the board
CTRL_RESET_N: U9.16 (GPIO10); also elsewhere on the board
DAC_I2S_BCLK: U9.53 (GPIO40); also elsewhere on the board
DAC_I2S_DOUT: U9.48 (GPIO35); also elsewhere on the board
DAC_I2S_LRCK: U9.51 (GPIO38); also elsewhere on the board
DAC_RESET_N: U9.52 (GPIO39); also elsewhere on the board
FLASH_CS_N: U9.36 (SPICS); also elsewhere on the board
GND: U9.81 (GND); also elsewhere on the board
IMU_INT1: U9.8 (GPIO3); also elsewhere on the board
KEY_POWER_SENSE_N: U9.5 (XTAL_32K_N/GPIO0); also elsewhere on the board
LCD_CLK: U9.68 (GPIO53); also elsewhere on the board
LCD_CS_N: U9.67 (GPIO52); also elsewhere on the board
LCD_D0: U9.69 (MTDO); also elsewhere on the board
LCD_D1: U9.70 (MTCK); also elsewhere on the board
LCD_D2: U9.72 (MTMS); also elsewhere on the board
LCD_D3: U9.71 (MTDI); also elsewhere on the board
LCD_RESET_N: U9.57 (GPIO44); also elsewhere on the board
LCD_TE: U9.59 (GPIO46); also elsewhere on the board
LCD_VCI_EN: U9.58 (GPIO45); also elsewhere on the board
MCU_1V8: U9.30 (VDD_PSRAM_1P8_1), U9.34 (VDD_PSRAM_1P8_2), U9.35 (VDD_LDO_1P8); also elsewhere on the board
MCU_FLASH_CLK: U9.41 (SPICLK); also elsewhere on the board
MCU_FLASH_D0: U9.42 (SPID); also elsewhere on the board
MCU_FLASH_D1: U9.37 (SPIQ); also elsewhere on the board
MCU_FLASH_D2: U9.38 (SPIWP); also elsewhere on the board
MCU_FLASH_D3: U9.40 (SPIHD); also elsewhere on the board
MCU_UART0_TX: U9.73 (GPIO58); also elsewhere on the board
MCU_USB_HS_DM: U9.45 (USB_DM); also elsewhere on the board
MCU_USB_HS_DP: U9.44 (USB_DP); also elsewhere on the board
MCU_VDDA34: U9.2 (VDDA3), U9.3 (VDDA4); also elsewhere on the board
MCU_VDD_SPI: U9.39 (VDD_SPI); also elsewhere on the board
MCU_XTAL_P: U9.79 (XTAL_P); also elsewhere on the board
MOTOR_EN: U9.19 (GPIO12); also elsewhere on the board
POWER_OFF_REQ: U9.15 (GPIO9); also elsewhere on the board
RF_CHIP: U9.1 (ANT); also elsewhere on the board
RTC_INT_N: U9.7 (GPIO2); also elsewhere on the board
SD_CARD_DETECT_N: U9.26 (GPIO19); also elsewhere on the board
SD_CLK: U9.32 (SDIO_CLK); also elsewhere on the board
SD_CMD: U9.33 (SDIO_CMD); also elsewhere on the board
SD_D0: U9.27 (SDIO_DATA0); also elsewhere on the board
SD_D1: U9.28 (SDIO_DATA1); also elsewhere on the board
SD_D2: U9.29 (SDIO_DATA2); also elsewhere on the board
SD_D3: U9.31 (SDIO_DATA3); also elsewhere on the board
STRAP_FLASH_3V3: U9.49 (GPIO36); also elsewhere on the board
STRAP_USB_JTAG: U9.50 (GPIO37); also elsewhere on the board
SYS_I2C_SCL: U9.12 (GPIO6); also elsewhere on the board
SYS_I2C_SDA: U9.13 (GPIO7); also elsewhere on the board
TP_I2C_SCL: U9.55 (GPIO42); also elsewhere on the board
TP_I2C_SDA: U9.56 (GPIO43); also elsewhere on the board
TP_INT_N: U9.60 (GPIO47); also elsewhere on the board
TP_RESET_N: U9.61 (GPIO48); also elsewhere on the board
UART0_RX: U9.74 (GPIO59); also elsewhere on the board
USB_DEBUG_DM: U9.46 (GPIO33); also elsewhere on the board
USB_DEBUG_DP: U9.47 (GPIO34); also elsewhere on the board
USB_PATH_SEL: U9.17 (GPIO11); also elsewhere on the board
VCC_3V3: U9.11 (VDDPST_1), U9.43 (VCCA/VDDPST_2), U9.54 (VDDPST_3), U9.64 (VDDPST_4), U9.77 (VDDA1), U9.80 (VDDA2); also elsewhere on the board
XTAL_N: U9.78 (XTAL_N); also elsewhere on the board

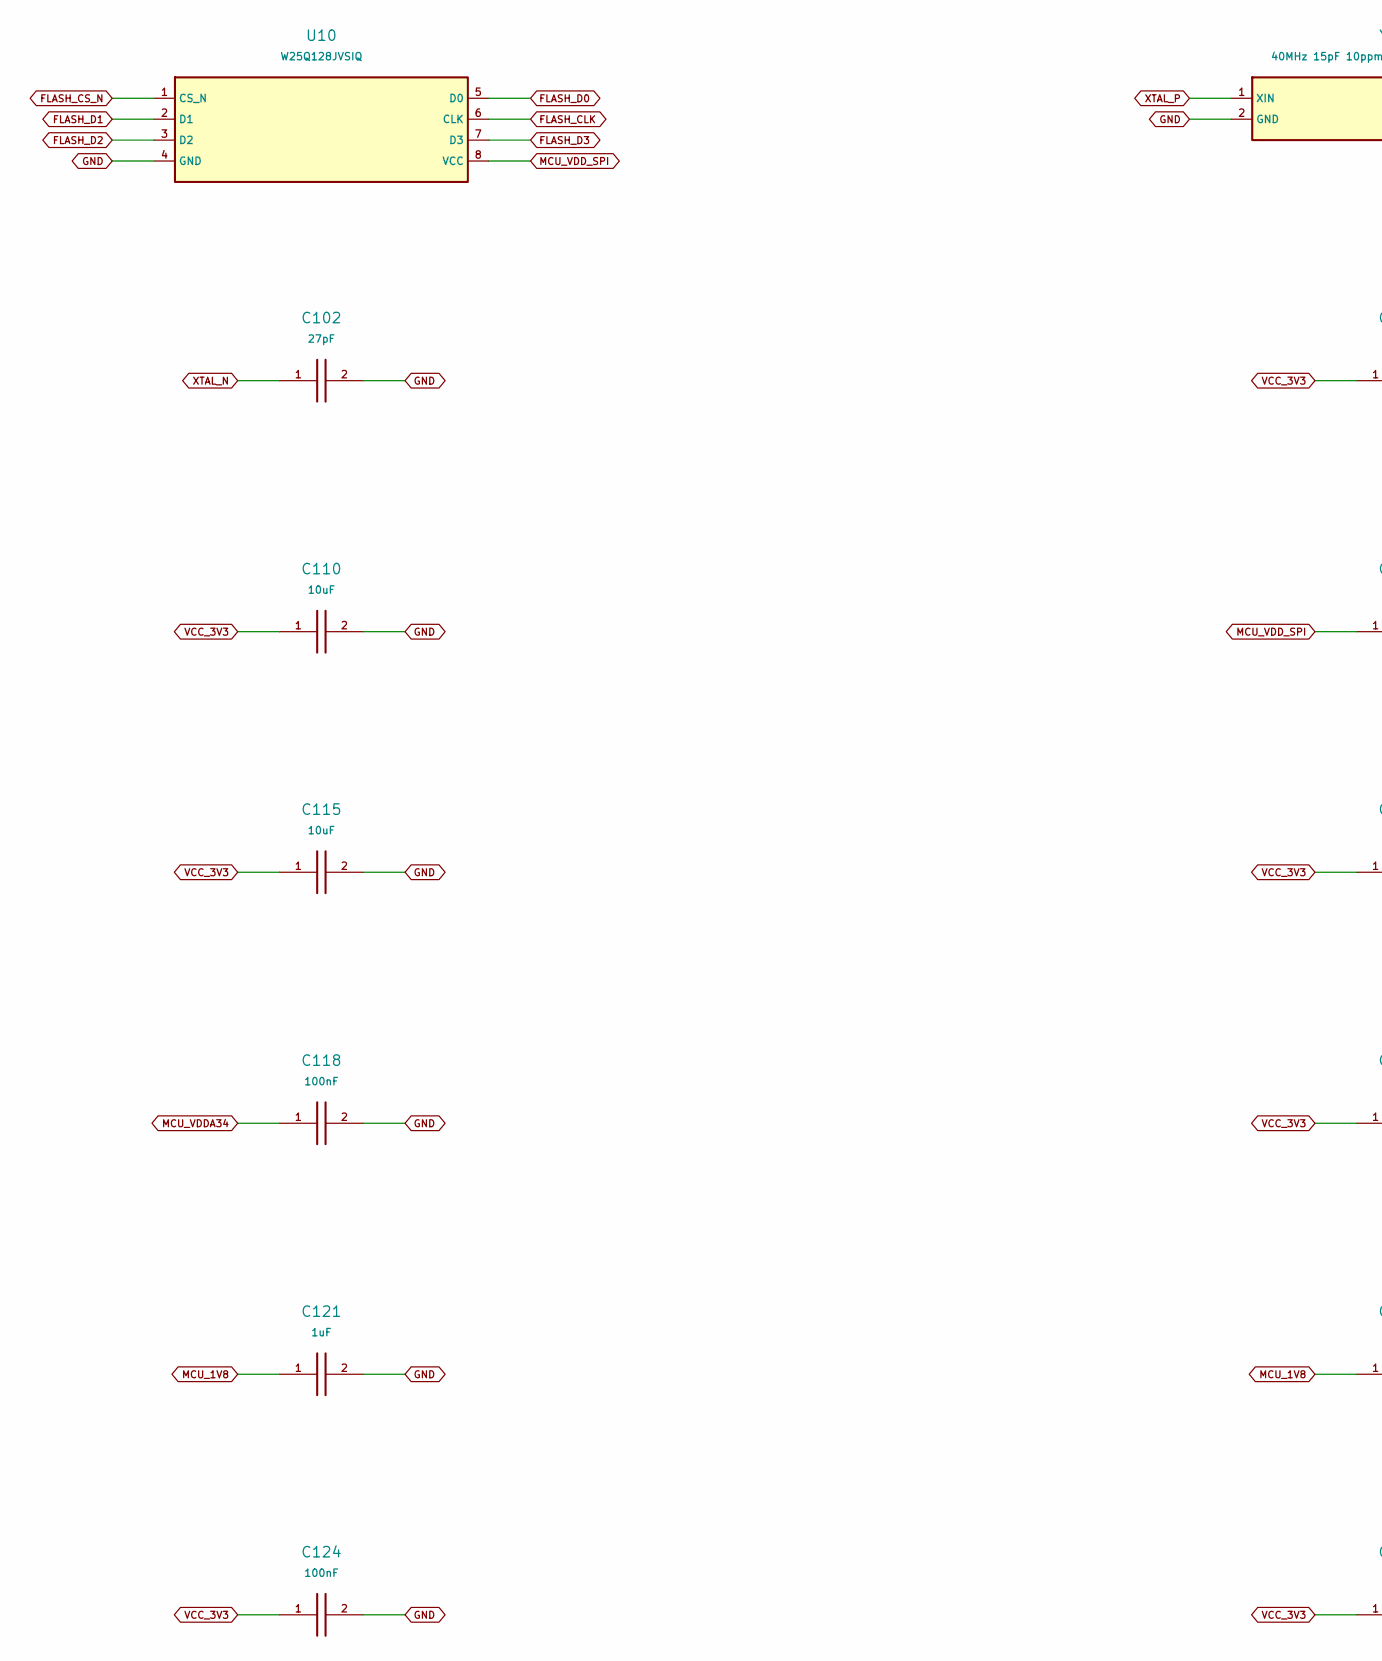
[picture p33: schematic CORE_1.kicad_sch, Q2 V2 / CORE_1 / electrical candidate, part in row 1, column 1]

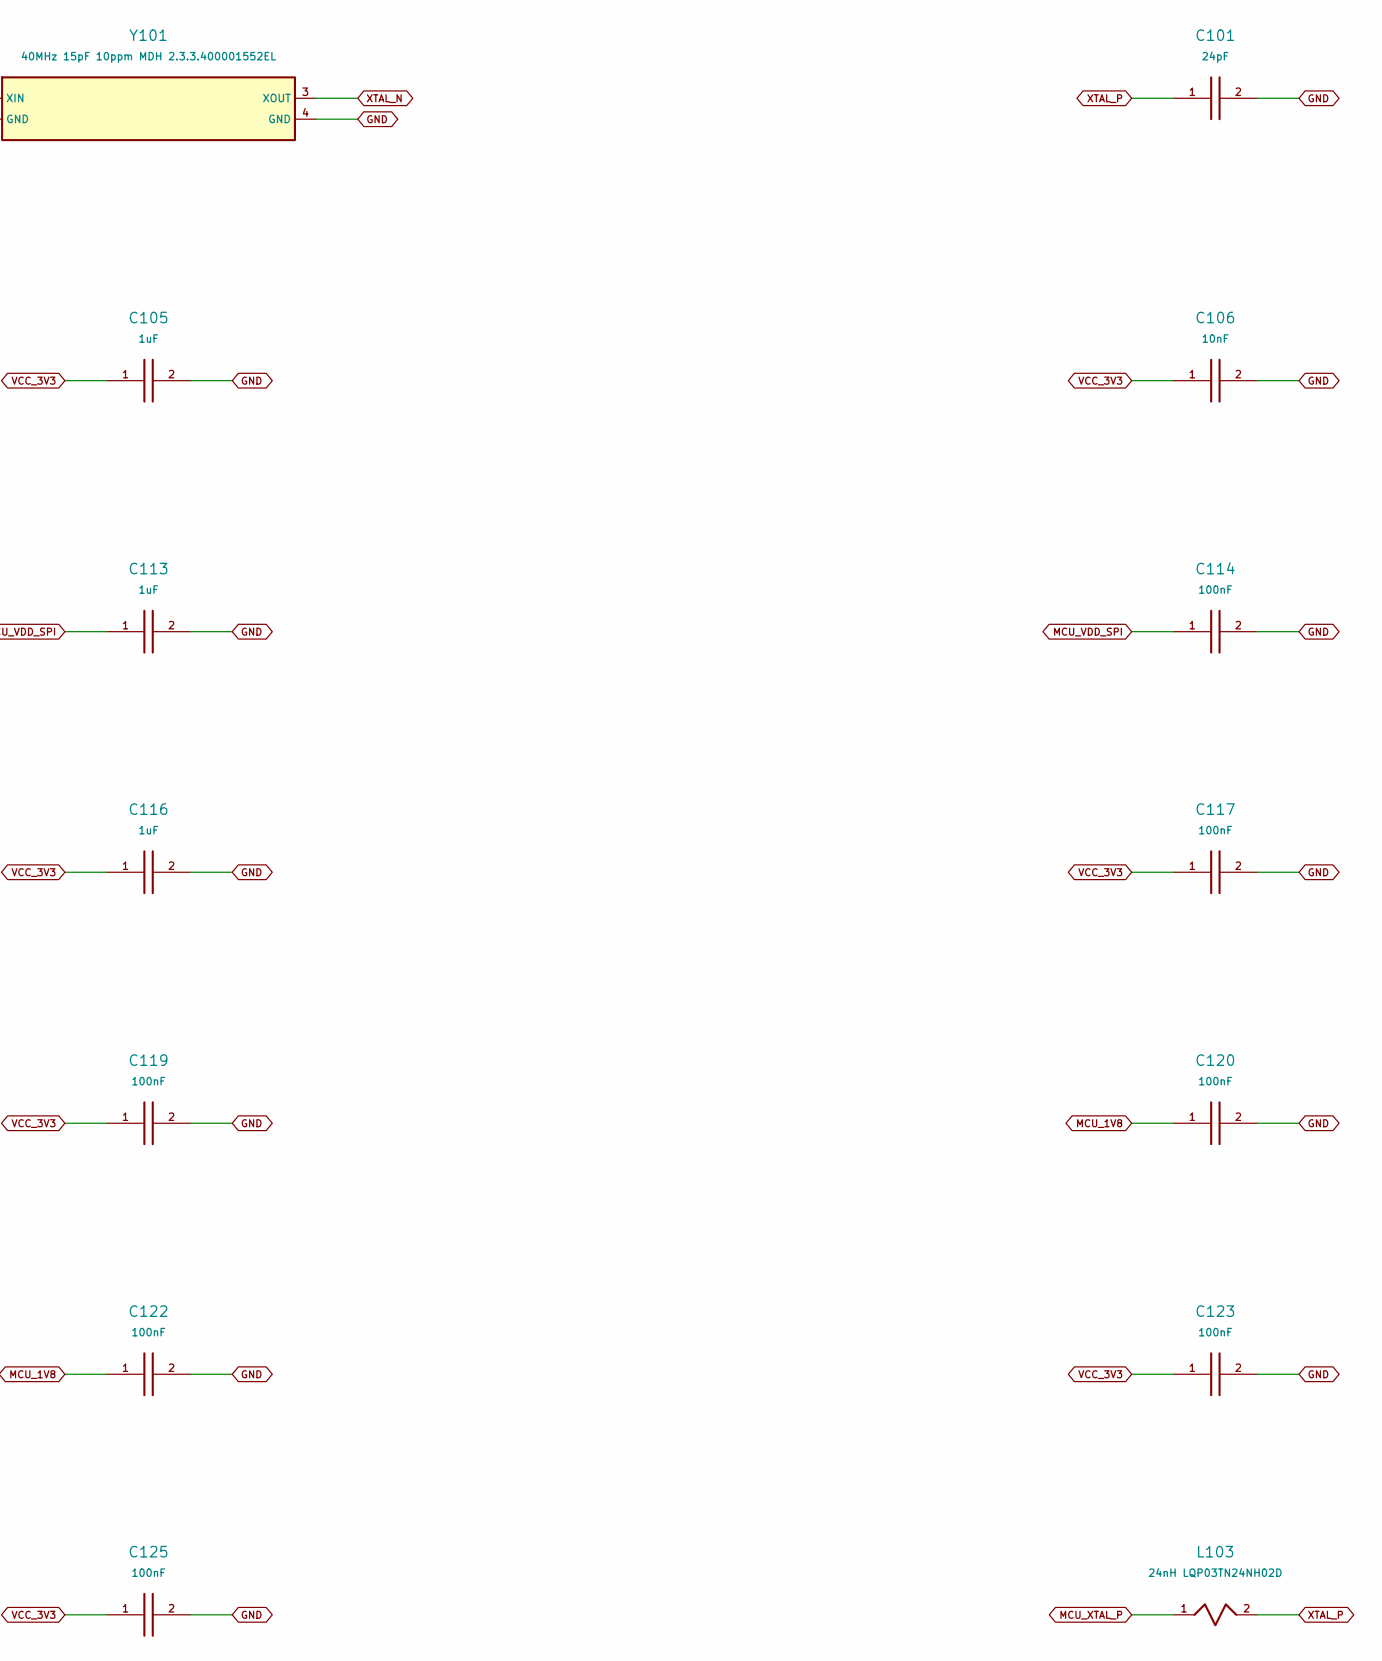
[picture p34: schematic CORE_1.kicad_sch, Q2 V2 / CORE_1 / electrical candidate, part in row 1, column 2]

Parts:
C101: 24pF; C_0402_1005Metric
C102: 27pF; C_0402_1005Metric
C105, C113, C116, C121: 1uF; C_0402_1005Metric
C106: 10nF; C_0402_1005Metric
C110, C115: 10uF; C_0402_1005Metric
C114, C117, C118, C119, C120, C122, C123, C124, C125: 100nF; C_0402_1005Metric
L103: 24nH LQP03TN24NH02D; FP_L103
U10: W25Q128JVSIQ; FP_U10
Y101: 40MHz 15pF 10ppm MDH 2.3.3.400001552EL; FP_Y101

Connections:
FLASH_CLK: U10.6 (CLK); also elsewhere on the board
FLASH_CS_N: U10.1 (CS_N); also elsewhere on the board
FLASH_D0: U10.5 (D0); also elsewhere on the board
FLASH_D1: U10.2 (D1); also elsewhere on the board
FLASH_D2: U10.3 (D2); also elsewhere on the board
FLASH_D3: U10.7 (D3); also elsewhere on the board
GND: C101.2, C102.2, C105.2, C106.2, C110.2, C113.2, C114.2, C115.2, C116.2, C117.2, C118.2, C119.2, C120.2, C121.2, C122.2, C123.2, C124.2, C125.2, U10.4 (GND), Y101.2 (GND), Y101.4 (GND); also elsewhere on the board
MCU_1V8: C120.1, C121.1, C122.1; also elsewhere on the board
MCU_VDDA34: C118.1; also elsewhere on the board
MCU_VDD_SPI: C113.1, C114.1, U10.8 (VCC); also elsewhere on the board
MCU_XTAL_P: L103.1; also elsewhere on the board
VCC_3V3: C105.1, C106.1, C110.1, C115.1, C116.1, C117.1, C119.1, C123.1, C124.1, C125.1; also elsewhere on the board
XTAL_N: C102.1, Y101.3 (XOUT); also elsewhere on the board
XTAL_P: C101.1, L103.2, Y101.1 (XIN)

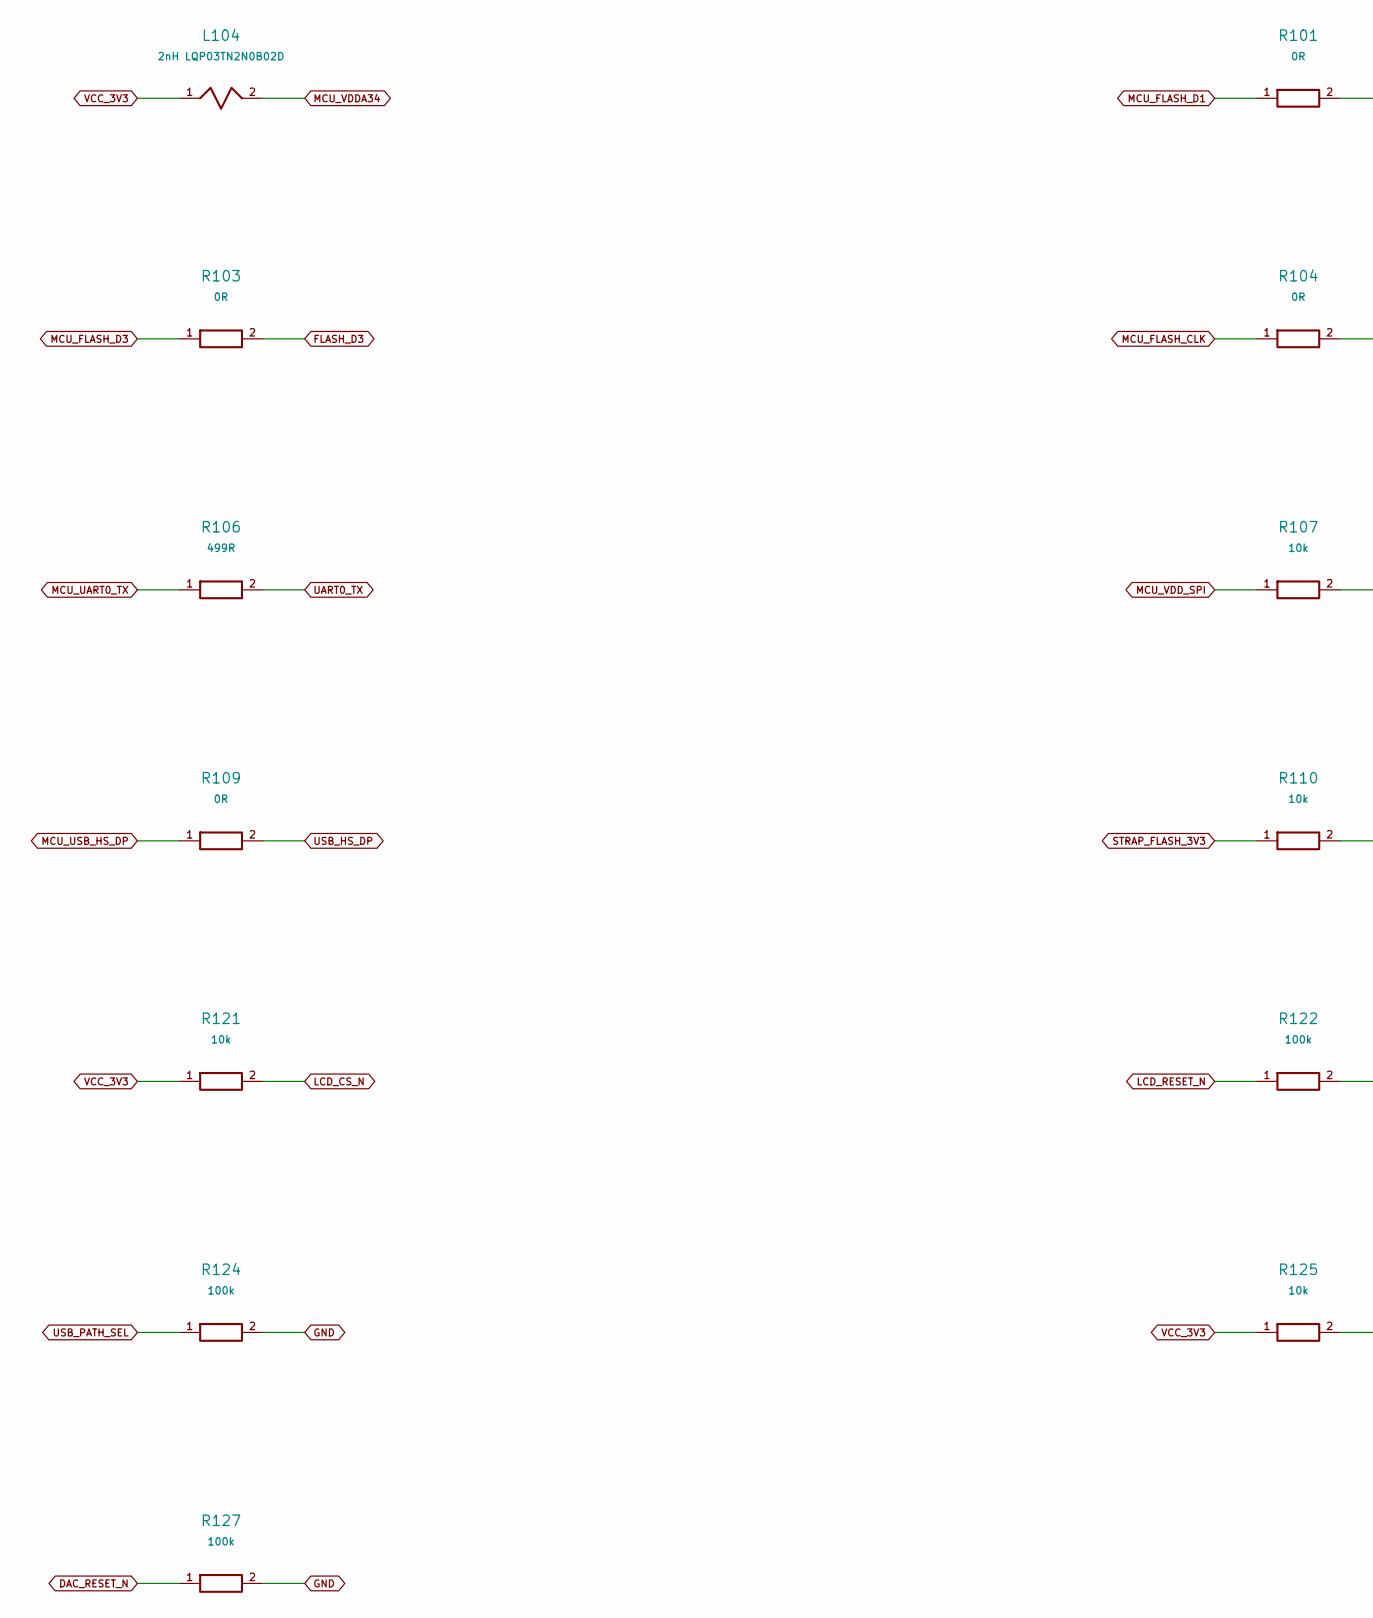
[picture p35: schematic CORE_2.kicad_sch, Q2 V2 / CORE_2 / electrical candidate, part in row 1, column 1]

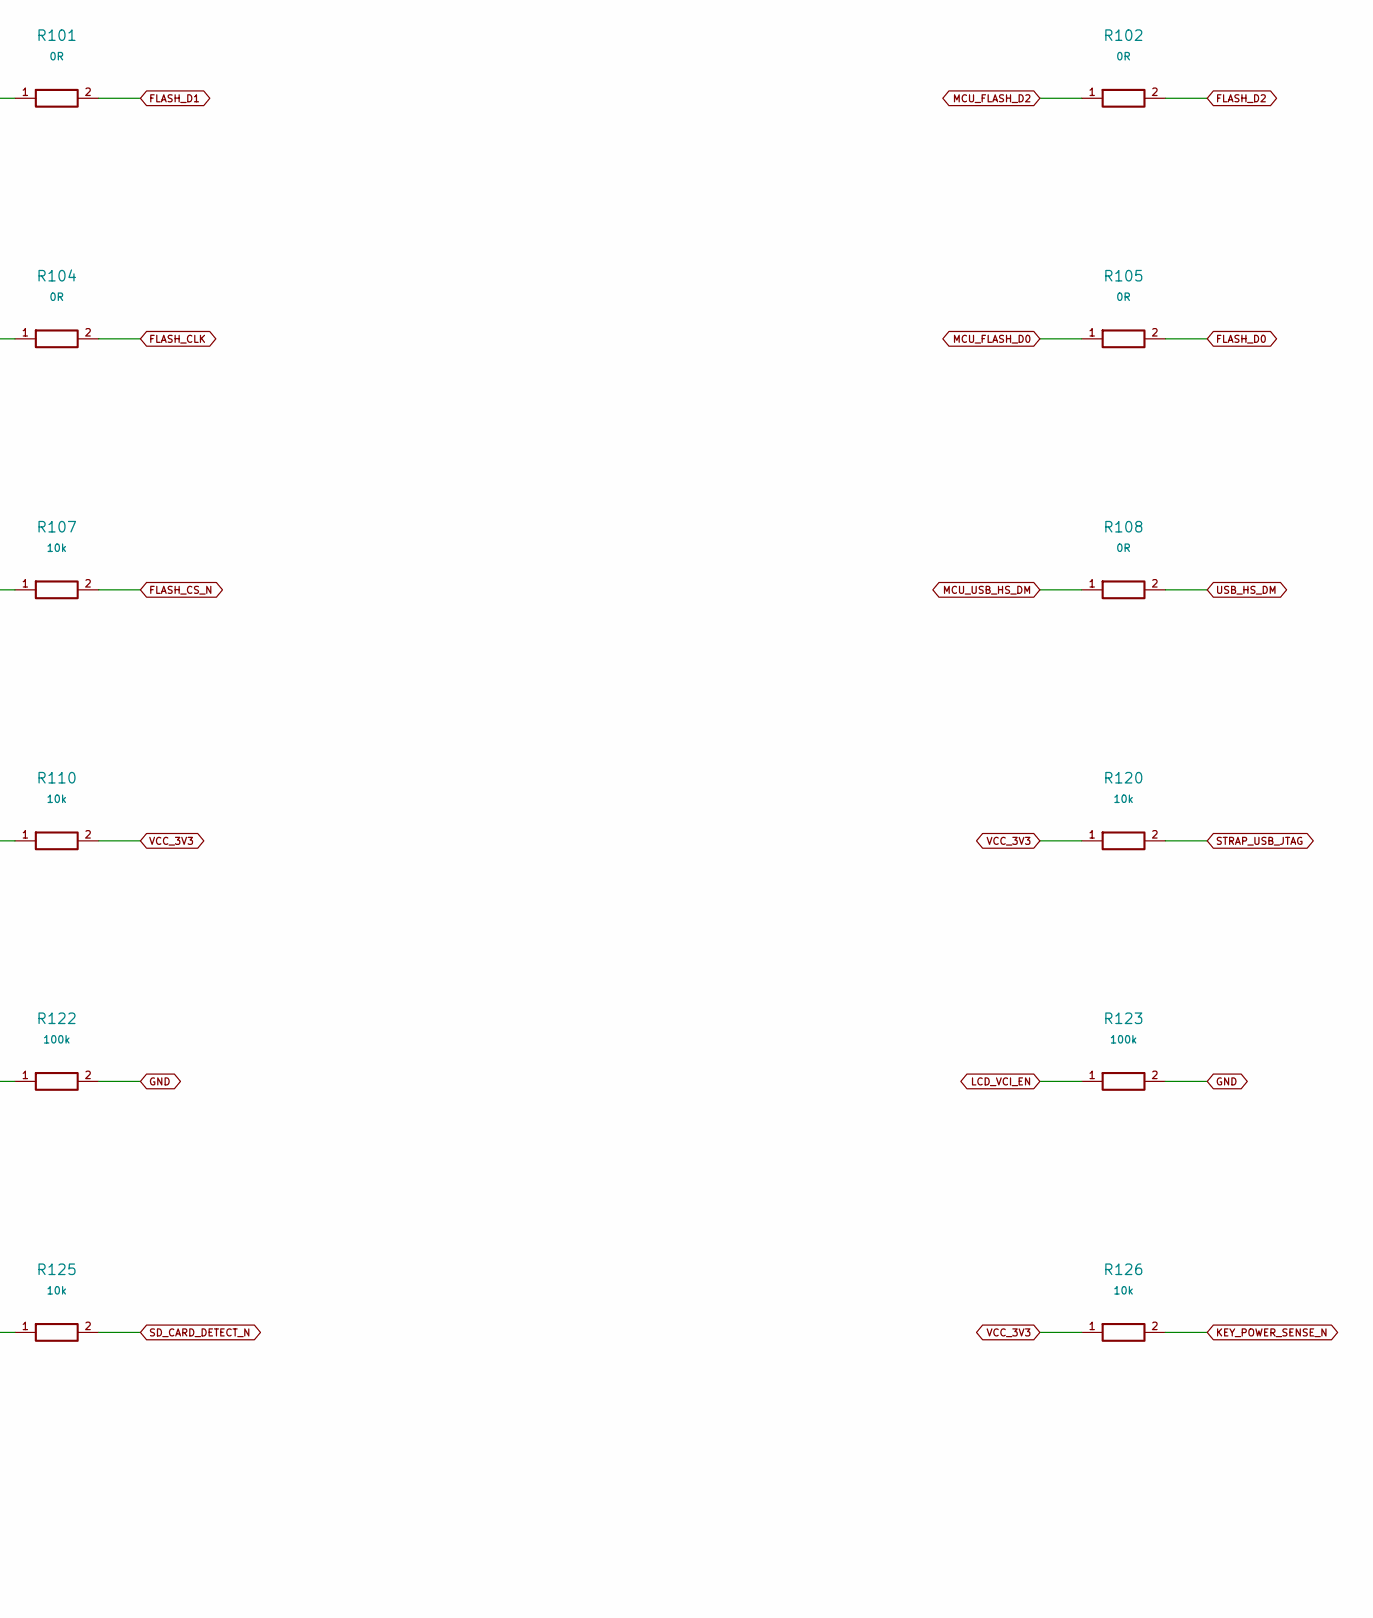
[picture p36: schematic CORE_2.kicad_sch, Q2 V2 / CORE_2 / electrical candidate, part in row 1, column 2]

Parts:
L104: 2nH LQP03TN2N0B02D; FP_L104
R101, R102, R103, R104, R105, R108, R109: 0R; R_0402_1005Metric
R106: 499R; R_0402_1005Metric
R107, R110, R120, R121, R125, R126: 10k; R_0402_1005Metric
R122, R123, R124, R127: 100k; R_0402_1005Metric

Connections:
DAC_RESET_N: R127.1; also elsewhere on the board
FLASH_CLK: R104.2; also elsewhere on the board
FLASH_CS_N: R107.2; also elsewhere on the board
FLASH_D0: R105.2; also elsewhere on the board
FLASH_D1: R101.2; also elsewhere on the board
FLASH_D2: R102.2; also elsewhere on the board
FLASH_D3: R103.2; also elsewhere on the board
GND: R122.2, R123.2, R124.2, R127.2; also elsewhere on the board
KEY_POWER_SENSE_N: R126.2; also elsewhere on the board
LCD_CS_N: R121.2; also elsewhere on the board
LCD_RESET_N: R122.1; also elsewhere on the board
LCD_VCI_EN: R123.1; also elsewhere on the board
MCU_FLASH_CLK: R104.1; also elsewhere on the board
MCU_FLASH_D0: R105.1; also elsewhere on the board
MCU_FLASH_D1: R101.1; also elsewhere on the board
MCU_FLASH_D2: R102.1; also elsewhere on the board
MCU_FLASH_D3: R103.1; also elsewhere on the board
MCU_UART0_TX: R106.1; also elsewhere on the board
MCU_USB_HS_DM: R108.1; also elsewhere on the board
MCU_USB_HS_DP: R109.1; also elsewhere on the board
MCU_VDDA34: L104.2; also elsewhere on the board
MCU_VDD_SPI: R107.1; also elsewhere on the board
SD_CARD_DETECT_N: R125.2; also elsewhere on the board
STRAP_FLASH_3V3: R110.1; also elsewhere on the board
STRAP_USB_JTAG: R120.2; also elsewhere on the board
UART0_TX: R106.2; also elsewhere on the board
USB_HS_DM: R108.2; also elsewhere on the board
USB_HS_DP: R109.2; also elsewhere on the board
USB_PATH_SEL: R124.1; also elsewhere on the board
VCC_3V3: L104.1, R110.2, R120.1, R121.1, R125.1, R126.1; also elsewhere on the board

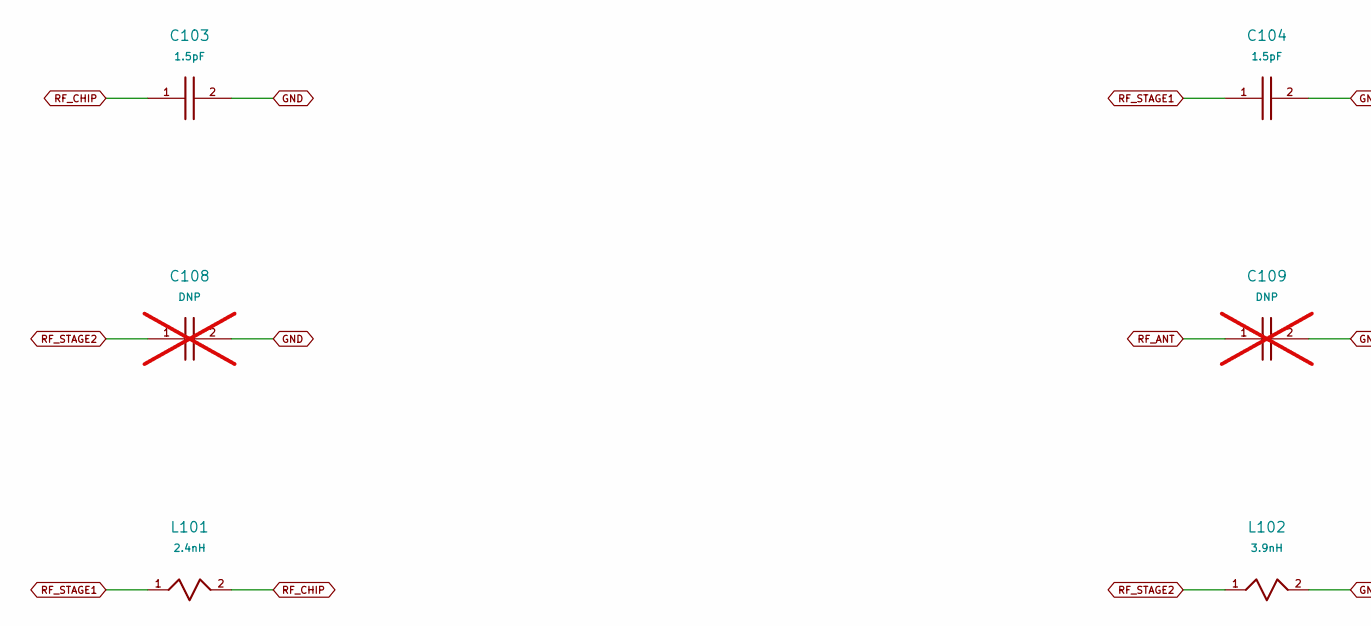
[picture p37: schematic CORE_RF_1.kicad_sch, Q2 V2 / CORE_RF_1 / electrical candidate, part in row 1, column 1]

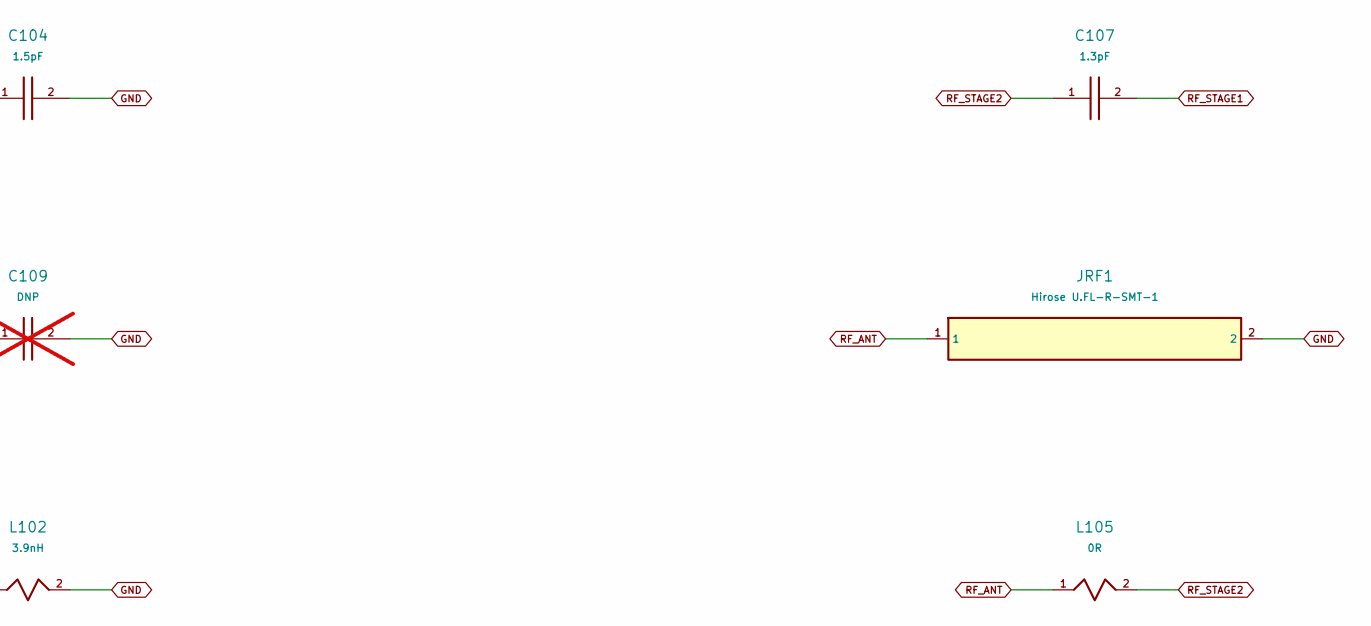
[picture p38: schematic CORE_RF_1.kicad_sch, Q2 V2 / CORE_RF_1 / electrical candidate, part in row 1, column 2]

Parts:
C103, C104: 1.5pF; C_0402_1005Metric
C107: 1.3pF; C_0402_1005Metric
C108, C109: DNP; C_0402_1005Metric; not fitted
JRF1: Hirose U.FL-R-SMT-1; FP_JRF1
L101: 2.4nH; FP_L101
L102: 3.9nH; FP_L102
L105: 0R; R_0402_1005Metric

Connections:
GND: C103.2, C104.2, C108.2, C109.2, JRF1.2, L102.2; also elsewhere on the board
RF_ANT: C109.1, JRF1.1, L105.1
RF_CHIP: C103.1, L101.2; also elsewhere on the board
RF_STAGE1: C104.1, C107.2, L101.1
RF_STAGE2: C107.1, C108.1, L102.1, L105.2

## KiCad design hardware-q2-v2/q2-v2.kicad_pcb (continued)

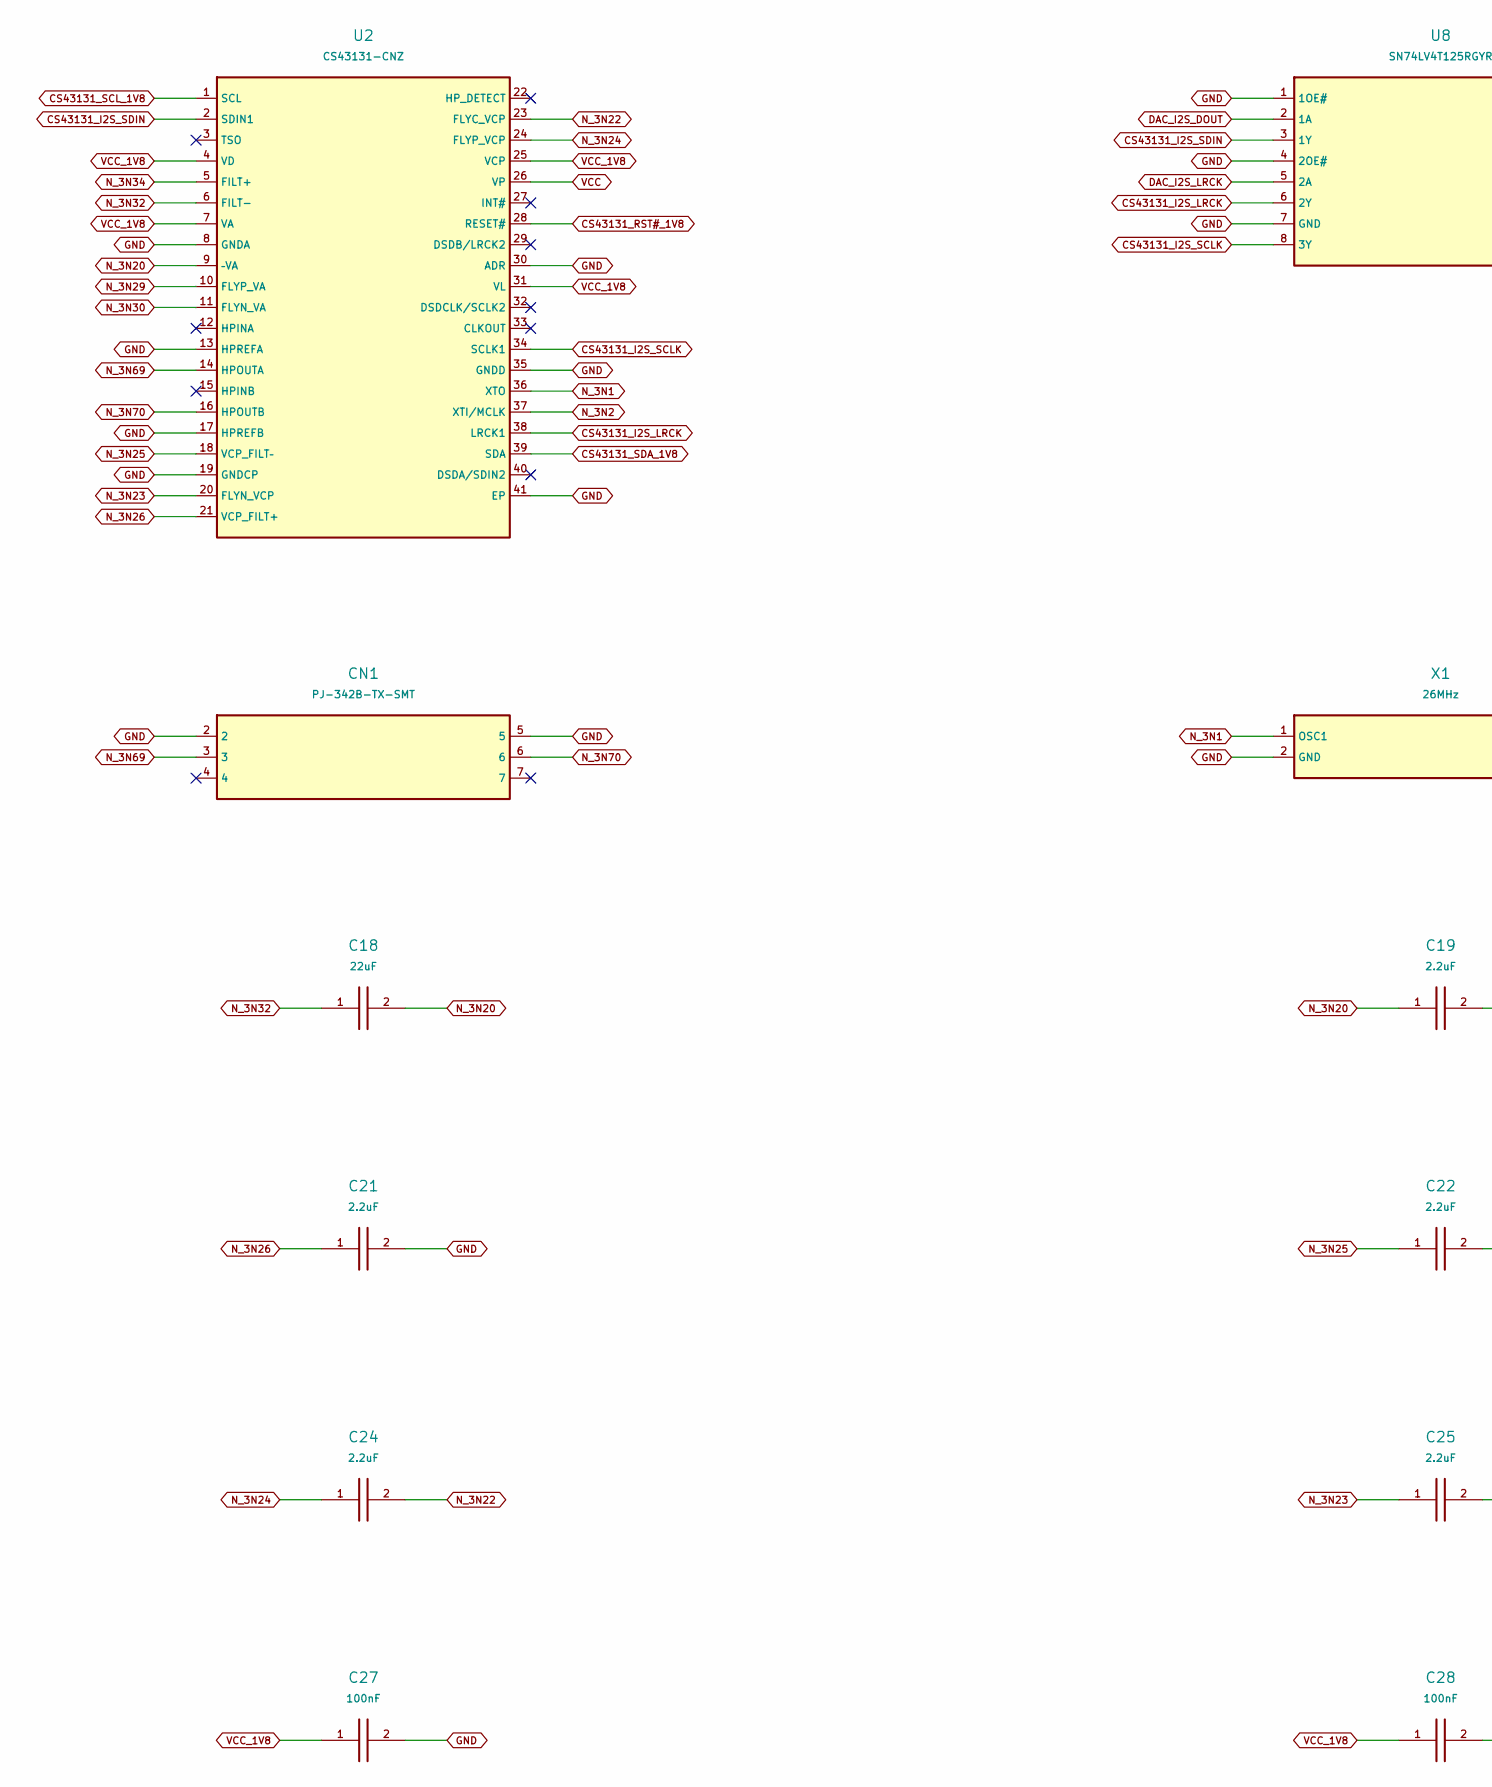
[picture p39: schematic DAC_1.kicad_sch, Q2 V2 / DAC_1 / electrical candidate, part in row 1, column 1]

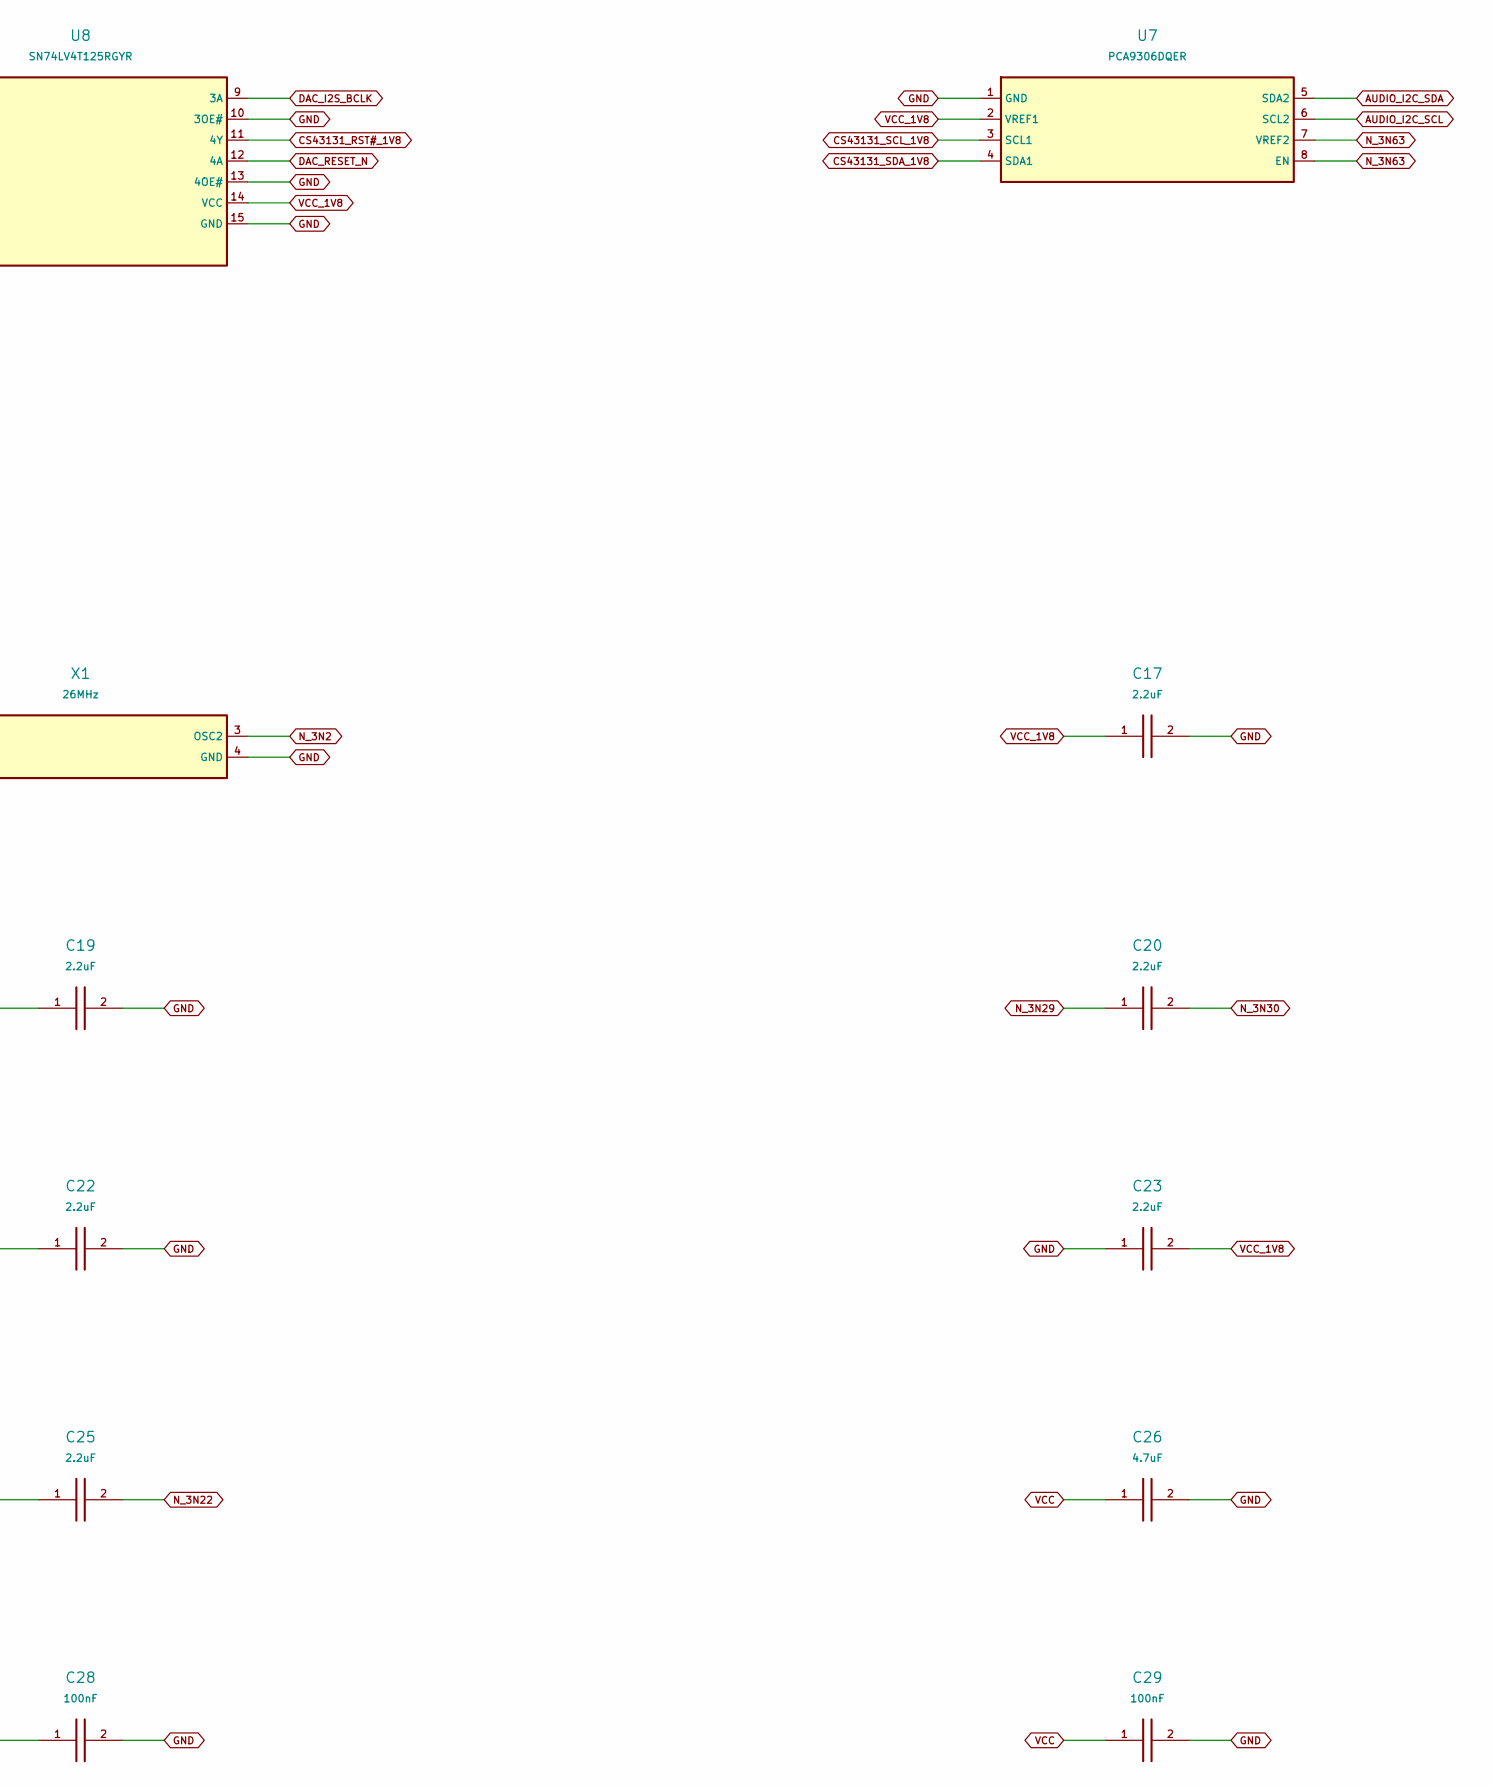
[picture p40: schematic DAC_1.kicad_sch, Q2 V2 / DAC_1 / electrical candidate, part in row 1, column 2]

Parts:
C17, C19, C20, C21, C22, C23, C24, C25: 2.2uF; C_0402_1005Metric
C18: 22uF; FP_C18
C26: 4.7uF; C_0402_1005Metric
C27, C28, C29: 100nF; C_0402_1005Metric
CN1: PJ-342B-TX-SMT; FP_CN1
U2: CS43131-CNZ; FP_U2
U7: PCA9306DQER; FP_U7
U8: SN74LV4T125RGYR; FP_U8
X1: 26MHz; FP_X1

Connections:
AUDIO_I2C_SCL: U7.6 (SCL2); also elsewhere on the board
AUDIO_I2C_SDA: U7.5 (SDA2); also elsewhere on the board
CS43131_I2S_LRCK: U2.38 (LRCK1), U8.6 (2Y)
CS43131_I2S_SCLK: U2.34 (SCLK1), U8.8 (3Y)
CS43131_I2S_SDIN: U2.2 (SDIN1), U8.3 (1Y)
CS43131_RST#_1V8: U2.28 (RESET#), U8.11 (4Y)
CS43131_SCL_1V8: U2.1 (SCL), U7.3 (SCL1); also elsewhere on the board
CS43131_SDA_1V8: U2.39 (SDA), U7.4 (SDA1); also elsewhere on the board
DAC_I2S_BCLK: U8.9 (3A); also elsewhere on the board
DAC_I2S_DOUT: U8.2 (1A); also elsewhere on the board
DAC_I2S_LRCK: U8.5 (2A); also elsewhere on the board
DAC_RESET_N: U8.12 (4A); also elsewhere on the board
GND: C17.2, C19.2, C21.2, C22.2, C23.1, C26.2, C27.2, C28.2, C29.2, CN1.2, CN1.5, U2.8 (GNDA), U2.13 (HPREFA), U2.17 (HPREFB), U2.19 (GNDCP), U2.30 (ADR), U2.35 (GNDD), U2.41 (EP), U7.1 (GND), U8.1 (1OE#), U8.4 (2OE#), U8.7 (GND), U8.10 (3OE#), U8.13 (4OE#), U8.15 (GND), X1.2 (GND), X1.4 (GND); also elsewhere on the board
N_3N1: U2.36 (XTO), X1.1 (OSC1); also elsewhere on the board
N_3N2: U2.37 (XTI/MCLK), X1.3 (OSC2); also elsewhere on the board
N_3N20: C18.2, C19.1, U2.9 (–VA)
N_3N22: C24.2, C25.2, U2.23 (FLYC_VCP)
N_3N23: C25.1, U2.20 (FLYN_VCP)
N_3N24: C24.1, U2.24 (FLYP_VCP)
N_3N25: C22.1, U2.18 (VCP_FILT–)
N_3N26: C21.1, U2.21 (VCP_FILT+)
N_3N29: C20.1, U2.10 (FLYP_VA)
N_3N30: C20.2, U2.11 (FLYN_VA)
N_3N32: C18.1, U2.6 (FILT-)
N_3N34: U2.5 (FILT+); also elsewhere on the board
N_3N63: U7.7 (VREF2), U7.8 (EN); also elsewhere on the board
N_3N69: CN1.3, U2.14 (HPOUTA)
N_3N70: CN1.6, U2.16 (HPOUTB)
VCC: C26.1, C29.1, U2.26 (VP); also elsewhere on the board
VCC_1V8: C17.1, C23.2, C27.1, C28.1, U2.4 (VD), U2.7 (VA), U2.25 (VCP), U2.31 (VL), U7.2 (VREF1), U8.14 (VCC); also elsewhere on the board

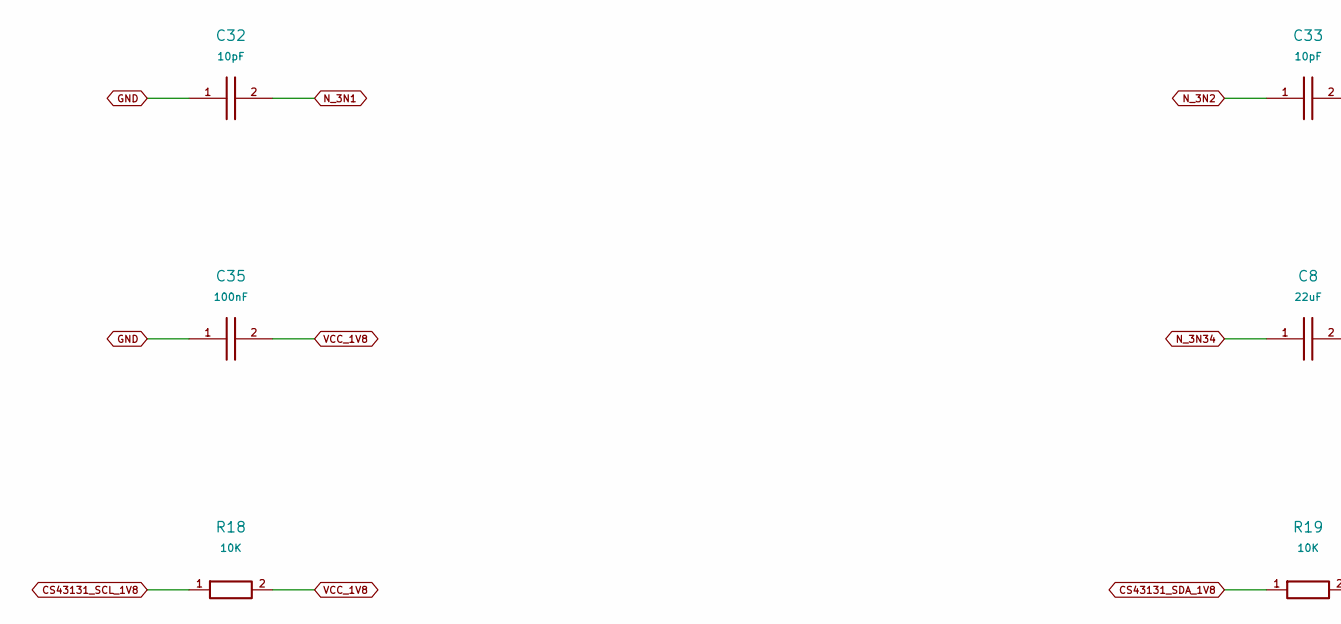
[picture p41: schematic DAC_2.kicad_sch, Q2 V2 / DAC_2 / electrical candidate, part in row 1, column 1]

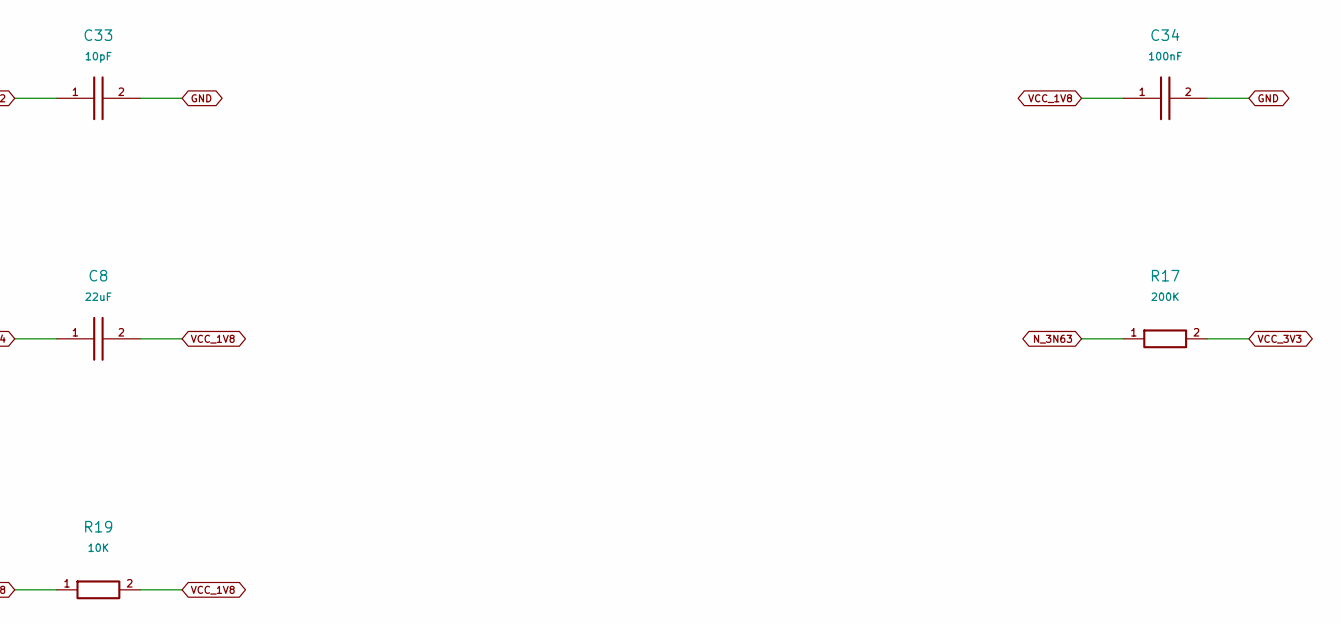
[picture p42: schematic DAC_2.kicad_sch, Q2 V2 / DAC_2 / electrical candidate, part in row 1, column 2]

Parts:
C8: 22uF; FP_C8
C32, C33: 10pF; C_0402_1005Metric
C34, C35: 100nF; C_0402_1005Metric
R17: 200K; R_0402_1005Metric
R18, R19: 10K; R_0402_1005Metric

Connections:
CS43131_SCL_1V8: R18.1; also elsewhere on the board
CS43131_SDA_1V8: R19.1; also elsewhere on the board
GND: C32.1, C33.2, C34.2, C35.1; also elsewhere on the board
N_3N1: C32.2; also elsewhere on the board
N_3N2: C33.1; also elsewhere on the board
N_3N34: C8.1; also elsewhere on the board
N_3N63: R17.1; also elsewhere on the board
VCC_1V8: C8.2, C34.1, C35.2, R18.2, R19.2; also elsewhere on the board
VCC_3V3: R17.2; also elsewhere on the board

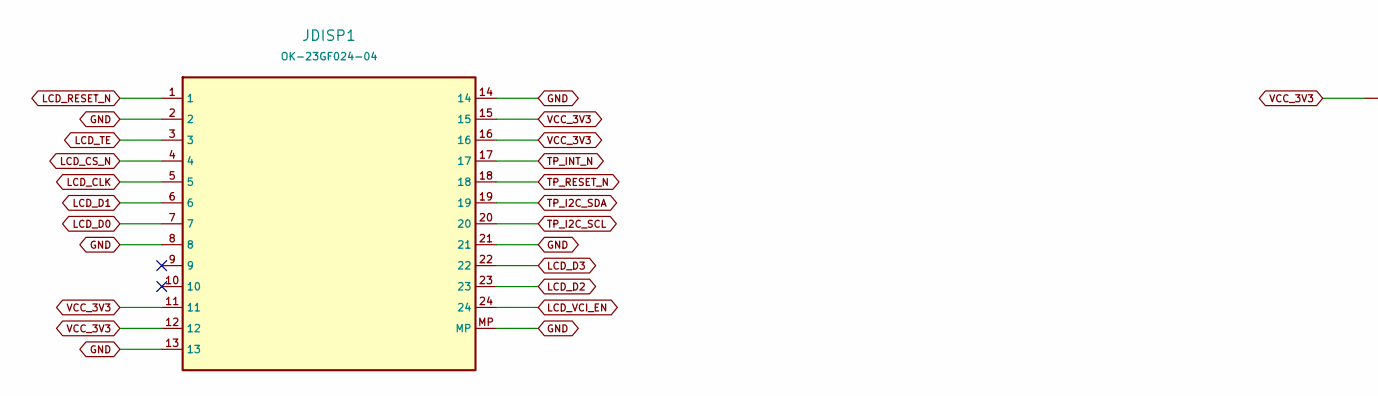
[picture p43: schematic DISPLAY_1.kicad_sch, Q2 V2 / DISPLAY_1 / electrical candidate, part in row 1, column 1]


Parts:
C136: 100nF; C_0402_1005Metric
C137: 4.7uF; C_0402_1005Metric
JDISP1: OK-23GF024-04; FP_JDISP1

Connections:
GND: C136.2, C137.2, JDISP1.2, JDISP1.8, JDISP1.13, JDISP1.14, JDISP1.21, JDISP1.MP; also elsewhere on the board
LCD_CLK: JDISP1.5; also elsewhere on the board
LCD_CS_N: JDISP1.4; also elsewhere on the board
LCD_D0: JDISP1.7; also elsewhere on the board
LCD_D1: JDISP1.6; also elsewhere on the board
LCD_D2: JDISP1.23; also elsewhere on the board
LCD_D3: JDISP1.22; also elsewhere on the board
LCD_RESET_N: JDISP1.1; also elsewhere on the board
LCD_TE: JDISP1.3; also elsewhere on the board
LCD_VCI_EN: JDISP1.24; also elsewhere on the board
TP_I2C_SCL: JDISP1.20; also elsewhere on the board
TP_I2C_SDA: JDISP1.19; also elsewhere on the board
TP_INT_N: JDISP1.17; also elsewhere on the board
TP_RESET_N: JDISP1.18; also elsewhere on the board
VCC_3V3: C136.1, C137.1, JDISP1.11, JDISP1.12, JDISP1.15, JDISP1.16; also elsewhere on the board



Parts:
Q106: MMBT3904; FP_Q106
Q107: MMBT3904; FP_Q107
R132, R133: 10k; R_0402_1005Metric
TP101: GND; FP_TP101
TP102: CHIP_PU; FP_TP102
TP103: BOOT_DOWNLOAD_N; FP_TP103
TP104: USB_DEBUG_DM; FP_TP104
TP105: USB_DEBUG_DP; FP_TP105
TP106: VCC_3V3; FP_TP106

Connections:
AUTO_BOOT_B: Q107.1 (B), R133.2
AUTO_EN_B: Q106.1 (B), R132.2
BOOT_DOWNLOAD_N: Q107.3 (C), TP103.1; also elsewhere on the board
CH343P_UART_DTR: Q107.2 (E), R132.1; also elsewhere on the board
CH343P_UART_RTS: Q106.2 (E), R133.1; also elsewhere on the board
CHIP_PU: Q106.3 (C), TP102.1; also elsewhere on the board
GND: TP101.1; also elsewhere on the board
USB_DEBUG_DM: TP104.1; also elsewhere on the board
USB_DEBUG_DP: TP105.1; also elsewhere on the board
VCC_3V3: TP106.1; also elsewhere on the board

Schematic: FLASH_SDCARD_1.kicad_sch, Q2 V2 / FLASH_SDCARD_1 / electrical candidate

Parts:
C49: 10uF; C_0402_1005Metric
C50: 100nF; C_0402_1005Metric
CARD2: TF PUSH; FP_CARD2

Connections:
GND: C49.1, C50.1, CARD2.6 (VSS), CARD2.10 (EP), CARD2.11 (EP), CARD2.12 (EP), CARD2.13 (EP); also elsewhere on the board
SD_CARD_DETECT_N: CARD2.CD; also elsewhere on the board
SD_CLK: CARD2.5 (CLX); also elsewhere on the board
SD_CMD: CARD2.3 (CMD); also elsewhere on the board
SD_D0: CARD2.7 (DAT0); also elsewhere on the board
SD_D1: CARD2.8 (DAT1); also elsewhere on the board
SD_D2: CARD2.1 (DAT2); also elsewhere on the board
SD_D3: CARD2.2 (CD/DAT3); also elsewhere on the board
VCC_3V3: C49.2, C50.2, CARD2.4 (VDD); also elsewhere on the board

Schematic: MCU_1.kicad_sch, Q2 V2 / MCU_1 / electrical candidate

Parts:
C13: 100nF; C_0402_1005Metric
C39: 1uF; C_0402_1005Metric
R6, R7, R10, R20, R22, R25, R26, R29, R30, R35, R36, R37, R38, R39, R42, R43, R44, R45, R46: 10K; R_0402_1005Metric

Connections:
AUDIO_I2C_SCL: R26.2; also elsewhere on the board
AUDIO_I2C_SDA: R30.2; also elsewhere on the board
BAT_ALERT_N: R6.2; also elsewhere on the board
BOOT_DOWNLOAD_N: R20.2; also elsewhere on the board
BOOT_MODE_H: R25.2; also elsewhere on the board
CHG_INT_N: R43.2; also elsewhere on the board
CHIP_PU: C39.1, R29.1; also elsewhere on the board
GND: C13.2, C39.2, R22.1, R44.1; also elsewhere on the board
MCU_VDD_SPI: C13.1; also elsewhere on the board
MOTOR_EN: R44.2; also elsewhere on the board
RTC_INT_N: R42.1; also elsewhere on the board
SD_CMD: R39.2; also elsewhere on the board
SD_D0: R38.2; also elsewhere on the board
SD_D1: R35.2; also elsewhere on the board
SD_D2: R36.2; also elsewhere on the board
SD_D3: R37.2; also elsewhere on the board
SYS_I2C_SCL: R7.2; also elsewhere on the board
TP_I2C_SCL: R45.2; also elsewhere on the board
TP_I2C_SDA: R46.2; also elsewhere on the board
USB_PATH_SEL: R10.2, R22.2; also elsewhere on the board
VCC_3V3: R6.1, R7.1, R10.1, R20.1, R25.1, R26.1, R29.2, R30.1, R35.1, R36.1, R37.1, R38.1, R39.1, R42.2, R43.1, R45.1, R46.1; also elsewhere on the board

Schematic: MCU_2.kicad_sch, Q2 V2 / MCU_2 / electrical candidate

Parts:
R8: 10K; R_0402_1005Metric

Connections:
SYS_I2C_SDA: R8.2; also elsewhere on the board
VCC_3V3: R8.1; also elsewhere on the board

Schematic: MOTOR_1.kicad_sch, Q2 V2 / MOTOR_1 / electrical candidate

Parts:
C4, C5: 1uF; C_0402_1005Metric
C58: 100nF; C_0402_1005Metric
CN3: Solder wire pads; FP_CN3
L3: BLM18KG601SN1D; FP_L3
U11: DRV2605LDGSR; FP_U11

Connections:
GND: C4.1, C5.1, C58.1, U11.4 (IN/TRIG), U11.8 (GND); also elsewhere on the board
MOTOR_EN: U11.5 (EN); also elsewhere on the board
MOTOR_OUT_N: CN3.2, U11.9 (OUT-)
MOTOR_OUT_P: CN3.1, U11.7 (OUT+)
N_5N6: C4.2, U11.1 (REG)
N_5N15: C5.2, C58.2, L3.1, U11.6 (VDD/NC), U11.10 (VDD)
SYS_I2C_SCL: U11.2 (SCL); also elsewhere on the board
SYS_I2C_SDA: U11.3 (SDA); also elsewhere on the board
VCC_PMID: L3.2; also elsewhere on the board

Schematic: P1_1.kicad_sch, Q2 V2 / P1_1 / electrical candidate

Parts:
SCREW1: FP_SCREW1
SCREW2: FP_SCREW2
SCREW3: FP_SCREW3
SCREW5: FP_SCREW5

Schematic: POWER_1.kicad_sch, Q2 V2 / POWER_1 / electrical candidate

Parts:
C1: 10uF; FP_C1
C2: 10uF; FP_C2
C3: 100nF; C_0402_1005Metric
C10: 10uF; FP_C10
C11: 47nF; C_0402_1005Metric
C12: 10uF; FP_C12
C14: 1uF; FP_C14
C15: 10uF; FP_C15
C16: 47uF; FP_C16
C30, C31: 1uF; C_0402_1005Metric
C43: 220nF; C_0402_1005Metric
CN2: Solder wire pads; FP_CN2
U3: DSCB_BQ25895RTW; FP_U3
U4: TLV62568DBVR; FP_U4
U5: ME6211C18M5G-N; FP_U5
U6: GEK100; FP_U6
U14: STC3115AIQT; FP_U14

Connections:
BAT_ALERT_N: U14.1 (ALM); also elsewhere on the board
BAT_TS: CN2.2, U3.11 (TS); also elsewhere on the board
BQ25895_CHG_EN#: U3.9 (~CE); also elsewhere on the board
CHG_INT_N: U3.7 (INT); also elsewhere on the board
CHG_OTG_EN: U3.8 (OTG); also elsewhere on the board
GBAT: CN2.3, U14.6 (CG); also elsewhere on the board
GEK_RST: U6.3 (RST); also elsewhere on the board
GND: C1.1, C2.1, C3.1, C10.1, C12.1, C14.1, C15.1, C16.2, C30.1, C31.1, C43.2, U3.17 (PGND), U3.18 (PGND), U3.25 (PGND), U4.2 (GND), U5.2 (VSS), U6.2 (GND), U14.5 (GND); also elsewhere on the board
KEY_RAW_N: U6.1 (KEY); also elsewhere on the board
N_2N13: C11.1, U3.21 (BTST)
N_2N14: C11.2, U3.19 (SW), U3.20 (SW); also elsewhere on the board
N_2N16: U3.22 (REGN); also elsewhere on the board
N_2N19: U3.10 (ILIM); also elsewhere on the board
N_2N84: U4.3 (SW); also elsewhere on the board
N_2N86: U4.5 (FB); also elsewhere on the board
N_2N133: U14.8 (BATD/CD); also elsewhere on the board
N_2N157: U14.10 (VIN); also elsewhere on the board
PWR_3V3_EN: U4.1 (EN), U6.5 (OUTH); also elsewhere on the board
SYS_I2C_SCL: U3.5 (SCL), U14.3 (SCL); also elsewhere on the board
SYS_I2C_SDA: U3.6 (SDA), U14.2 (SDA); also elsewhere on the board
VBAT: C10.2, C43.1, CN2.1, U3.13 (BAT), U3.14 (BAT), U14.9 (VCC); also elsewhere on the board
VBUS_5V: C14.2, U3.1 (VBUS); also elsewhere on the board
VCC: C1.2, C3.2, C12.2, C15.2, C30.2, U3.15 (SYS), U3.16 (SYS), U4.4 (VIN), U5.1 (VIN), U5.3 (CE); also elsewhere on the board
VCC_1V8: C31.2, U5.5 (VOUT); also elsewhere on the board
VCC_3V3: C2.2; also elsewhere on the board
VCC_3V3_AON: U6.6 (VDD); also elsewhere on the board
VCC_PMID: C16.1, U3.23 (PMID); also elsewhere on the board

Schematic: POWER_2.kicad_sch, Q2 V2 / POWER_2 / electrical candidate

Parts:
C9: 4.7uF; FP_C9
C61: 220nF; C_0402_1005Metric
D2: B5817W; FP_D2
L1: 2.2uH; FP_L1
L2: 2.2uH; FP_L2
R1: 10mΩ; FP_R1
R2, R33: 1K; R_0402_1005Metric
R3: 22K1; R_0402_1005Metric
R4, R5, R11, R12: 100K; R_0402_1005Metric
R9: 700R; R_0402_1005Metric
R13: 5K23; R_0402_1005Metric
R14: 30K1; R_0402_1005Metric
R34: 0R; R_0402_1005Metric

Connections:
BAT_TS: R13.2, R14.2; also elsewhere on the board
BQ25895_CHG_EN#: R11.2; also elsewhere on the board
CHG_OTG_EN: R12.2; also elsewhere on the board
GBAT: R1.1, R34.1; also elsewhere on the board
GND: C9.2, C61.2, R1.2, R3.1, R5.1, R9.1, R11.1, R12.1, R14.1; also elsewhere on the board
N_2N14: D2.2 (A), L2.1; also elsewhere on the board
N_2N16: C9.1, R13.1; also elsewhere on the board
N_2N19: R9.2; also elsewhere on the board
N_2N84: L1.1; also elsewhere on the board
N_2N86: R3.2, R4.1; also elsewhere on the board
N_2N133: R33.1; also elsewhere on the board
N_2N135: R33.2, R34.2
N_2N157: C61.1, R2.1; also elsewhere on the board
PWR_3V3_EN: R5.2; also elsewhere on the board
VBAT: R2.2; also elsewhere on the board
VCC: L2.2; also elsewhere on the board
VCC_3V3: L1.2, R4.2; also elsewhere on the board
VCC_PMID: D2.1 (C); also elsewhere on the board

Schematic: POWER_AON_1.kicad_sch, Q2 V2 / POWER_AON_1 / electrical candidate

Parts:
C130, C131: 2.2uF; C_0402_1005Metric
C132, C134, C135: 100nF; C_0402_1005Metric
C133: 1uF; C_0402_1005Metric
Q101: BSS138; FP_Q101
Q102: BSS138; FP_Q102
Q103: BSS138; FP_Q103
Q104: BSS138; FP_Q104
Q105: BSS138; FP_Q105
R128: 10k; R_0402_1005Metric
R129, R131: 100k; R_0402_1005Metric
R130: 200k; R_0402_1005Metric
U20: TLV75533PDBVR; FP_U20
U21: SN74LVC1G123DCUR; FP_U21

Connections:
CTRL_INT_AON_N: Q103.3 (D); also elsewhere on the board
CTRL_INT_N: Q103.2 (S); also elsewhere on the board
CTRL_RESET_AON_N: Q104.3 (D); also elsewhere on the board
CTRL_RESET_N: Q104.2 (S), R128.2; also elsewhere on the board
CTRL_SCL_AON: Q102.3 (D); also elsewhere on the board
CTRL_SDA_AON: Q101.3 (D); also elsewhere on the board
GEK_RST: U21.5 (Q); also elsewhere on the board
GND: C130.2, C131.2, C132.2, C134.2, C135.2, R129.2, U20.2 (GND), U21.1 (A_N), U21.4 (GND); also elsewhere on the board
KEY_POWER_SENSE_N: Q105.2 (S); also elsewhere on the board
KEY_RAW_N: Q105.3 (D); also elsewhere on the board
OFF_CEXT: C133.1, U21.6 (CEXT)
OFF_CLEAR_N: C134.1, R131.2, U21.3 (CLR_N)
OFF_RC: C133.2, R130.2, U21.7 (REXT_CEXT)
POWER_OFF_REQ: R129.1, U21.2 (B); also elsewhere on the board
SYS_I2C_SCL: Q102.2 (S); also elsewhere on the board
SYS_I2C_SDA: Q101.2 (S); also elsewhere on the board
VCC: C130.1, U20.1 (IN), U20.3 (EN); also elsewhere on the board
VCC_3V3: Q101.1 (G), Q102.1 (G), Q103.1 (G), Q104.1 (G), Q105.1 (G), R128.1; also elsewhere on the board
VCC_3V3_AON: C131.1, C132.1, C135.1, R130.1, R131.1, U20.5 (OUT), U21.8 (VCC); also elsewhere on the board

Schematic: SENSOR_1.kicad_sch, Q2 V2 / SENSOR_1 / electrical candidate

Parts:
C6, C7, C47, C48, C53: 100nF; C_0402_1005Metric
C54: 1uF; C_0402_1005Metric
U1: RX8130CE:BB; FP_U1
U15: LSM6DS3TR-C; FP_U15

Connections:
AUDIO_I2C_SCL: U15.13 (SCL); also elsewhere on the board
AUDIO_I2C_SDA: U15.14 (SDA); also elsewhere on the board
GND: C6.2, C7.2, C47.2, C48.2, C53.2, C54.2, U1.7 (GND), U15.2 (SDx), U15.3 (SCx), U15.6 (GND), U15.7 (GND); also elsewhere on the board
IMU_INT1: U15.4 (INT1); also elsewhere on the board
N_7N55: C54.1, U1.9 (VOUT)
RTC_INT_N: U1.6 (#IRQ); also elsewhere on the board
SYS_I2C_SCL: U1.2 (SCL); also elsewhere on the board
SYS_I2C_SDA: U1.3 (SDA); also elsewhere on the board
VBAT: C7.1, U1.10 (VBAT); also elsewhere on the board
VCC_3V3: C6.1, C47.1, C48.1, C53.1, U1.1 (Vio), U1.8 (VDD), U15.1 (SDO/SA0), U15.5 (VDDIO), U15.8 (VDD), U15.12 (CS); also elsewhere on the board

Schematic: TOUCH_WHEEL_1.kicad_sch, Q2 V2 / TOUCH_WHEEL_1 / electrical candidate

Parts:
C59: 100nF; C_0402_1005Metric
FPC1: HC-FPC-05-10-12RLTAG; FP_FPC1

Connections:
CTRL_INT_AON_N: FPC1.5; also elsewhere on the board
CTRL_RESET_AON_N: FPC1.6; also elsewhere on the board
CTRL_SCL_AON: FPC1.4; also elsewhere on the board
CTRL_SDA_AON: FPC1.3; also elsewhere on the board
GND: C59.2, FPC1.1, FPC1.12, FPC1.13, FPC1.14; also elsewhere on the board
KEY_RAW_N: FPC1.11; also elsewhere on the board
VCC_3V3: C59.1; also elsewhere on the board
VCC_3V3_AON: FPC1.2; also elsewhere on the board

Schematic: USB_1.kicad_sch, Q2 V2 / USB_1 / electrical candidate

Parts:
C36, C37, C38, C44, C51: 100nF; C_0402_1005Metric
D1: USBLC6-2SC6; FP_D1
R21: 100K; R_0402_1005Metric
R31, R32: 5K1; R_0402_1005Metric
U12: CH343P; FP_U12
U17: SGM7229YMS10G/TR; FP_U17
USB1: TYPE-C 16PIN 2MD(073); FP_USB1

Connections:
CH343P_UART_DTR: U12.12 (DTRTNOW); also elsewhere on the board
CH343P_UART_RTS: U12.13 (RTS); also elsewhere on the board
CH343P_USB_DN: U12.8 (UD-), U17.8 (HSD2-)
CH343P_USB_DP: U12.7 (UD+), U17.9 (HSD2+)
GND: C36.2, C37.2, C38.2, C44.2, C51.2, D1.2 (GND), R21.1, R31.1, R32.1, U12.2 (GND), U12.17 (EP), U17.5 (GND), USB1.13 (EH), USB1.14 (EH), USB1.A1B12 (GND), USB1.B1A12 (GND); also elsewhere on the board
N_6N45: R32.2, USB1.B5 (CC2)
N_6N46: R31.2, USB1.A5 (CC1)
N_6N67: C38.1, U12.6 (V3)
SGM7227_EN#: R21.2, U17.10 (OE#)
TYPEC_USB_DN: D1.4 (I/O2), U17.4 (D-)
TYPEC_USB_DN_IN: D1.3 (I/O2), USB1.A7 (Dn1), USB1.B7 (Dn2)
TYPEC_USB_DP: D1.6 (I/O1), U17.3 (D+)
TYPEC_USB_DP_IN: D1.1 (I/O1), USB1.A6 (Dp1), USB1.B6 (Dp2)
UART0_RX: U12.4 (TXD); also elsewhere on the board
UART0_TX: U12.5 (RXD); also elsewhere on the board
USB_HS_DM: U17.6 (HSD1-); also elsewhere on the board
USB_HS_DP: U17.7 (HSD1+); also elsewhere on the board
USB_PATH_SEL: U17.2 (S); also elsewhere on the board
VBUS_5V: C36.1, C44.1, C51.1, D1.5 (VBUS), U12.3 (VDD5), U12.9 (VBUS), U17.1 (VCC), USB1.A4B9 (VBUS), USB1.B4A9 (VBUS); also elsewhere on the board
VCC_3V3: C37.1, U12.1 (VIO); also elsewhere on the board



Board: 6 copper layers, 46.0 x 76.0 mm, 198 parts (83 on the bottom side), 144 nets.

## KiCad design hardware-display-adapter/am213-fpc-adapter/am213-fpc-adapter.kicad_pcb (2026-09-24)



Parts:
C1, C3, C4: 100nF; C0402
C2: 10uF; C0603
J1: 21P 0.3mm FPC fingers; FPC21_Fingers
J2: OK-23GF024-04; OK23GF024
R1: 22R; R0402
R2, R3, R4, R5, R6, R7, R8: 0R; R0402
R9: 100k; R0402
R10, R11: 4.7k; R0402; not fitted
TP1: TE 3V3; TP

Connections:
/CLK_IN: J1.5 (ESP_SPI2_CLK), R1.1
/CS_IN: J1.7 (ESP_SPI2_CS), R2.1
/D0_IN: J1.11 (ESP_SPI2_D0), R3.1
/D1_IN: J1.10 (ESP_SPI2_D1), R4.1
/D2_IN: J1.9 (ESP_SPI2_D2), R5.1
/D3_IN: J1.8 (ESP_SPI2_D3), R6.1
/GND: C1.2, C2.2, C3.2, C4.2, J1.12 (GND), J1.17 (GND), J2.2 (GND), J2.8 (GND), J2.13 (GND), J2.14 (GND), J2.21 (GND), J2.MP (MOUNT_GND), R9.2
/LCD_CLK: J2.5 (LCD_CLK), R1.2
/LCD_CS: J2.4 (LCD_CS), R2.2
/LCD_D0: J2.7 (LCD_D0), R3.2
/LCD_D1: J2.6 (LCD_D1), R4.2
/LCD_D2: J2.23 (LCD_D2), R5.2
/LCD_D3: J2.22 (LCD_D3), R6.2
/LCD_RST: J1.3 (ESP_IO47), J2.1 (LCD_RST)
/LCD_TE: J2.3 (LCD_TE), TP1.1
/LCD_VDD: C3.1, J2.15 (VDD), R7.2
/TP_INT: J1.18 (ESP_IO54), J2.17 (TP_INT)
/TP_RST: J1.21 (ESP_IO57), J2.18 (TP_RST)
/TP_SCL: J1.19 (ESP_I2C2_SCL), J2.20 (TP_SCL), R11.2
/TP_SDA: J1.20 (ESP_I2C2_SDA), J2.19 (TP_SDA), R10.2
/TP_VDD: C4.1, J2.16 (TP_VDD), R8.2
/VCC_3V3: C1.1, C2.1, J1.13 (VCC_3V3), J1.14 (VCC_3V3), J2.11 (VBAT), J2.12 (VBAT), R7.1, R8.1, R10.1, R11.1
/VCI_EN: J1.4 (ESP_IO46), J2.24 (VCI_EN), R9.1

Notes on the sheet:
OSPTEK AM213 reference: 3.3V direct QSPI/I2C; no level shifters. J1.1/2 old backlight isolated; J1.6/15/16 unused. IO46 -> VCI_EN, IO47 -> LCD_RST, IO57 -> TP_RST. R10/R11 DNP: host I2C pull-ups R45/R46 present. 70mm tail is mechanical candidate; confirm folding/stack with flex fabricator. No TE to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


Board: 2 copper layers, 87.0 x 22.0 mm, 18 parts (0 on the bottom side), 23 nets.

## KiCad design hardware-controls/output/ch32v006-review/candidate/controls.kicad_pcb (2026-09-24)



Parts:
C1, C3: 100nF; C0402
C2: 1uF; C0402
E1: 31mm INTERPOLATED WHEEL; Wheel_D31
H1, H2, H3, H4: M1.6 / NPTH 1.8; Mount_1.8
J1: HC-FPC-05-10-12RLTAG; HCTL_FPC12
J2: WCH_SDI_PADS; SDI_4_Pads
R1, R2, R3: 1k; R0402
R4, R5: 4.7k; R0402
R6, R7, R14: 10k; R0402
R8: 0R; R0402
R9, R10, R11, R12: 47k; R0402
SW1, SW2, SW3, SW4, SW5: SKSWCEE010; SKSW_3x2
U1: CH32V006F8U6; CH32V006_QFN20

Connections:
/+3V3: J1.2, R4.1, R5.1, R6.1, R7.1, R8.1, R9.1, R10.1, R11.1, R12.1, R14.1
/GND: C1.2, C2.2, C3.2, J1.1, J1.12, J1.13 (SHIELD), J1.14 (SHIELD), J2.3 (GND), SW1.2, SW2.2, SW3.2, SW4.2, SW5.2, U1.0 (VSS_EP), U1.4 (VSS)
/INT_N: J1.5, R6.2, U1.7 (PC0/INT)
/KEY_BACK: R9.2, SW2.1, U1.10 (PC3)
/KEY_NEXT: R11.2, SW4.1, U1.13 (PC6)
/KEY_PLAY: R12.2, SW5.1, U1.14 (PC7)
/KEY_POWER: J1.11, R14.2, SW1.1
/KEY_PREV: R10.2, SW3.1, U1.12 (PC5)
/RESET_N: C3.1, J1.6, J2.4 (RESET_N), R7.2, U1.1 (PD7/~RST)
/SCL: J1.4, R5.2, U1.9 (PC2/SCL)
/SDA: J1.3, R4.2, U1.8 (PC1/SDA)
/SENSE0: R1.2, U1.16 (PD2/TKEY3)
/SENSE1: R2.2, U1.17 (PD3/TKEY4)
/SENSE2: R3.2, U1.18 (PD4/TKEY7)
/SWIO: J2.2 (SWIO), U1.15 (PD1/SWIO)
/VDD_MCU: C1.1, C2.1, J2.1 (VREF_3V3), R8.2, U1.6 (VDD)
/WHEEL0: E1.1 (CH0), R1.1
/WHEEL1: E1.2 (CH1), R2.1
/WHEEL2: E1.3 (CH2), R3.1

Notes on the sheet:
01 CH32V006 / 3-ELECTRODE WHEEL
02 MCU POWER / RESET
03 FOUR GPIO KEYS + INDEPENDENT POWER
04 SINGLE-WIRE SDI PROGRAMMING
05 MECHANICAL MOUNTS
3.3 V ONLY. J1 pinout and position unchanged. I2C target address 0x1C, CUSTOM register protocol. INT_N = PC0 open-drain output, active low. PD7/RST requires reset option-byte configuration.
SW1 POWER is electrically independent of U1. R14 pull-up remains on +3V3; press shorts to GND. Four ordinary keys report through MCU I2C.
J2 has bare pads only: VREF, SWIO, GND, RESET. Keep PD1 single-wire debug enabled. Do not fit the old AT42QT2120 or TCA6408A.
PROTOTYPE: firmware and final-cover calibration required. MCU touch SDK includes wheel interpolation; validate circular wrap, noise while charging and standby current before production.



Board: 2 copper layers, 44.0 x 34.0 mm, 29 parts (19 on the bottom side), 19 nets.

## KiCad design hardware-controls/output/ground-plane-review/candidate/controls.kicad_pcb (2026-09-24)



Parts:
C1, C3, C4: 100nF; C0402
C2: 1uF; C0402
E1: 31mm INTERPOLATED WHEEL; Wheel_D31
H1, H2, H3, H4: M1.6 / NPTH 1.8; Mount_1.8
J1: HC-FPC-05-10-12RLTAG; HCTL_FPC12
R1, R2, R3, R6, R7, R13, R14: 10k; R0402
R4, R5: 4.7k; R0402
R8: 22R; R0402
R9, R10, R11, R12: 47k; R0402
SW1, SW2, SW3, SW4, SW5: SKSWCEE010; SKSW_3x2
TP1: +3V3; TestPad
TP2: GND; TestPad
TP3: SDA; TestPad
TP4: SCL; TestPad
TP5: INT_N; TestPad
TP6: RESET_N; TestPad
TP7: KEY_POWER; TestPad
TP8: KEY_BACK; TestPad
TP9: KEY_PREV; TestPad
TP10: KEY_NEXT; TestPad
TP11: KEY_PLAY; TestPad
U1: AT42QT2120-MMHR; QT2120_VQFN20
U2: TCA6408ARGTR; TCA6408A_VQFN16

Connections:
/+3V3: C3.1, C4.1, J1.2, R4.1, R5.1, R6.1, R7.1, R8.1, R9.1, R10.1, R11.1, R12.1, R14.1, TP1.1, U2.14 (VCCP), U2.15 (VCCI)
/GND: C1.2, C2.2, C3.2, C4.2, J1.1, J1.12, J1.13 (SHIELD), J1.14 (SHIELD), R13.2, SW1.2, SW2.2, SW3.2, SW4.2, SW5.2, TP2.1, U1.8 (VSS), U1.10 (MODE), U1.21 (EP), U2.6 (GND), U2.16 (ADDR), U2.17 (EP)
/INT_N: J1.5, R6.2, TP5.1, U1.15 (~CHANGE), U2.11 (~INT)
/KEY_BACK: R9.2, SW2.1, TP8.1, U2.2 (P0)
/KEY_NEXT: R11.2, SW4.1, TP10.1, U2.4 (P2)
/KEY_PLAY: R12.2, SW5.1, TP11.1, U2.5 (P3)
/KEY_POWER: J1.11, R14.2, SW1.1, TP7.1
/KEY_PREV: R10.2, SW3.1, TP9.1, U2.3 (P1)
/RESET_N: J1.6, R7.2, TP6.1, U1.12 (~RESET), U2.1 (~RESET)
/SCL: J1.4, R5.2, TP4.1, U1.14 (SCL), U2.12 (SCL)
/SDA: J1.3, R4.2, TP3.1, U1.11 (SDA), U2.13 (SDA)
/SENSE0: R1.2, U1.7 (KEY0)
/SENSE1: R2.2, U1.6 (KEY1)
/SENSE2: R3.2, U1.5 (KEY2)
/UNUSED_INPUTS: R13.1, U2.7 (P4), U2.8 (P5), U2.9 (P6), U2.10 (P7)
/VDD_TOUCH: C1.1, C2.1, R8.2, U1.9 (VDD)
/WHEEL0: E1.1 (CH0), R1.1
/WHEEL1: E1.2 (CH1), R2.1
/WHEEL2: E1.3 (CH2), R3.1

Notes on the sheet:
01 TOUCH WHEEL / 3.3 V / I2C 0x1C
02 POWER AND LOCAL DECOUPLING
03 FOUR I2C KEYS + INDEPENDENT POWER
04 LOCAL BENCH TEST PADS
05 REVISION-F MECHANICAL MOUNTS
06 I2C KEY INPUTS / 0x20
J1 is reserved for a future host. No mainboard connection in this revision. Supply regulated 3.3 V at J1 or TP1/TP2 for bench testing. Do not apply battery voltage to the 3.3 V rail.
SW2..SW5 -> U2 P0..P3, active low. Debounce in firmware. SW1 POWER -> J1.11; R14 10k pull-up to +3V3. Released HIGH, pressed LOW; independent of U1/U2. J1.7..10 are NC. TP8..11 are local debug pads only.
Enable wheel: register 0x0E = 0xC0. Disable unused KEY3..11. Firmware configuration and final-cover calibration are required. Electrode shape includes switch clearances; verify 360-degree tracking.
U2 P4..P7 share R13 pull-down. Keep 0x03 = 0xFF (all inputs). Polarity 0x02 = 0x00; read 0x00, pressed = (~value) & 0x0F. INT_N is wired-OR: read BOTH devices until interrupt releases. RESET_N resets both ICs; reinitialize both after reset.



Board: 2 copper layers, 44.0 x 34.0 mm, 42 parts (32 on the bottom side), 19 nets.

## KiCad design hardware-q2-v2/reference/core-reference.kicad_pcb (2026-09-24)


Board: 4 copper layers, 22.0 x 30.0 mm, 47 parts (1 on the bottom side), 85 nets.

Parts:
ANT1: ESP-ANT-2G-MIFA-G2-L15P8W5P6-V1P1
C1, C2, C3, C4, C5, C6, C7, C8, C12, C13, C14, C16, C17, C18, C19, C20, C21, C22, C23, C24, C25: C0201
C9: DFN0603_A
C10, C11, C15: C0402
D1: SOD882
L1, L2, L3, L4, L5: L0201
R1, R2, R3, R4, R5, R6, R7, R8, R9, R10, R11: R0201
U1: QFN80_0P35_8_E6P5_A
U2: WSON8_1P27_8X6_E4P3X3P4
U3: QFN94_0P85_22P6X20P6_MINI
Y1: XTAL3225_2016

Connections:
ANT: C3.1, L1.2, U1.1
EN: U1.4, U3.5
GND: ANT1.2, C1.2, C2.2, C3.2, C4.2, C5.2, C6.2, C8.2, C9.2, C10.2, C11.2, C12.2, C13.2, C14.2, C15.2, C16.2, C17.2, C18.2, C19.2, C20.2, C21.2, C22.2, C23.2, C24.2, C25.2, D1.1, L2.2, R11.2, U1.81, U2.4, U2.9, U3.1, U3.2, U3.26, U3.47, U3.48, U3.72, U3.73, U3.74, U3.75, U3.76, U3.77, U3.78, U3.79, U3.80, U3.81, U3.82, U3.83, U3.84, U3.85, U3.86, U3.87, U3.88, U3.89, U3.90, U3.92, U3.93, U3.94, U3.95, U3.96, U3.97, U3.98, U3.99, Y1.2, Y1.4
IO0: U1.5, U3.8
IO1: U1.6, U3.9
IO2: U1.7, U3.6
IO3: U1.8, U3.7
IO4: U1.9, U3.10
IO5: U1.10, U3.11
IO6: U1.12, U3.12
IO7: U1.13, U3.13
IO8: U1.14, U3.14
IO9: U1.15, U3.15
IO10: U1.16, U3.16
IO11: U1.17, U3.17
IO12: U1.19, U3.18
IO13: U1.20, U3.19
IO14: U1.21, U3.20
IO15: U1.22, U3.21
IO16: U1.23, U3.22
IO17: U1.24, U3.23
IO18: U1.25, U3.24
IO19: U1.26, U3.25
IO33: U1.46, U3.42
IO34: U1.47, U3.43
IO35: U1.48, U3.44
IO36: R10.1, R11.1, U1.49, U3.45
IO37: U1.50, U3.46
IO38: U1.51, U3.49
IO39: U1.52, U3.50
IO40: U1.53, U3.51
IO42: U1.55, U3.52
IO43: U1.56, U3.53
IO44: U1.57, U3.54
IO45: U1.58, U3.55
IO46: U1.59, U3.56
IO47: U1.60, U3.57
IO48: U1.61, U3.58
IO49: U1.62, U3.59
IO50: U1.65, U3.60
IO51: U1.66, U3.61
IO52: U1.67, U3.62
IO53: U1.68, U3.63
IO54: U1.69, U3.64
IO55: U1.70, U3.65
IO56: U1.71, U3.66
IO57: U1.72, U3.67
IO60: U1.75, U3.70
IO61: U1.76, U3.71
N20805107: C18.1, L4.2, U1.2, U1.3
N20805446: R6.1, U1.73
N20805524: L3.1, U1.79
N20805709: R4.1, U1.41
N20805715: R5.1, U1.42
N20805727: R3.1, U1.40
N20805734: R2.1, U1.38
N20805749: R1.1, U1.37
N20805764: R8.1, U1.45
N20805766: R9.1, U1.44
RF: C4.1, C7.2, L1.1
RF1: C7.1, C8.1, L2.1, L5.2
RF_ANT: ANT1.1, C9.1, L5.1
RX0: U1.74, U3.69
SD_CLK: U1.32, U3.31
SD_CMD: U1.33, U3.32
SD_D0: U1.27, U3.27
SD_D1: U1.28, U3.28
SD_D2: U1.29, U3.29
SD_D3: U1.31, U3.30
SPICLK: R4.2, U2.6
SPICS: R7.2, U1.36, U2.1
SPID: R5.2, U2.5
SPIHD: R3.2, U2.7
SPIQ: R1.2, U2.2
SPIWP: R2.2, U2.3
TX0: R6.2, U3.68
USB_DM: R8.2, U3.41
USB_DP: R9.2, U3.40
VDD33: C5.1, C6.1, C10.1, C15.1, C16.1, C17.1, C19.1, C23.1, C24.1, C25.1, D1.2, L4.1, R10.2, U1.11, U1.43, U1.54, U1.64, U1.77, U1.80, U3.3, U3.4
VDD_LDO_1P8: C20.1, C21.1, C22.1, U1.30, U1.34, U1.35
VDD_SPI: C13.1, C14.1, R7.1, U1.39, U2.8
VREF_ADC: C12.1, U1.63
VREF_TOUCH: C11.1, U1.18
XTAL_N: C2.1, U1.78, Y1.3
XTAL_P: C1.1, L3.2, Y1.1

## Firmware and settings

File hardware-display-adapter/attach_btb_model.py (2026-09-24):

"""Update only J2's mechanical footprint, preserving board placement and other work."""
from pathlib import Path
ROOT=Path(__file__).resolve().parent/'am213-fpc-adapter'
if (ROOT/'am213-fpc-adapter.kicad_sch').exists():
    raise SystemExit('Legacy placement generator disabled: completed electrical project exists.')
NAME='OK-23GF024-04_MechanicalOnly'
FP='''(footprint "OK-23GF024-04_MechanicalOnly"
  (version 20260206) (generator "pcbnew")
  (layer "F.Cu")
  (descr "OCN socket: 7.32x2.59x0.79mm, 24 contacts, 0.4mm pitch. MECHANICAL ONLY; no copper pads; Pin 1 unresolved.")
  (attr board_only exclude_from_pos_files exclude_from_bom)
  (property "Reference" "J2" (at 0 -4.5) (layer "F.Fab")
    (effects (font (size 0.8 0.8) (thickness 0.12))))
  (property "Value" "OK-23GF024-04" (at 0 4.5) (layer "F.Fab") hide
    (effects (font (size 0.6 0.6) (thickness 0.1))))
  (fp_rect (start -1.295 -3.66) (end 1.295 3.66)
    (stroke (width 0.12) (type default)) (fill none) (layer "F.Fab"))
  (fp_rect (start -2 -6) (end 2 6)
    (stroke (width 0.08) (type dash)) (fill none) (layer "Dwgs.User"))
  (fp_line (start -0.45 0) (end 0.45 0) (stroke (width 0.1) (type default)) (layer "F.Fab"))
  (fp_line (start 0 -0.45) (end 0 0.45) (stroke (width 0.1) (type default)) (layer "F.Fab"))
  (model "${KIPRJMOD}/models3d/OK-23GF024-04.step"
    (offset (xyz 0 0 0)) (scale (xyz 1 1 1)) (rotate (xyz 0 0 0)))
)
'''

def update_board():
    import re
    p=ROOT/'am213-fpc-adapter.kicad_pcb';s=p.read_text(encoding='utf-8')
    match=re.search(r'\(footprint "Adapter_Placement:(?:BTB_24P_Placement_Only|OK-23GF024-04_MechanicalOnly)"',s)
    assert match,'Expected J2 mechanical footprint missing; refusing to replace other content'
    start=match.start();depth=0;quoted=False;escape=False
    for i in range(start,len(s)):
        c=s[i]
        if escape:escape=False;continue
        if quoted and c=='\\':escape=True;continue
        if c=='"':quoted=not quoted
        if not quoted:
            if c=='(':depth+=1
            if c==')':
                depth-=1
                if not depth:end=i+1;break
    old=s[start:end]
    at=re.search(r'\(at [^)]+\)',old).group(0)
    assert not re.search(r'\(pad\s',old),'Existing copper requires manual review'
    fp=FP.replace(f'"{NAME}"',f'"Adapter_Placement:{NAME}"',1).replace('(version 20260206) (generator "pcbnew")','',1).replace('(layer "F.Cu")',f'(layer "F.Cu") {at}',1)
    s=s[:start]+fp+s[end:]
    s=s.replace('J2: 24P BTB\\nPAD / PIN 1 TBD','J2: OK-23GF024-04\\nPAD / PIN 1 TBD')
    p.write_text(s,encoding='utf-8')
    (ROOT/'Adapter_Placement.pretty'/f'{NAME}.kicad_mod').write_text(FP,encoding='utf-8')
    print('J2 model attached; preserved placement',at)
if __name__=='__main__':update_board()

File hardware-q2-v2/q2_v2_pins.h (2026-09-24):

/* Generated from V2 PCB net assignments. GPIO numbers, not QFN pin numbers. */
/* Not a compiled or bench-tested BSP. SYS I2C uses LP I2C on GPIO 6/7. */
#pragma once
#define Q2_KEY_POWER_SENSE_N_GPIO 0
#define Q2_CTRL_INT_N_GPIO 1
#define Q2_RTC_INT_N_GPIO 2
#define Q2_IMU_INT1_GPIO 3
#define Q2_BAT_ALERT_N_GPIO 4
#define Q2_CHG_INT_N_GPIO 5
#define Q2_SYS_I2C_SCL_GPIO 6
#define Q2_SYS_I2C_SDA_GPIO 7
#define Q2_POWER_OFF_REQ_GPIO 9
#define Q2_CTRL_RESET_N_GPIO 10
#define Q2_USB_PATH_SEL_GPIO 11
#define Q2_MOTOR_EN_GPIO 12
#define Q2_CHG_OTG_EN_GPIO 13
#define Q2_AUDIO_I2C_SCL_GPIO 14
#define Q2_AUDIO_I2C_SDA_GPIO 15
#define Q2_SD_CARD_DETECT_N_GPIO 19
#define Q2_SD_D0_GPIO 20
#define Q2_SD_D1_GPIO 21
#define Q2_SD_D2_GPIO 22
#define Q2_SD_D3_GPIO 23
#define Q2_SD_CLK_GPIO 24
#define Q2_SD_CMD_GPIO 25
#define Q2_FLASH_CS_N_GPIO 26
#define Q2_MCU_FLASH_D1_GPIO 27
#define Q2_MCU_FLASH_D2_GPIO 28
#define Q2_MCU_FLASH_D3_GPIO 30
#define Q2_MCU_FLASH_CLK_GPIO 31
#define Q2_MCU_FLASH_D0_GPIO 32
#define Q2_USB_DEBUG_DM_GPIO 33
#define Q2_USB_DEBUG_DP_GPIO 34
#define Q2_DAC_I2S_DOUT_GPIO 35
#define Q2_STRAP_FLASH_3V3_GPIO 36
#define Q2_STRAP_USB_JTAG_GPIO 37
#define Q2_DAC_I2S_LRCK_GPIO 38
#define Q2_DAC_RESET_N_GPIO 39
#define Q2_DAC_I2S_BCLK_GPIO 40
#define Q2_TP_I2C_SCL_GPIO 42
#define Q2_TP_I2C_SDA_GPIO 43
#define Q2_LCD_RESET_N_GPIO 44
#define Q2_LCD_VCI_EN_GPIO 45
#define Q2_LCD_TE_GPIO 46
#define Q2_TP_INT_N_GPIO 47
#define Q2_TP_RESET_N_GPIO 48
#define Q2_LCD_CS_N_GPIO 52
#define Q2_LCD_CLK_GPIO 53
#define Q2_LCD_D0_GPIO 54
#define Q2_LCD_D1_GPIO 55
#define Q2_LCD_D3_GPIO 56
#define Q2_LCD_D2_GPIO 57
#define Q2_MCU_UART0_TX_GPIO 58
#define Q2_UART0_RX_GPIO 59
#define Q2_BOOT_MODE_H_GPIO 60
#define Q2_BOOT_DOWNLOAD_N_GPIO 61

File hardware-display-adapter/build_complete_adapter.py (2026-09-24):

"""Build the OSPTEK reference-based passive AM213 adapter. KiCad 10 Python.
Sources: reference/osptek-official and main-fpc2-net-map.json.
Flexible tail geometry is an assembly candidate, not a supplier-approved flex stack.
"""
from pathlib import Path
import pcbnew as p
import json,uuid,shutil,csv,re,sys
ROOT=Path(__file__).resolve().parent;O=ROOT/'am213-fpc-adapter';LIB=O/'Adapter.pretty';LIB.mkdir(exist_ok=True)
OUT=O/'output';OUT.mkdir(exist_ok=True);K=Path('D:/KiCad/10.0/share/kicad')
sys.path.insert(0,str(ROOT.parent/'tmp'));from sexpr import parse,get,children,dump,S
uid=lambda s:str(uuid.uuid5(uuid.UUID('2bc04421-f71e-4b58-af1a-111296efbad9'),s))
q=lambda s:json.dumps(str(s),ensure_ascii=False)
name='am213-fpc-adapter';rootid=uid('root');defs={};pinouts={};instances=[];wires=[];labels=[];ncs=[];cs=[]

def sym(n,pins,halfwidth=10.16):
    h=max(5.08,(max(sum(x[2]==side for x in pins) for side in [-1,1])-1)*1.27+2.54)
    specs=[]
    for side in [-1,1]:
        row=[x for x in pins if x[2]==side]
        for i,(num,label,_,typ) in enumerate(row):specs.append((str(num),label,side*(halfwidth+2.54),(len(row)-1)*1.27-i*2.54,0 if side<0 else 180,typ))
    props=''.join(f'(property {q(k)} {q(v)} (at 0 {y} 0) (effects (font (size 1.27 1.27))))' for k,v,y in [('Reference','J' if n.startswith('J') else n[0],h+5.08),('Value',n,h+2.54)])
    body=f'(rectangle (start {-halfwidth} {h}) (end {halfwidth} {-h}) (stroke (width .254) (type default)) (fill (type background)))'
    if n=='R':body='(rectangle (start -2.54 1.016) (end 2.54 -1.016) (stroke (width .254) (type default)) (fill (type none)))'
    if n=='C':body=''.join(f'(polyline (pts (xy {x} -2) (xy {x} 2)) (stroke (width .254) (type default)) (fill (type none)))' for x in [-.508,.508])
    pp=''.join(f'(pin {ty} line (at {x} {y} {a}) (length {2.54 if n not in ["R","C"] else (2.54 if n=="R" else 4.572)}) (name {q(l)} (effects (font (size .9 .9)))) (number {q(num)} (effects (font (size .9 .9)))))' for num,l,x,y,a,ty in specs)
    defs[n]=f'(symbol "Adapter:{n}" (pin_names (offset .508)) (in_bom yes) (on_board yes) {props} (symbol "{n}_0_1" {body}) (symbol "{n}_1_1" {pp}))'
    pinouts[n]=(specs,h)

main={int(x['pin']):x['net'] for x in json.loads((ROOT/'main-fpc2-net-map.json').read_text())['pads'] if int(x['pin'])<=21}
host={3:'LCD_RST',4:'VCI_EN',5:'CLK_IN',7:'CS_IN',8:'D3_IN',9:'D2_IN',10:'D1_IN',11:'D0_IN',12:'GND',13:'VCC_3V3',14:'VCC_3V3',17:'GND',18:'TP_INT',19:'TP_SCL',20:'TP_SDA',21:'TP_RST'}
screen={1:'LCD_RST',2:'GND',3:'LCD_TE',4:'LCD_CS',5:'LCD_CLK',6:'LCD_D1',7:'LCD_D0',8:'GND',11:'VCC_3V3',12:'VCC_3V3',13:'GND',14:'GND',15:'LCD_VDD',16:'TP_VDD',17:'TP_INT',18:'TP_RST',19:'TP_SDA',20:'TP_SCL',21:'GND',22:'LCD_D3',23:'LCD_D2',24:'VCI_EN','MP':'GND'}
sym('J_HOST',[(i,main.get(i) or 'NC',-1 if i<=11 else 1,'passive') for i in range(1,22)])
spnames={**screen,9:'NC_IM1',10:'NC_MTP',11:'VBAT',12:'VBAT',15:'VDD',16:'TP_VDD'}
sym('J_LCD',[(i,spnames[i],-1 if i<=12 else 1,'passive') for i in range(1,25)]+[('MP','MOUNT_GND',1,'passive')])
for s in ['R','C']:sym(s,[(1,'',-1,'passive'),(2,'',1,'passive')],2.54)
sym('TP',[(1,'',-1,'passive')],1.27)

def component(ref,kind,value,nets,sch,fp,pcb,dnp=False,desc=''):
    nets={str(k):v for k,v in nets.items()};x,y=[round(round(z/1.27)*1.27,5) for z in sch];pp,h=pinouts[kind];sid=uid(ref)
    props=''.join(f'(property {q(k)} {q(v)} (at {x} {yy} 0) (effects (font (size 1.016 1.016)){hide}))' for k,v,yy,hide in [('Reference',ref,y-h-5.08,''),('Value',value,y-h-2.54,''),('Footprint','Adapter:'+fp,y,' hide'),('Description',desc,y,' hide')])
    instances.append(f'(symbol (lib_id "Adapter:{kind}") (at {x} {y} 0) (unit 1) (in_bom yes) (on_board yes) (dnp {"yes" if dnp else "no"}) (uuid "{sid}") {props}'+''.join(f'(pin {q(n)} (uuid "{uid(ref+"pin"+n)}"))' for n,*_ in pp)+f'(instances (project "{name}" (path "/{rootid}" (reference "{ref}") (unit 1)))))')
    for n,_,px,py,a,ty in pp:
        ax,ay=round(x+px,5),round(y-py,5)
        if n not in nets:ncs.append(f'(no_connect (at {ax} {ay}) (uuid "{uid(ref+n+"nc")}"))');continue
        ex=round(ax+(-5.08 if px<0 else 5.08),5)
        wires.append(f'(wire (pts (xy {ax} {ay}) (xy {ex} {ay})) (stroke (width 0) (type default)) (uuid "{uid(ref+n+"w")}"))')
        labels.append(f'(label {q(nets[n])} (at {ex} {ay} 0) (effects (font (size 1.016 1.016)) (justify {"right" if px<0 else "left"} bottom)) (uuid "{uid(ref+n+"l")}"))')
    cs.append(dict(ref=ref,kind=kind,value=value,nets=nets,footprint=fp,pcb=pcb,uuid=sid,dnp=dnp,description=desc))
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

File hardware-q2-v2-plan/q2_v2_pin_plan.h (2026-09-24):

/* Q2 V2 pin PROPOSAL only. Not an initialized or board-tested BSP. */
#pragma once
/* Numbers ending GPIO are GPIO indices, not QFN physical pin numbers. */
/* QFN pin 5; FPC1.11 / U6.1，经3.3V隔离检测 */
#define Q2_KEY_POWER_SENSE_N_GPIO 0
/* QFN pin 6; FPC1.5 */
#define Q2_CTRL_INT_N_GPIO 1
/* QFN pin 7; U1.6 */
#define Q2_RTC_INT_N_GPIO 2
/* QFN pin 8; U15.4 */
#define Q2_IMU_INT1_GPIO 3
/* QFN pin 9; U14.1 */
#define Q2_BAT_ALERT_N_GPIO 4
/* QFN pin 10; U3.7 */
#define Q2_CHG_INT_N_GPIO 5
/* QFN pin 12; U3.5 U14.3 U1.2 U11.2 FPC1.4 */
#define Q2_SYS_I2C_SCL_GPIO 6
/* QFN pin 13; U3.6 U14.2 U1.3 U11.3 FPC1.3 */
#define Q2_SYS_I2C_SDA_GPIO 7
/* QFN pin 15; U6.3，经断电防反灌电路 */
#define Q2_POWER_OFF_REQ_GPIO 9
/* QFN pin 16; FPC1.6 */
#define Q2_CTRL_RESET_N_GPIO 10
/* QFN pin 17; U17.2 */
#define Q2_USB_PATH_SEL_GPIO 11
/* QFN pin 19; U11.5 */
#define Q2_MOTOR_EN_GPIO 12
/* QFN pin 20; U3.8 */
#define Q2_CHG_OTG_EN_GPIO 13
/* QFN pin 21; U7.6 U15.13 */
#define Q2_AUDIO_I2C_SCL_GPIO 14
/* QFN pin 22; U7.5 U15.14 */
#define Q2_AUDIO_I2C_SDA_GPIO 15
/* QFN pin 26; CARD2.CD */
#define Q2_SD_CARD_DETECT_N_GPIO 19
/* QFN pin 27; CARD2.7 */
#define Q2_SD_D0_GPIO 20
/* QFN pin 28; CARD2.8 */
#define Q2_SD_D1_GPIO 21
/* QFN pin 29; CARD2.1 */
#define Q2_SD_D2_GPIO 22
/* QFN pin 31; CARD2.2 */
#define Q2_SD_D3_GPIO 23
/* QFN pin 32; CARD2.5 */
#define Q2_SD_CLK_GPIO 24
/* QFN pin 33; CARD2.3 */
#define Q2_SD_CMD_GPIO 25
/* QFN pin 48; U8.2 */
#define Q2_DAC_I2S_DOUT_GPIO 35
/* QFN pin 51; U8.5 */
#define Q2_DAC_I2S_LRCK_GPIO 38
/* QFN pin 52; U8.12 */
#define Q2_DAC_RESET_N_GPIO 39
/* QFN pin 53; U8.9 */
#define Q2_DAC_I2S_BCLK_GPIO 40
/* QFN pin 55; JDISP1.20 */
#define Q2_TP_I2C_SCL_GPIO 42
/* QFN pin 56; JDISP1.19 */
#define Q2_TP_I2C_SDA_GPIO 43
/* QFN pin 57; JDISP1.1 */
#define Q2_LCD_RESET_N_GPIO 44
/* QFN pin 58; JDISP1.24 */
#define Q2_LCD_VCI_EN_GPIO 45
/* QFN pin 59; JDISP1.3 */
#define Q2_LCD_TE_GPIO 46
/* QFN pin 60; JDISP1.17 */
#define Q2_TP_INT_N_GPIO 47
/* QFN pin 61; JDISP1.18 */
#define Q2_TP_RESET_N_GPIO 48
/* QFN pin 67; JDISP1.4 */
#define Q2_LCD_CS_N_GPIO 52
/* QFN pin 68; JDISP1.5 */
#define Q2_LCD_CLK_GPIO 53
/* QFN pin 69; JDISP1.7 */
#define Q2_LCD_D0_GPIO 54
/* QFN pin 70; JDISP1.6 */
#define Q2_LCD_D1_GPIO 55
/* QFN pin 71; JDISP1.22 */
#define Q2_LCD_D3_GPIO 56
/* QFN pin 72; JDISP1.23 */
#define Q2_LCD_D2_GPIO 57
/* QFN pin 73; U12.5 RXD */
#define Q2_UART0_TX_GPIO 58
/* QFN pin 74; U12.4 TXD */
#define Q2_UART0_RX_GPIO 59
/* LP I2C is NOT a third HP I2C controller. Initialize through LP APIs. */
#define Q2_SYS_I2C_INITIAL_HZ 100000
#define Q2_AUDIO_I2C_HP_PORT 0
#define Q2_TP_I2C_HP_PORT 1
#define Q2_LCD_SPI_INITIAL_HZ 20000000
/* Native USB HS uses dedicated QFN pins 44/45, never GPIO44/45. */

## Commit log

2026-09-21 feat: add Q2-compatible PCB and FreeCAD enclosure
    [1_MCU.kicad_sch, 2_POWER.kicad_sch, 3_DAC.kicad_sch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]
2026-09-21 feat: add local 3D models for KiCad components
    [AUDIO-SMD_PJ-342B-TX-SMT.step, C0402.step, C0402_1.step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]
2026-09-21 feat: add double-sided PCB placement for manual routing
    Reposition 76 components, preserve mechanical anchors and nets, and provide an unrouted KiCad project with local models, previews and validation reports. Include the saved FreeCAD documents used by t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
    [1_MCU.kicad_sch, 2_POWER.kicad_sch, 3_DAC.kicad_sch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]
2026-09-21 feat: relocate harness connectors and refine Q2 enclosure
    [2_POWER.kicad_sch, 5_MOTOR.kicad_sch, ESP32S31_MP3_Q2_B.FCStd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]
2026-09-21 fix: restore schematic links and refine PCB component placement
    [1_MCU.kicad_sch, 2_POWER.kicad_sch, 3_DAC.kicad_sch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]
2026-09-24 chore: archive obsolete PCB workspaces and ignore local routing caches
    [1_MCU.kicad_sch, 2_POWER.kicad_sch, 3_DAC.kicad_sch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]
2026-09-24 feat: save finalized module mainboard and fabrication review
    [10_TOUCH_WHEEL.kicad_sch, 1_MCU.kicad_sch, 2_POWER.kicad_sch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]
2026-09-24 feat: add CH32V006 touch controls board and manufacturing outputs
    [C0402.step, CH32V006_QFN20.step, CenterButtonControlsA.step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]
2026-09-24 feat: add assembled resin enclosure prototypes and reinforced controls mounts
    [01-body.step, 01-body.stl, 01-housing.step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]
2026-09-24 feat: add glued nut inserts and revise enclosure assembly access
    [01-housing.step, 01-housing.stl, 02-rear-cover.step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]
2026-09-24 feat: adapt L enclosure and FPC interposer for AM213 display
    [01-housing.step, 01-housing.stl, 02-rear-cover.step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]
2026-09-24 feat: plan bare ESP32-S31 mainboard pins and front BTB placement
    [Q2_V2_BTB_Position_Study.FCStd, Q2_V2_Placement_Study.FCStd, pin-assignment.csv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]
2026-09-24 feat: add routed ESP32-S31 V2 mainboard review candidate
    [AUDIO-SMD_PJ-342B-TX-SMT.step, BOM_ESP32-S31-WROOM-3-N8R16V.xlsx, C0402.step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]
2026-09-24 feat: convert V2 passives to 0402 and retain power-only routing
    [q2-v2-assembly.step, q2-v2.kicad_pcb]
2026-09-24 fix: standardize V2 0402 resistor and capacitor footprints
    [CORE_1.kicad_sch, CORE_2.kicad_sch, CORE_RF_1.kicad_sch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]
2026-09-24 feat: distribute V2 power through copper pours and local vias
    [q2-v2.kicad_pcb]
